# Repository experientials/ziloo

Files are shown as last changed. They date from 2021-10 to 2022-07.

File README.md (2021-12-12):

# Ziloo

Ziloo is an independent device that sees and senses the environment. It recognises objects and behavior based on what it has been taught. It outputs an event log describing what is perceived.
Ziloo can be placed on a shelf, wall or embedded. I will recognise things and people it has been trained to recognise. They have to appear in front within 20cm - 200cm. Ziloo is primarily used indoors and used at all times of the day.

It receives stereo video input over 2 x 2-lane MIPI CSI2. Additionally it receives sensor input over I2C
for distance, color, brightness. The sensor inputs are processed and disected to identify objects, people and
behaviour. Ziloo can connect over USB to make the output available.

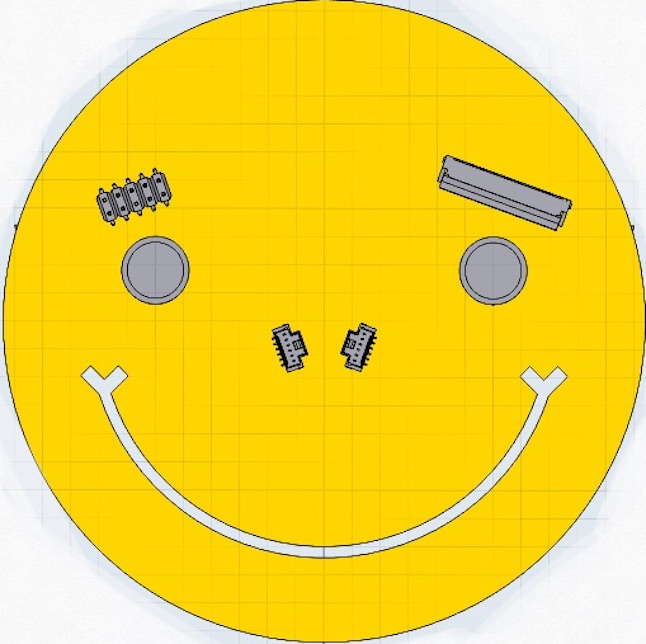
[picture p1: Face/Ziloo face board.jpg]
Ziloo face


Ziloo will be launched on Kickstarter in 2022.

TODO 3D Exploded assembly
https://www.fiverr.com/visual_pro022/3d-product-animation-3d-product-video-3d-animation-3d-product-animation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

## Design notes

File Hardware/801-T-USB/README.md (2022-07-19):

# 801 T-USB daughterboard Upwork task

The T-USB daughterboard has two functions
- Supply the system with power
- Support smart future waking/suspend logic
- Provide data signals in the system over two USB-C connectors

The T-USB board exposes two vertical USB-C sockets and connects to the carrier board through two 50 pin B2B connectors.
For future feature development the board also has two FPC breakout connectors.

In addition to this board a matching **testing/breakout board must be designed**.

We already have a development board designed so this tasks breaks out part of an existing design (909) on a dedicated baord (801 T-USB).

The provided documentation includes

- Detailed functionality, wiring, connections for T-USB board
- Detailed functionality, wiring, connections for TESTING board
- Functionality Testing cases
- Reference diagram for Compulab development board
- Reference diagram for 909 development board
- Component datasheets

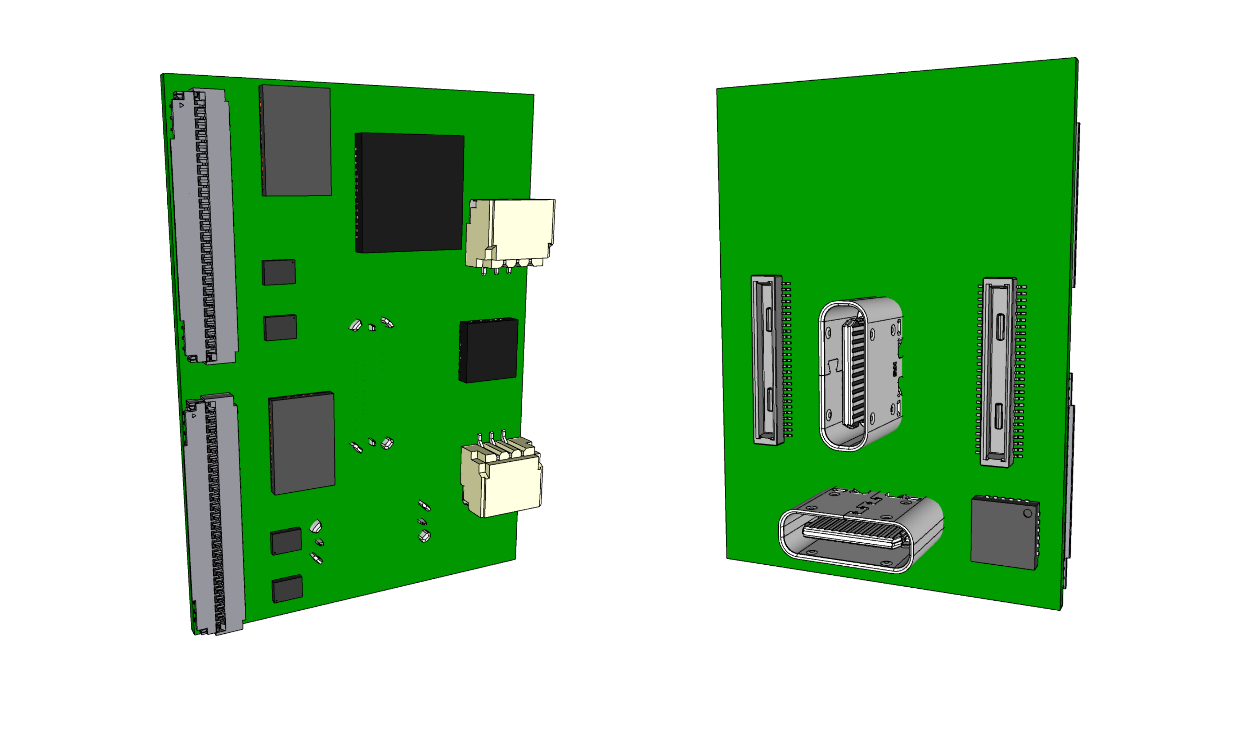
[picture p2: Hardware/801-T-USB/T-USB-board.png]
Ziloo 801 T-USB Board


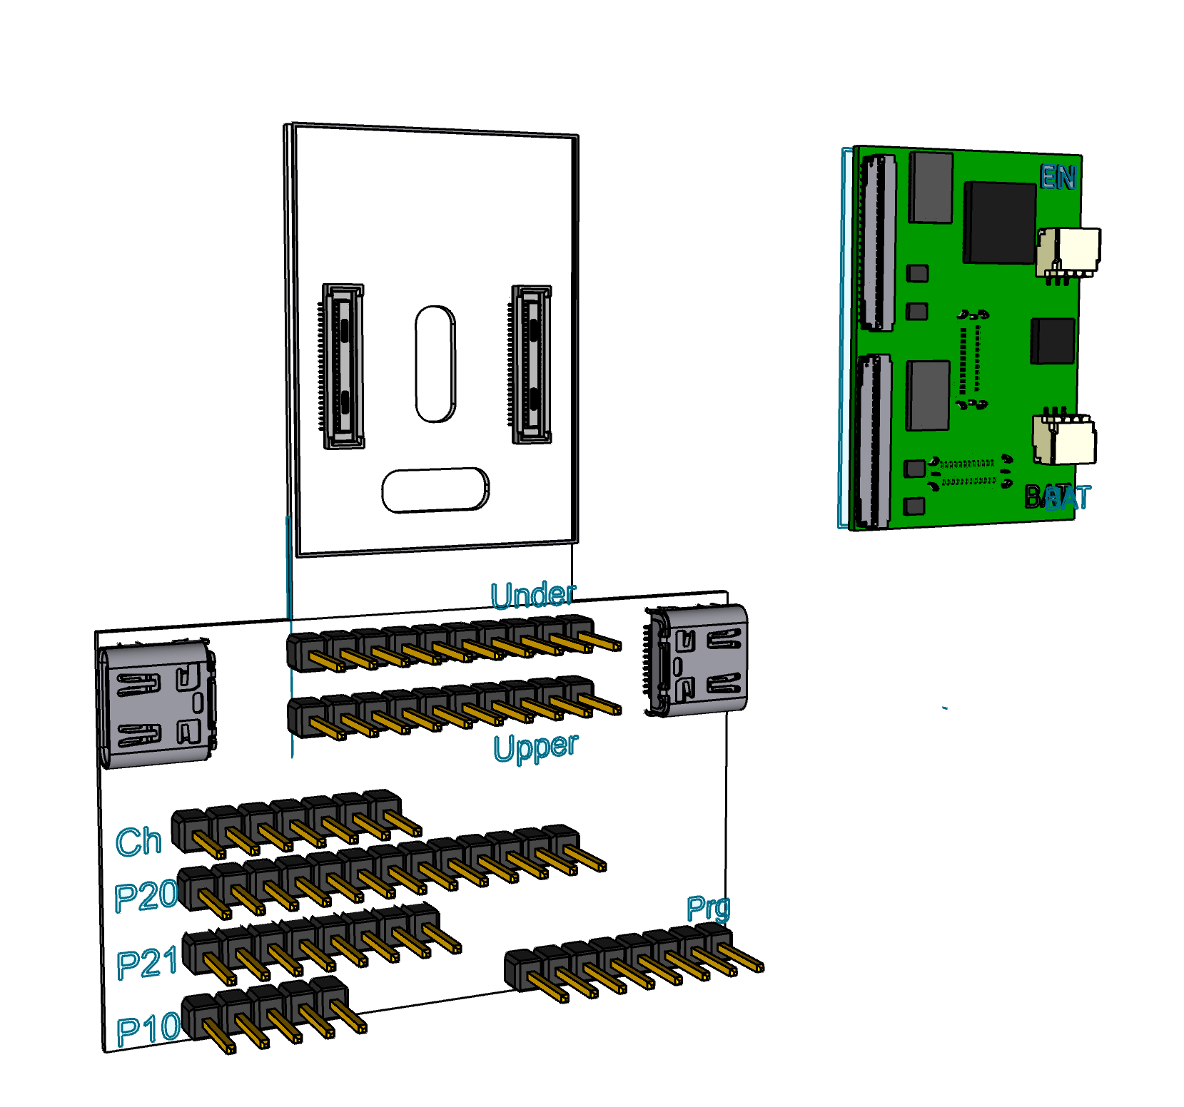
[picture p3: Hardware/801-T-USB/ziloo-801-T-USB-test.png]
Ziloo 801 T-USB Board


The board takes two USB-C connections with power and data.

- Supports 5V in and out
- USB 2.0/3.0 data support
- Rudimentary Alt. Mode support
- Trickle charging & Fast Charging
- With/Without Battery connected
- Steady power output regardless of charging
- Power output max. 4.5V 2.5A

The essential BOM of the 801 T-USB Bridge Board is,

- 2 * [Hirose DF40-50DP-0.4V](https://www.hirose.com/en/product/p/CL0684-4014-0-51)
- 2 * [Hirose USB-C CX80B1-24P](https://www.hirose.com/product/p/CL0480-0625-0-00)
- 1 * [TPS65988](https://www.ti.com/product/TPS65988?keyMatch=TPS65988&tisearch=search-everything&usecase=GPN) Dual Port USB Type-C® and USB PD Controller, Power Switch, and High-Speed Multiplexer. 
- 2 * [HD3SS460](https://www.ti.com/product/HD3SS460?keyMatch=HD3SS460&tisearch=search-everything&usecase=GPN) 4 x 6 Channels USB Type-C Alternate Mode MUX. Connected to T-USB Host. 
- 1 * PCA9555 I/O Expander
- 4 * [TS5USBC410 Dual 2:1 USB 2.0 Mux/DeMux Switch](../datasheets/USB/ts5usbc41.pdf). [Mouser](https://www.mouser.ch/ProductDetail/Texas-Instruments/TS5USBC410IYFFR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)
- 1 * [BQ24250RGER battery charger](https://www.ti.com/product/BQ24250)  
- 1 * [3 pin JST SH socket SM03B-SRSS-TB](https://www.jst-mfg.com/product/detail_e.php?series=231) 
- 2 * [TE Connectivity 45PIN 0.3MM 571-4-2328724-5 FPC 3-2328724-5](https://www.te.com/usa-en/product-4-2328724-5.html)

Test board components,

- 2 * [Hirose DF40-50DS-0.4V](https://www.hirose.com/en/product/p/CL0684-4009-0-51) mated height 1.5mm
- 2 * [HD3SS3220  10-Gbps USB 3.1 Type-C 2:1 mux with DRP Controller](https://www.ti.com/product/HD3SS3220)
- 2 * USB-C connectors [DX07S024JA1R1300](https://www.jae.com/en/connectors/series/detail/product/id=66508) or [DX07S024JJ2R1300](https://www.mouser.ch/ProductDetail/JAE-Electronics/DX07S024JJ2R1300?qs=odmYgEirbwyfyaz1Tta0cQ%3D%3D)
- 3 * [Samtec TSW-116-14-T-S Header 16 pin](https://www.samtec.com/products/tsw-116-14-t-s)

## Milestones:

The project is broken down in milestones to ensure a correct design.

### Testing board design $300

Do a design for the testing board and layout with Eagle or Altium

- Precise placement of USB-C socket holes
- Preciese placement of upper and under 50 pin connectors
- Breakout connectors can be arranged differently
- USB breakout connectors should be as suggested
- The breakout part of the board can be enlarged if needed

Once the design is done we will order a few boards for me and yourself for testing.

### Initial board designs  $800

Do an initial T-USB board diagram and layout with Eagle or Altium.

- Confirmation of BoM
- PD Controller working as a power sink(not source)
- Power Regulators
- Power LED, Power and Reset buttons
- 45 pin breakout connectors
- USB-C sockets
- Battery charger
- Design both boards

Deliverables:

- Diagrams(.sch) + Board layout design files
- Gerber files
- Review the choice of component and suggest alternative if needed.
- Confirmation of BoM
- Get production quotes with JLCPCB, PCBWAY etc. for 10pc, 100pcs, 1000pcs (assembled and basic)

### Ordering test batch of boards $0

We then do a test batch of 801 T-USB boards

### Verification of design and fixes - $400

Receive the test boards and test the acceptance tests. Make sure all tests pass.
Correct any issues after reviewing with me.

Deliverables:

- Diagrams(.sch) + Board layout design files
- Gerber files
- Testing report with measurements

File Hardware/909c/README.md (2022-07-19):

# Upwork task

The 909c has several different systems coming together. 
It receives power and data over USB from the T-USB power/data module. 
It receives sensor inputs over camera module connectors.
The camera modules are custom multi-sensor modules based on OV2735.
It connects to a powerful [i.MX 8 SoM](https://www.compulab.com/products/computer-on-modules/ucm-imx8m-plus-nxp-i-mx-8m-plus-som-system-on-module-computer/) and it allows extension using an m.2 modules.

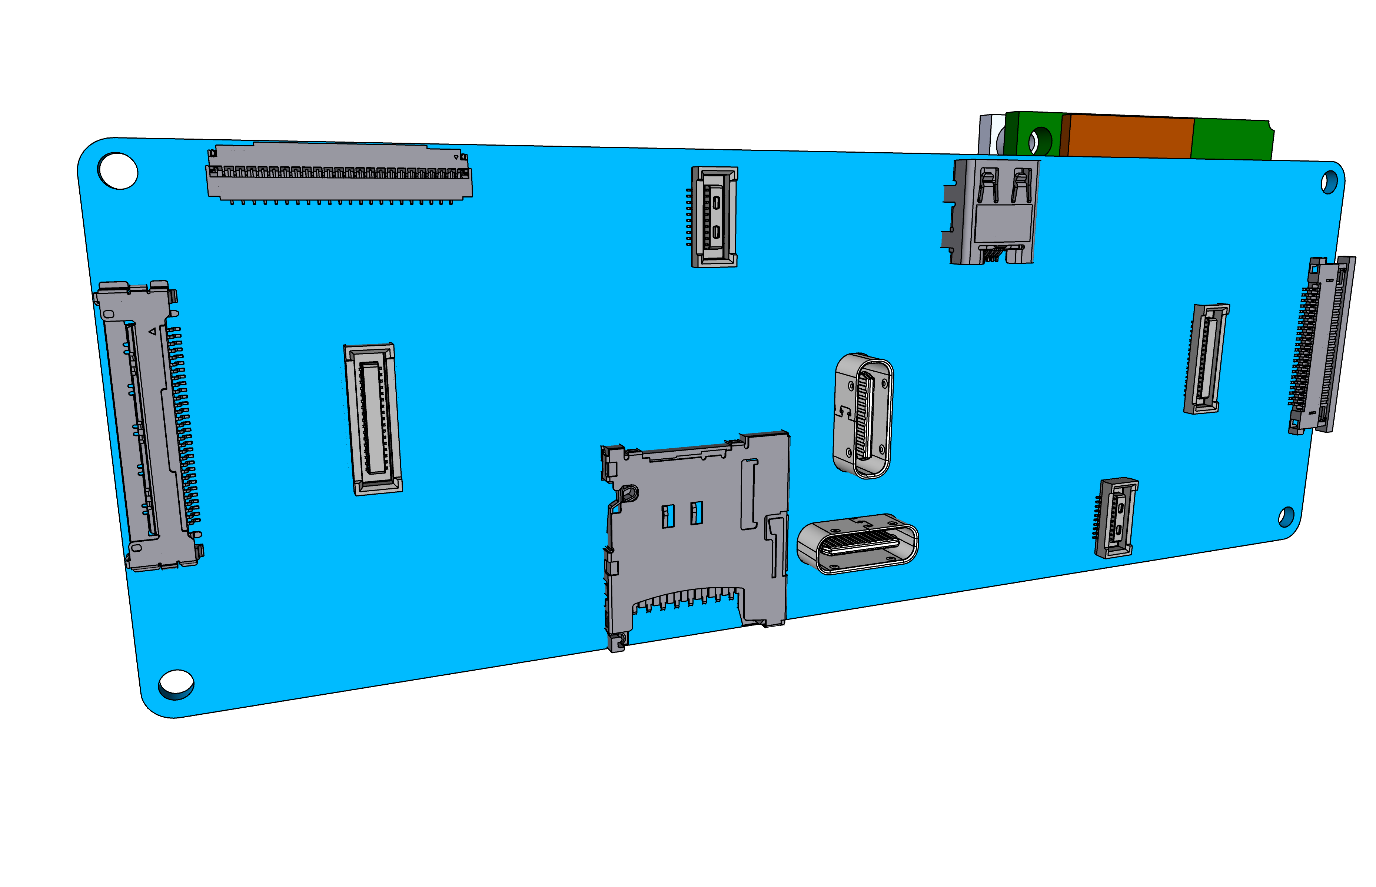
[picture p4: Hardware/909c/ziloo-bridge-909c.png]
Ziloo Bridge Board 909c


The 909c is made for experimentation. It will be used to,

- Connecting dual 201 Camera Modules to the Bridge Board
- Connecting a Raspberry Pi 15/22 pin Camera module to the Bridge Board
- Accessing the 201 Camera Modules from a i.MX8 Plus development boards like [Compulab](https://www.compulab.com/products/carrier-boards/sb-ucmimx8plus-carrier-board/), [I-Pi](https://www.ipi.wiki/products/i-pi-smarcplus-imx8mp) or [Varscite](https://www.variscite.com/product/system-on-module-som/cortex-a53-krait/dart-mx8m-plus-nxp-i-mx-8m-plus/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).
- Booting [i.MX8 Plus SoM]() with Linux Application for Machine Vision via Flash, USB, SSD
- Testing m.2 SSD boards

The 909c essentially joins connected modules,

1) 4 camera connectors for stereo cameras
2) Dual USB-C submodule that provides power and data connectivity.
3) Connectors for i.MX8 SoM
4) Connector for m.2 Key B (no screw)
5) SD Card, Board-To-Board sound bus connectors, HDMI, Debug Connector and debug/testing pads

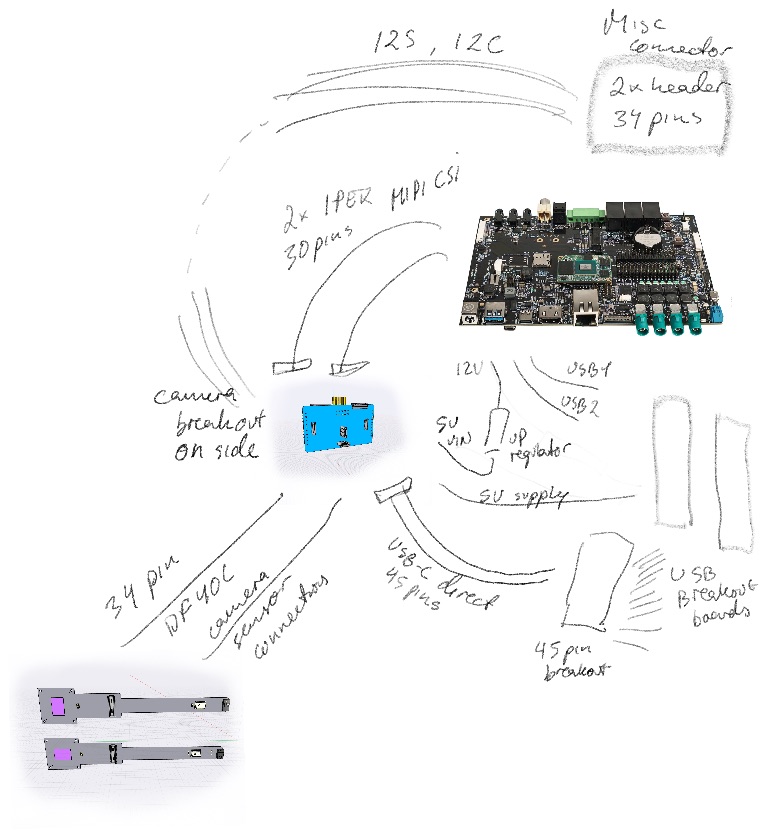
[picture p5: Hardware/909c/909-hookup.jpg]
Slightly outdated 909b Bridge Board hookup


The essential BOM of the 909c Bridge Board is,

- 1 * Compulab SB-UCM-iMX8PLUS SoM
- 1 * T-USB Module
- 1 * [CBTL04083 Multiplexer Switch ICs 3.3V CH 2:1](https://www.nxp.com/part/CBTL04083ABS#/) - [Mouser](https://www.mouser.ch/ProductDetail/NXP-Semiconductors/CBTL04083ABS518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)
- 1 * [Molex 22PIN 0.5mm pitch 54548-2271](https://www.molex.com/molex/products/part-detail/ffc_fpc_connectors/0545482271)
- 1 * [I-PEX 30PIN 0.4mm pitch 20525-030E-02](https://www.i-pex.com/product/cabline-ca)
- 1 * [TE Connectivity 45PIN 0.3MM 571-4-2328724-5 FPC 3-2328724-5](https://www.te.com/usa-en/product-4-2328724-5.html) $0.41
- 2 * [Hirose DF40C-34DS-0.4V](https://www.hirose.com/en/product/p/CL0684-4023-0-51) ([Mouser](https://www.mouser.ch/ProductDetail/Hirose-Connector/DF40C-34DS-04V51?qs=vcbW%252B4%252BSTIpg26DsEbj1iQ%3D%3D))
- 2 * [Hirose DF40HC(3.0)-100DS-0.4V](https://www.hirose.com/en/product/p/CL0684-4151-0-51) mated height 3.0mm
- 1 * m.2 connector

## Milestones:

The project is broken down in milestones to ensure a correct design.

### Overall system diagram and component layout

Do an initial board diagram and layout and order the Development board from compulab.com
 with Eagle or Altium.

- Confirmation of BoM
- T-USB module connection
- Coonection of [i.MX 8 SoM](https://www.compulab.com/products/computer-on-modules/ucm-imx8m-plus-nxp-i-mx-8m-plus-som-system-on-module-computer/)
- Soldering Pads
- 30 pin CSI connector
- 34 pin CSI connectors
- 22 pin CSI connector
- CSI to SoM lanes
- Debug breakout connector
- Sound connection (20 pins)
- Multi-directional power between CSI connectors
- m.2 module connector
- Level shifters

Deliverables:

- Diagrams(.sch) + Board layout design files
- Confirmation of BoM
- Collect PCB price estimates from 
- Get production quotes with JLCPCB etc. for 10pc, 100pcs, 1000pcs (assembled and basic)

### Diagram and Draft Board Layout - $250

Do a board diagram and layout of components with Eagle or Altium.

- A full set of diagrams for the board
- Placement of main components on the board
- Draft layout of important components
- Adherance to the design layouts I provide
- Plan signal levels for connectors

Deliverables:

- Diagrams + Board layout design files
- Confirmation of BoM

### Design and Produce - $1000

Design the board and produce a test batch

- Lay out the board
- Produce a batch of populated boards with PCBWay or JLCPCB
- Send me a populated board from the batch

Deliverables:

- Diagrams + Board layout design files
- Send me a populated board from the batch

### Test initial Batch $750

Once the initial batch of PCBs have been produced do some basic tests.
You should have the development board and 201 camera modules
You will have to power the board with a bench power supply directly for VSOM,
as I cannot provide you with a T-USB module.

- Test CSI connectors route signals and power
- Test USB connectors can power the board
- Test SoM can boot with HDMI, Mouse and Keyboard
- Test that the development board can be connected via 30 pin CSI connectors
- Test dual Rpi 22 pins camera connections -> 909b -> development board 
- Verify boot to USB/SD/eMMC
- Verify that small m.2 modules can be fitted
- Verify power delivery from USB chargers with the listed levels
- Document test process and findings
- Revise designs as needed

Deliverables:

- Report results and send the hardware(incl. Compulab dev board) back to me.
- All design files & send the hardware including test setup
- Revised design files
- Alternate component BoM

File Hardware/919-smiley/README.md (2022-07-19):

# Upwork task

The 919 is a board facing the user holding daughter boards on the back side.
It contains a MEMSIC mCube MC6470 3D movement sensor with a gyroscope and accelerometer, which is managed by the Stem MCU on the T-USB board.
It communicates with the Stem MCU via the Stem I2C bus, and the SoM i.MX 8 via the SYS I2C. 
It exposes system control signals via the SYS I2C GPIO Expander 0.

It has sockets and holes for two camera modules that are also routed to the SoM main board.

The 919 is made for experimentation. It will be used to join connected modules,

1) 4 camera connectors for stereo cameras
2) Dual USB-C submodule that provides autonomy, power and data connectivity.
3) Connectors for i.MX8 SoM
4) Sound modules

Slightly outdated 909b Bridge Board hookup

## Milestones:

The project is broken down in milestones to ensure a correct design.

### Board diagram and component placement $400

Prove the design by creating a schema, component placement and simple routing with Eagle or Altium.

- Connectors for Cameras, Sound extensions, Power Module, GPIO headers, RTC batt.
- LEDs + Controller
- IMU

Deliverables:

- Diagrams(.sch) + Board layout design files
- Confirmation of BoM
- Collect PCB price estimates from 
- Get production quotes with JLCPCB etc. for 10pc, 100pcs, 1000pcs (assembled and basic)

### Work out embedding of LEDs $300

The LEDs must be recessed in the PCB. Should this be part of the board design for production,
or is it a postprocessing step to CNC the holes?

### Design and Produce - $800

Design the board and produce a test batch based on the specs. Further refinement expected after initial batch.

- Lay out the board
- Ensure the LEDs are recessed
- Produce a batch of populated boards with PCBWay or JLCPCB
- Send me a populated board from the batch
- Do initial testing to find issues

Deliverables:

- Diagrams + Board layout design files
- Send me a populated board from the batch

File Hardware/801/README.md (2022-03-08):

Features

- Boot mode switches (eMMC / SD / Recovery / SPI)

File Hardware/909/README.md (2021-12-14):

# Upwork task

The 909 has several different systems coming together. It receives power and data over USB. It receives sensor inputs over camera module connectors.
The camera modules are custom multi-sensor modules based on OV2735.
It connects to a powerful i.MX 8 MCU module and it allows extension using an m.2 module.

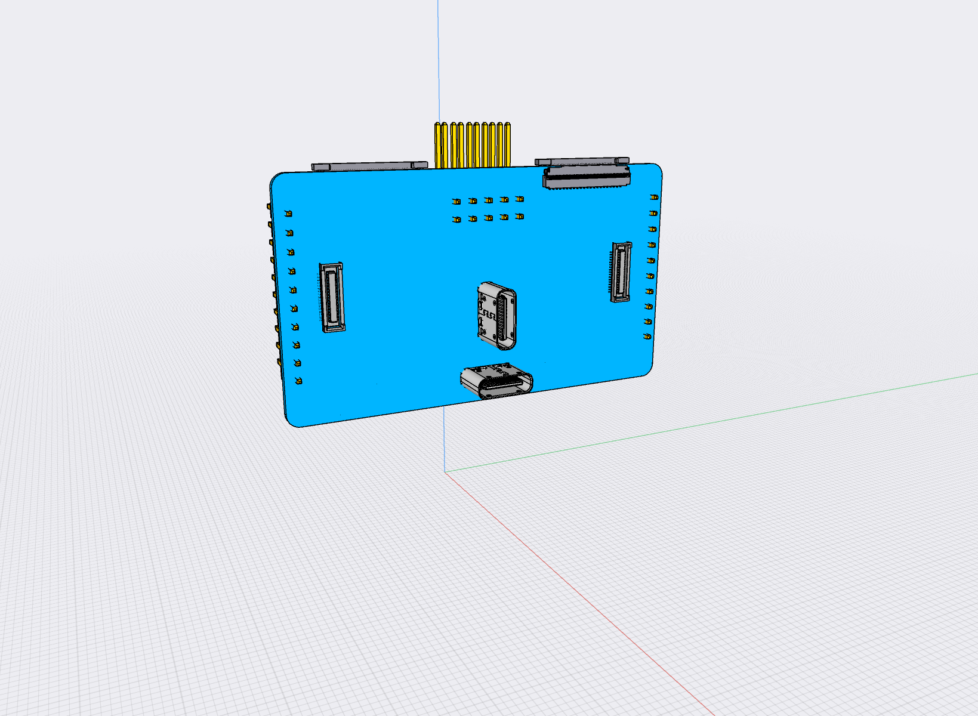
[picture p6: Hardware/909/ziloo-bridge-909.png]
Ziloo Bridge Board 909


The 909 is made for experimentation. It will be used to,

- Connecting 201 Camera Modules to the Carrier Board
- Connecting Raspberry Pi 15/22 pin modules to the Carrier Board
- Accessing the 201 Camera Modules from a Raspberry Pi
- Testing USB-C data transmission over Host & OTG connectors
- Testing charging via USB-C power cables from various sources (Dedicated Power, Mixed and Old chargers)
- Testing HDMI alternate mode over USB-C Host connector

The 909 essentially provides two parts,

1) Input connectors for 2 cameras linked to output connectors connected to the i.MX 8 development board.
   The cameras are powered by the development board connections.
2) 2 USB-C connectors are managed by a USB PD Controller circuit and breaks out relevant power & data pins.
   These pins are then mapped to 2 USB ports on the i.MX 8 development board.

909 Bridge Board hookup

The essential BOM of the 909 Bridge Board is,

- Texas Instruments TPS65988
- 2 * [Molex 22PIN 0.5mm pitch 54548-2271](https://www.molex.com/molex/products/part-detail/ffc_fpc_connectors/0545482271)
- 2 * [I-PEX 30PIN 0.4mm pitch 20525-030E-02](https://www.i-pex.com/product/cabline-ca)
- 2 * [Hirose USB-C CX80B1-24P](https://www.hirose.com/product/p/CL0480-0625-0-00)
- 1 * [TE Connectivity 45PIN 0.3MM 571-4-2328724-5 FPC 3-2328724-5](https://www.te.com/usa-en/product-4-2328724-5.html) $0.41
- 2 * [Hirose DF40C-34DS-0.4V](https://www.hirose.com/en/product/p/CL0684-4023-0-51) ([Mouser](https://www.mouser.ch/ProductDetail/Hirose-Connector/DF40C-34DS-04V51?qs=vcbW%252B4%252BSTIpg26DsEbj1iQ%3D%3D))

## Your task

1) Given a detailed spec; Identify if there are further open questions about the design of given the goals.
2) Make a diagram
3) Design board layout
4) Receive test batch of boards + Camera Module samples
5) Verify power delivery from chargers with the listed levels
6) Test that Camera module CSI connectivity over 30 pin connectors

USB Power levels to test

- Dedicated Charger 5V, 500mA
- Apple Dedicated Charger 5V, 1A BC1.2
- Power & Data CDP 5V, 1A
- Power & Data CDP 5V, 3A
- Power & Data CDP 9V, 1A
- Power & Data CDP 15V, 1A

## Milestones:

1) Make a diagram, draft layout and BOM for the board. $500                       
2) Acquire the Compulab development board yourself & I send you two camera modules. 
     You adjust the Yocto setup to include support for OV2735. $700
3) Finish the board design for test batch production. $300
4) With the modules received, and the produced tetch batch you test to which extent the setup captures camera input.
   You combine breakout boards to connect Bridge and Compulab boards.
   Test basic connectivity to I2C sensores and Microphone on the camera modules.
   Test supplying USB power supply levels and current.
   Report results and send the hardware(incl. Compulab dev board) back to me. $500

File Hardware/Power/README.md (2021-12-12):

## Power Module

The power module is a battery pack that is made to stand on top of a charging stand.

The board has USB connections for surface connection. A USB-C connector is a development time alternative.

- [Upwork job](./Upwork.md)
- [Type of Battery](./BATTERY.md)
- [Bottom Board](./BOTTOM_BOARD.md)
- [Sibling Board](./SIBLING_BOARD.md)
- [Slide-in Board](./SLIDE-IN_BOARD.md)
- [Connectors](./CONNECTORS.md)

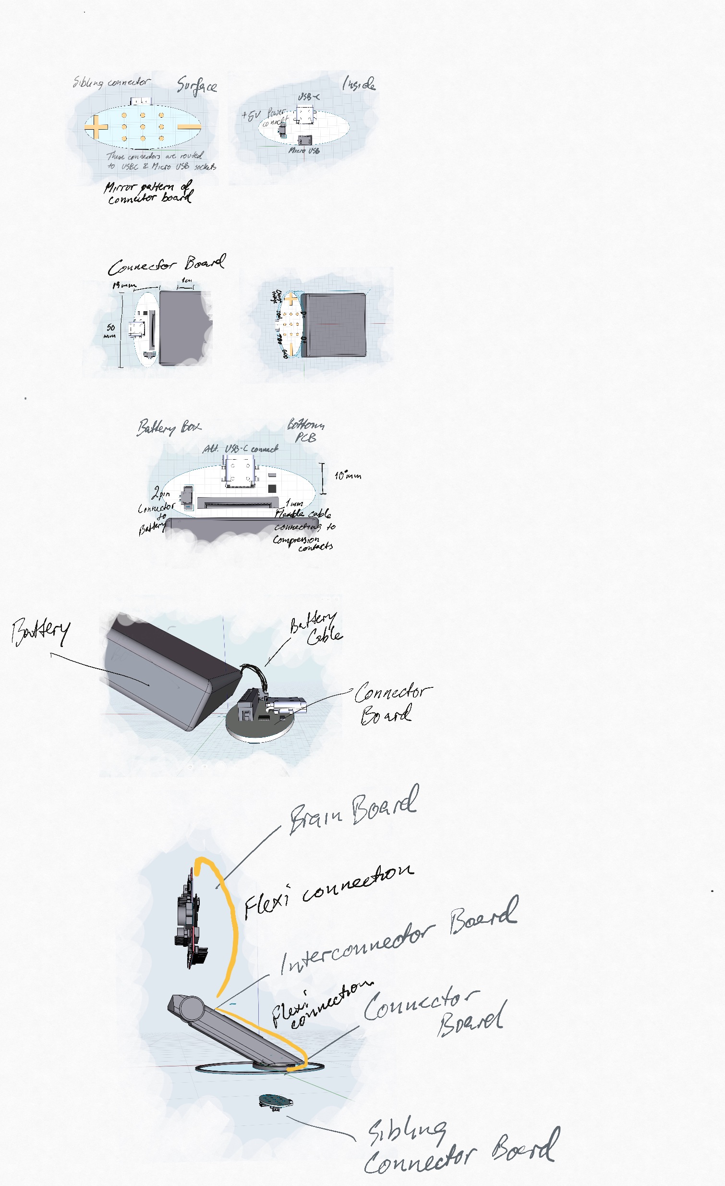
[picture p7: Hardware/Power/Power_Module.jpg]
Power Module


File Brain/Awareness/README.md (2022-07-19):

# Autonomous Awareness

The Autonomous Awareness is distributed across systems some in the Occi some in the Stem.
The canonical implementation uses RP2040 to communicate and monitor sensors.

Occi Subcognition runs on the System Module by occasionally waking up to check the
camera sensors against the previous state.

Stem Awareness is an Autonomous system that runs at all time by reacting to
sensor changes when they happen.

- T-USB Stem MCU
- RT MCU on SoM
- MCU on m.2
- Bluetooth enabled nRF MCU

:[Inter MCU](../../Hardware/standards/INTER_MCU_BUS.md)

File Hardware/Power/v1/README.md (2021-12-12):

We have an issue with the manufacturing price.
Right now I have quotations from a couple of companies and the price is approximate 800$ - 1100$ it is a cost for the PCB and assembly. We will have 10 PCB boards with 3 assembled.

I am wondering if this is the price that is normal for you?

I was trying to make it cheaper, but the package that has MAX77860 doesn't allow me to do this. Design requires "via in pad" and "blind via" which increases the price significantly.

I need your opinion to decide what to do next, trying to lower costs of the PCB(but I can't predict how much time it make take) or order it and test?

I thinking one time more and realize that switching to another chip will only cause the losing more time and money so I think we need to order. Because money and time which we save on manufacturing we will spend on developing.

Yes I will send 2 PCB to you, one I will left for me if we will need to figure out any issue, after you check it and they will work proper I may send it also to you but later.

For this moment I did the aditional wires and fixture for testing the PCB works, you may see them on the photo. I will sent 1 set to you, but for the first testing of the PCB you will need to buy 2 things:
1. MAX77860EVKIT https://eu.mouser.com/ProductDetail/Maxim-Integrated/MAX77860EVKIT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 - this one you need to have access to the MAX77860 registers for configuration it.
2. Battery with 3 wires - i can't send you the battery, the post companny doeasn't allow me to do this. You may buy it here: I will prepare wires to connect it. https://www.ebay.com/itm/184854611075?hash=item2b0a318483:g:NuoAAOSw2QxcmEug - you may buy anywhere, but then please share link with me I will prepare wires for easily connect the battery.

For this moment, charger work and USB2.0, I need to check the USB3.0 and the max load current capabilities.

I will add the manufacturing cost(804$) offline in the Upwork.

Alex Sarnok:

Hello Henrik,
I found out that link in amazon has wrong information about battery's connector.
That is SH connector, not PH connector.
Here is link and datasheet for this connector(https://www.jst.com/products/crimp-style-connectors-wire-to-board-type/sh-connector/)
But, I recommend you to use connector, that I sent you and solder it with battery.

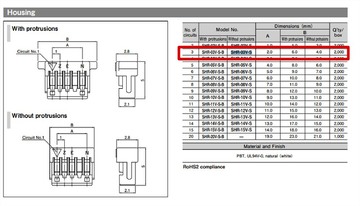
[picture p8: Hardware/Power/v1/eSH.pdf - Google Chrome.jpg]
eSH connector


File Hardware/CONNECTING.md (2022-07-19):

# Connecting to iPad or PC

You can connect to Ziloo by plugging into the OTG part of T-USB

The OTG connector is the horizontal bar of the T.
Using OTG mode the connector can be used as a USB device.
The USB OTG connector allows you to use Ziloo as a traditional WebCam using a PC/Mac or Mobile Phone.

When connected the computer may power and/or charge Ziloo. If Ziloo has sufficient power it will wake up.

When awake multiple features will be active

- Ziloo will provide a stereo WebCam UVC stream.
- Ziloo will connect via CDC Ethernet to gain internet access. It will use this to update subscribed streams and firmware.
- UARTS 1 to 4 for debugging over CDC Virtual COM ports
- MSC access to SOM flash

When resting as well as awake the Ziloo stem provides basic features over USB 2.0

- I2C sensor access compatible with https://github.com/harbaum/I2C-Tiny-USB#i2c-tiny-usb
- command console interface via CDC Virtual COM port
- console output via CDC Virtual COM port
- MSC to upload python script runs

## console output

The console output will show output from both SoM cores and the RP applications. It will use ANSI to syntax highlight and show status/progress information. The status is encoded in the log and can be decoded by the Ziloo apps console view.

## command console

The command port connection provides a bidirectional structured command interface following a simple command-response sequence with async/out of order support. The command interface can be viewed and manipulated via the Ziloo App command view or VS Code plugin.

## UART ports

Ziloo will provide virtual ports named UARTx that connect to the SoM. If the SoM suspends the port remains open but unresponsive. The change will be logged in the console.

## I2C direct sensor

Sensors can be directly probed and tested from remote apps using drivers compatible with
[I2C tiny USB](https://github.com/harbaum/I2C-Tiny-USB#i2c-tiny-usb). This feature will not be available initially as it will need to be secured well. 
The same functionality could be provided via command port.

## Recovery features

If the RP fails to boot from the flash it enters recovery. Alternatively press the recovery button to enter.

Start with your Pico unplugged from USB. Hold down the BOOTSEL button, and while continuing to hold it (don’t let go!), plug the Pico into USB. Continue to hold the BOOTSEL button until the RPI-RP2 drive appears!

When in recovery mode an MSC disk is provided over USB 2.0 for updating the firmware.

- Replacing RP firmware
- Adding to system stream
- Adding to other streams
- Manipulate streams

Hard reset 

When the i.MX SoM is in recovery mode `mfgtool` can be used to directly upgrade the firmware(in eMMC).

## Connection modes

You can connect USB cables to Ziloo in different ways depending on your needs. Normally you would connect your Computer or iPad to the OTG socket(the horizontal bar of the T) and devices such as a Display, keyboard or mouse to Host(the vertical bar of the T). It you plug **Ziloo** into **The Stand**
it will use the Plural mode where additional connections are available.

T-USB OTG 2.0 data,
- off (Autonomous MCU USB talks to Occi MCU USB1)
- Autonomous MCU USB (A and B)
- Occi MCU USB1 (only B)
- Plural; OTG-A connects Autonomous MCU USB, OTG-B connects Extra OTG USB

T-USB Host 2.0 data,
- off
- Autonomous MCU USB
- Occi MCU USB2 (only B)
- Plural; Host-A connects Autonomous MCU USB, Host-B connects Extra Host USB

T-USB OTG 3.0 data,
- off
- Occi MCU USB1
- Ox- / Ox+

T-USB Host 3.0 data,
- off
- Occi MCU USB2
- Hx- / Hx+

Host
- Plugging in a USB stick to update Ziloo

OTG
- MSC uploading firmware

## Future Connectivity Options

tcp/ip
bluetooth comms

### BLE Protocol Design Strategy

[Bluetooth Low Energy Serial: A Valid Design Strategy?](https://punchthrough.com/serial-over-ble/)

* Start with a Serial over BLE strategy and extract functionality as needed.
* Any value that will need to be accessed quickly by the central should have a readable characteristic that the peripheral always keeps up to date.
* Bulk background transfers, such as logs or firmware updates, should have their own characteristics, so they don’t clog up communication related to the user experience.
* Status information that changes quickly should be grouped so that the information can be considered a snapshot of a single point in time. This is extremely useful when working with systems where data from multiple kinds of sensors is needed to describe the device’s status.
* Information that is not of use to the current client should be transferred through a different characteristic or should have the ability for the client to turn the information on or off based on its interests. This way, the client can control what information it receives.
* Information that can be of value to other systems should be exposed through standard Bluetooth Profiles. (Information such as battery level, temperature, etc.).

### Command Line Sample Code

* [Command Line Interface library](https://infocenter.nordicsemi.com/topic/com.nordic.infocenter.sdk5.v15.2.0/lib_cli.html)

* [Command Line Interface (CLI) Example](https://infocenter.nordicsemi.com/topic/com.nordic.infocenter.sdk5.v15.2.0/cli_example.html)

https://infocenter.nordicsemi.com/index.jsp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

### USB Mass Storage and Sound Streaming

* [usb-cdc-acm](https://github.com/NordicPlayground/node-usb-cdc-acm)
* [USB CDC ACM Example](https://infocenter.nordicsemi.com/topic/com.nordic.infocenter.sdk5.v15.2.0/usbd_cdc_acm_example.html)

### WebUSB

[WebUSB ChromeStatus](https://www.chromestatus.com/feature/5651917954875392)

[Web IDL](https://heycam.github.io/webidl/#idl-octet)

### Sample code

* [UART Example](https://infocenter.nordicsemi.com/index.jsp?topic=%2Fcom.nordic.infocenter.sdk5.v15.0.0%2Fuart_example.html)
* [Experimental: BLE Interactive Command Line Interface Example](https://infocenter.nordicsemi.com/topic/com.nordic.infocenter.sdk5.v15.0.0/ble_sdk_app_interactive.html)
* [Programming SoftDevices](https://infocenter.nordicsemi.com/index.jsp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)
* [ble_nus_init_t Struct Reference](https://infocenter.nordicsemi.com/index.jsp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)

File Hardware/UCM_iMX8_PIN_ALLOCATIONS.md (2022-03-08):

# UCM iMX8M Pin Allocations

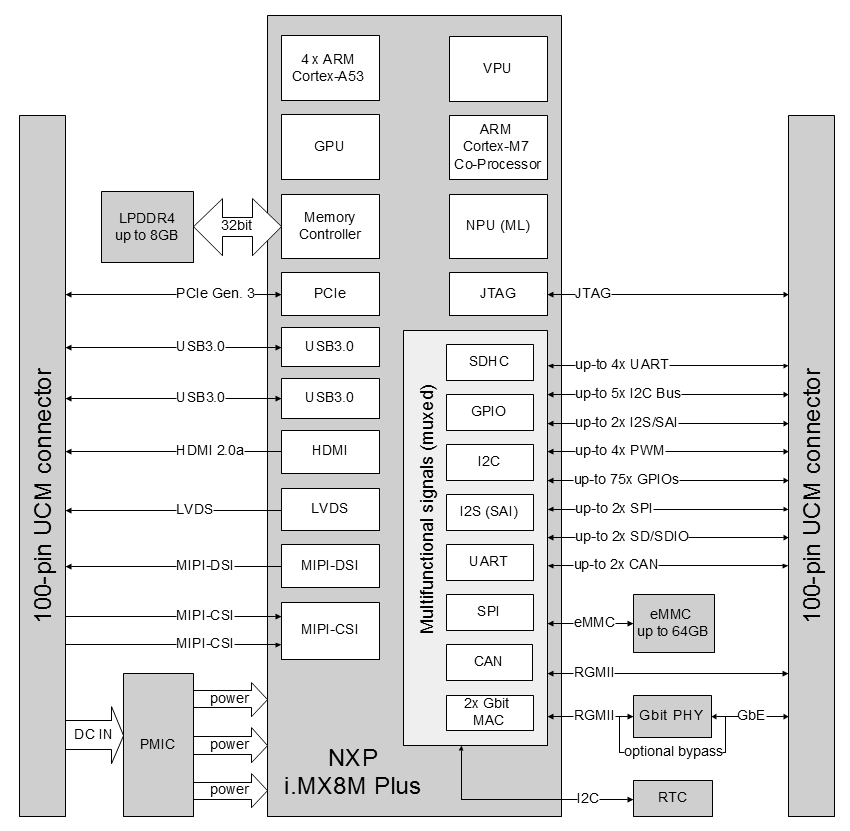
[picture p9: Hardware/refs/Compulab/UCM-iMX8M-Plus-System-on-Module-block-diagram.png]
UCM iMX8M SoM block diagram


The model of SoM used isn't the E version. This means that the ethernet port only support 100Mbit.

The Misc connectors are used to route additional busses to the bridge board.
To enable this FLEXCAN and ENET1 are re-mapped to other ports. LVDS isn't used, but only I2C3 can be mapped.

The mapping is also captured in [Hookups](./datasheets/i.MX8/ucm-imx8plus_p1_p2_hookups.pdf)

### P1 function allocation

| Misc | PX pin  | Pad connected | Functionality |
|---|---|---|---|
| P20.11 | P1.19 | UART1_RXD | |
| P20.4  | P1.21 | UART3_RXD | |
| P21.11 | P1.26 |  SAI3_TXD |  SAI5_RX_DATA3 | 
| P21.17 | P1.28 |  SAI3_RXD |  SAI5_RX_DATA0 | 
| P21.15 | P1.30 |  SAI3_MCLK |  SAI5_MCLK | 
| P21.19 | P1.32 |  SAI3_RXC |  SAI5_RXC | 
| P21.8  | P1.33 |  CAN2_TX | | 
| P21.23 | P1.34 |  SAI3_RXFS |  SAI5_RX_SYNC | 
| P21.13 | P1.36 |  SAI3_TXC |  SAI5_RX_DATA2 | 
| P21.21 | P1.38 |  SAI3_TXFS |  SAI5_RX_DATA1 | 
| P21.10 | P1.49 |  CAN2_RX | | 
| P21.12 | P1.51 |  CAN1_RX | | 
| P21.14 | P1.53 |  CAN1_TX | | 
| P20.12 | P1.59 | GPIO1_IO00 | EX_OH_nINT |
| | P1.60 | GPIO4_IO19 | EX0_nINT |
| P20.2  | P1.61 | UART3_TXD | |
| P21.31 | P1.63 |  HDMI_DDC_SDA | | 
| P21.29 | P1.70 |  HDMI_DDC_SCL | | 
| P20.9  | P1.72 | UART1_TXD | |
| P20.1  | P1.74 | UART2_TXD | |
| P20.3  | P1.76 | UART2_RXD | |
| P20.5  | P1.77 | PWM1_OUT | |
| | P1.79 | PWM2_OUT | |
| | P1.81 | PWM3_OUT | |
| P20.10 | P1.84 | UART4_RXD | |
| | P1.85 | HDMI_CEC | |
| P20.8  | P1.86 | UART4_TXD | |
| P21.2  | P1.87 | I2C6_SCL | | 
| P21.4  | P1.89 | I2C6_SDA | | 
| | P1.91 | I2C3_SDA | |
| | P1.85 | HDMI_HPD | |
| P20.33 | P1.94 | I2C3_SCL | |
| P21.1  | P1.96 | I2C5_SDA | | 
| P20.14 | P1.98 | GPIO1_01 | EX_T_nINT |
| P21.3  | P1.100  |  I2C5_SCL | | 

### P2 function allocation

| Misc | PX pin  | Pad connected | Functionality | 
|---|---|---|---|
| P20.21 | P2.41 | ~~ENET1_RD0~~ | SD1_DATA2 |
| P20.23 | P2.43 | ~~ENET1_RD1~~ | SD1_DATA3 |
| P20.25 | P2.45 | ~~ENET1_RD2~~ | GPIO2_IO8 |
| P20.27 | P2.47 | ~~ENET1_RD3~~ | GPIO2_IO9 |
| | P2.49 |  GPIO2_IO20 | | 
| P21.16 | P2.51 | GPIO2_IO19 | | 
| P21.32 | P2.52 | GPIO4_IO20 | PCIE_WAKE_B | 
| P20.19 | P2.53 | ~~ENET1_RX_CTL~~ | SAI5_TXFS |
| P20.29 | P2.55 | ~~ENET1_RXC~~ | SAI5_TXC |
| P20.22 | P2.59 | ~~ENET1_TD0~~ | SD1_DATA1 |
| P21.34 | P2.60 | GPIO4_12 | SAI5_TXD0 | 
| P20.24 | P2.61 | ~~ENET1_TD1~~ | SD1_DATA0 |
| P20.13 | P2.62 | GPIO2_IO10 | |
| P20.26 | P2.63 | ~~ENET1_TD2~~ | SAI5_TXD2 |
| P20.28 | P2.65 | ~~ENET1_TD3~~ | SAI5_TXD3 |
| P20.20 | P2.67 | ~~ENET1_TX_CTL~~ | GPIO4_16 |
| P20.15 | P2.68 | ~~ENET1_MDC~~ | SD1_CLK |
| P20.30 | P2.69 | ~~ENET1_TXC~~ | GPIO4_17 |
| P20.17 | P2.70 | ~~ENET1_MDIO~~ | SD1_CMD |
| P20.16 | P2.76 | ~~ENET1_nRST~~ | SAI5_TXD1 |
| P21.27 | P2.77 |  ENET TD2_BYPASS | | 
| P20.18 | P2.88 | ~~ENET1_INT~~ | GPIO4_IO21 |
| P21.22 | P2.89 |  ECSPI2_MISO | | 
| P21.20 | P2.90 |  PCIE_CLKREQ_B | | 
| P21.24 | P2.91 |  ECSPI2_SS0 | | 
| | P2.92 | SD2_nCD | | 
| P21.26 | P2.93 |  ECSPI2_SCLK | | 
| | P2.94 | SD2_DATA2 | |
| P21.28 | P2.95 |  ECSPI2_MOSI | | 
| | P2.96 | SD2_CLK | |
| | P2.97 | SD2_DATA0 | |
| | P2.98 | SD2_DATA3 | |
| | P2.99 | SD2_DATA1 | |
| | P2.100  | SD2_CMD | |

## I2C

- SYS I2C (aka I2C2) for RTC and EEPROM
- CSI1 I2C5
- CSI2 I2C6
- I2C3 free (Default used by LVDS), but also for M.2 connector.

## UART

- UART1 can be used for GPIO, but left at default UART mapping.
- UART2 is reserved for A53 core debug
- UART3 can be used for GPIO, but left at default UART mapping.
- UART4 is reserved for M7 core debug

## PWM

- PWM2 can be routed to SPDIF_RX (ALT1)
- PWM3 can be routed to SPDIF_TX (ALT1)

## Serial Audio Interface 5 / I2S

SAI 5 is used for microphone inputs. Up to 8 microphones can be connected
as 4 lane stereo. DATA0 is connected to microphones in camera modules
via the SAI3_RXD pad on Misc connector.

SAI 5 outputs are also reserved taking up ENET1 pads. This give 4 lane stereo out.

Remapping SAI5 to Misc. connector  pin pads

- TXC, TXFS,
- TX0..3
- RXC, RXFS, MCLK
- RXD0..3

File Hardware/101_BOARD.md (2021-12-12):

HLE-117-02-G-DV-BE-A 
2 * 34 pin header connected to carrier board

101 board breaks up 45 pins to be bridged to Misc connector
and USB-C connectors

In revision B the Host connector is alternately used to carry HDMI instead of connecting to 
Bluetooth/Wifi connectivity.

(801 Board will have V_SYS power input of 3.6V - 4.4V potentially from battery)

### HDMI connector mapping (future rev B)

The HDMI signal from the i.MX8 board is mapped to USB-C. While providing HDMI Ziloo cannot be connected
to

### USB4 support (future rev C)

* Use Texas Instruments TPS65994AD to route thunderbolt

USB Interface IC Dual port USB Type-C and USB PD controller with integrated source power switches 48-VQFN -40 to 125

[Temporary stop for Thunderbolt 4 and USB 4 on Intel’s Tiger Lake?](https://www.igorslab.de/en/goes-with-intel-for-tiger-lake-and-thunderbolt-4-bald-the-lights-out-what-chip-shortage-really-means-exclusively/)

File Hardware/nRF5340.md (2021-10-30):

# nRF5440

* [BT40 w. PCB antenna](https://www.digikey.com/en/products/detail/fanstel-corp/BT40/13174283) $13
* [BT40E with ext. antenna](https://www.digikey.com/en/products/detail/fanstel-corp/BT40E/13174285) $15
* [NORA-B100-00B](https://www.digikey.com/en/products/detail/u-blox/NORA-B100-00B/13534374) $13

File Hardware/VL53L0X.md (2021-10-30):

# VL53L0X

Use VL53L1X for the most features!

# VL53L5

* [Laser speckle contrast imaging](https://tstarling.com/blog/2016/09/laser-speckle-contrast-imaging/)
* [ESP32 Demo using a VL53L1X library and Ajax to display on a self-hosted site](https://github.com/easytarget/esp32-cjmcu-531-demo)

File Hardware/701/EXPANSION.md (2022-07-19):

# Ziloo Expansion Connectors

Ziloo has an M.2 type B expansion port for SSD utility cards, and a type E expansion port for Wireless utility cards.
Additional future expation ports are a 40 pin GPIO, uSIM / eSIM, Speakers, Microphones.

## 40 pins GPIO Header

The GPIO header is made to be compatible with RPi expansion hardware. It has fewer GND pins which are mapped to GPIO or receiving pins.

Features:

- Spare GPIOs
- SPI Image Boot
- Power 5V / 3V3 / 1V8 / RTC
- SPI / SAI7 I2S Out
- Stem and System I2C
- UART1 / UART3
- PWM1..3

:[40 pins GPIO Expansion](../pinouts/GPIO_HEADER.md)

## 40 pins Backplate breakout Header (development)

The Backplate breakout is available in place of the SOM connectors to connect directly from development boards to 919.

Features:

- MotionEngine IO
- LED Matrix driver

:[40 pins GPIO Backplate Header](../pinouts/BACK_GPIO_HEADER.md)

## Sound Connector

It is not yet defined if the signal level is 1.8V or 3.3V. It will depend on NVCC_SAI5
The pin layout wraps around aligning 1 and 20 close, but on opposite sides.

Two Connector components used are [DF40HC(3.5)-20DS-0.4V(51)](https://www.hirose.com/en/product/p/CL0684-4188-0-51). [Socket @ Mouser](https://www.mouser.ch/ProductDetail/Hirose-Connector/DF40HC35-20DS-04V51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)

:[Sound Connector](../pinouts/SOUND_CONNECTOR.md)

# M.2 Key B Expansion Module

Features:

- 1 Lane PCIe (PExx0)
- USB 3.0 data multiplexed (USB2/Host, PExx1)
- USB 2.0 data multiplexed (USB2/Host)
- GNSS / Stem I2C (I2C3)
- MFG I2C (SYS I2C)
- AUDIO I2S MIC SAI5 4 channels (GPIO5..8 and COEX*)
- SPI (ANTCTL*)
- DAS/DSS broken out with activity LED + expander bit
- Additional signals via 16 bit I/O Expander
- Some are broken out with pads near connector (CONFIG 0/2/3, DPR)
- SIM pins are not connected, reserved for now
- 4 channel I2S stereo input
- 4 channel I2S stereo output

The USB is connected to T-USB (not the M.2 expansions) on boot to support NVMe SSD expansions by default.
The USB data signals from SoM are multiplexed between T-USB Host (USB2) and M.2 Key B based on MUX_USB2_SEL & MUX_USB3_SEL.

Be aware the current pin plan is not final. Input/Ouput such as DIN/DOUT RXD/TXD may be the wrong way around.
It must be verified with reference hardware design/testing.

According to documentation: Type refers to the signal direction:
• Type O means signal is an output from the MPU/MCU to the adapter. 
• Type I means signals is an input to the MPU/MCU from the adapter.

### Control pins mapped by I/O Expander

The system I/O expander controls mPCIe_PERST which resets PCIe.
PCIE_CLKREQ_B is a direct pin on the SoM.
PCIE_WAKE_B is a direct pin on the SoM. 

TODO consider bootup default state of I/O Expanders. USB must not connect M.2 by default

TODO unallocated/GPIO pins from chipsets

A dedicated I/O Expander controls addition pins on Key B.

:[Expansion I/O Expander #2](../pinouts/I2C_EXPANDER_2.md)

:[M.2 Key B Pin allocations](../pinouts/M2_KEY_B_CONNECTOR.md)

### Reference designs

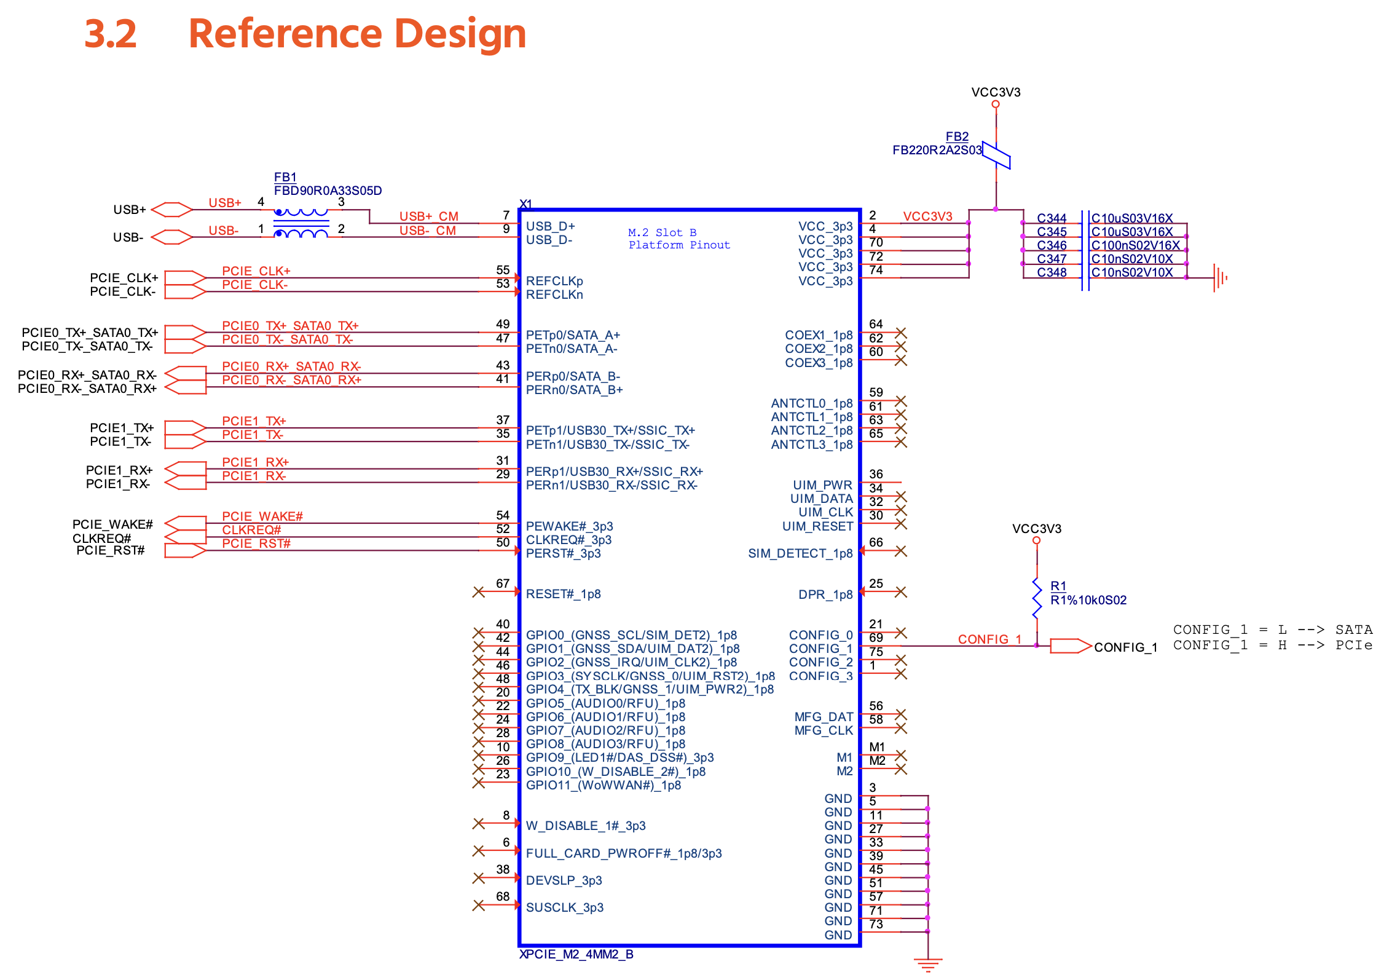
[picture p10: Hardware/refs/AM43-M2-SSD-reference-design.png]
Congatec reference design SSD Key B

Congatec reference design

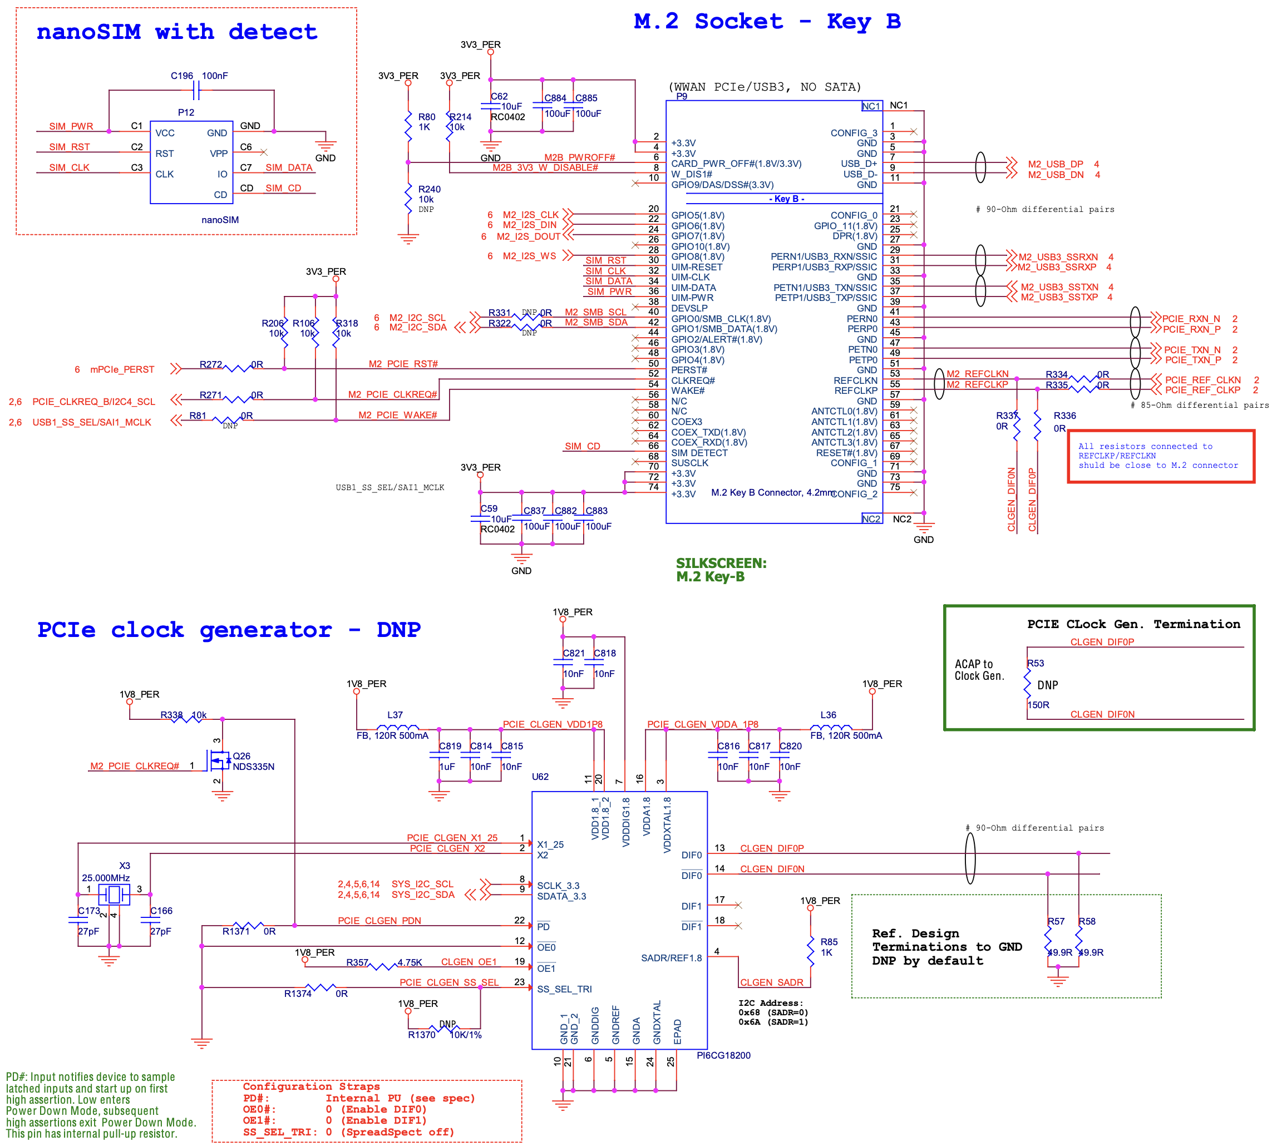
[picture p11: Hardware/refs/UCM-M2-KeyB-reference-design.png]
UCM Carrier Board reference design Key B

Compulab reference design

# M.2 Key E Expansion Module

Ziloo has an M.2 type E expansion port for Wireless/Bluetooth/GSM utility cards.

Features:

- UART2, UART4
- USB2/USB3 OTG data 
- SD1 SDIO 4bit
- PCIe single lane reserved pins
- JTAG + debugging pins reserved (lay out pads)
- Speaker I2S
- Two LEDs next to connector
- SIM pins are not connected, reserved for now

### Control pins mapped by I/O Expander

USB2_SS_SEL is a direct pin on the SoM.

TODO consider bootup default state of I/O Expanders. USB must not connect M.2 by default

TODO unallocated/GPIO pins from chipsets

A dedicated I/O Expander controls addition pins on m.2 connectors. Another I/O Expander allows
the Autonomous MCUs to manipulate m.2 state.

#### Expander #4

:[Expansion I/O Expander #4](../pinouts/I2C_EXPANDER_4.md)

#### Expander #6

:[Expansion I/O Expander #6](../pinouts/I2C_EXPANDER_6.md)

#### Key E pins

:[M.2 Key E Pin allocations](../pinouts/M2_KEY_E_CONNECTOR.md)

### Reference designs

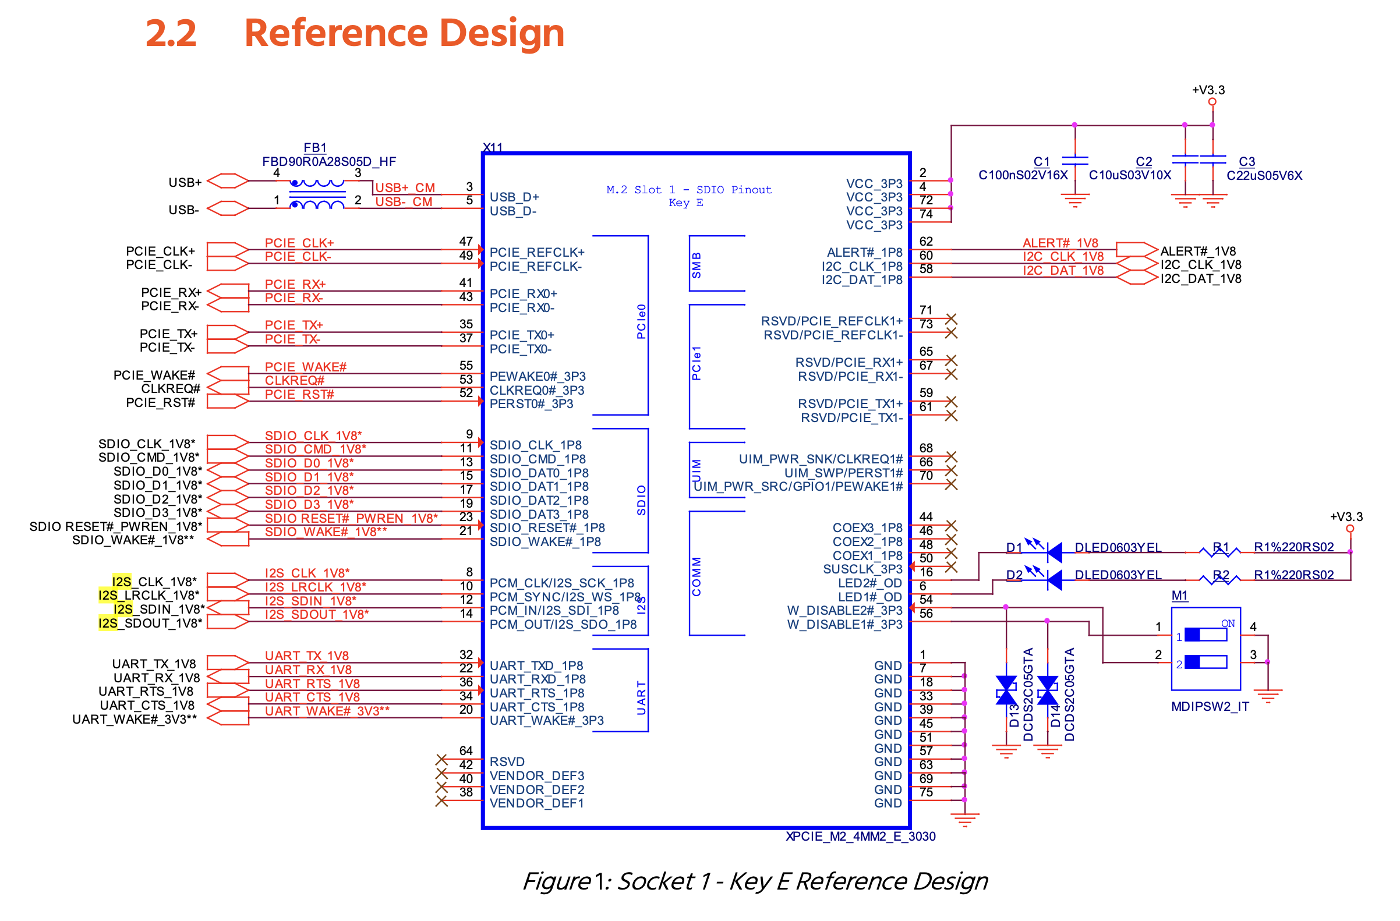
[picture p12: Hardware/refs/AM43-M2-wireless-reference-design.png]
Congatec reference design Wireless Key E

Congatec reference design

## Future Expansion connection

#### UIM / SIM / eSIM

M.2 Connectors have pins reserved for SIM (UIM) cards. A connector or eSIM may be added in the future.

i.MX 8 only provides PCIe x1 so Key M is not relevant. This leaves A, B and E.

- B is good for USB3, Audio, SATA
- E is good for SDIO, UART and PCM

- [ATP M.2 key info page](https://www.atpinc.com/blog/what-is-m.2-M-B-BM-key-socket-3)
- [Congatec AN43](https://www.congatec.com/fileadmin/user_upload/Documents/Application_Notes/AN43_M.2_Pinout_Descriptions_and_Reference_Designs.pdf)

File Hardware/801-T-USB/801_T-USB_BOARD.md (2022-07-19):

# 801 T-USB daughterboard

The 801 is a bridge board that connects daughter boards. 801 T-USB is one such daughter board.

The T-USB daughterboard has three functions
- Supply the system with power
- Provide data signals in the system over two USB-C connectors
- Manage autonomous system functions and waking state with an attached MCU.

The T-USB board exposes two vertical USB-C sockets and connects to the carrier board through two 50 pin B2B connectors.
Two 45 pin debug connectors provides options to experiment with USB-C Alt. mode and connect a Stem MCU for Autonomous functions.

Ziloo 801 T-USB Board

To facilitate feature development two additional connectors are added.

### Open points

- connectors for the two buttons; Lock and detach
- Which GPIO receives interrupt
- Mux chips shutdown mode
- Power LED & Indicator LEDs
- Add battery connector with temp. sensor JESDA?
- Optional connectors debug uart / jtag
- Annotations and Logo on the board
- TEST The Mux pin configurations
- How should PP_HV1 & PP_HV2 / PP1_CABLE PP2_CABLE be wired ?
- Default boot/SEL states connect USB 2.0/3.0 data routing and full power delivery / charging
- Enable VIN_5V/3V3 from PWR_SYS (TBD)
- Attachment signal / VSOM enable
- Detachment signal / Power down
- Trickle charging wireless coil over secondary connection on BQ24165, can this be supported on BQ24250 ?
- Reset button for RP, TPS, LiPo charger.

## Core Components

- 2 * [Hirose DF40-50DP-0.4V](https://www.hirose.com/en/product/p/CL0684-4014-0-51) mated height 1.5mm [Mouser](https://www.mouser.ch/ProductDetail/Hirose-Connector/DF40C-50DP-04V51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)
- 2 * [Hirose USB-C CX80B1-24P](https://www.hirose.com/product/p/CL0480-0625-0-00)
- 1 * [TPS65988](https://www.ti.com/product/TPS65988?keyMatch=TPS65988&tisearch=search-everything&usecase=GPN) Dual Port USB Type-C® and USB PD Controller, Power Switch, and High-Speed Multiplexer. [Mouser](https://www.mouser.ch/ProductDetail/Texas-Instruments/TPS65988DJRSHR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)
- 2 * [HD3SS460](https://www.ti.com/product/HD3SS460?keyMatch=HD3SS460&tisearch=search-everything&usecase=GPN) 4 x 6 Channels USB Type-C Alternate Mode MUX. Connected to T-USB Host. [Mouser](https://www.mouser.ch/new/texas-instruments/ti-hd3ss460-switch/). [Dock Eval Kit](https://www.mouser.ch/ProductDetail/Texas-Instruments/USB-CTM-MINIDK-EVM?qs=vcbl%252BK4rRletdX9FWp9J9A%3D%3D)
- 1 * [PCA9555 I/O Expander HVQFN24 package](https://www.nxp.com/part/PCA9555D) $1.74/1pcs $0.64/1000pcs
- 4 * [TS5USBC410 Dual 2:1 USB 2.0 Mux/DeMux Switch](../datasheets/USB/ts5usbc41.pdf). [Mouser](https://www.mouser.ch/ProductDetail/Texas-Instruments/TS5USBC410IYFFR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)
- 1 * [BQ24250RGER battery charger](https://www.ti.com/product/BQ24250)  [$2 JLCPCB (4x4 mm package)](https://jlcpcb.com/parts/componentSearch?isSearch=true&searchTxt=BQ24250) [Mouser](https://www.mouser.ch/ProductDetail/Texas-Instruments/BQ24250RGER?qs=VqERlb%252BKohfBI76g9iGg8g%3D%3D)
- 2 * [3 pin JST SH socket SM03B-SRSS-TB](https://www.jst-mfg.com/product/detail_e.php?series=231) - [JLCPCB](https://jlcpcb.com/parts/componentSearch?isSearch=true&searchTxt=SM03B-SRSS-TB) - [Farnell](https://ch.farnell.com/jst-japan-solderless-terminals/sm03b-srss-tb-lf-sn/stecker-90-3kont/dp/1679118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) (Matched by JST PHR-3)

## Dev. Connectors

- 2 * [TE Connectivity 45PIN 0.3MM 571-4-2328724-5 FPC 3-2328724-5](https://www.te.com/usa-en/product-4-2328724-5.html) $0.41

## Alternate Components

- [SuperSpeed MUX PI5USB30213A](https://www.diodes.com/part/view/PI5USB30213A/) may be an option intead of CBTL04083
- [Alternate USB 2.0 Mux/DeMux](https://www.diodes.com/part/view/PI3USB102G/) [Mouser](https://www.mouser.ch/ProductDetail/Diodes-Incorporated/PI3USB102GZLEX?qs=mt7EBqA2jzg7v2qs76v1VQ%3D%3D) [JLCPCB part](https://jlcpcb.com/parts/componentSearch?isSearch=true&searchTxt=DF40C-60DS-0.4V)
- [Alternate 50 pins DF12NC(3.0)-50DS-0.5V(51)](https://www.hirose.com/en/product/p/CL0537-0198-0-51)
- [Multi cell design with BQ25792](https://www.ti.com/product/BQ25792)
- Optional SPI NOR flash 1Mbit 3.3V, 12MHz
- 2 * TPS63030 buck/boost converters (pick cheaper alternative to up/down regulate with enable pin)
- [BQ25253](https://www.ti.com/product/BQ24253)  $5 JLCPCB (2.4x2.4 mm package)
- [ANX7688 USB-C HDMI bridge](https://www.analogix.com/en/products/convertersbridges/anx7688) replacing HD3SS460 for Host USB 3.0 Alt Mode. [ANX7688 on PinePhone](https://xnux.eu/devices/feature/anx7688.html). [Pinephone HDMI hot-plug-detection HW bug](https://xnux.eu/log/#045).
- [Panasonic AXT534124 socket/receptacle]() - [Mouser](https://www.mouser.ch/ProductDetail/Panasonic-Industrial-Devices/AXT534124/?qs=2rFUEsTwVNxdSFw7IuWdSA==)
- [BM29B-6DP/2-0.35V(51) 6 pin Board to Board power connector](https://www.mouser.ch/ProductDetail/Hirose-Connector/BM29B-6DP-2-0.35V51?qs=Cb2nCFKsA8rUbAFx2SRDGg%3D%3D)

## Firmware Drivers

- [TPS65988 Linux](https://github.com/torvalds/linux/tree/1bff7d7e8c487b9b0ceab70b43b781f1d45f55eb/drivers/usb/typec/tipd)
- [BQ2425x Linux](https://github.com/torvalds/linux/blob/master/drivers/power/supply/bq24257_charger.c)
- [MC6470 Linux](https://github.com/mcubemems/mCube_mc6470_mc7030_mcu_driver)

# Data Routing

The basic data routing on the board is prepared for future expansion. There are a lot more connections into the board than are actually used.

Possible future extensions
- USB-C Alt. mode HDMI/DP
- UART over USB 2.0
- I2C over USB 2.0

In the base setup without added logic the board routes USB 3.0/2.0 data through the two USB-C connectors.

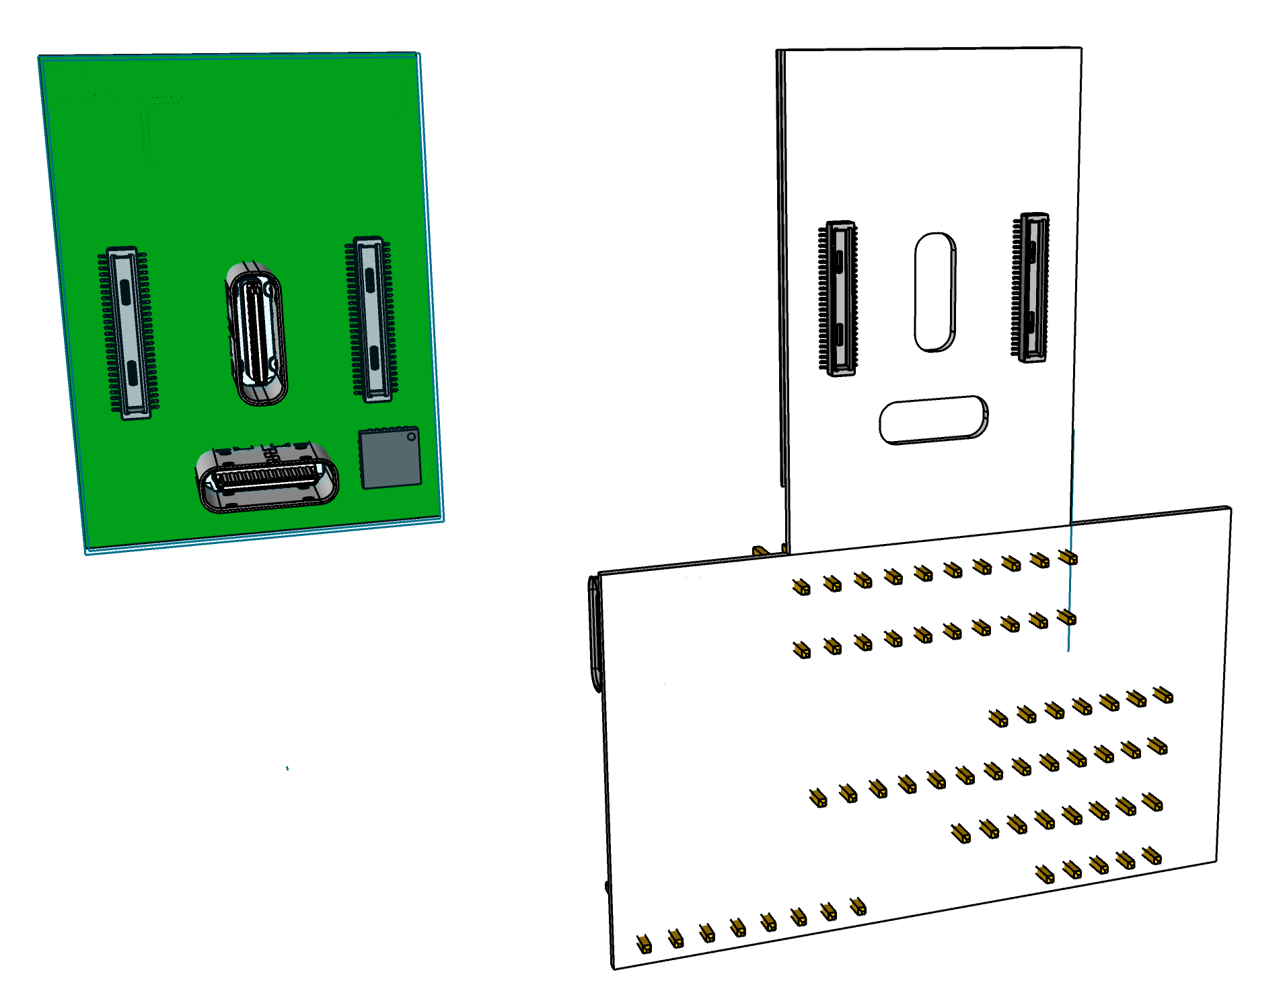
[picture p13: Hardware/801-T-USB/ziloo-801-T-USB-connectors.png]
Ziloo 801 T-USB Board


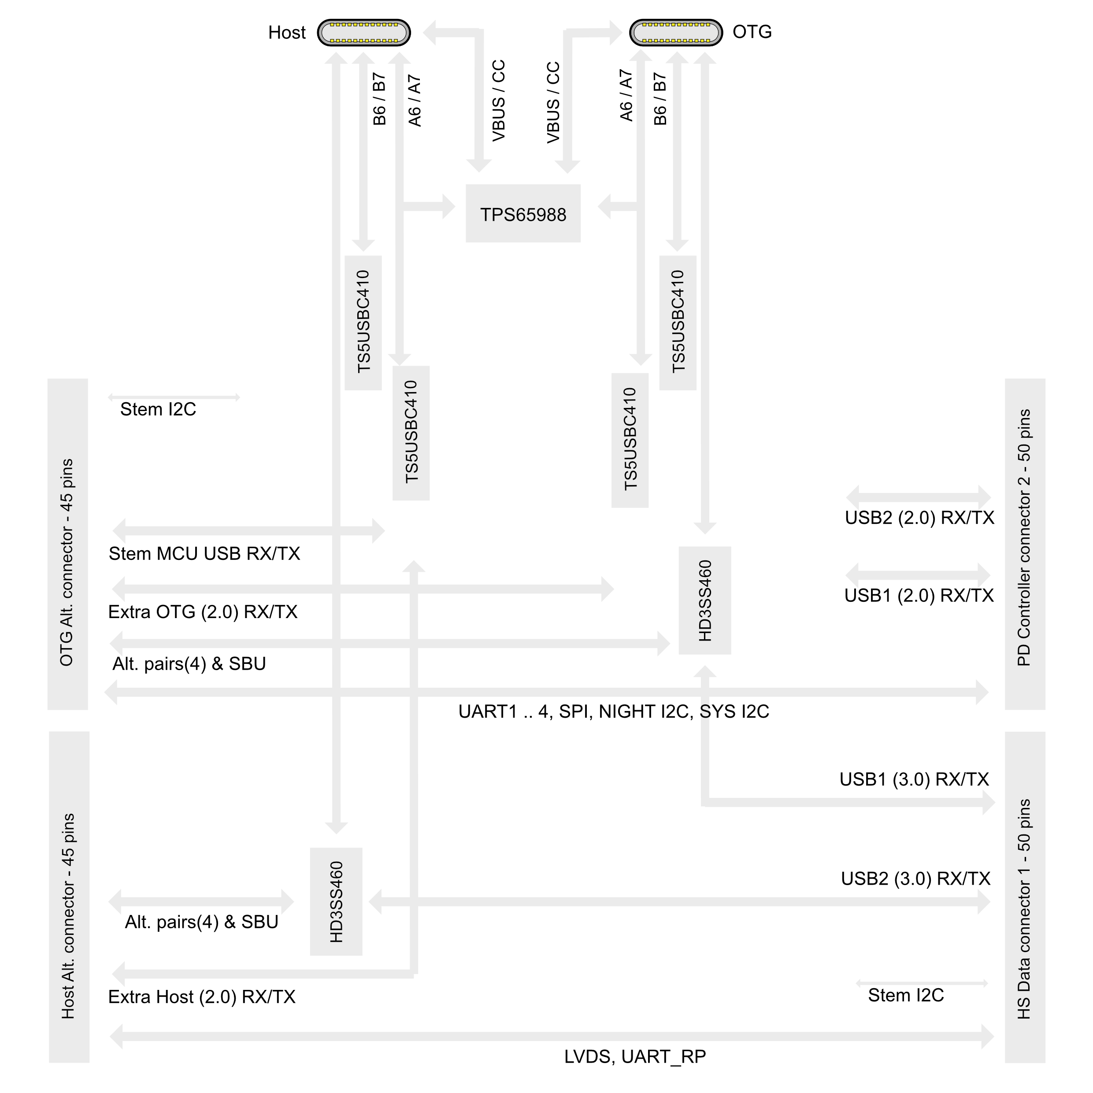
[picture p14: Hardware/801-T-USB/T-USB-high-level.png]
High level data


### Board

66 mm x 24 mm

The two 50 pin connectors are placed with a gap of 16 mm between their midpoint.
These two connectors are vertically centered on the center of the vertical USB-C connector.

The two 45 pin data breakouts are placed on one edge with a 2 mm gap.

Components on the underside can be max 0.5mm thick. They can be placed above the horizontal USB-C.

### Multiplexing USB

The board has two types USB busses 2.0 and 3.0 for both of the USB-C connectors.
One off-board source are USB from the bridge board the module attaches to.
The Bridge boards supplies USB1(supports OTG) and USB2(Host mode only).

USB 3.0 is multiplexed as part of USB-C orientation support and is multiplexed between normal and alternate mode.
With additional hardware the OTG USB 3.0 side can be made to support HDMI/DP in Alt. mode.
The USB-C connector Alt. mode is managed by HD3SS460. The wiring is done very much like the diagram at
page 1 of the datasheet.

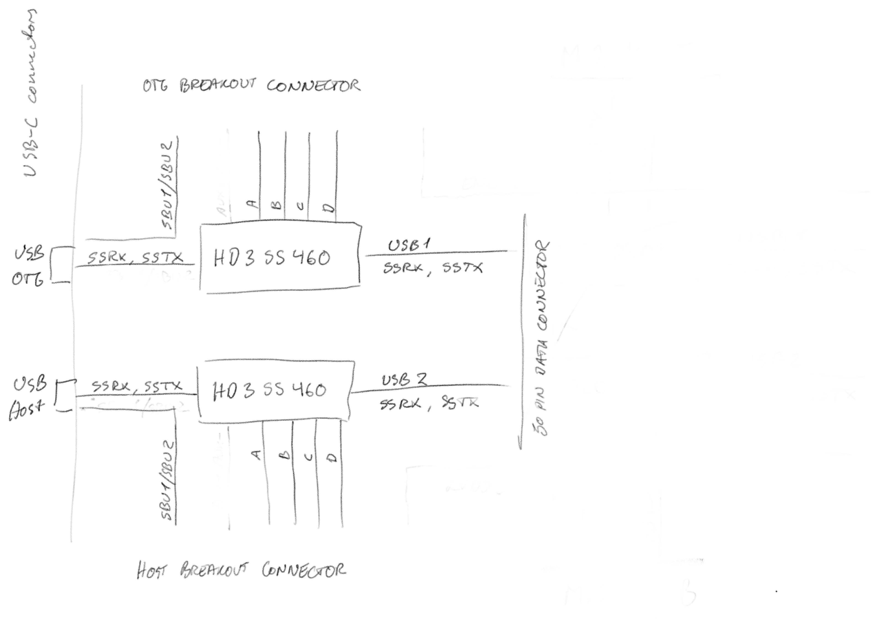
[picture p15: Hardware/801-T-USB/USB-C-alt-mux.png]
Connecting USB 3.0 data and Alt. Mode


Each of the two USB-C connector USB 2.0 signals(A/B 6/7) are managed separately and multiplexed using TS5USBC41. 
This allows routing Stem MCU USB 2.0, System Module(OTG or Host) USB 2.0 and Extra USB 2.0(Alt Breakout connector) signals selectively via a 4 pins on a single USB-C connector. 

The switching is done using nXA_SEL and nXB_SEL, where I assume that the default state is low.
Mux A switches between the Stem MCU USB 2.0 signals and the System Module USB 2.0 signals.
Mux B switches between the output of Mux A and the Extra USB 2.0 from the Alt Breakout connector.

The default for Mux A is Stem MCU.
The default for Mux B is Mux A.

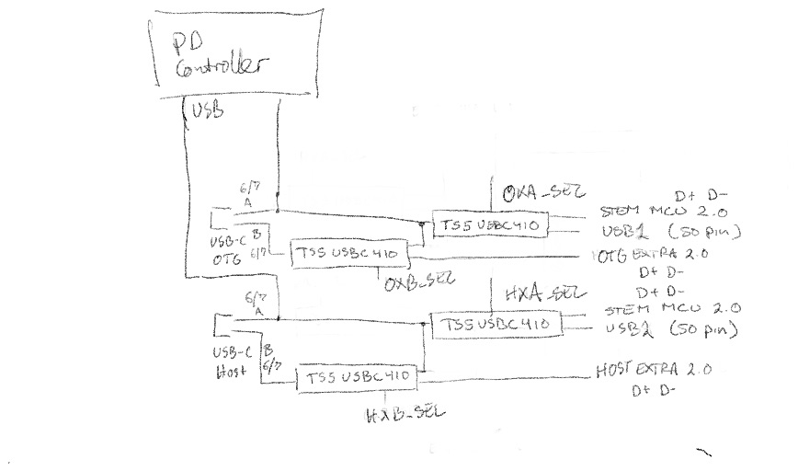
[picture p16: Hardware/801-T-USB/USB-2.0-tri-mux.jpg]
Connecting USB 2.0 data, stem and Extra


# Power Supply

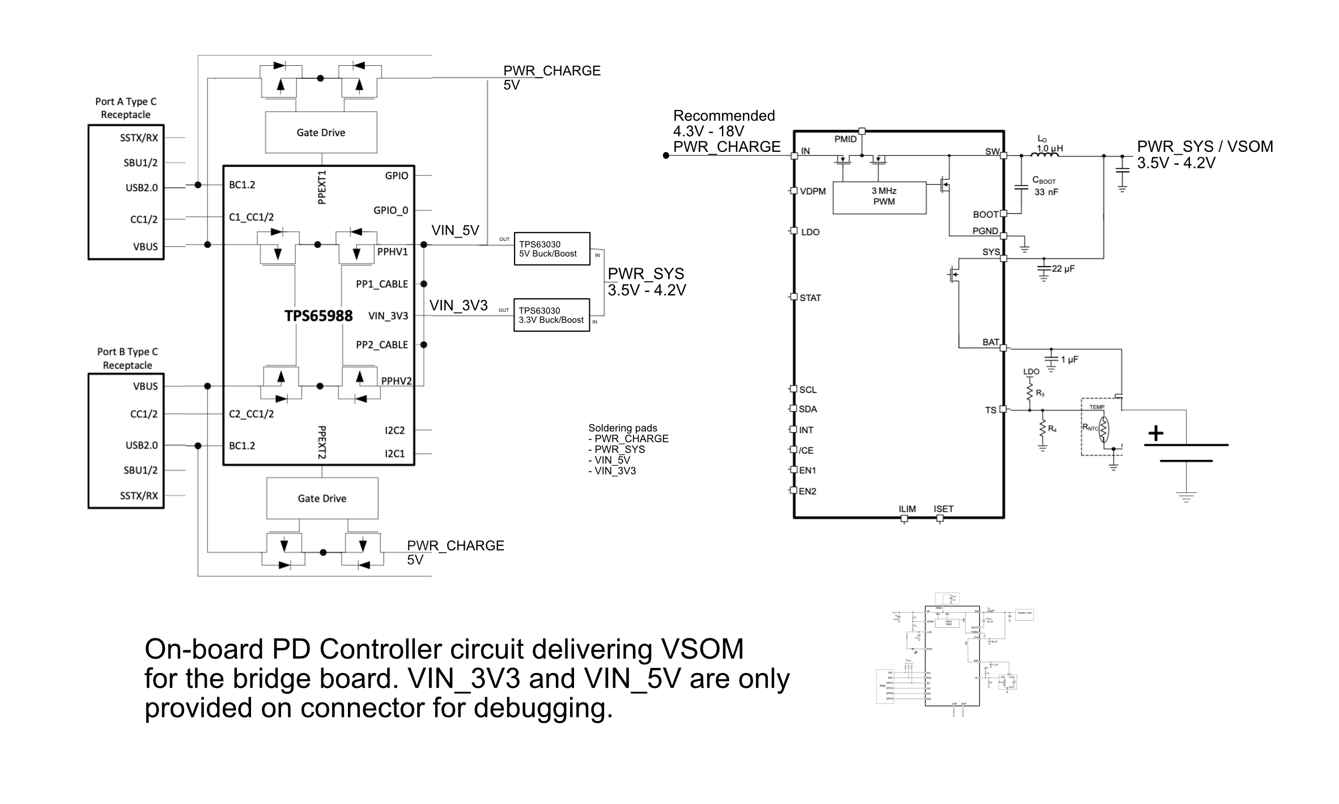
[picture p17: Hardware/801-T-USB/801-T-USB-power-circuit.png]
Power circuit


## Power Output vs Input

The board is primarily a USB power sink, it isn't meant to be a significant source of USB power output.
For testing purposes the connectors provide two VIN_5V pins, which are supplied with up to 500 mA from the testing board
by upscaling PWR_SYS to 5V. When connected to the regular bridge board VIN_5V and VIN_3V will not be supplied.

The board itself can be a source of 5V on one port, if it is a sink on the other port. For this purpose a direct connection is drawn from PWR_CHARGE to VIN_5V.

## System Power

The system power is driven by the Battery Charger, while the charging power comes from the PD Controller. 

:[Power Module Connection](../refs/POWER_MODULE_CONNECT.md)

[?] connectors for the two buttons

## Acceptance Criteria on Power

- High voltage USB-C (20V / 12V / 9V) power supplies never produces more than 5V SYS_PWR when connected.
- If one USB port receives power (5V) the other port can deliver power (5V).
- VSOM is 3.45V to 4.4V regardless of charger
- If a Apple Dedicated Charger 5V(1A BC1.2) is connected the board can draw 1A
- If a CDP(5V, 1A) compatible charger is connected the board can draw 1A
- If a CDP(5V, 3A) compatible charger is connected the board can draw 3A

## Combined T-USB control I/O Expander

Expander #3 combines control signals.

:[Combined T-USB control I/O Expander](../pinouts/I2C_EXPANDER_3.md)

## I2C adressing

:[Stem I2C addresses](../pinouts/STEM_I2C_ADDRESSES.md)

:[SYS I2C addresses](../pinouts/SYS_I2C_ADDRESSES.md)

The Night I2C bus is just connected between 45 pin ALT_CONNECTOR and the 50 pin connector.

# Battery Charging

Battery charging is an optional feature enabled by connecting a LiPO battery cell.

- Switch between trickle charge(0.1C) and fast charge(1.5C).
- Charge strategy timout setting
- Suspend on low power
- Resume on good power

In reference board design the PCIe clock is configured to use I2C address 0x68 which is needed by the BQ24250RGER.
On the Ziloo Bridge board the PCIe clock circuit has been reconfigured.

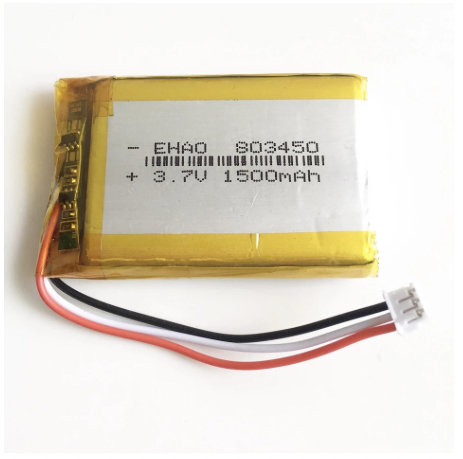
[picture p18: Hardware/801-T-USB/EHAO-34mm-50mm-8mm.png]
Sample Li-Po battery


## Power output from Charging Controller

When operating with single cell Li-Ion batteries, output voltage range can be from 3.0V-4.2V. It is recommended not to operate at minimum battery voltage, to prolong a Li-Ion battery’s life. Please refer to the battery manufacturer’s data sheet or design guide for details.

- VSOM output Main power for board 3.5V - 4.2V 
- Direct power input pads support 4V - 6V

The board will attempt to constantly supply power. Either from a 3.7V LiPO battery, 5V input solder pads, or USB power source.

The system should attempt to detect low power and suspend or power down before 
reaching VSOM 3.45V.

## Measuring battery voltage

https://blog.ampow.com/lipo-voltage-chart/

The battery charger will deliver a voltage close to 4.0V under normal charging conditions.
It will deliver a steady 3.5V level during precharge during the ~120 s.

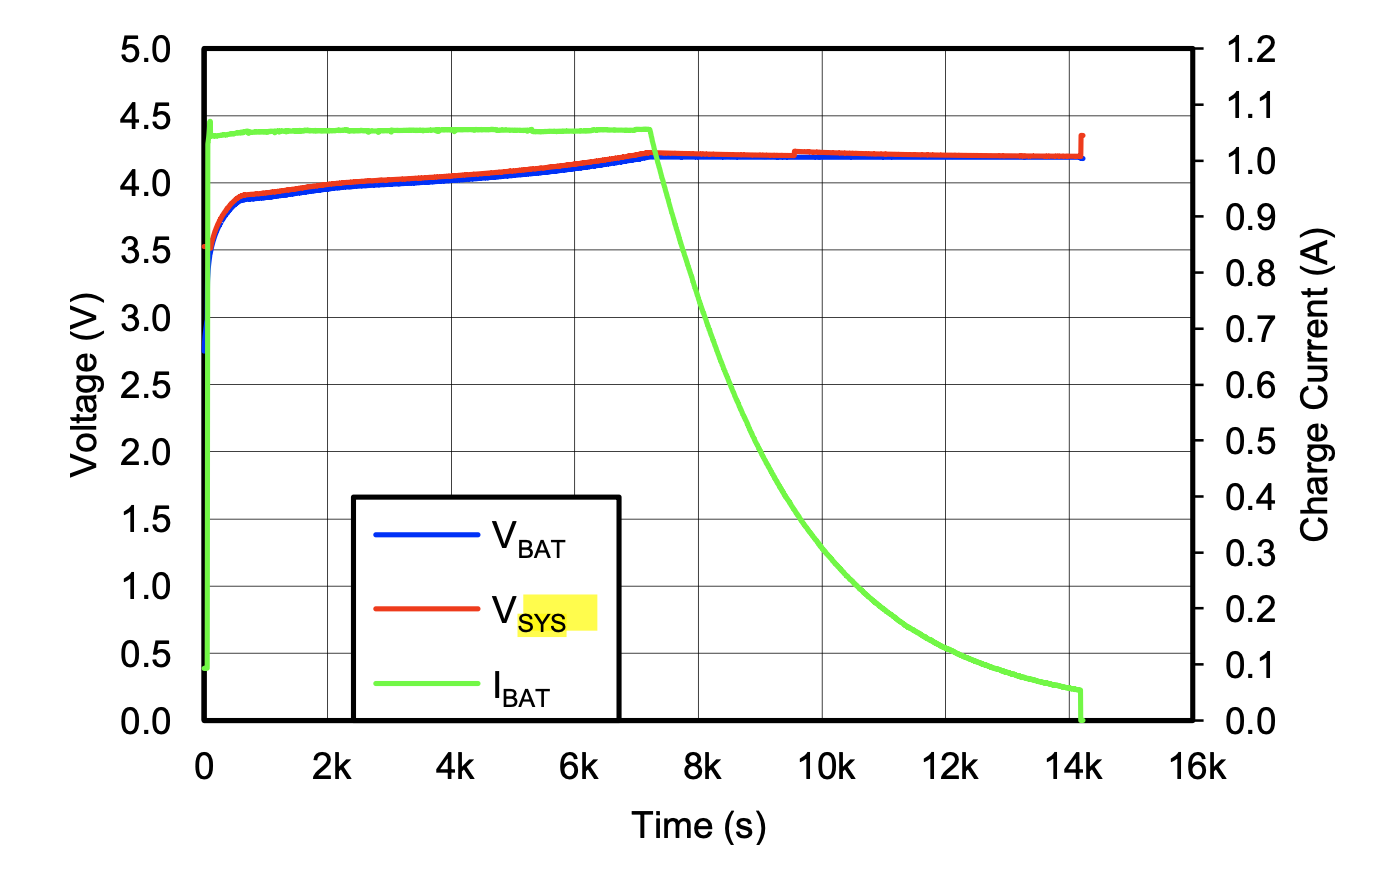
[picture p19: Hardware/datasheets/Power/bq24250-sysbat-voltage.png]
Voltage SYS & BAT


Drawing charger + PD = VSOM

## Managed charging

The bq24250 device has two modes of operation: 1) I2C mode, and 2) standalone mode. In I2C mode, the host adjusts the charge parameters and monitors the status of the charger operation. In standalone mode, the external resistor sets the input-current limit, and charge current limit. Standalone mode also serves as the default settings when a DCP adapter is present. It enters host mode while the I2C registers are accessed and the watchdog timer has not expired (if enabled). The battery is charged in four phases: trickle charge, pre-charge, constant current and constant voltage. In all charge phases, an internal control loop monitors the IC junction temperature and reduces the charge current if the internal temperature threshold is exceeded.

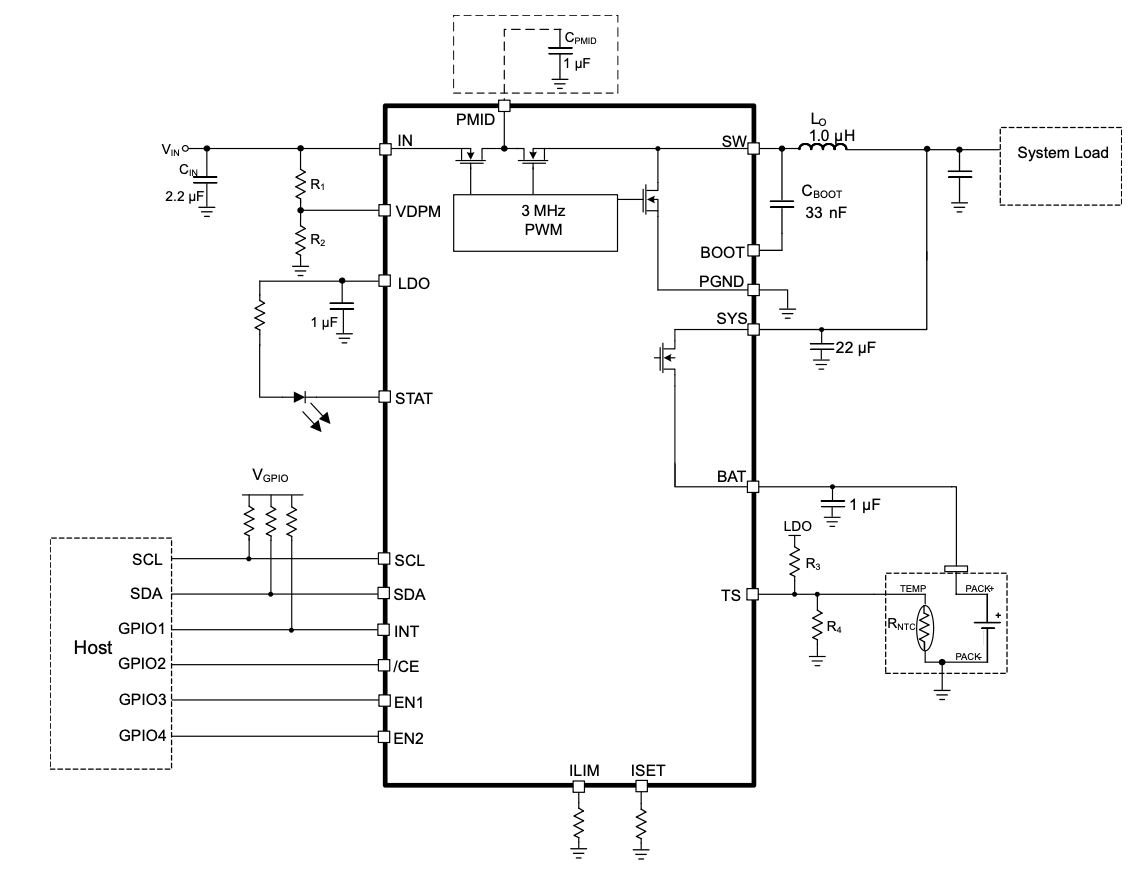
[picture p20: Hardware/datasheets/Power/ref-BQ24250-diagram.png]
BQ24250 reference diagram


#### Max input current limit

The circuit will be in I2C mode rather than standalone so perhaps the programming with a resistor isn't important.
The documentation seems to indicate that it's used as a fallback.

Short ILIM to GND for default 2A input current(IN) limit.
EN2 = Low
EN1 = High

EN1 could be driven by extender to enable switching between 0.5A and 2A.

R_ILIM = 270 / I_IC

Does this mean that 4 resistors of 540 ohm in parallel with breakable soldering points would allow adjusting the board to a specific battery?
Charge current ISET resistor 500mA / 1A / 2A (4 resistors in parallel?)

#### Acceptance Criteria on Power With Battery

- If power is connected to USB the battery can charge
- If no power is connected the system is battery powered

# 801 T-USB Connector Pinouts

## 3 pin Power Enable Connector

The connector must be oriented along the board to allow packing of battery and board.

| Pin | |
|---|---|
| VSOM_LOCK | When raised high it signals the backplate is locked in |
| VSOM | General board power |
| SHUTDOWN_BTN | When raised it signals a request to runtime modules to shut down |

## 3 pin Battery Connector

Connect battery via GND, TEMP (TS), PACK+ (BAT). This is done over a 3 pin JST H 1mm pitch socket.
The connector must be oriented along the board to allow packing of battery and board.

| Pin | |
|---|---|
| GND | Ground Black  |
| TS | TEMP  White |
| BAT | PACK+ Red |

## 50 pin B2B connectors

:[DF40 50 pin connectors](../pinouts/T-USB_50_PINS_CONNECTORS.md)

## USB-C connectors arranged in a T

Two USB-C connectors are arranged in a T shape and the normal way to use it is with a combined connector
attached. This means that the wires will normally be connected in a particular orientation. The system
takes advantage of this by detecting when both USBs are connected in the normal arrangement.

The pins are individually connected to chipsets in order to allow multiplexing based on the situation.

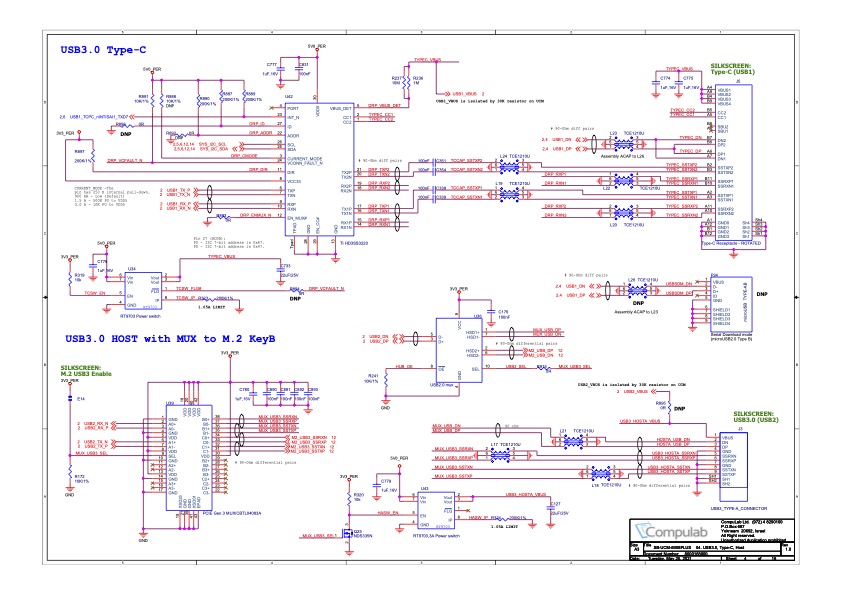
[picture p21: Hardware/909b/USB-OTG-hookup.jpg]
USB OTG reference hookup


:[T-USB Connector Mapping](../pinouts/T-USB_WITH_ALT_CONNECTOR_PINOUT.md)

## T-USB alt mode connectors

These connectors(only on the development model) enables experimentation with alternate modes and directional pins.

Host ALT

:[45 pins T-USB Host alt mode connector](../pinouts/T-USB_HOST_ALT_CONNECTOR.md)

OTG ALT

:[45 pins T-USB OTG alt mode connector](../pinouts/T-USB_OTG_ALT_CONNECTOR.md)

## Soldering Pads

A number of connections should be broken out on the board as soldering pads (no through hole)

| Pin | Function |
|---|---|
| VSOM | Output or Input |
| VCC_RTC | Power input RTC battery 1.8V |
| PP_HV1 | PD Controller power | 
| PP_HV2 | PD Controller power | 
| VIN_5V | PD Controller System 5V for PP1_CABLE, PP2_CABLE |
| VIN_3V3 | PD Controller System 3.3V |
| GND | |

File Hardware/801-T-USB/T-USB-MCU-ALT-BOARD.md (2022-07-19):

# T-USB MCU Alt. Board

The T-USB board has two 45 pin Alt. Connectors that provide the ability to hook in to the core of the board.
The MCU will be integrated in the production version of the T-USB board, but for development and testing it
will remain separate. 

## T-USB OTG alt mode connector

The MCU connects primarily through the OTG Alt mode connector pins 19 to 45.
These connectors(only on the development model) enables experimentation with alternate modes and directional pins.

:[45 pins T-USB OTG alt mode connector](../pinouts/T-USB_OTG_ALT_CONNECTOR.md)

The RP2040 is powered by 3V3(1, 4, 7) and GND(16, 30, 33) from the connector.

## Firmware

The firmware on the RP must select a number of known devices primarily via the I2C bus.

### Ziloo Autonomous App

The App is a Git Repo codebase as a Zephyr Workspace App with

- Custom Board Definitions
- Explicit port definitions for all the relevant pins
- Device drivers for common sensors
- Integration of MicroPython allowing scripts to be run

### Activity Device (/dev/activity)

:[Activity Device](../refs/ACTIVITY_DEVICE.md)

### Broadcom APDS-9960 Proximity Light and Gesture Sensor

On Night I2C on address 0x39.

Testing:
- https://upy-apds9960.readthedocs.io/en/latest/

### PCA9555 I/O Expander

On Stem I2C on address 0x23

Refs
- https://github.com/dfletcher/avr-pca9555
- [Sample Board with a PCA9555 MEC15xxEVB ASSY6853](https://docs.zephyrproject.org/latest/boards/arm/mec15xxevb_assy6853/doc/index.html)

### IS31FL3730 8x8 LED matrix

On Stem I2C

https://github.com/PastravMD/microdot-phat-driver

- [Adafruit breakout board](https://www.adafruit.com/product/2946)
- 

### TPS65988 PD Controller

On Stem I2C

### BQ24250RGER battery charger

On Stem I2C

### Virtual OTG USB Comm ports 

- UART1 .. UART4 as individual devices available on the USB 2.0

### VM3011 Multi-mode microphone

- Connected via PDM pins
- Interrupts on sound

[Create a USB Microphone with the Raspberry Pi Pico](https://www.hackster.io/sandeep-mistry/create-a-usb-microphone-with-the-raspberry-pi-pico-cc9bd5)

### MC6470 Motion Sensor

On Stem I2C on address 0x4C

### DVP parallel camera interfacing over SPI or SCCB imaging

https://www.arducam.com/raspberry-pi-pico-tensorflow-lite-micro-person-detection-arducam/

https://maker.pro/arduino/tutorial/how-to-interface-the-ov7670-camera-module-with-arduino

### TinyML

- Zephyr
- CircuitPython

## Stem I2C addresses

:[Stem I2C addresses](../pinouts/STEM_I2C_ADDRESSES.md)

## Pico / RP2040 pin mapping

:[RP2040 pin mapping](../pinouts/RP2040_PIN_MAPPING.md)

## Additional pins

A header needs to break out pins for connection to Host Alt Connector or others.
The header also needs to break out the OTG Alt. Mode lanes and Extra pair.

| 31  | SWD CLK RP       |          |                                      |         |
| 32  | SWD DAT RP       |          |                                      |

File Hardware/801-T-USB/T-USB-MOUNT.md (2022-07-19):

The T-USB module connects two USB-C connectors to the board via multiplexers and a Power Delivery Controller.
USB Data is routed over the 50 pins data connector as well as the M.2 Expansion connector.
The Host USB connection is multiplexed between thw two.

### T-USB connector 3.0 data mapping

Two USB 2.0/3.0 connections are provided by the T-USB module.
T-USB module 50 pin connectors supply/consume:

* USB1 v2 / v3 data
* USB2 v2 / v3 data
* LVDS data pairs
* UART 1/2/3/4
* I2C SYS/3
* GPIO4_IO19, GPIO1_IO0, GPIO1_IO1
* SYS_RST_PMIC / POR_B_3P3 / PMIC_ON_REQ / PMIC_STBY_REQ / PWRBTN / ALT_BOOT / QSPI_BOOT_EN_3P3
* VCC_RTC 

T-USB module 50 pin connectors not connected:

* SPI
* SWD

### Multiplexing USB

The i.MX8 has two USB busses. USB1(supports OTG) and USB2(Host mode only).

The USB 3.0 superspeed Host/USB2 from the SoM are multiplexed using CBTL04083 and controlled by MUX_USB3_SEL pins.

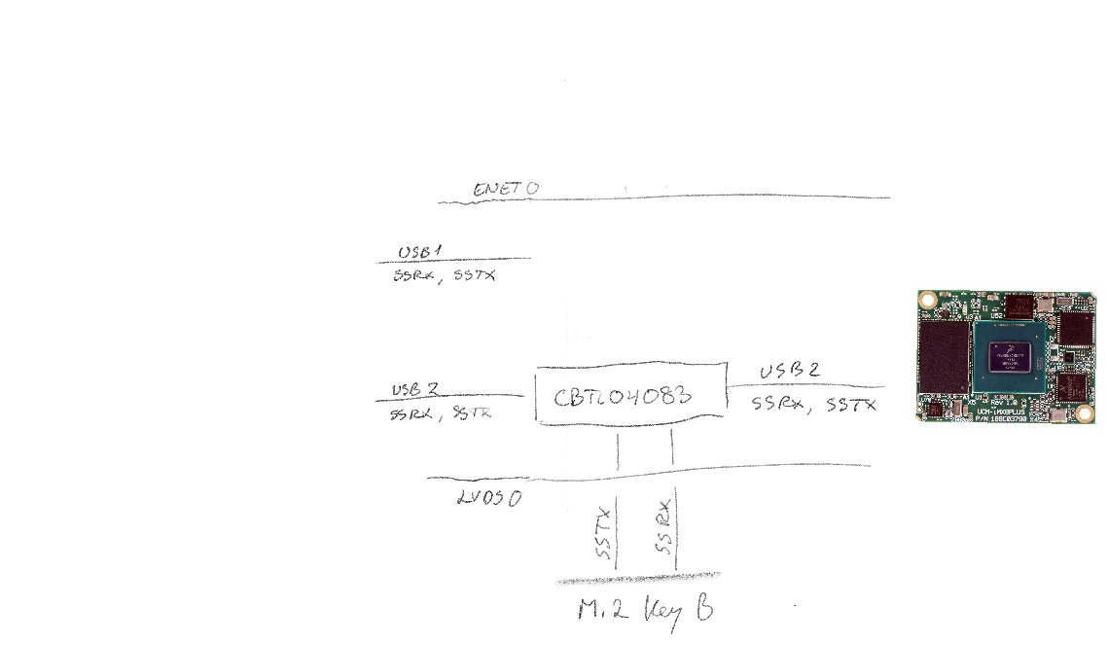
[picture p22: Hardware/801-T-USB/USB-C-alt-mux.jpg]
Connecting USB 3.0 data and Alt. Mode


The USB 2.0 Host/USB2 from the SoM are multiplexed using TS5USBC41 and controlled by MUX_USB2_SEL pins.
The USB-C connector USB 2.0 signals(A/B 6/7) are managed separately and multiplexed using TS5USBC41. This allows
routing an Extra USB 2.0 signal selectively via the Debug Breakout connector.

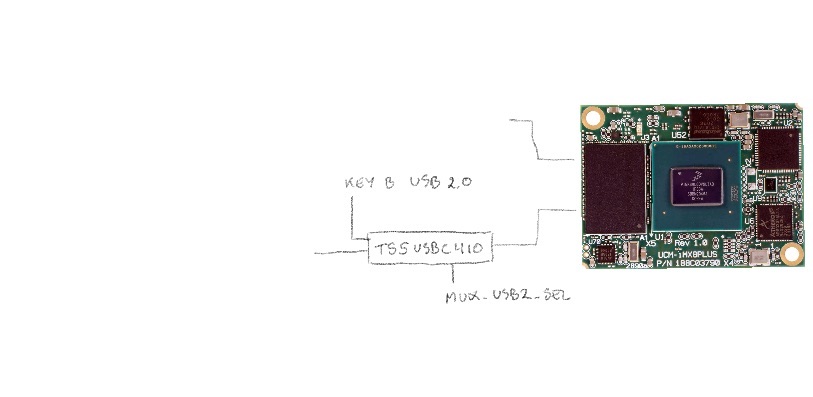
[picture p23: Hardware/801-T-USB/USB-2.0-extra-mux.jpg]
Connecting USB 2.0 data and Extra


| SEL  | Connect to |
|---|---|
| High | m.2 |
| Low  | T-USB |

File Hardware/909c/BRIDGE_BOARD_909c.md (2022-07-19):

# Bridge Board 909c

The 909c is a Bridge Board version made for testing and experiementation with the Ziloo attachments without attaching
the SB-UCM i.MX8 board or directly attaching it. 
The setup enables connecting a [Compulab SB-UCM-iMX8PLUS](https://www.compulab.com/products/carrier-boards/sb-ucmimx8plus-carrier-board/), [DART-MX8M-PLUS Evaluation Kit](https://www.variscite.com/product/system-on-module-som/cortex-a53-krait/dart-mx8m-plus-nxp-i-mx-8m-plus/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) or 
[I-Pi SMARC IMX8M Plus](https://www.ipi.wiki/products/i-pi-smarcplus-imx8mp) development board.
Not all the 909 connectors will be mounted on the 801 production bridge board that mounts the i.MX8 board.

Of note in design,

- Some of the UCM-iMX8M-Plus carrier board interface pins are multifunctional. Up to 4 functions (ALT modes) are accessible through each multifunctional pin.
- All of the UCM-iMX8M-Plus digital interfaces operate at 3.3V voltage levels unless noted otherwise.
- RGMII ENET1 signals operate at 1.8V voltage level
- SD/SDIO port #2 can be configured to operate at 3.3V or 1.8V voltage levels. Voltage level is controlled by SoC pin GPIO1_IO04.

Ziloo Bridge Board 909c

### Open points

- B2B sound/I2C connectors
- Mux chips shutdown mode
- Should there be Boot origin switches like EVK? (4 bits? EVK)
- Annotations and Logo on the board
- TEST The Mux pin configurations

## <mark>Difference from revision B</mark>

- The PD Controller is no longer on the bridge board
- The Power module connects to the bridge board to provide dual USB-C
- Two 50 pin connectors take high speed and low speed signals to USB-C connectors
- Two 20 pin sound connectors
- Only 1 alternative CSI connector for each side
- I2S Mic removed from debug connector, CAN1/CAN2 added.
- No soldering pads
- No Alt USB breakouts on bridge board
- No Alt mode on bridge board
- No I2C breakouts on bridge board
- No 45 pin Alt Mode Connectors
- Only m.2 Key B (no Key E)
- Pulled parts out in BRIDGE_BOARD_CAMERA, BRIDGE_BOARD_SOUND, BRIDGE_BOARD_M2_KEY_B documents.

## Core Components

- [SB-UCM-iMX8PLUS](https://www.compulab.com/products/computer-on-modules/ucm-imx8m-plus-nxp-i-mx-8m-plus-som-system-on-module-computer/) System-on-Module
- 2 * [Hirose DF40HC(3.0)-100DS-0.4V](https://www.hirose.com/en/product/p/CL0684-4151-0-51) mated height 3.0mm
- 2 * [Hirose DF40-50DS-0.4V](https://www.hirose.com/en/product/p/CL0684-4009-0-51) mated height 1.5mm [Mouser](https://www.mouser.ch/ProductDetail/Hirose-Connector/DF40C-50DS-04V51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) - [JLCPCB socket](https://jlcpcb.com/parts/componentSearch?isSearch=true&searchTxt=DF40C-50DS-0.4V)
- M.2 key B connector H4.20mm [Amphenol ICC 10128793001RLF](https://www.amphenol-icc.com/pci-express-10128793001rlf.html)
- 2 * [Hirose DF40C-34DS-0.4V](https://www.hirose.com/en/product/p/CL0684-4023-0-51) ([Mouser](https://www.mouser.ch/)
- 1 * microSD card slot (suggested Molex 5031821852) push-push, compact. [Mouser](https://www.mouser.ch/ProductDetail/Molex/503182-1852?qs=s7UCm7gO1bZmpyAhCKZ26g%3D%3D), [Molex](https://www.molex.com/molex/products/part-detail/memory_card_socket/5031821852)
- 1 * [CBTL04083 Multiplexer Switch ICs 3.3V CH 2:1](https://www.nxp.com/part/CBTL04083ABS#/) - [Mouser](https://www.mouser.ch/ProductDetail/NXP-Semiconductors/CBTL04083ABS518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)
- 3 * PCA9555 I/O Expander
- 1 * [TS5USBC410 Dual 2:1 USB 2.0 Mux/DeMux Switch](../datasheets/USB/ts5usbc41.pdf). [Mouser](https://www.mouser.ch/ProductDetail/Texas-Instruments/TS5USBC410IYFFR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)

## Dev. Connectors

- 1 * MicroHDMI (suggested Molex 46765-1301) [Mouser](https://www.mouser.ch/ProductDetail/Molex/46765-1301?qs=sGAEpiMZZMt1iCLsaqcCFmQhPEZFSo0wUGorAW08d1I%3D) [Molex](https://www.molex.com/molex/products/part-detail/io_connectors/0467651301)
- 1 * [Molex 22PIN 0.5mm pitch 54548-2271](https://www.molex.com/molex/products/part-detail/ffc_fpc_connectors/0545482271)
- 1 * [I-PEX 30PIN 0.4mm pitch 20525-030E-02](https://www.i-pex.com/product/cabline-ca)
- 1 * [TE Connectivity 45PIN 0.3MM 571-4-2328724-5 FPC 3-2328724-5](https://www.te.com/usa-en/product-4-2328724-5.html) $0.41
ProductDetail/Hirose-Connector/DF40C-34DS-04V51?qs=vcbW%252B4%252BSTIpg26DsEbj1iQ%3D%3D))
- 2 * [Hirose DF40-20DS-0.4V](https://www.hirose.com/product/p/CL0684-4005-9-51) mated height 1.5mm [Mouser](https://www.mouser.ch/ProductDetail/Hirose-Connector/DF40HC35-20DS-04V51) - [JLCPCB socket](https://jlcpcb.com/parts/componentSearch)

## Other Components

Connectors placed on the board are,

- [PI6CG18200 clock](https://www.diodes.com/part/view/PI6CG18200?BackID=2328)
- 1 * 24C08 Carrier-board EEPROM. [Mouser](https://www.mouser.ch/ProductDetail/STMicroelectronics/M24C08-FMN6TP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)
- 1 * TSM-120-01-F-DV Samtec 2*20 pins surface mounted .100 (Smiley model) [Mouser](https://www.mouser.ch/ProductDetail/Samtec/TSM-120-01-F-DV?qs=rU5fayqh%252BE2gtcIirjF3kA%3D%3D)
- [SuperSpeed MUX PI5USB30213A](https://www.diodes.com/part/view/PI5USB30213A/) may be an option intead of CBTL04083
- [Alternate USB 2.0 Mux/DeMux](https://www.diodes.com/part/view/PI3USB102G/) [Mouser](https://www.mouser.ch/ProductDetail/Diodes-Incorporated/PI3USB102GZLEX?qs=mt7EBqA2jzg7v2qs76v1VQ%3D%3D) [JLCPCB part](https://jlcpcb.com/parts/componentSearch?isSearch=true&searchTxt=DF40C-60DS-0.4V)
- 5 * TXB0108 voltage shifters 3.3V to 1.8V

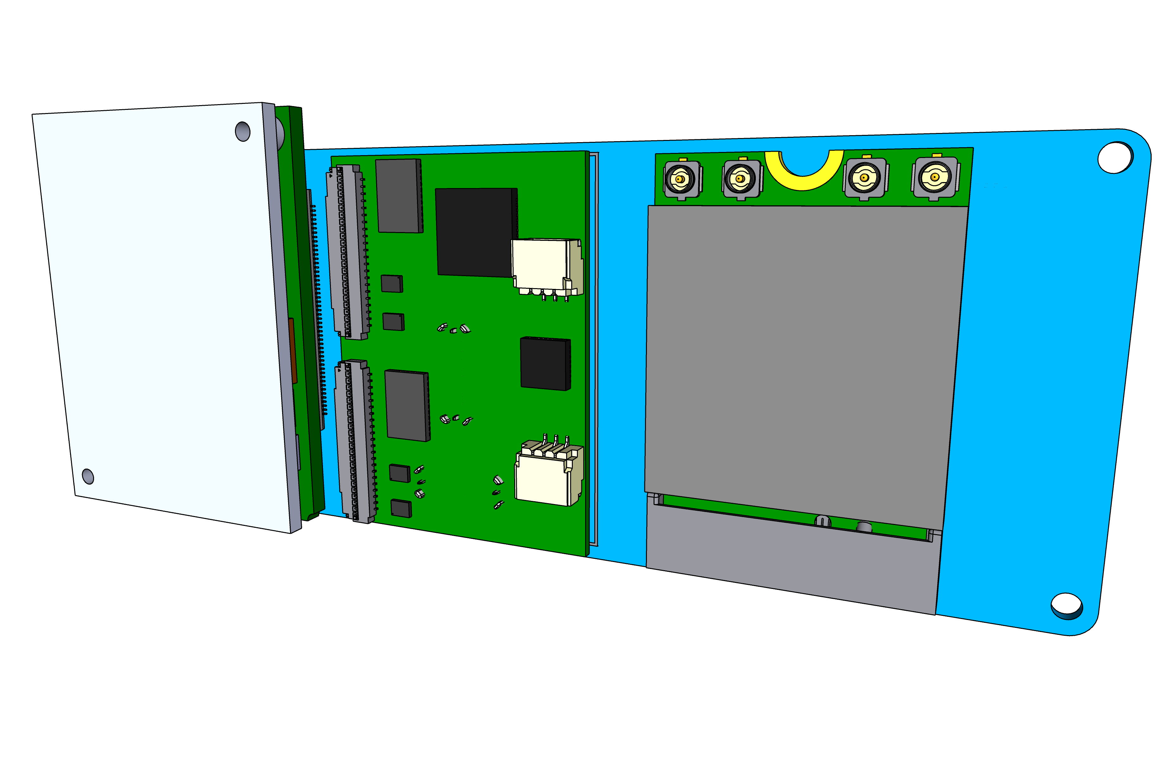
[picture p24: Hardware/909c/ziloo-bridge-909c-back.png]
Ziloo Bridge Board 909c back


The back of the board connects for SB-UCM-iMX8PLUS, T-USB module and M.2 Key B module.
The SB-UCM-iMX8PLUS is the center of the board and receives all signals.

# System Power Module

<mark>This is a new module</mark>

:[Power Module Connection](../refs/POWER_MODULE_CONNECT.md)
 
The module connectors have pins that are used for different setups. Not all should be connected to the 909 board.

# System SB-UCM-iMX8PLUS Module (SoM)

The daughter board clicks into the two Hirose 100 pin board-to-board connectors.

For further details see [Product Page](https://www.compulab.com/products/computer-on-modules/ucm-imx8m-plus-nxp-i-mx-8m-plus-som-system-on-module-computer/).

- The CSI1 & CSI2 are wired from the 100pin connectors to relevant CSI connectors.
- The CSI1 lanes are connected to Left CSI.
- The CSI2 lanes are connected to Right CSI.
- The USB1(OTG) data connects to 50 pin high speed connector.
- The USB2(Host) data connects to multiplexer between 50 pin high speed connector and m.2. Switched with MUX_HOST on EX0.
- 50 pin controlls takes in signals from SoM (LVDS, UART, I2C, INTs)
- The 45 pins Debug connector will break out many additional signal lines.
- The Debug connector can be placed near the 100 pin connectors if it helps the board layout.

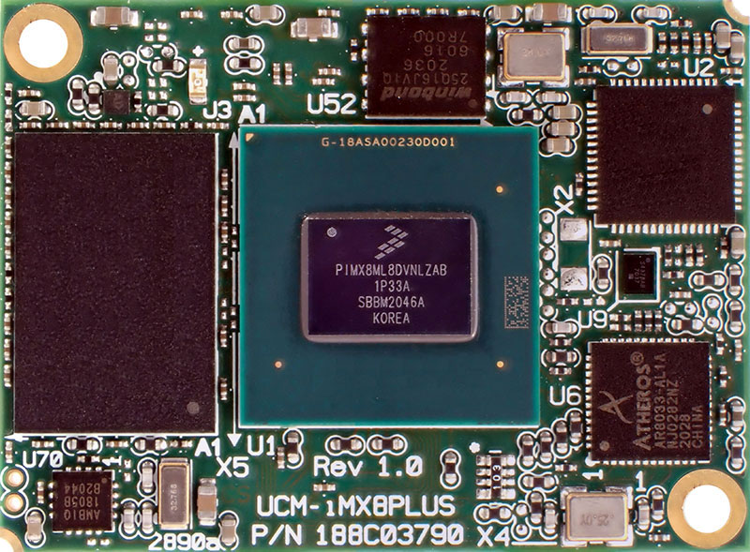
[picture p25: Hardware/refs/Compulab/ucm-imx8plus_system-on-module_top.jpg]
SB-UCM-iMX8PLUS


# MicroSD and MicroHDMI

The MicroHDMI connector is connected to the HTMI_TX*, HDMI_DDC_*, HDMI_CEC, HDMI_HPD pins from the i.MX8 module.

The MicroSD connector is connected to SD2_DATA*, SD2_CLK, SD2_CMD, SD2_nCD on the i.MX8 module.

HDMI connector with eARC

MicroSD connector

### Debugging Breakout connector

See end of this document for pinouts.

# T-USB Module Data Connection

:[T-USB Mounting instructions](../801-T-USB/T-USB-MOUNT.md)

### I2C EEPROM

Add an EEPROM like 24C08 present on the UCM carrier board.
<mark>Unlike reference design it should be connected to Stem I2C from 50 pin connector</mark>

## Wiring and Connecting

The board can be used in different ways

1) Adding a daughterboard, two OV2735 camera modules and connecting a USB cable with power.
2) Adding a daughterboard, two RPi camera modules and connecting a USB cable with power.
3) Use the board to connect two OV2735 camera modules to Compulab SB-UCM-iMX8PLUS
4) Use the board to connect two OV2735 camera modules to I-Pi SMARC IMX8M Plus

Required distances/location

- Camera module distance 70mm
- USB-C connectors cannot be moved
- Board size can only be increased to save cost
- Holes in the corners should be the regular sort for mounting.
- 

### I/O Expanders

<mark>The pins on I/O Expanders are rearranged</mark>

Three expanders are placed on the bridge board and a fourth is on the Power Module.

#### Expander 0

:[SYS I2C GPIO Expander 0](../pinouts/I2C_EXPANDER_0.md)
I/O Expander like Compulab Carrier Board to map Camera interrupts. (SYS I2C)

#### Expander 4

:[SYS I2C GPIO Expander 4](../pinouts/I2C_EXPANDER_4.md)
I/O Expander to cover m.2 Expander (Stem I2C).
Some sensor pins not connected.

#### Expander 6

:[SYS I2C GPIO Expander 6](../pinouts/I2C_EXPANDER_6.md)
I/O Expander to cover m.2 Expander (SYS I2C).
E_* pins are not connected.

### SYS I2C adresses

:[SYS I2C addresses](../pinouts/SYS_I2C_ADDRESSES.md)

### <mark>Signal Interrupt(INT) pins</mark>

Various chips have internal state changes that should cause interrupts by the SoM(CPU).
It is essential that inputs are flagged so communication can be reliable.

On the reference board these are triggered via USB1_TCPC_nINT(P1.60)
It is used for I/O Expander 0 and input IRQs.

Events that we want to catch

- T-USB OTG plug events
- T-USB Host plug events
- PD Controller state changed
- Camera sensors input ready
- I/O Expander input ready
- m.2 connectors
- PCIe

Interrupts from the PD Controller are input to I/O Expander 0 (or 3). It in turn
triggers an interrupt on EX0_nINT or EX_T_nINT.

Interrupts from the Left and right cameras interrupt signal(ATT_INT) is connected
to I/O Expander 0.
It in turn triggers an interrupt on EX0_nINT.

Direct/Indirect interrupt triggers

| Chip | Chip pin | Output to | Description |
|---|---|---|---|
| PDA9555 EX 0 | INT | EX0_nINT | Original Expander - P1.60 |
| PDA9555 EX 4 | INT | STEM_INT | 50 pin connector to T-USB module  |
| PDA9555 EX 6 | INT | EX0_nINT | m.2 Expander for SYS - P1.60  |
| PCIe m.2 Key B | WAKE# | PCIE_WAKE_B | m.2 Key B - P2.52 |
| PCIe m.2 Key B | CLKREQ# | PCIE_CLKREQ_B | m.2 Key B - P2.90 |
| Left Sensors | ATT_INT | EX0.10 | Left Camera Module sensors | 
| Right Sensors  | ATT_INT | EX4.14/EX0.14 | Right Camera Module sensors |

# 909c Connector Pinouts

## Debugging Breakout connector

:[Debugging Breakout connector](../pinouts/DEBUG_BREAKOUT_CONNECTOR_PINOUT.md)

## 50 pin B2B connectors

<mark>These connectors are new</mark>

:[DF40 50 pin connectors](../pinouts/T-USB_50_PINS_CONNECTORS.md)

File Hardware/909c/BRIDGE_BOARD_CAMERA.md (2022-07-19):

# Camera CSI Connectors

### CSI connectors

The CSI connectors data lanes are connected directly together for each side. It is only possible 
to connect a single left and a single right camera module at a time.

The 22 pin and 30 pin CSI connectors are intended to be used without a daughter board and instead a separate i.MX8 development board is used.
The CSI lanes on 34 pins connector is connected directly to the equivalent lines on the 30 pins.
This assumes that a camera is connected to either a 34 pins connector or a 22 pins connector, not both.
If a i.MX8 daughter board is used rather than development board the CSI lines from the daughter board must
be connected to the 34 pin camera module connectors.
i.MX8 CSI1 is used for left module, CSI2 is used for right module.

The two 34 pin CSI connectors are wired to run in sync via the STROBE pin.

If power isn't connected over the USB-C plugs, the camera modules should be powered over the MIPI CSI connectors.
In this case it should be possible to use either the 22 pin connectors or the 30 pin connectors for inputting
the signal and power. This means that the 22 pin connectors can be used to input or output MIPI CSI lanes.

Signals on the 34 pins connector are 1V8.
SCCB for CSI1 is connected to I2C5 voltage shifted.
SCCB for CSI2 is connected to I2C6 voltage shifted.

### Power supply Camera Module

Power can be supplied from VSOM stepped down to 3V3, 2V8 and 1V8.
2V8 is only needed for the camera modules.

The 909 board can be used to test camera modules without any other module attached by using the
22 pins and 30 pins connectors.
If a T-USB Power Module isn't connected, so VSOM isn't supplied, the power has to come from 
the 30 pins and 22 pins CSI connectors. 

# Camera Connectors

## RPI FPC 22 pins

On the left(CSI1) side.

:[22 pins RPi CSI connector](../pinouts/RPI_22_CONNECTOR.md)

## NVIDIA FPC 30 pins

On the right(CSI2) side.

:[30 pins I-PEX CSI connector](../pinouts/I-PEX_30_CONNECTOR.md)

## Ziloo Camera Module 34 pin connector

**Just to be clear**: All CSI lanes are laid out on one side of the connector with GND between.

:[Camera Module 201 connector](../pinouts/CAMERA_MODULE_CONNECTOR_PINOUT.md)

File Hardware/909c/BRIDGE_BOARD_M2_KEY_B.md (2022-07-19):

# M.2 Key B Expansion Module

Features:

- 1 Lane PCIe (PExx0)
- USB 3.0 data multiplexed (USB2/Host, PExx1)
- USB 2.0 data multiplexed (USB2/Host)
- GNSS / Stem I2C (I2C3)
- MFG I2C (SYS I2C)
- AUDIO I2S MIC SAI5 4 channels (GPIO5..8 and COEX*)
- SPI (ANTCTL*)
- DAS/DSS broken out with activity LED + expander bit
- Additional signals via 16 bit I/O Expander
- Some are broken out with pads near connector (CONFIG 0/2/3, DPR)
- SIM pins are not connected, reserved for now
- 4 channel I2S stereo input
- 4 channel I2S stereo output

The USB2 data from the Systems Module is connected through the multiplexer to T-USB on boot. The multiplexer 
can switch it to the M.2 expansion USB pins. This is important as the USB 3.0 data pairs are connected to
what can also be used for a second PCIe lane.
The USB data signals from SoM are multiplexed between T-USB Host (USB2) and M.2 Key B based on MUX_USB2_SEL & MUX_USB3_SEL.

Be aware the current pin plan is not final. Input/Ouput such as DIN/DOUT RXD/TXD may be the wrong way around.
It must be verified with reference hardware design/testing.

According to documentation: Type refers to the signal direction:
• Type O means signal is an output from the MPU/MCU to the adapter. 
• Type I means signals is an input to the MPU/MCU from the adapter.

### Control pins mapped by I/O Expander

Some extra M.2 pins are connected to I/O Expanders 4 and 6 to allow controlling the state of the inserted module.
Muxing the USB2 signals between m.2 Key B and the T-USB Module is controlled by I/O Expander 0.
Also, there will be no fastening screw for the m.2 board.

The system I/O expander controls mPCIe_PERST which resets PCIe.
PCIE_CLKREQ_B is a direct pin on the SoM.
PCIE_WAKE_B is a direct pin on the SoM. 

(?) Consider bootup default state of I/O Expanders. USB must not connect M.2 by default

(?) A future revision may connect unallocated/GPIO pins from chipsets to M.2 module

#### Expander 4

:[SYS I2C GPIO Expander 4](../pinouts/I2C_EXPANDER_4.md)
I/O Expander to cover m.2 Expander (Stem I2C).
Some sensor pins not connected.

#### Expander 6

:[SYS I2C GPIO Expander 6](../pinouts/I2C_EXPANDER_6.md)
I/O Expander to cover m.2 Expander (SYS I2C)

### Key B - pinouts

:[Key B Pinouts](../pinouts/M2_KEY_B_CONNECTOR.md)

## Key B - Reference Design

Congatec reference design SSD Key B
Congatec reference design

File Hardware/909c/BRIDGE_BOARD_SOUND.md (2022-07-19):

# Sound Connector

<mark>This connector is new, it replaces the 6 pin</mark>

The sound connector provides 4 lines input and 4 lines output. They connect
directly to the System Module, so they are not level shifted.
It is not yet defined if the signal level is 1.8V or 3.3V. It will depend on NVCC_SAI5
The pin layout wraps around aligning 1 and 20 close, but on opposite sides.

Two Connector components used are [DF40HC(3.5)-20DS-0.4V(51)](https://www.hirose.com/en/product/p/CL0684-4188-0-51). [Socket @ Mouser](https://www.mouser.ch/ProductDetail/Hirose-Connector/DF40HC35-20DS-04V51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)

:[Sound Connector](../pinouts/SOUND_CONNECTOR.md)

### I2S (SAI5) 4 channel microphone input mapping

One lane goes to the 34 pins camera connectors
The microphones on the 34 pins connector use SAI5_RX_DATA0.

The full 4 lanes are available on the sound connector and M.2 Key B.

#### Microphone I2S mapping (SAI5)

The microphone I2S mapping is done by using AL2 mode for the SAI3 pads to get SAI5 signals.
[Multiplexed Signal Pins](./ucm-imx8plus_multifunctional.pdf). 
This provides the 4 microphone lines on the Sound Connector.

| Misc pin | SoM pin | i.MX pad | Functionality | ALT | I2S |
|---|---|---|---|---|---|
| 11 | P1.26 |  SAI3_TXD |  SAI5_RX_DATA3 | ALT2 | |
| 17 | P1.28 |  SAI3_RXD |  SAI5_RX_DATA0 | ALT2 | DATA0 |
| 15 | P1.30 |  SAI3_MCLK |  SAI5_MCLK | ALT2 | |
| 19 | P1.32 |  SAI3_RXC |  SAI5_RXC | ALT2 | BCLK |
| 23 | P1.34 |  SAI3_RXFS |  SAI5_RX_SYNC | ALT2 | LRCLK |
| 13 | P1.36 |  SAI3_TXC |  SAI5_RX_DATA2 | ALT2 | |
| 21 | P1.38 |  SAI3_TXFS |  SAI5_RX_DATA1 | ALT2 | |

#### Speaker I2S mapping (SAI5)

ENET1 are mapped as SAI5 and brought out as speaker on 20 pins Sound connector.
[Multiplexed Signal Pins](./ucm-imx8plus_multifunctional.pdf).

| Misc pin | SoM pin | i.MX pad | Functionality | I2S |
|---|---|---|---|---|---|
| 15 | P1.30 |  SAI3_MCLK |  SAI5_MCLK | ALT2 | | 
| | P2.53 | ENET1_RX_CTL | SAI5_TXFS | ALT | LRCLK |
| | P2.55 | ENET1_RXC | SAI5_TXC / BCLK | ALT | BCLK |
| | P2.60 | ENET1_TD0 | SAI5_TXD0 | ALT | DATA 0 |
| | P2.63 | ENET1_TD2 | SAI5_TXD2 | ALT | |
| | P2.65 | ENET1_TD3 | SAI5_TXD3 | ALT | |
| | P2.76 | ENET1_nRST IO24 | SAI5_TXD1 | ALT | |

## Sound connector 20 pins

<mark>This connector is new</mark>

There are two connectors that provide the same signals.

:[Sound Connector](../pinouts/SOUND_CONNECTOR.md)

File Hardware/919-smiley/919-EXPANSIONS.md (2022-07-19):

# 919 Expansion slots (m.2)

On the way to the 701 board two m.2 connectors must be added to 919. A Key B and a Key E connector.

## Core Components

- M.2 key B connector H4.20mm [Amphenol ICC 10128793001RLF](https://www.amphenol-icc.com/pci-express-10128793001rlf.html)
- M.2 key E connector H4.20mm [Amphenol ICC 10128794001RLF](https://www.amphenol-icc.com/pci-express-10128794001rlf.html)
- 3 * PCA9555 I/O Expander
- 6 * [TS5USBC410 Dual 2:1 USB 2.0 Mux/DeMux Switch](../datasheets/USB/ts5usbc41.pdf). [Mouser](https://www.mouser.ch/ProductDetail/Texas-Instruments/TS5USBC410IYFFR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)

Alternative components

- 1 * USB2513B USB 2.0 hub controller
- 
- 

# Adding m.2

919 back side

This is how it looks with the modules mounted:

Back with daughter boards

## I/O Expander 6

Expander #6 combines control signals for the m.2 connectors. It is driven by SYS I2C. 

:[I/O Expander 6](../pinouts/I2C_EXPANDER_6.md)

# USB Data and m.2 Module Wiring

:[Wiring up USB and m.2](../refs/USB_M2_BOARD_WIRING.md)

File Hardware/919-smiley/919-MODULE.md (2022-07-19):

# 919 Smiley

Face board used to face the user and bridge daughterboards. It is used only for internal testing and development.
For production of faceboards a designation of 701 is used.

It contains a MEMSIC mCube MC6470 3D movement sensor with a gyroscope and accelerometer, which is managed by the Stem MCU on the T-USB board.
It communicates with the Stem MCU via the Stem I2C bus, and the SoM i.MX 8 via the SYS I2C. 
It exposes system control signals via the SYS I2C GPIO Expander 0 and 4.

Connectors are present to support attachment of two camera modules.

A LED matrix driver controls 120 LEDs producing expressions on the front of the board.
The LEDs are 1mm long and embedded in the board in order to create a diffused light.

919 back side

The board allows for experimental mounting of a an i.MX 8 Plus SoM.
The production version 701 will have the SoM daughtercard and other components without mounting debug/development connectors.

Components

- 1 * [MEMSIC mCube MC6470](https://mcubemems.com/product/mc6470-6-axis-ecompass/) - [Mouser](https://www.mouser.ch/ProductDetail/MEMSIC/MC6470?qs=u6%2FIMcj1sDuOjN54xX4NKQ%3D%3D)
- 1 * [IS31FL3730 8x8 matrix output](https://www.mouser.ch/ProductDetail/Lumissil/IS31FL3730-QFLS2-TR)
- 2 * [PCA9555 I/O Expander HVQFN24 package](https://www.nxp.com/part/PCA9555D)
- 1 * [TXB0108YZPR2 8-Bit Bidirectional Voltage-Level Shifter with Auto Direction Sensing and +/-15-kV ESD Protect 20-DSBGA -40 to 85](https://www.ti.com/store/ti/en/p/product/?p=TXB0108YZPR2) - [Mouser](https://www.mouser.ch/ProductDetail/Texas-Instruments/TXB0108YZPR2?qs=PqoDHHvF64977Sea9xf4wg%3D%3D)
- ? * [Kingbright APHHS1005SYCK 1mm x 0.5mm yellow](https://www.mouser.ch/ProductDetail/Kingbright/APHHS1005SYCK)
- [Würth 150040YS73220 1mm x 0.5mm yellow](https://www.mouser.ch/ProductDetail/Wurth-Elektronik/150040YS73220)

Connectors placed on the board are,

- 2 * [Hirose DF40C-34DS-0.4V](https://www.hirose.com/en/product/p/CL0684-4023-0-51) ([Mouser](https://www.mouser.ch/ProductDetail/Hirose-Connector/DF40C-34DS-04V51?qs=vcbW%252B4%252BSTIpg26DsEbj1iQ%3D%3D))
- 1 * [TE Connectivity 45PIN 0.3MM 571-4-2328724-5 FPC 3-2328724-5](https://www.te.com/usa-en/product-4-2328724-5.html) $0.41
- 1 * [Battery clip 2894TR](https://www.keyelco.com/product.cfm/product_id/14479/stepAccess/4610033) - [Mouser](https://www.mouser.ch/ProductDetail/Keystone-Electronics/2894?qs=u16ybLDytRb94n%2F3dXyVLQ%3D%3D) - [Alibaba](https://www.alibaba.com/product-detail/Custom-AAA-Lithium-Coin-Cell-Battery_62567779532.html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)
- 1 * Renata CR1220 cell battery - [Alibaba CR1220](https://www.alibaba.com/product-detail/Cr1220-Cr1220-3V-Lithium-Battery-CR1220_1600201663177.html)
- 3 * [Hirose DF40-20DS-0.4V](https://www.hirose.com/product/p/CL0684-4005-9-51) mated height 1.5mm [Mouser](https://www.mouser.ch/ProductDetail/Hirose-Connector/DF40HC35-20DS-04V51) - [JLCPCB socket](https://jlcpcb.com/parts/componentSearch)

Development connectors placed on board are,

- 2 * TSM-120-01-F-DV Samtec 2*20 pins surface mounted .100 (Smiley model) [Mouser](https://www.mouser.ch/ProductDetail/Samtec/TSM-120-01-F-DV?qs=rU5fayqh%252BE2gtcIirjF3kA%3D%3D)
- 2 * [Molex 22PIN 0.5mm pitch 54548-2271](https://www.molex.com/molex/products/part-detail/ffc_fpc_connectors/0545482271)
- 1 * MicroHDMI (suggested Molex 46765-1301) [Mouser](https://www.mouser.ch/ProductDetail/Molex/46765-1301?qs=sGAEpiMZZMt1iCLsaqcCFmQhPEZFSo0wUGorAW08d1I%3D) [Molex](https://www.molex.com/molex/products/part-detail/io_connectors/0467651301)

701 components are,

- [SB-UCM-iMX8PLUS](https://www.compulab.com/products/computer-on-modules/ucm-imx8m-plus-nxp-i-mx-8m-plus-som-system-on-module-computer/) System-on-Module
- 2 * [PCA9555 I/O Expander HVQFN24 package](https://www.nxp.com/part/PCA9555D)
- 2 * [Hirose DF40HC(3.0)-100DS-0.4V](https://www.hirose.com/en/product/p/CL0684-4151-0-51) mated height 3.0mm
- M.2 key B connector H4.20mm [Amphenol ICC 10128793001RLF](https://www.amphenol-icc.com/pci-express-10128793001rlf.html)
- M.2 key E connector H4.20mm [Amphenol ICC 10128794001RLF](https://www.amphenol-icc.com/pci-express-10128794001rlf.html)

Alt Components [not currently used]

- [LP5036 36 LED driver](https://www.ti.com/product/LP5036?keyMatch=LP5036) - [Mouser](https://www.mouser.ch/ProductDetail/Texas-Instruments/LP5036RJVR)
- Optional [BMM150 Magnotometer](https://www.bosch-sensortec.com/products/motion-sensors/magnetometers-bmm150/)
- [Bosch Sensortech BHI160B]() - [Mouser](https://www.mouser.ch/ProductDetail/Bosch-Sensortec/BHI160B?qs=qSfuJ%252Bfl%2Fd4gguUCihLWmA%3D%3D)
- [Würth 710-150040RS73220 1mm x 0.5mm red](https://www.mouser.ch/ProductDetail/710-150040RS73220)
- [Würth 710-150040VS73220 1mm x 0.5mm green](https://www.mouser.ch/ProductDetail/710-150040VS73220)
- [Würth 150040YS73240 1mm x 0.5mm yellow](https://www.mouser.ch/ProductDetail/Wurth-Elektronik/150040YS73240)
- [Bivar SM0402YC 1mm x 0.5mm yellow](https://www.mouser.ch/ProductDetail/Bivar/SM0402YC)
- [Lumex SML-LX0402SYC-TR 1mm x 0.5m yellow](https://www.mouser.ch/ProductDetail/Lumex/SML-LX0402SYC-TR)
- [ROHM SML-P12YTT86R 1mm x 0.6nn yellow](https://www.mouser.ch/ProductDetail/ROHM-Semiconductor/SML-P12YTT86R)
- [Alternate Cell Holder S8411-45R](https://www.harwin.com/products/S8411-45R/) - [Mouser](https://www.mouser.ch/ProductDetail/Harwin/S8411-45R?qs=Qom7kyPojXY6B0JhnWxDgQ%3D%3D)
-  1 * [EEMB / Hillflower LIR1220 Li-ion 3.6V battery rechargeable](https://eemb.com/model/LIR1220.html) - [Alibaba](https://www.alibaba.com/product-detail/3-6V-Lithium-Ion-Rechargeable-Button_545419255.html) [.. or](https://www.alibaba.com/product-detail/Lir1220-3-6V-LIR1220-LIR2016-LIR2025_1600318842115.html)
- 1 * [ML1220 3V rechargable battery](https://www.alibaba.com/product-detail/ML1220-3V-18mAh-lithium-aluminum-alloy_1600259520266.html)

Daughterboard for SD Card

- [Micro-SD for Nintendo Switch](https://www.alibaba.com/product-detail/Micro-Sd-Micro-SD-Tf-Card_1600413305365.html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) 

Plan is to source a daughterboard for SD Card building on existing.

Articles

- [Led PCB Circuit Board](https://www.raypcb.com/led-pcb-board/)
- [Uncovering PCB Embedded Components](https://resources.pcb.cadence.com/blog/2022-uncovering-pcb-embedded-components)
- [Practical steps for creating embedded components with side-emitting LEDs](https://resources.altium.com/p/practical-steps-for-creating-embedded-components-with-side-emitting-leds)
- [Efficient LED Blinking for Embedded Systems](https://www.electronicsforu.com/electronics-projects/efficient-led-blinking-for-embedded-systems)
- [Embedding of Passive Components into Flex PCB](https://www.pcbway.com/blog/PCB_Basic_Information/Embedding_of_Passive_Components_into_Flex_PCB.html)
- [LED module design considerations for an aluminium board](https://electronics.stackexchange.com/questions/153513/led-module-design-considerations-for-an-aluminium-board)
- [Led Bar array with stm32f103 microcontroller](https://www.engineersgarage.com/led-bar-with-stm32-microcontroller/)
- [APA102 2020 RGB LED source](http://addressable-led.com/Products/APA102-2020-LED.html)
- [Novel control strategy for synchronous PWM on a matrix converter](https://www.researchgate.net/publication/224077571_Novel_control_strategy_for_synchronous_PWM_on_a_matrix_converter)
- [Adafruit 16x9 Charlieplexed PWM LED Matrix Driver - IS31FL3731](https://www.adafruit.com/product/2946)
- https://community.bosch-sensortec.com/t5/MEMS-sensors-forum/BNO055-vs-BHI260AB-fusion-accuracy/td-p/24263

## Camera connectors

Two sets of camera connectors are on the board for left and right sides respectively.
The 22 pin connector allows a Development board to be connected with a Raspberry Pi Zero compatible flex cable.
The 34 pin connector allows attachment of a 201 Camera Module made for it.
Signals will be transferred directly between the two connectors using voltage shifters

The dual camera connectors are also connected to the SoM.
i.MX8 CSI1 is used for left module, CSI2 is used for right module.

The two 34 pin CSI connectors are wired to run in sync via the STROBE pin.

The power supplied to the 34 pins connector can be driven by the 22 pin connector or the T-USB Power Module.
VSOM from power module is down-regulated to 3V3, 2V8 and 1V8 from 3.7V - 5V. This downregulation can be shared between Left and Right cameras.

The 1.8V driving the Sensor I/O of the 201 modules will also be supplied via the Self powered direct battery input.

## Board Power

The board can be powered by 3V+ via a directly attached battery, or a pin on back GPIO header, which is down regulated. 
The self power input will power the Motion Engine and camera sensors with 1.8V. 
This can be used to run the board in an always on mode that records movement while disconnected from the power module.

When the Power module is connected it supplies VSOM, which powers the MotionEngine, LED Matrix driver and camera modules.
VSOM is down regulated from around 4V to 1V8, 2V8 and 3V3. When connected, no power is drawn from the battery on the bridge board.

Voltage pins are

* Self powered 2V+ input
* Always on 1V8 output VCC_RTC
* Powered 1V8 output
* Powered 2V8 output
* Powered 3V3 output
* Powered 5V output
* VSOM output

[?] Is it possible to support both 5V in and out on the GPIO header? 5V input would be downregulated to 4V if power module isn't connected.
5V output would be upregulated VSOM.

VSOM
Supplied by power module over multiple pins. When all pins are connected it is passed on to full-on mode components as VCC_FULL.

VCC_RTC
This powers always-on components on attached modules. It is sourced from any of the power module VCC_RTC (1V8), or VSOM pins and downregulated.

Power module provides either,
- No power
- VCC_RTC only
- Some VSOM pins
- Full VSOM (all pins) 

The power provided will force the system state to be
- Off
- Detached
- Suspended (fully powered)
- Running (fully powered)

The battery connector may be change to use LIR1220(3.6V) or ML1220(3V), which are rechargable.
Additional circuitry will be added in the future to charge the battery from VCC_FULL(VSOM).

### Electrical Characteristics

| Parameter |  Symbol |  Min | Typ | Max | Unit |
|---|---|---|---|---|---|
| Supply Voltage IMU Analog Domain  | IMU_VDD | 1.71 | 1.8 | 3.6 | V |
| Supply Voltage IMU I/O Domain | IMU_VDDIO | 1.71 | 1.8 | 1.89  | V | 
| MotionEngine running CPU/Sensing  | | 0.5 | 1 | 2.8 | mA |
| LED Matrix chip | LED_VCC | 2.7 | | 5.5 | V |
| LED Matrix chip | LED_IOUT  | | 40 | | mA |

## T-USB Power connectors

:[Power Module Connection](../refs/POWER_MODULE_CONNECT.md)

[?] Connector layout and pin orientation diagram.
[?] Full power logic

## LED layout

:[LED Layout](./LED_LAYOUT.md)

## Motion I2C Sensor

:[MC6470 Motion Sensor](./MC6470_MOTION.md)

## I/O Expander 0

Expander #0 combines control signals. It is driven by SYS I2C. It is present used with and without SoM / m.2 modules.

:[I/O Expander 0](../pinouts/I2C_EXPANDER_0.md)

This allows control of motion and camera module state

## Edge Sound Expansion connectors

One the edge there are three 20 pin connectors that allow connecting expansion modules
providing Sound/Sensor support.

1.8V signals are needed for suspended state. Should it be 3.3V for audio?

Most LEDs are mounted by embedding them into the board. The PCB being 1mm thick a recess is made to fit the LED of 0.4mm. In the center a 0.4mm hole is drilled to let through light. We must determine the best way to produce accurate holes for a good fit.
It is essential the LEDs are placed accurately to have an equal distance between them.

## 3D Model libraries

https://kicad.github.io/packages3d/

### Data to/from the Power Module

- STEM, SYS I2C
- USB data Host/OTG
- LVDS data
- UARTx_xXD

### Control/power signals from the Power Module

- VSOM
- BOTH_VSOM
- VSOM_LOCK
- VCC_RTC
- GND
- PWRBTN, ALT_BOOT, QSPI_BOOT_EN_3P3
- SYS_RST_PMIC, PMIC_ON_REQ, PMIC_STBY_REQ
- EX0_nINT

### I2C EEPROM

Add an EEPROM like 24C08 present on the UCM carrier board.

### Front facing GPIO header decoration

Exposed copper is routed around the GPIO header with certain objectives.

1) It aims to look brain like by being bulb shaped and avoiding straight lines.
2) The routing is gold plated and as exposed as possible considering risk of shorts
3) Ground routing is extended for decoration
4) Connection to back GPIO header where possible.

Decor front and back

Note that the two GPIO headers are oriented so pins 1 and 39 are aligned side by side on the two.
The specific layout is in the KiCAD project in [Decor](./decor/Decor/).

# 919 Connector Pinouts

## Front facing GPIO header

The GPIO header is made to be compatible with RPi expansion hardware. It has fewer GND pins which are mapped to GPIO or receiving pins.

:[40 pins GPIO Expansion](../pinouts/GPIO_HEADER.md)

## Back facing GPIO header

The back facing also loosely follows RPi GPIO layout.

:[40 pins GPIO Expansion](../pinouts/BACK_GPIO_HEADER.md)

The back facing also loosely follows RPi GPIO layout.

## 50 pin B2B connectors

:[DF40 50 pin connectors](../pinouts/T-USB_50_PINS_CONNECTORS.md)

## RPI FPC 22 pins

:[22 pins RPi CSI connector](../pinouts/RPI_22_CONNECTOR.md)

## Ziloo Camera Module 34 pin connector

**Just to be clear**: All CSI lanes are laid out on one side of the connector with GND between.

:[Camera Module 201 connector](../pinouts/CAMERA_MODULE_CONNECTOR_PINOUT.md)

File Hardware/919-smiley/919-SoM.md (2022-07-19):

# 919 SoM slot (m.2)

On the way to the 701 board the two 100 pin connectors for i.MX 8M Plus SoM are added to the board. 

## Core Components

- [SB-UCM-iMX8PLUS](https://www.compulab.com/products/computer-on-modules/ucm-imx8m-plus-nxp-i-mx-8m-plus-som-system-on-module-computer/) System-on-Module
- 2 * [Hirose DF40HC(3.0)-100DS-0.4V](https://www.hirose.com/en/product/p/CL0684-4151-0-51) mated height 3.0mm
- 1 * microSD card slot (suggested Molex 5031821852) push-push, compact. [Mouser](https://www.mouser.ch/ProductDetail/Molex/503182-1852?qs=s7UCm7gO1bZmpyAhCKZ26g%3D%3D), [Molex](https://www.molex.com/molex/products/part-detail/memory_card_socket/5031821852)

- 1 * USB2513B USB 2.0 hub controller
- 
- 
- 3 * PCA9555 I/O Expander (#0, #4, #5)
- 6 * [TS5USBC410 Dual 2:1 USB 2.0 Mux/DeMux Switch](../datasheets/USB/ts5usbc41.pdf). [Mouser](https://www.mouser.ch/ProductDetail/Texas-Instruments/TS5USBC410IYFFR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)

# Adding on SoM

After the SoM is on the board it is time to make a version with m.2 module connectors.

919 back side

This is how it looks with the modules mounted:

Back with daughter boards

## I/O Expander 4

Expander #4 combines sensor and m.2 control. It is driven by Stem I2C. 

:[I/O Expander 4](../pinouts/I2C_EXPANDER_4.md)

## Wiring

Use this table to ensure correct board wiring.

:[Wiring chips and connectors](./WIRING.md)

### MicroSD

The MicroSD connector is connected to SD2_DATA*, SD2_CLK, SD2_CMD, SD2_nCD on the i.MX8 module.

MicroSD connector

### Booting 

The board can boot from eMMC / SD or USB.
Boot / Reset buttons are optionally on the T-USB Module.

The board has a power LED driven by VSOM.

### MicroHDMI

The MicroHDMI connector is connected to the HTMI_TX*, HDMI_DDC_*, HDMI_CEC, HDMI_HPD pins from the i.MX8 module.

HDMI connector with eARC

### Connecting the SB-UCM-iMX8PLUS SoM

The daughter board clicks into the two Hirose 100pin board-to-board connectors.

For further details see [Product Page](https://www.compulab.com/products/computer-on-modules/ucm-imx8m-plus-nxp-i-mx-8m-plus-som-system-on-module-computer/).

The CSI1 & CSI2 are wired from the 100pin connectors to relevant CSI connectors.
The CSI1 lanes are connected to Left CSI.
The CSI2 lanes are connected to Right CSI.
The USB1 and USB2 data will be connected to multiplexers
The 45 pins Debug connector will break out many additional signal lines

- 2 * Hirose 100 pin connectors are used to connect the SoM daughter board

SB-UCM-iMX8PLUS

This allows control of IMU and camera module state.

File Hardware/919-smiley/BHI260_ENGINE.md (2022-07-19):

The BOSCH sensor includes an embedded processor communicating via I2C. It boots from a 1MB flash chip. It runs and communicates on is 1.8V.

https://www.mouser.ch/ProductDetail/Bosch-Sensortec/BHI260AP?qs=T94vaHKWudTEPTnGI%252BTy9w%3D%3D

BHI260AB I2C modes support 3.4 Mbit/s. Put on SYS or 3 ? HSCX + HSDX. i.MX 8 can only do 400KHz.

Power comes from any of the SOM lines via the two 50 pins connectors. Isolate them and down regulate to 3.3V.

Host I2C is I2C3 on the CPU side.
Master I2C 2 is I2C6 on the CPU side, Right CAM CSI2 SCCB & Ambient Light.
Master I2C 3 is I2C5 on the CPU side, Left CAM CSI1 SCCB & Laser Scan.
Master is is free for SPI communication.

Sensor linux driver source - https://github.com/BoschSensortec/BHY2-Sensor-API

:[BHI260 pins](./BHI260_PINS.md)

Address

HSDO is LSB selecting 0x28 or 0x29 = LOW by default (can be overridden)

### QSPI Flash

Soldering Pads are reserved on the board for a 1MByte flash chip connected vis QSPI to the Bosch SensorTech

* CLK
* CSN
* D0..D3

It supports,
* Quad SPI / QPI modes
* 0.5 - 8 MBytes supported

I assume the voltage is 1.8V. Winbond is apparently a tested example.

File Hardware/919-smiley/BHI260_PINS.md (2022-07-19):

? Event interrupts vs GPIO
? Timers
? Aux IMU I2C

| Pin | Pad | | to |  
|-----|---|---|---|
| 1 | M3SDA | Left CSI1 I2C SDA  | SOM I2C5  |
| 2 | M3SCL | Left CSI1 I2C SCL  | SOM I2C5  |
| 3 | HOSTBOOT | System Control | EX0.6 |
| 4 | QSPI_D0  | Flash | Flash chip |
| 5 | QSPI_CLK | Flash | Flash chip |
| 6 | VREG | Supply | 1.8V |
| 7 | VDDIO | Supply | 1.8V ? |
| 8 | QSPI_D3  | Flash | Flash chip |
| 9 | RESETN | System Control | EX0.5 |
| 10  | HIRQ | Host I2C IRQ | SOM I2C3 / EX0  |
| 11  | HSDX | Host I2C SDA | SOM I2C3  |
| 12  | VDDIO | Supply | |
| 13  | M2SCX | Right CSI2 I2C SCL | SOM I2C6  |
| 14  | QSPI_CSN | Flash | Flash chip |
| 15  | QSPI_D1  | Flash | Flash chip |
| 16  | MCSB3 | GPIO / Chip Select 3 | Breakout |
| 17  | GND | Supply | |
| 18  | MCSB2 | GPIO / Chip Select 2 | Breakout |
| 19  | MCSB4 | GPIO / Chip Select 4 | Breakout |
| 20  | QSPI_D2  | Flash | Flash chip |
| 21  | OCSB | IMU Auxiliary | BMM150 |
| 22  | ASCX | IMU Auxiliary | BMM150 |
| 23  | JTAG_CLK | Debug | Breakout  |
| 24  | JTAG_DIO | Debug | Breakout  |
| 29  | M1SCX | Master 1 I2C SCL  | Breakout |
| 30  | ASDX | IMU Auxiliary | BMM150 |
| 32  | HDSO | I2C Address selector | LOW |
| 33  | HSCX | Host I2C SCL | SOM I2C3  |
| 37  | M2SDI | GPIO | M2SDI |
| 38  | MCSB1 | GPIO / Chip Select 1 | Breakout |
| 39  | ASCX | IMU Auxiliary | BMM150 |
| 43  | M1SDI | GPIO SPI Master 1  | Breakout |
| 44  | M1SDX | Master 1 I2C SDA | Breakout |

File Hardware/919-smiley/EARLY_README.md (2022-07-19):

# 919 Smiley

Face board used to face the user and bridge daughterboards.

It contains a Bosch Sensortech 32 bit RISC processor that monitors 3D movement using a gyroscope and accelerometer.
It communicates with the Host MCU via the Stem I2C bus (I2C3 for the MCU daughterboard). 
It exposes system control signals via the SYS I2C GPIO Expander 0 to access IMU and camera module states.
Sensors on camera modules are available via Master 2 & 3.

A second chip is optional BMM150 to provide a magnetometer.

Alternate battery connection option for running detached.

Breakouts
- BATT in
- JTAG
- Master 1 SPI + 4 chip selects
- GPIOs : M2SDI

Components

- [Bosch Sensortech BHI260AP](https://www.bosch-sensortec.com/products/smart-sensors/bhi260ap/) - [Mouser](https://www.mouser.ch/ProductDetail/Bosch-Sensortec/BHI260AP)
- [NOR Flash 8M QSPI IS25WP080D-JNLE ISSI SOIC-8]() - [Mouser](https://www.mouser.ch/ProductDetail/ISSI/IS25WP080D-JNLE?qs=pif5%252B9MYt0UdCheWbE26RA%3D%3D)
- [LP5036 36 LED driver](https://www.ti.com/product/LP5036?keyMatch=LP5036) - [Mouser](https://www.mouser.ch/ProductDetail/Texas-Instruments/LP5036RJVR)
- [Würth 710-150040RS73220 1mm x 0.5mm red](https://www.mouser.ch/ProductDetail/710-150040RS73220)
- [Würth 710-150040VS73220 1mm x 0.5mm green](https://www.mouser.ch/ProductDetail/710-150040VS73220)
- [Würth 150040YS73220 1mm x 0.5mm yellow](https://www.mouser.ch/ProductDetail/Wurth-Elektronik/150040YS73220)
- [Würth 150040YS73240 1mm x 0.5mm yellow](https://www.mouser.ch/ProductDetail/Wurth-Elektronik/150040YS73240)
- [Kingbright APHHS1005SYCK 1mm x 0.5mm yellow](https://www.mouser.ch/ProductDetail/Kingbright/APHHS1005SYCK)
- [Bivar SM0402YC 1mm x 0.5mm yellow](https://www.mouser.ch/ProductDetail/Bivar/SM0402YC)
- [Lumex SML-LX0402SYC-TR 1mm x 0.5m yellow](https://www.mouser.ch/ProductDetail/Lumex/SML-LX0402SYC-TR)
- [ROHM SML-P12YTT86R 1mm x 0.6nn yellow](https://www.mouser.ch/ProductDetail/ROHM-Semiconductor/SML-P12YTT86R)

Alt Components

- [IS31FL3730 8x8 matrix output](https://www.mouser.ch/ProductDetail/Lumissil/IS31FL3730-QFLS2-TR)
- Optional [BMM150 Magnotometer](https://www.bosch-sensortec.com/products/motion-sensors/magnetometers-bmm150/)
- [Bosch Sensortech BHI160B]() - [Mouser](https://www.mouser.ch/ProductDetail/Bosch-Sensortec/BHI160B?qs=qSfuJ%252Bfl%2Fd4gguUCihLWmA%3D%3D)

Connectors placed on the board are,

- 2 * [Molex 22PIN 0.5mm pitch 54548-2271](https://www.molex.com/molex/products/part-detail/ffc_fpc_connectors/0545482271)
- 2 * [Hirose DF40C-34DS-0.4V](https://www.hirose.com/en/product/p/CL0684-4023-0-51) ([Mouser](https://www.mouser.ch/ProductDetail/Hirose-Connector/DF40C-34DS-04V51?qs=vcbW%252B4%252BSTIpg26DsEbj1iQ%3D%3D))
- 1 * [TE Connectivity 45PIN 0.3MM 571-4-2328724-5 FPC 3-2328724-5](https://www.te.com/usa-en/product-4-2328724-5.html) $0.41

Articles

- [Led PCB Circuit Board](https://www.raypcb.com/led-pcb-board/)
- [Uncovering PCB Embedded Components](https://resources.pcb.cadence.com/blog/2022-uncovering-pcb-embedded-components)
- [Practical steps for creating embedded components with side-emitting LEDs](https://resources.altium.com/p/practical-steps-for-creating-embedded-components-with-side-emitting-leds)
- [Efficient LED Blinking for Embedded Systems](https://www.electronicsforu.com/electronics-projects/efficient-led-blinking-for-embedded-systems)
- [Embedding of Passive Components into Flex PCB](https://www.pcbway.com/blog/PCB_Basic_Information/Embedding_of_Passive_Components_into_Flex_PCB.html)
- [LED module design considerations for an aluminium board](https://electronics.stackexchange.com/questions/153513/led-module-design-considerations-for-an-aluminium-board)
- [Led Bar array with stm32f103 microcontroller](https://www.engineersgarage.com/led-bar-with-stm32-microcontroller/)
- [APA102 2020 RGB LED source](http://addressable-led.com/Products/APA102-2020-LED.html)
- [Novel control strategy for synchronous PWM on a matrix converter](https://www.researchgate.net/publication/224077571_Novel_control_strategy_for_synchronous_PWM_on_a_matrix_converter)
- [Adafruit 16x9 Charlieplexed PWM LED Matrix Driver - IS31FL3731](https://www.adafruit.com/product/2946)

## Camera connectors

Two sets of camera connectors are on the board for left and right sides respectively.
The 22 pin connector allows a Development board to be connected with a Raspberry Pi Zero compatible flex cable.
The 34 pin connector allows attachment of a 201 Camera Module made for it.
Signals will be transferred directly between the two connectors using voltage shifters

## Power

Self powered
Always on
Power module connected

## LED layout

LEDs are laid out as eyebrows and a mouth. They are connected to the multiplexer as 7 sets of 9 LEDs (7x9 mode).
1) Brow x 2
1) Eye sides x 2 (reverse of brow signal)
3) Smile x 2
5) Sad x 2 (reverse of smile signal)
7) Cheeks, split 4 left 4 right.

Numbering of individual LEDs are from top-left to right.
The eyebrow sets are doubled up with the eye side using reverse polarity. The eye sides get signals from VIAs close to the eye hole.

The smile if formed by a left side and a right. LED numbering starts in the middle.
A sad smile uses the same multiplexer banks but with reverse polarity.

LEDs are marked with identifiers on the connector side, but not on the front side.

Vias around nose and hair

I2C3 breakout
Power breakout

Connecting LP5036 on I2C3

I2C3 on sound connector?

### LED mounting

Most LEDs are mounted by embedding them into the board. The PCB being 1mm thick a recess is made to fit the LED of 0.4mm. In the center a 0.4mm hole is drilled to let through light.

## MotionEngine I2C Sensor

The BOSCH sensor includes an embedded processor communicating via I2C. It boots from a 1MB flash chip. It runs and communicates on is 1.8V.

https://www.mouser.ch/ProductDetail/Bosch-Sensortec/BHI260AP?qs=T94vaHKWudTEPTnGI%252BTy9w%3D%3D

BHI260AB I2C modes support 3.4 Mbit/s. Put on SYS or 3 ? HSCX + HSDX. i.MX 8 can only do 400KHz.

Power comes from any of the SOM lines via the two 50 pins connectors. Isolate them and down regulate to 3.3V.

Host I2C is I2C3 on the CPU side.
Master I2C 2 is I2C6 on the CPU side, Right CAM CSI2 SCCB & Ambient Light.
Master I2C 3 is I2C5 on the CPU side, Left CAM CSI1 SCCB & Laser Scan.
Master is is free for SPI communication.

Sensor linux driver source - https://github.com/BoschSensortec/BHY2-Sensor-API

? Event interrupts vs GPIO
? Timers
? Aux IMU I2C

| Pin | Pad | | to |  
|-----|---|---|---|
| 1 | M3SDA | Left CSI1 I2C SDA  | SOM I2C5  |
| 2 | M3SCL | Left CSI1 I2C SCL  | SOM I2C5  |
| 3 | HOSTBOOT | System Control | EX0 |
| 4 | QSPI_D0  | Flash | Flash chip |
| 5 | QSPI_CLK | Flash | Flash chip |
| 6 | VREG | Supply | |
| 7 | VDDIO | Supply | |
| 8 | QSPI_D3  | Flash | Flash chip |
| 9 | RESETN | System Control | EX0. |
| 10  | HIRQ | Host I2C IRQ | SOM I2C3 / EX0  |
| 11  | HSDX | Host I2C SDA | SOM I2C3  |
| 12  | VDDIO | Supply | |
| 13  | M2SCX | Right CSI2 I2C SCL | SOM I2C6  |
| 14  | QSPI_CSN | Flash | Flash chip |
| 15  | QSPI_D1  | Flash | Flash chip |
| 16  | MCSB3 | GPIO / Chip Select 3 | Breakout |
| 17  | GND | Supply | |
| 18  | MCSB2 | GPIO / Chip Select 2 | Breakout |
| 19  | MCSB4 | GPIO / Chip Select 4 | Breakout |
| 20  | QSPI_D2  | Flash | Flash chip |
| 21  | OCSB | IMU Auxiliary | BMM150 |
| 22  | ASCX | IMU Auxiliary | BMM150 |
| 23  | JTAG_CLK | Debug | Breakout  |
| 24  | JTAG_DIO | Debug | Breakout  |
| 29  | M1SCX | Master 1 I2C SCL  | Breakout |
| 30  | ASDX | IMU Auxiliary | BMM150 |
| 33  | HSCX | Host I2C SCL | SOM I2C3  |
| 37  | M2SDI | GPIO | M2SDI |
| 38  | MCSB1 | GPIO / Chip Select 1 | Breakout |
| 39  | ASCX | IMU Auxiliary | BMM150 |
| 43  | M1SDI | GPIO SPI Master 1  | Breakout |
| 44  | M1SDX | Master 1 I2C SDA | Breakout |

Address

HSDO is LSB selecting 0x28 or 0x29

Need to add CM36686 proximity and ambient light sensor?

http://www.capellamicro.com.tw/EN/product_c.php?id=85&mode=16&search=

https://www.kynix.com/Detail/104230/CM36686M3OE.html

https://community.bosch-sensortec.com/t5/MEMS-sensors-forum/BNO055-vs-BHI260AB-fusion-accuracy/td-p/24263

### QSPI Flash
CLK
CSN
D0..D3

Quad SPI / QPI modes
0.5 - 8 MBytes supported

Voltage? Winbond?

## Other sensors

Accelerator / Gyro
FXAS21002

Ambient light

Down regulator 4V / V_SOM -> 3.3V

## 3D Model libraries

https://kicad.github.io/packages3d/

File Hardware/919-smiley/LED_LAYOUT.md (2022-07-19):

LEDs are laid out as eyebrows and a mouth. They are connected to the multiplexer as 7 sets of 9 LEDs (7x9 mode).

#### Orientation A rows:

0) Left Brow
1) Right Brow
2) Left side smile
3) Right side smile
4) Cheeks, split 4 left 4 right. (8)

#### Oritentation B (reverse) rows:

0) Left Eyes to the side
1) Right Eyes to the side
2) Left side sad mouth
3) Right side sad mouth
4) O mouth (6)

919 Smiley Layout

Numbering of individual LEDs are from top-left to right.
The eyebrow sets are doubled up with the eye side using reverse polarity. The eye sides get signals from VIAs close to the eye hole.

The smile if formed by a left side and a right. LED numbering starts in the middle.
A sad smile uses the same multiplexer banks but with reverse polarity.

LEDs are marked with identifiers on the connector side, but not on the front side.

Leds should be oriented perpendicular to the line they are arranged on. The orientation on the 3D model doesn't reflect what is intended.

### LED Matrix driver

The LEDs are controlled via a IS31FL3730 chip connected to the Stem via STEM I2C.

It can be driven by 2.7V - 5.5V
I/O can be up to Vcc+0.3V

LED matrix driver 7x9

### LED mounting

Most LEDs are mounted by embedding them into the board. The PCB being 1mm thick a recess is made to fit the LED of 0.4mm. In the center a 0.4mm hole is drilled to let through light. We must determine the best way to produce accurate holes for a good fit.
It is essential that the LEDs are placed accurately to have an equal distance between them.

While making the inital prototypes it will be very valuable to create boards that use a variation of LEDs such as yellow vs white.
Variations in the embedding would also be great to test such as how deeply they are recessed or the thickness of the PCB.
Pinhole or not is another variation to test.

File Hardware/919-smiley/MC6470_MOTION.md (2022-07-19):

The MC6470 combines a 9 DoF (9 Degrees of Freedom) accelerometer, magnetometer and rotational sensor solution in 2x2mm single package for the consumer electronics market.

The motion sensor is connected to Stem I2C on addresses 0x98/0x99(or 7 bit 0x4C).
It triggers STEM_INT when motion is detected

### Gyro device drivers

The MC6470 contains the optimized sensor fusion unit that can support the patented mCube iGyroTM engine.
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

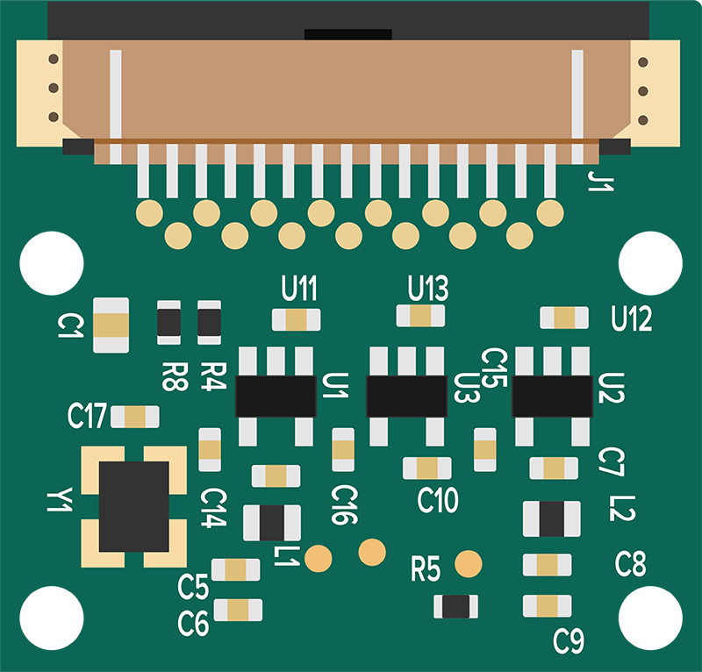
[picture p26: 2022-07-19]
Hardware/201/img/pi-cam-v1-board.webp

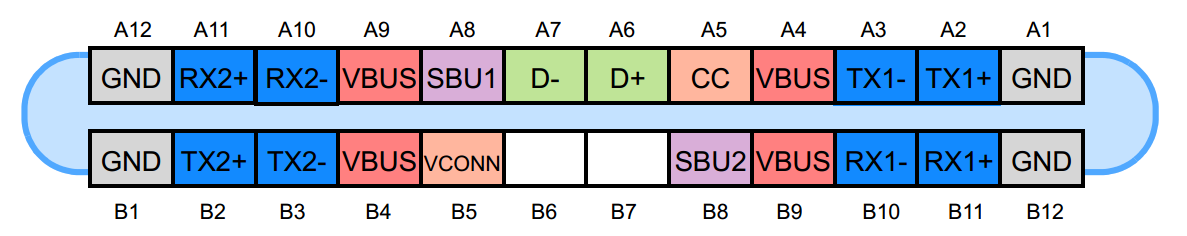
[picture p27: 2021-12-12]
Hardware/datasheets/USB/Fig2m11292018.png

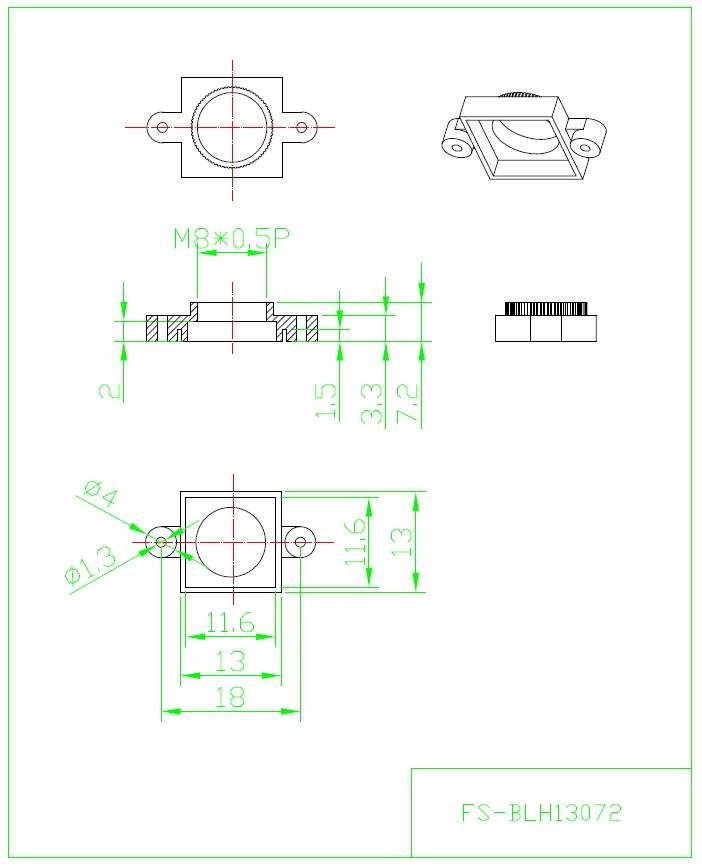
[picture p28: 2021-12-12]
Hardware/201/OV2735-module/holders/Focusafe FS-BLH13072.jpg

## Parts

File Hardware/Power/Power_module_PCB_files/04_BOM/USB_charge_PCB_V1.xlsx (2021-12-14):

# | DESCRIPTION | Value | Qty | Parts | CATEGORY | MANUFACTURER | MPN | PACKAGE | MOUNTING_TYPE
1 | IC BATT CHG LI-ION 1CELL 81WLP | MAX77860EWG+ | 1 | U1 | Battery charger | Maxim Integrated | MAX77860EWG+ | 81-WLP | SMD
2 | CAP CER 10UF 25V X5R 0603 | 10 uF | 2 | C7, C8 | Chip Capacitor | Murata Electronics | GRM188R61E106MA73J | 0603 | SMD
3 | CAP CER 2.2UF 25V X5R 0603 | 2.2 uF | 1 | C1 | Chip Capacitor | Yageo | CC0603KRX5R8BB225 | 0603 (1608 Metric) | SMD
4 | CAP CER 10UF 10V X5R 0603 | 10 uF | 3 | C10, C12, C15 | Chip Capacitor | Yageo | CC0603MRX5R6BB106 | 0603 | SMD
5 | CAP CER 0.1UF 10V X7R 0402 | 0.1 uF | 9 | C17, C18, C19, C20, C21, C22, C23, C24, C25 | Chip Capacitor | KEMET | C0402C104K8RACTU | 0402 | SMD
6 | CAP CER 0.1UF 25V X7R 0402 | 0.1uF | 1 | C9 | Chip Capacitor | KEMET | C0402C105M8PACTU | 0402 | SMD
7 | CAP CER 10000PF 10V X7R 0402 | 10nF | 1 | C16 | Chip Capacitor | KEMET | C0402C103K8RACAUTO | 0402 | SMD
8 | CAP CER 10UF 6.3V X5R 0402 | 10uF | 1 | C4 | Chip Capacitor | Murata Electronics | GRM155R60J106ME15D | 0402 | SMD
9 | CAP CER 1UF 10V X5R 0402 | 1uF | 6 | C2, C5, C6, C11, C13, C14 | Chip Capacitor | KEMET | C0402C105M8PACTU | 0402 | SMD
10 | CAP CER 2.2UF 16V X5R 0402 | 2.2uF | 1 | C3 | Chip Capacitor | Yageo | CC0402KRX5R7BB225 | 0402 | SMD
11 | RES SMD 2.2K OHM 5% 1/16W 0402 | 2.2k | 2 | R2, R3 | Chip Resisitor | Yageo | RC0402JR-072K2L | 0402 | SMD
12 | RES SMD 470 OHM 5% 1/10W 0603 | 470 | 1 | R4 | Chip Resisitor | Yageo | RC0603JR-07470RL | 0603 | SMD
13 | RES SMD 10K OHM 1% 1/16W 0402 | 10k | 4 | R6, R9, R10, R11 | Chip Resistor | Yageo | RC0402FR-0710KL | 0402 | SMD
14 | RES SMD 12K OHM 1% 1/16W 0402 | 12K | 1 | R8 | Chip resistor | Yageo | RC0402FR-0712KL | 0402 | SMD
15 | RES SMD 1K OHM 1% 1/16W 0402 | 1K | 1 | R7 | Chip Resistor | Yageo | RC0402FR-071KP | 0402 | SND
16 | RES SMD 200K OHM 1% 1/16W 0402 | 200K | 3 | R1, R5, R12 | Chip Resistor | Yageo | RC0402FR-07200KL | 0402 | SMD
17 | THERMISTOR NTC 10KOHM 3380K 0402 | 10k | 1 | RT1 | Chip thermistor | TDK Corporation | NTCG103JF103FT1 | 0402 | SMD
18 | VOLTAGE COMPARATOR | TLV7021DCKR | 1 | U4 | Comparator | Texas Instruments | TLV7021DCKR | SC-70-5 | SMD
19 | CONN FPC VERT 20POS 1.00MM SMD | 0526102072 | 1 | J2 | Connector | Molex | 0526102072 | 20x1mm | SMD
20 | CONN HEADER SMD R/A 3POS 1.5MM | 5-1775444-3 | 1 | J3 | Connector | TE Connectivity AMP Connectors | 5-1775444-3 | 1.5mm | SMD
21 | CONN RCP USB3.1 TYPEC 24P SMD RA | 12401610E4#2A | 1 | J1 | Connectors | Amphenol ICC (Commercial Products) | 12401610E4#2A | TYPE-C | Surface Mount, Right Angle
22 | DIODE SCHOTTKY 40V 3A PMDU | RBR3MM40ATR | 1 | D18 | Diode schottky | Rohm Semiconductor | RBR3MM40ATR | SOD-123F | SMD
23 | FIXED IND 1UH 4.1A 30MOHM SMD | 1uH | 1 | L1 | Inductor | Samsung Electro-Mechanics | CIGT252010EH1R0MNE | 1008 | SMD
24 | IC MUX 2:1 8 OHM 20VQFN | HD3SS3212RKSR | 1 | U7 | Integrated Circuits (ICs) | Texas Instruments | HD3SS3212RKSR | 20-VFQFN Exposed Pad | SMD
25 | IC USB SWITCH DUAL 1X2 10UQFN | TS3USB221RSERG4 | 2 | U8, U9 | Integrated Circuits (ICs) | Texas Instruments | TS3USB221RSERG4 | 10-UFQFN | SMD
26 | LED RED CLEAR 0603 SMD | 150060RS75000 | 1 | D1 | LED | WГјrth Elektronik | 150060RS75000 | 0603 | SMD
27 | SWITCH TACTILE SPST-NO 0.05A 12V | RS-282G05A3-SM RT | 1 | B1 | Tactile Switches | C&K | RS-282G05A3-SM RT | 6.00mm x 3.60mm | SMD
28 | TVS DIODE 6V 15V 6UDFN | SP3003-02UTG | 8 | U14, U15, U16, U17, U18, U21, U22, U23 | TVS - Diodes | Littelfuse Inc. | SP3003-02UTG | 6-UFDFN | SMD
29 | TVS DIODE ARRAY | SP3401-02UTG | 8 | U5, U6, U10, U11, U12, U13, U19, U20 | TVS - Diodes | Littelfuse Inc. | SP3401-02UTG | 6-UFDFN | SMD
30 | IC MUX/DEMUX 4CH TYPE C2 30WQFN | HD3SS460IRHRT | 1 | U3 | USB Switch | Texas Instruments | HD3SS460IRHRT | 30-WFQFN | SMD
31 | IC REG LINEAR 3.3V 120MA 8TDFN | MAX8510ETA33+T | 1 | U2 | Voltage regulator | Maxim Integrated | MAX8510ETA33+T | 8-WFDFN | SMD

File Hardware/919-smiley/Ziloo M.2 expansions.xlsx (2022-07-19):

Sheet: Export Summary
This document was exported from Numbers. Each table was converted to an Excel worksheet. All other objects on each Numbers sheet were placed on separate worksheets. Please be aware that formula calculations may differ in Excel.
Numbers Sheet Name | Numbers Table Name | Excel Worksheet Name
Sheet 1
 | SoM P1 | Sheet 1 - SoM P1
 | SoM P2 | Sheet 1 - SoM P2
 | M.2 Key B - Connecting SSD / SATA / Other | Sheet 1 - M.2 Key B - Connectin
 | M.2 Key E - Connecting Wireless module / GSM / LTE / LoRa / BT | Sheet 1 - M.2 Key E - Connectin
 | 919 Smiley | Sheet 1 - 919 Smiley

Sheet: Sheet 1 - SoM P1
SoM P1
 | Even | Odd | GPIO | Mapped to | AKA | Misc | USB OTG / Mux | USB Host / Mux | OTG Breakout | Host Breakout | Debug Breakout | CSI / SCCB Left | CSI / SCCB Right | I2S Speaker | I2S Mic | microHDMI | 40 pin GPIO | M.2 Key B | M.2 Key E
P1.1 |  | USB2_VBUS |  |  |  |  |  | USB2_VBUS
P1.2 | SYS_RST_PMIC |  |  |  |  | P10.9 |  |  |  |  | RESET (combined)
P1.3 |  | USB2_DP |  |  |  |  |  | USB2_DP
P1.4 | GND
P1.5 |  | USB2_DN |  |  |  |  |  | USB2_DN
P1.6 | USB1_RX_P |  |  |  |  |  | USB1_RX_P
P1.7 |  | USB2_RX_P |  |  |  |  |  | USB2_RX_P
P1.8 | USB1_RX_N |  |  |  |  |  | USB1_RX_N
P1.9 |  | USB2_RX_N |  |  |  |  |  | USB2_RX_N
P1.10 | GND |  |  |  |  |  |  |  |  |  |  |  |  |  |  |  | GND
P1.11 |  | VSOM |  |  |  |  |  |  |  |  |  |  |  |  |  |  | VSOM
P1.12 | USB1_DP |  |  |  |  |  | USB1_DP
P1.13 |  | USB2_TX_P |  |  |  |  |  | USB2_TX_P
P1.14 | USB1_DN |  |  |  |  |  | USB1_DN
P1.15 |  | USB2_TX_N |  |  |  |  |  | USB2_TX_N
P1.16 | USB1_TX_P |  |  |  |  |  | USB1_TX_P
P1.17 |  | RESERVED2
P1.18 | USB1_TX_N |  |  |  |  |  | USB1_TX_N
P1.19 |  | UART1_RXD | GPIO5_IO22 | UART1_RXD |  | P20.11 | UART1_RXD |  |  |  |  |  |  |  |  |  | UART1_RXD |  | UART1_RXD
P1.20 | GND
P1.21 |  | UART3_RXD | GPIO5_IO26 | UART3_RXD |  | P20.4 |  | UART3_RXD |  |  |  |  |  |  |  |  | UART3_RXD
P1.22 | RESERVED
P1.23 |  | HDMI_TXCP |  |  |  |  |  |  |  |  |  |  |  |  |  | HDMI_TXCP
P1.24 | USB1_VBUS
P1.25 |  | HDMI_TXCN |  |  |  |  |  |  |  |  |  |  |  |  |  | HDMI_TXCN
P1.26 | SAI3_TXD |  |  | SAI5_RXD3 |  |  |  |  |  |  | MIC_SDATA3 |  |  |  | SAI5_RXD3 |  |  | MIC_SDATA3
P1.27 |  | VSOM
P1.28 | SAI3_RXD |  |  | SAI5_RXD0 |  | P21.17 |  |  |  |  | MIC_SDATA0 |  |  |  | SAI5_RXD0 |  |  | MIC_SDATA0
P1.29 |  | HDMI_TX0P |  |  |  |  |  |  |  |  |  |  |  |  |  | HDMI_TX0P
P1.30 | SAI3_MCLK |  |  | SAI5_MCLK |  | P21.15 |  |  |  |  |  |  |  |  | SAI5_MCLK |  |  | MIC MCLK
P1.31 |  | HDMI_TX0N |  |  |  |  |  |  |  |  |  |  |  |  |  | HDMI_TX0N
P1.32 | SAI3_RXC |  |  | SAI5_RXC |  | P21.19 |  |  |  |  | MIC CLK? |  |  |  | SAI5_RXC |  |  | MIC CLK?
P1.33 |  | CAN2_TX | GPIO4_IO26 |  |  | P21.8 |  |  |  |  |  |  |  |  |  |  | CAN2_TX |  | SAI2_TXD0
P1.34 | SAI3_RXFS |  |  | SAI5_RXFS |  | P21.23 |  |  |  |  | MIC LRCLK? |  |  |  | SAI5_RXFX |  |  | MIC LRCLK?
P1.35 |  | EARC_N_HPD |  |  |  |  |  |  |  |  |  |  |  |  |  | EARC_N_HPD
P1.36 | SAI3_TXC |  |  | SAI5_RXD2 |  | P21.13 |  |  |  |  | MIC_SDATA2 |  |  |  | SAI5_RXD2 |  |  | MIC_SDATA2
P1.37 |  | EARC_P_UTIL |  |  |  |  |  |  |  |  |  |  |  |  |  | EARC_P_UTIL
P1.38 | SAI3_TXFS |  |  | SAI5_RXD1 |  | P21.21 |  |  |  |  | MIC_SDATA1 |  |  |  | SAI5_RXD1 |  |  | MIC_SDATA1
P1.39 |  | HDMI_TX1P |  |  |  |  |  |  |  |  |  |  |  |  |  | HDMI_TX1P
P1.40 | GND
P1.41 |  | HDMI_TX1N |  |  |  |  |  |  |  |  |  |  |  |  |  | HDMI_TX1N
P1.42 | LVDS0_D0_P |  |  |  |  |  |  | LVDS0_D0_P
P1.43 |  | VSOM
P1.44 | LVDS0_D0_N |  |  |  |  |  |  | LVDS0_D0_N
P1.45 |  | HDMI_TX2P |  |  |  |  |  |  |  |  |  |  |  |  |  | HDMI_TX2P
P1.46 | LVDS0_D1_P |  |  |  |  |  |  | LVDS0_D1_P
P1.47 |  | HDMI_TX2N |  |  |  |  |  |  |  |  |  |  |  |  |  | HDMI_TX2N
P1.48 | LVDS0_D1_N |  |  |  |  |  |  | LVDS0_D1_N
P1.49 |  | CAN2_RX | GPIO4_IO27 |  |  | P21.10 |  |  |  |  |  |  |  |  |  |  | CAN2_RX |  | SAI2_MCLK
P1.50 | LVDS0_D2_P |  |  |  |  |  |  | LVDS0_D2_P
P1.51 |  | CAN1_RX | GPIO4_IO25 |  |  | P21.12 |  |  |  |  |  |  |  |  |  |  | CAN1_RX |  | SAI2_TXC
P1.52 | LVDS0_D2_N |  |  |  |  |  |  | LVDS0_D2_N
P1.53 |  | CAN1_TX | GPIO4_IO22 |  |  | P21.14 |  |  |  |  |  |  |  |  |  |  | CAN1_TX
P1.54 | GND
P1.55 |  | PHY_2V5 |  |  |  | P10.4
P1.56 | LVDS0_D3_P |  |  |  |  |  |  | LVDS0_D3_P
P1.57 |  | VSOM
P1.58 | LVDS0_D3_N |  |  |  |  |  |  | LVDS0_D3_N
P1.59 |  | GPIO1_IO0 | GPIO1_IO0 |  | EX_OH_nINT | P20.12 |  |  |  |  |  |  |  |  |  |  | EX_H_nINT
P1.60 | GPIO4_IO19 |  | GPIO4_IO19 | GPIO4_IO19 | EX0_nINT (USB1_TCPC_nINT) | P21.30 | MUX INT_N |  |  |  |  |  |  |  |  |  | EX0_nINT
P1.61 |  | UART3_TXD | GPIO5_IO27 | UART3_TXD |  |  |  | UART3_TXD |  |  |  |  |  |  |  |  | UART3_TXD
P1.62 | AVDD33_ETH
P1.63 |  | HDMI_DDC_SDA | GPIO3_IO27 | HDMI_DDC_SDA |  |  |  |  |  |  |  |  |  |  |  | HDMI_DDC_SDA
P1.64 | GND
P1.65 |  | JTAG_TMS |  |  |  |  |  |  |  |  | JTAG_TMS
P1.66 | PMIC_STBY_REQ |  |  |  |  | P10.3
P1.67 |  | JTAG_TDO |  |  |  |  |  |  |  |  | JTAG_TDO
P1.68 | PMIC_ON_REQ |  |  |  |  | P10.5
P1.69 |  | VSOM
P1.70 | HDMI_DDC_SCL |  |  | HDMI_DDC_SCL |  |  |  |  |  |  |  |  |  |  |  | HDMI_DDC_SCL
P1.71 |  | JTAG_TDI |  |  |  |  |  |  |  |  | JTAG_TDI
P1.72 | UART1_TXD |  | GPIO5_IO23 |  |  | P20.9 | UART1_TXD |  |  |  |  |  |  |  |  |  | UART1_TXD |  | UART1_TXD
P1.73 |  | JTAG_TCK |  |  |  |  |  |  |  |  | JTAG_TCK
P1.74 | UART2_TXD |  | GPIO5_IO25 |  |  | P20.1 |  |  |  |  | UART2_TXD |  |  |  |  |  | UART2_TXD |  | UART2_TXD
P1.75 |  | JTAG_MOD |  |  |  |  |  |  |  |  | JTAG_MOD
P1.76 | UART2_RXD |  | GPIO5_IO24 |  |  | P20.2 |  |  |  |  | UART2_RXD |  |  |  |  |  | UART2_RXD |  | UART2_RXD
P1.77 |  | PWM1_OUT | GPIO5_IO5 | PWM1_OUT |  | P20.5 |  |  |  |  |  |  |  |  |  |  | PWM1_OUT | PWM1_OUT
P1.78 | GND
P1.79 |  | SPDIF_RX | GPIO5_IO4 | PWM2_OUT |  |  |  |  |  |  |  |  |  |  |  |  | PWM2_OUT | PWM2_OUT
P1.80 | LVDS0_CLK_P |  |  |  |  |  |  | LVDS0_CLK_P
P1.81 |  | SPDIF_TX | GPIO5_IO3 | PWM3_OUT |  |  |  |  |  |  |  |  |  |  |  |  | PWM3_OUT | PWM3_OUT
P1.82 | LVDS0_CLK_N |  |  |  |  |  |  | LVDS0_CLK_N
P1.83 |  | VSOM
P1.84 | UART4_RXD |  |  |  | UART2_CTS | P20.10 |  |  |  |  | UART4_RXD |  |  |  |  |  |  |  | UART4_RXD
P1.85 |  | HDMI_CEC |  |  |  |  |  |  |  |  |  |  |  |  |  | HDMI_CEC
P1.86 | UART4_TXD |  |  |  | UART2_RTS | P20.8 |  |  |  |  | UART4_TXD |  |  |  |  |  |  |  | UART4_TXD
P1.87 |  | I2C6_SCL |  |  |  | P21.2 |  | I2C6_SCL
P1.88 | GND
P1.89 |  | I2C6_SDA |  |  |  | P21.4 |  | I2C6_SDA
P1.90 | ALT_BOOT |  |  |  |  |  |  |  |  |  | ALT_BOOT
P1.91 |  | I2C3_SDA | GPIO5_IO19 | I2C3_SDA |  |  |  |  |  |  |  |  |  |  |  |  | I2C3_SDA |  | I2C3_SDA
P1.92 | HDMI_HPD
P1.93 |  | VCC_RTC |  |  |  |  |  |  |  |  |  |  |  |  |  |  | VCC_RTC
P1.94 | I2C3_SCL |  | GPIO5_IO18 | I2C3_SCL |  |  |  |  |  |  | I2C3_SCL |  |  |  |  |  | I2C3_SCL |  | I2C3_SCL
P1.95 |  | QSPI_BOOT_EN_3P3 |  |  |  | P21.18 |  |  |  |  | QSPI_BOOT_EN_3P3
P1.96 | I2C5_SDA |  |  |  |  | P21.1 |  |  |  |  | I2C5_SDA | I2C5_SDA
P1.97 |  | SYS_I2C_SDA |  |  |  | P21.5 | SYS_I2C_SDA | SYS_I2C_SDA |  |  | SYS_I2C_SDA |  |  |  |  |  | SYS_I2C_SDA
P1.98 | GPIO1_01 |  | GPIO1_01 | GPIO1_01 | EX_T_nINT | P20.14 |  |  |  |  |  |  |  |  |  |  | EX_O_nINT
P1.99 |  | SYS_I2C_SCL |  |  |  | P21.7 | SYS_I2C_SCL | SYS_I2C_SCL |  |  | SYS_I2C_SCL |  |  |  |  |  | SYS_I2C_SCL
P1.100 | I2C5_SCL |  |  |  |  | P21.3 |  |  |  |  |  | I2C5_SCL

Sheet: Sheet 1 - SoM P2
SoM P2
 | Even | Odd | GPIO | Mapped to | AKA | UCM Misc | USB OTG / Mux | USB Host / Mux | OTG Breakout | Host Breakout | Debug Breakout | CSI / SCCB Left | CSI / SCCB Right | I2S Speaker | I2S Mic | microHDMI | 40 pin GPIO | M.2 Key B | M.2 Key E | microSD
P2.1 |  | MIPI_DSI
P2.2 | MIPI_CSI1_CLK_N |  |  |  |  |  |  |  |  |  |  | MIPI_CSI1_CLK_N
P2.3 |  | MIPI_DSI
P2.4 | MIPI_CSI1_CLK_P |  |  |  |  |  |  |  |  |  |  | MIPI_CSI1_CLK_P
P2.5 |  | MIPI_DSI
P2.6 | MIPI_CSI1_D0_N |  |  |  |  |  |  |  |  |  |  | MIPI_CSI1_D0_N
P2.7 |  | MIPI_DSI
P2.8 | MIPI_CSI1_D0_P |  |  |  |  |  |  |  |  |  |  | MIPI_CSI1_D0_P
P2.9 |  | V_SOM
P2.10 | GND
P2.11 |  | MIPI_DSI
P2.12 | MIPI_CSI2_CLK_N
P2.13 |  | MIPI_DSI |  |  |  |  |  |  |  |  |  |  | MIPI_CSI2_CLK_N
P2.14 | MIPI_CSI2_CLK_P
P2.15 |  | MIPI_DSI |  |  |  |  |  |  |  |  |  |  | MIPI_CSI2_CLK_P
P2.16 | GND
P2.17 |  | MIPI_DSI
P2.18 | MIPI_CSI2_D0_N
P2.19 |  | V_SOM |  |  |  |  |  |  |  |  |  |  | MIPI_CSI2_D0_N
P2.20 | MIPI_CSI2_D0_P
P2.21 |  | MIPI_DSI |  |  |  |  |  |  |  |  |  |  | MIPI_CSI2_D0_P
P2.22 | GND
P2.23 |  | MIPI_DSI
P2.24 | MIPI_CSI2_D1_N
P2.25 |  | MIPI_DSI |  |  |  |  |  |  |  |  |  |  | MIPI_CSI2_D1_N
P2.26 | MIPI_CSI2_D1_P
P2.27 |  | MIPI_DSI |  |  |  |  |  |  |  |  |  |  | MIPI_CSI2_D1_P
P2.28 | GND
P2.29 |  | V_SOM
P2.30 | PCIE_RXN_N |  |  |  |  |  |  |  |  |  |  |  |  |  |  |  |  | PCIE_RXN_N
P2.31 |  | MIPI_CSI1_D1_N |  |  |  |  |  |  |  |  |  | MIPI_CSI1_D1_N
P2.32 | PCIE_RXN_P |  |  |  |  |  |  |  |  |  |  |  |  |  |  |  |  | PCIE_RXN_P
P2.33 |  | MIPI_CSI1_D1_P |  |  |  |  |  |  |  |  |  | MIPI_CSI1_D1_P
P2.34 | GND
P2.35 |  | MIPI_CSI1_D3_N |  |  |  |  |  |  |  |  |  | MIPI_CSI1_D3_N
P2.36 | PCIE_TXN_N |  |  |  |  |  |  |  |  |  |  |  |  |  |  |  |  | PCIE_TXN_N
P2.37 |  | MIPI_CSI1_D3_P |  |  |  |  |  |  |  |  |  | MIPI_CSI1_D3_P
P2.38 | PCIE_TXN_P |  |  |  |  |  |  |  |  |  |  |  |  |  |  |  |  | PCIE_TXN_P
P2.39 |  | V_SOM
P2.40 | GND
P2.41 |  | ~~ENET1_RD0~~ | GPIO2_IO4 | SD1_DATA2 |  |  |  |  |  |  |  |  |  |  |  |  |  |  | SD1_DATA2
P2.42 | PCIE_REF_CLKP |  |  |  |  |  |  |  |  |  |  |  |  |  |  |  |  | PCIE_REF_CLKP
P2.43 |  | ~~ENET1_RD1~~ | GPIO2_IO5 | SD1_DATA3 |  |  |  |  |  |  |  |  |  |  |  |  |  |  | SD1_DATA3
P2.44 | PCIE_REF_CLKN |  |  |  |  |  |  |  |  |  |  |  |  |  |  |  |  | PCIE_REF_CLKN
P2.45 |  | ~~ENET1_RD2~~ | GPIO2_IO8 | GPIO2_IO8 |  |  |  |  |  |  |  |  |  |  |  |  | GPIO2_IO8
P2.46 | GND
P2.47 |  | ~~ENET1_RD3~~ | GPIO2_IO9 | GPIO2_IO9 |  |  |  |  |  |  |  |  |  |  |  |  | GPIO2_IO9
P2.48 | MIPI_CSI2_D2_N |  |  |  |  |  |  |  |  |  |  |  | MIPI_CSI2_D2_N
P2.49 |  | GPIO2_IO20 | GPIO2_IO20 |  |  |  |  |  |  |  |  |  |  |  |  |  | GPIO2_IO20
P2.50 | MIPI_CSI2_D2_P |  |  |  |  |  |  |  |  |  |  |  | MIPI_CSI2_D2_P
P2.51 |  | SD2_nRST | GPIO2_IO19 |  |  |  |  |  |  |  |  |  |  |  |  |  | GPIO2_IO19
P2.52 | PCIE_WAKE_B |  | PCIE_WAKE_B | GPIO4_IO20 | PCIE_WAKE_B | P21.32 |  |  |  |  |  |  |  |  |  |  |  | PCIE_WAKE_B
P2.53 |  | ~~ENET1_RX_CTL~~ | GPIO4_IO10 | SAI5_TXFS |  | P20.19 |  |  |  |  |  |  |  | SAI5_TXFS
P2.54 | GND
P2.55 |  | ~~ENET1_RXC~~ | GPIO4_IO11 | SAI5_TXC |  | P20.29 |  |  |  |  |  |  |  | SAI5_TXC
P2.56 | MIPI_CSI2_D3_N |  |  |  |  |  |  |  |  |  |  |  | MIPI_CSI2_D3_N
P2.57 |  | V_SOM
P2.58 | MIPI_CSI2_D3_P |  |  |  |  |  |  |  |  |  |  |  | MIPI_CSI2_D3_P
P2.59 |  | ~~ENET1_TD0~~ | GPIO2_IO3 | SD1_DATA1 |  | P20.22 |  |  |  |  |  |  |  |  |  |  |  |  | SD1_DATA1
P2.60 | SAI5_TXD0 |  | GPIO4_IO12 | SAI5_TXD0 |  | P21.34 |  |  |  |  |  |  |  | SAI5_TXD0
P2.61 |  | ~~ENET1_TD1~~ | GPIO2_IO2 | SD1_DATA0 |  | P20.24 |  |  |  |  |  |  |  |  |  |  |  |  | SD1_DATA0
P2.62 | SD1_RESET_B |  | GPIO2_IO10 |  |  | P20.13 |  |  |  |  |  |  |  |  |  |  |  |  | SD1_RESET_B
P2.63 |  | ~~ENET1_TD2~~ | GPIO4_IO14 | SAI5_TXD2 |  | P20.26 |  |  |  |  |  |  |  | SAI5_TXD2
P2.64 | PWRBTN |  |  |  |  |  |  |  |  |  | PWRBTN
P2.65 |  | ~~ENET1_TD3~~ | GPIO4_IO15 | SAI5_TXD3 |  | P20.28 |  |  |  |  |  |  |  | SAI5_TXD3
P2.66 | POR_B_3P3 |  |  |  |  | P10.7 |  |  |  |  | RESET (combined)
P2.67 |  | ~~ENET1_TX_CTL~~ | GPIO4_IO16 | GPIO4_IO16 |  | P20.20 |  |  |  |  |  |  |  |  |  |  | GPIO4_IO16
P2.68 | ~~ENET1_MDC~~ |  |  | SD1_CLK |  | P20.15 |  |  |  |  |  |  |  |  |  |  |  |  | SD1_CLK
P2.69 |  | ~~ENET1_TXC~~ | GPIO4_IO17 | GPIO4_IO17 |  | P20.30 |  |  |  |  |  |  |  |  |  |  | GPIO4_IO17
P2.70 | ~~ENET1_MDIO~~ |  |  | SD1_CMD |  | P20.17 |  |  |  |  |  |  |  |  |  |  |  |  | SD1_CMD
P2.71 |  | V_SOM |  |  |  |  |  |  |  |  |  |  |  |  |  |  | V_SOM
P2.72 | GND |  |  |  |  |  |  |  |  |  |  |  |  |  |  |  | GND
P2.73 |  | ETH0_MDI0N |  |  |  |  | ETH0_MDI0N
P2.74 | ETH0_MDI0P |  |  |  |  |  | ETH0_MDI0P
P2.75 |  | ETH0_LINK_LED_1000 |  |  |  |  | ETH0_LINK_LED_1000
P2.76 | SAI5_TXD1 |  | GPIO4_IO24 | SAI5_TXD1 | ENET1_nRST | P20.16 |  |  |  |  |  |  |  | SAI5_TXD1 |  |  |  |  | SAI5_TXD1
P2.77 |  | ENET_TD2_BYPASS | GPIO1_IO19 |  |  | P21.27
P2.78 | ETH0_MDI1P |  |  |  |  |  | ETH0_MDI1P
P2.79 |  | ETH0_MDI2P |  |  | SAI7_TX_SYNC |  | ETH0_MDI2P
P2.80 | ETH0_MDI1N |  |  |  | SAI7_TXC |  | ETH0_MDI1N
P2.81 |  | ETH0_MDI2N |  |  |  |  | ETH0_MDI2N
P2.82 | GND
P2.83 |  | ETH0_LED_ACT |  |  |  |  | ETH0_LED_ACT
P2.84 | ETH0_MDI3P |  |  |  |  |  | ETH0_MDI3P
P2.85 |  | ETH0_MDI3N |  |  |  |  | ETH_MDI3N
P2.86 | ETH0_LINK-LED_10_100 |  |  |  |  |  | ETH0_LINK-LED_10_100
P2.87 |  | V_SOM
P2.88 | ~~ENET1_INT~~ |  | GPIO4_IO21 | GPIO4_IO21 |  | P20.18 |  |  |  |  |  |  |  |  |  |  | GPIO4_IO21
P2.89 |  | ECSPI2_MISO | GPIO5_IO12 |  | SAI7_MCLK | P21.22 |  |  |  |  | ECSPI2_MISO |  |  |  |  |  | ECSPI2_MISO | ECSPI2_MISO
P2.90 | PCIE_CLKREQ_B |  |  |  |  | P21.20 |  |  |  |  |  |  |  |  |  |  |  | PCIE_CLKREQ_B
P2.91 |  | ECSPI2_SS0 | GPIO5_IO13 |  |  | P21.24 |  |  |  |  | ECSPI2_SS0 |  |  |  |  |  | ECSPI2_SS0 | ECSPI2_SS0
P2.92 | SD2_nCD |  |  |  |  |  |  |  |  |  |  |  |  |  |  |  |  |  |  | SD2_nCD
P2.93 |  | ECSPI2_SCLK | GPIO5_IO10 |  | SAI7_TXC | P21.26 |  |  |  |  | ECSPI2_SCLK |  |  |  |  |  | ECSPI2_SCLK | ECSPI2_SCLK
P2.94 | SD2_DATA2 |  |  |  |  |  |  |  |  |  |  |  |  |  |  |  |  |  |  | SD2_DATA2
P2.95 |  | ECSPI2_MOSI | GPIO5_IO11 |  | SAI7_TXD0 | P21.28 |  |  |  |  | ECSPI2_MOSI |  |  |  |  |  | ECSPI2_MOSI | ECSPI2_MOSI
P2.96 | SD2_CLK |  |  |  |  |  |  |  |  |  |  |  |  |  |  |  |  |  |  | SD2_CLK
P2.97 |  | SD2_DATA0 |  |  |  |  |  |  |  |  |  |  |  |  |  |  |  |  |  | SD2_DATA0
P2.98 | SD2_DATA3 |  |  |  |  |  |  |  |  |  |  |  |  |  |  |  |  |  |  | SD2_DATA3
P2.99 |  | SD2_DATA1 |  |  |  |  |  |  |  |  |  |  |  |  |  |  |  |  |  | SD2_DATA1
P2.100 | SD2_CMD |  |  |  |  |  |  |  |  |  |  |  |  |  |  |  |  |  |  | SD2_CMD

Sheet: Sheet 1 - M.2 Key B - Connectin
M.2 Key B - Connecting SSD / SATA / Other
Pin id. | Upper | Lower | Description | Dev. Board | NVMe Module AN43 | Custom Extension board | 909 Wiring | Voltage Level
1 | CONFIG_3 |  | Defines Module Type | NC | - |  | pad
2 |  | +3.3V | 3.3 V power supply from main board |  | +3.3V | +3.3V | +3.3V | 3.3V
3 | GND |  | Ground | GND | GND | GND | GND | GND
4 |  | +3.3V | 3.3 V power supply from main board |  | +3.3V | +3.3V | +3.3V | 3.3V
5 | GND |  | Ground (available?) | GND | GND | GND | GND | GND
6 |  | M2B_PWROFF | M2B_PWROFF | Card PWR OFF | - | M2B_PWROFF | M2B_PWROFF / EX2.5 | 1.8/3.3
7 | USB D+ |  | USB high-, full-, and low- speed data pair positive | USB D+ | USB D+ |  | USB D+
8 |  | W_DISABLE# | GPIO12 |  | - |  | EX2.11 | 3.3V
9 | USB D- |  | USB high-, full-, and low- speed data pair negative | USB D- | USB D- |  | USB D-
10 |  | DAS/DSS | GPIO9 Device Activity Signal / Disable Staggered Spinup | DAS/DSS | - |  | LED / EX2.9 | 3.3V
11 | GND |  | Ground (available?) |  | GND |  | GND | GND
12
13
14
15
16
17
18
19
20 |  | M2_I2S_CLK | I2S CLK (GPIO5) | M2_I2S_CLK | - | M2_I2S_CLK | MIC I2S | 1.8V
21 | CONFIG_0 |  |  | NC | - |  | pad
22 |  | M2_I2S_DIN | I2S DIN (GPIO6) | M2_I2S_DIN | - | M2_I2S_DIN | MIC I2S DATA0 | 1.8V
23 | GPIO11 |  | GPIO11 | NC | - |  | MIC I2S MCLK | 1.8V
24 |  | M2_I2S_DOUT | GPIO7 | M2_I2S_DOUT | - | M2_I2S_DOUT | PWM1_OUT | 1.8V
25 | DPR |  |  | NC | - |  | pad | 1.8V
26 |  | GPIO10 | GPIO10 | NC | - |  | EX2.10 | 1.8V
27 | GND |  | Ground | GND | GND | GND | GND | GND
28 |  | M2_I2S_WS | I2S WS (GPIO8) | M2_I2S_WS | - | M2_I2S_WS | MIC I2S WS | 1.8V
29 | USB3 RX- |  | PER-1 / SSIC | M2_USB3_SSRX- | PCIE1 RX- | M2_USB3_SSRX- | M2_USB3_SSRX-
30 |  | SIM_RST |  | UIM RESET | - |  | -
31 | USB3 RX+ |  | PER+1 / SSIC | M2_USB3_SSRX+ | PCIE1 RX+ | M2_USB3_SSRX+ | M2_USB3_SSRX+
32 |  | SIM_CLK |  | UIM CLK | - |  | -
33 | GND |  | Ground | GND | GND | GND | GND | GND
34 |  | SIM_DATA |  | UIM DATA | - |  | -
35 | USB3 TX- |  | PET-1 / SSIC | M2_USB3_SSTX- | PCIE1 TX- | M2_USB3_SSTX- | M2_USB3_SSTX-
36 |  | SIM_PWR |  | UIM PWR | - |  | -
37 | USB3 TX+ |  | PET+1 / SSIC | M2_USB3_SSTX+ | PCIE1 TX+ | M2_USB3_SSTX+ | M2_USB3_SSTX+
38 |  | DEVSLP | Device Sleep, input. If driven high the host is informing the SSD to enter a low power state. | DEVSLP | - |  | DEVSLP / EX2.12 | 3.3V
39 | GND |  | Ground | GND | GND | GND | GND | GND
40 |  | M2 SMB SCL | GPIO0 / SMB_CLK | M2 SMB SCL | - |  | I2C3 SCL level shifted | 1.8V
41 | PCIE RXN- |  | PCIE RXN- / PER-0 / PCI Lane 0 / SATA-B+ | PCIE RXN- | PCIE0 RXN- | PCIE RXN- | PCIE RXN- | 1.8V
42 |  | M2 SMB SDA | GPIO1 / SMB_DATA | M2 SMB SDA | - |  | I2C3 SDA level shifted | 1.8V
43 | PCIE RXN+ |  | PCIE RXN+ / PER+0 / PCI Lane 0 / SATA-B- | PCIE RXN+ | PCIE0 RXN+ | PCIE RXN+ | PCIE RXN+ | 1.8V
44 |  | ALERT | GPIO2 / ALERT / I2C IRQ | GPIO2 / ALERT | - |  | ALERT / IRQ / EX2.7 | 1.8V
45 | GND |  | Ground | GND | GND | GND | GND | GND
46 |  | GPIO3 | GPIO3 | GPIO3 | - |  | PWM2_OUT | 1.8V
47 | PCIE TXN- |  | PCIE TXN- / PET-0 / PCI Lane 0 / SATA-A- | PCIE TXN- | PCIE0 TXN- | PCIE TXN- | PCIE TXN- | 1.8V
48 |  | GPIO4 | GPIO4 | GPIO4 | - |  | PWM3_OUT | 1.8V
49 | PCIE TXN+ |  | PCIE TXN+ / PET-0 / PCI Lane 0 / SATA-A+ | PCIE TXN+ | PCIE0 TXN+ | PCIE TXN+ | PCIE TXN+ | 1.8V
50 |  | PERST | PCI Reset | PERST | PCI_RESET | PERST | mPCIe_PERST | 3.3V
51 | GND |  | Ground | GND | GND | GND | GND | GND
52 |  | CLKREQ | Reference clock request | CLKREQ | CLKREQ | CLKREQ | PCIE_CLKREQ_B | 3.3V
53 | PCIE REFCLK- |  | PCIE REFCLK- | REFCLK- | PCIE REFCLK- | PCIE REFCLK- | PCIE REFCLK- | 1.8V
54 |  | WAKE | PCIe WAKE# Open Drain with pull up on platform. Active Low. | WAKE | PCI_WAKE | WAKE | USB1_SS_SEL | 3.3V
55 | PCIE REFCLK+ |  | PCIE REFCLK+ | REFCLK+ | PCIE REFCLK+ | PCIE REFCLK+ | PCIE REFCLK+ | 1.8V
56 |  | MFG SDA | MFG_DAT | NC | - | + | SYS I2C SDA | ?
57 | GND |  | Ground | GND | GND | + | GND | GND
58 |  | MFG SCL | MFG_CLK | NC | - | + | SYS I2C SCL | ?
59 | ANTCTL0 |  | SPI | NC |  | + | ECSPI2_MISO | 1.8V
60 |  | COEX3 |  | NC |  | + | MIC I2S DATA3 | 1.8V
61 | ANTCTL1 |  | SPI | NC |  | + | ECSPI2_SS0 | 1.8V
62 |  | COEX_TXD |  | NC |  | + | MIC I2S DATA2 | 1.8V
63 | ANTCTL2 |  | SPI | NC |  | + | ECSPI2_SCLK | 1.8V
64 |  | COEX_RXD |  | NC |  | + | MIC I2S DATA1 | 1.8V
65 | ANTCTL3 |  | SPI | NC |  | + | ECSPI2_MOSI | 1.8V
66 |  | SIM DETECT |  | SIM CD |  | + |  | 1.8V
67 | RESET# |  | SD Card Reset signal | RESET# | - | RESET# | RESET# / EX2.6 | 1.8V
68 |  | SUSCLK | 32.768 kHz clock supply input provided by the Platform chipset | NC | - | SUSCLK | - | 3.3V
69 | CONFIG_1 |  | Defines module type |  | CONFIG_1 | CONFIG_1 | CONFIG_1 / EX2.14
70 |  | VRES | Power | VRES | VRES | VRES | VRES | +3.3V
71 | GND |  | Ground |  | GND | GND | GND | GND
72 |  | VRES | Power | VRES | VRES | VRES | VRES | +3.3V
73 | GND |  | Ground |  | GND | GND | GND | GND
74 |  | VRES | Power | VRES | VRES | VRES | VRES | +3.3V
75 | CONFIG_2 |  | Defines Module Type | NC | - | CONFIG_2 | pad

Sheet: Sheet 1 - M.2 Key E - Connectin
M.2 Key E - Connecting Wireless module / GSM / LTE / LoRa / BT
Pin id. | Upper | Lower | Description | Key A+E | AN13049 NXP | Custom Extension board | 909 Wiring | Voltage Level
1 | GND |  | Ground | GND | GND |  | GND | GND
2 |  | +3.3V | 3.3 V power supply from main board | +3.3V | +3.3V | +3.3V | +3.3V | 3.3V
3 | USB D+ |  | USB high-, full-, and low- speed data pair positive | USB D+ | USB D+ |  | USB D+
4 |  | +3.3V | 3.3 V power supply from main board | +3.3V | +3.3V | +3.3V | +3.3V | 3.3V
5 | USB D- |  | USB high-, full-, and low- speed data pair negative | USB D- | USB D- |  | USB D-
6 |  | DAS/DSS | GPIO9 Device Activity Signal / Disable Staggered Spinup | DAS/DSS | - |  | LED / EX1.9 | 3.3V
7 | GND |  | Ground | GND | GND |  | GND | GND
8 |  | I2S SCK |  |  |  |  | Speaker I2S SCK | 1.8V
9 | SDIO CLK |  |  |  |  |  | SD1_CLK | 1.8V
10 |  | I2S WS |  |  |  |  | Speaker I2S WS | 1.8V
11 | SDIO CMD |  |  |  |  |  | SD1_CMD | 1.8V
12 |  | I2S DIN |  |  |  |  | ? | 1.8V
13 | SDIO DATA0 |  |  |  |  |  | SD1_DATA0 | 1.8V
14 |  | I2S OUT |  |  |  |  | Speaker I2S TXD0 | 1.8V
15 | SDIO DATA1 |  |  |  |  |  | SD1_DATA1 | 1.8V
16 |  | LED2# |  | LED2# |  |  | EX1.14
17 | SDIO DATA2 |  |  | NC |  |  | SD1_DATA2 | 1.8V
18 |  | GND | Ground | GND | GND |  | GND | GND
19 | SDIO DATA3 |  |  | NC |  |  | SD1_DATA3 | 1.8V
20 |  | UART WAKE# | Sideband signal used by the Bluetooth radio to wake up the platform. Active Low by default Connect to Host GPIO Open drain. Pullup required on platform. | NC | BT_WAKE_HOST |  | EX1.12 | 3.3V
21 | SDIO WAKE# |  | Sideband signal used by the Wi-Fi radio to wake up the platform. Active Low by default Connect to Host GPIO Open drain. Pullup required on platform. | NC | WLAN_WAKE_HOST |  | EX1.13 | 1.8V
22 |  | UART RxD |  | NC |  |  | UART2_RXD | 1.8V
23 | SDIO RESET# |  | Sideband signal to independently reset the Wi- Fi radio. Active Low by default Connect to Host GPIO. | NC | WLAN_INDEPENDENT_ RESET |  | SD1_RESET_B | 1.8V
24
25
26
27
28
29
30
31
32 |  | UART TxD |  | NC |  |  | UART2_TXD | 1.8V
33 | GND |  | Ground | GND | GND |  | GND | GND
34 |  | UART CTS |  | NC |  |  | UART4_RXD | 1.8V
35 | PETp0 |  | PCIe Tx | PETp0 |  |  | -
36 |  | UART RTS |  | NC |  |  | UART4_TXD | 1.8V
37 | PETn0 |  | PCIe Tx | PETn0 |  |  | -
38 |  |  | Used for debug. Connect to JTAG header on platform. | Vendor | JTAG_TDO |  |  | 1.8V
39 | GND |  | Ground | GND | GND |  | GND | GND
40 |  | COEX4 | Sideband signal used by the platform to wake up the Wi-Fi radio. Active Low. Connect to Host GPIO. | Vendor | DEV_WLAN_WAKE / COEX4 |  | EX1.5 | 1.8V
41 | PERp0 |  | PCIe Rx | PERp0 |  |  | -
42 |  | DEV_BT_WAKE | Sideband signal used by the platform to wake up the Bluetooth radio. Radio Coexistence line 4. Active Low. Connect to Host GPIO. | Vendor | DEV_BT_WAKE |  | EX1.6 | 1.8V
43 | PERn0 |  | PCIe Rx | PERn0 |  |  | -
44 |  | COEX3 | Radio Coexistence line 3. Used for debug. Connect to JTAG header on platform. | COEX3 | JTAG_TDI / COEX3 |  |  | 1.8V
45 | GND |  | Ground | GND | GND |  | GND | GND
46 |  | COEX_RxD | Radio Coexistence line 2. Used for debug. Connect to JTAG header on platform. | COEX2 | JTAG TCK / COEX2 |  | UART1_RXD ? | 1.8V
47 | PEFCLKp0 |  |  | PEFCLKp0 |  |  | -
48 |  | COEX_TxD | Radio Coexistence line 1. Used for debug. Connect to JTAG header on platform. | COEX1 | JTAG_TMS / COEX1 |  | UART1_TXD ? | 1.8V
49 | PEFCLKn0 |  |  | PEFCLKn0 |  |  | -
50 |  | SUSCLK | 32.768 kHz clock input | SUSCLK |  |  |  | 3.3V
51 | GND |  | Ground | GND | GND |  | GND | GND
52 |  | PERST0# |  | PERST0# |  |  | - | 3.3V
53 | CLKREQ0# |  | PCI Clock request 0 | CLKREQ0# |  |  | - | 3.3V
54 |  | W_DISABLE2# | Sideband signal to independently reset the Bluetooth radio. Active Low by default Connect to Host GPIO. | W_DISABLE2# | BT_INDEPENDENT_ RESET |  | EX1.10 | 3.3V
55 | PEWake0# |  | PCIe wake | PEWake0# |  |  | -
56 |  | W_DISABLE1# | Full Power-down for the Wi-Fi/Bluetooth radio: High = normal mode. Low = full power-down mode Connect to Host GPIO. | W_DISABLE1# | PDn |  | EX1.11
57 | GND |  | Ground | GND | GND |  | GND | GND
58 |  | I2C_DATA | I2C DATA | SMB_DATA |  |  | I2C3 SDA level shifted | 1.8V
59 | USB3 TX+ |  | PETp1 / USB3 TX+ | Reserved |  |  | USB3 SSTX+
60 |  | I2C_CLK | I2C CLK | SMB_CLK |  |  | I2C3 SCL level shifted | 1.8V
61 | USB3 TX- |  | PETn1 / USB3 TX- | Reserved |  |  | USB3 SSTX-
62 |  | ALERT# |  | ALERT# |  |  | EX1.7
63 | GND |  | Ground | GND | GND |  | GND | GND
64 |  | Reserved |  | Reserved |  |  | -
65 | USB3 RX+ |  | PERp1 / USB3 RX+ | Reserved |  |  | USB3 SSRX+
66 |  | UIM SWP | UIM SWP / PERST1# | UIM SWP
67 | USB3 RX- |  | PERn1 / USB3 RX- | Reserved |  |  | USB3 SSRX-
68 |  | UIM PWR | UIM Power Sink / CLKREQ1# | UIM PWR
69 | GND |  | Ground | GND | GND |  | GND | GND
70 |  | UIM PWR | UIM Power Source / PEWAKE1# | UIM PWR
71 | REFCLKp1 |  |  | Reserved |  |  | -
72 |  | +3.3V | 3.3 V power supply from main board | +3.3V | +3.3V | +3.3V | +3.3V | 3.3V
73 | Reserved |  |  | Reserved |  |  | -
74 |  | +3.3V | 3.3 V power supply from main board | +3.3V | +3.3V | +3.3V | +3.3V | 3.3V
75 | GND |  | Ground | GND | GND |  | GND | GND

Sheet: Sheet 1 - 919 Smiley
919 Smiley
Signal | 801 T-USB | BHI260AB | IS31FL3730 | SOM / MCU | PCA9555 | CAM connectors | Breakout
I2C3 SDA |  | Host IF | I2C3 SDA | I2C3 SDA
I2C3 SCL |  | Host IF | I2C3 SCL | I2C3 SCL
SYS SDA |  |  |  | SYS SDA | SDA 3V3
SYS SCL |  |  |  | SYS SCL | SCL 3V3
I2C5 SDA |  | Master 3 |  | I2C5 SDA |  | Left SCCB
I2C5 SCL |  | Master 3 |  | I2C5 SCL |  | Left SCCB
I2C6 SDA |  | Master 2 SDX |  | I2C6 SDA |  | Right SCCB
I2C6 SCL |  | Master 2 SCX |  | I2C6 SCL |  | Right SCCB
SPI SCK |  | M1SCK |  |  |  |  | SPI SCK
SPI MOSI |  | M1SDX |  |  |  |  | SPI MOSI
SPI MISO |  | M1SDI |  |  |  |  | SPI MISO
EX0_nINT |  |  |  |  | nINT
EX0.2
EX0.3
EX0.4 |  | BN_H_INTN |  |  |  | IMU_IRQ
EX0.5 |  | RESETN |  |  |  | IMU_RESETN
EX0.6 |  | HOSTBOOT |  |  |  | IMU_MODE
EX0.7
EX0.8 |  |  |  |  |  | CSI1_PWR_DWN_B
EX0.9 |  |  |  |  |  | LEFT_CAM_RESET
EX0.10 |  |  |  |  |  | LEFT_ATT_INT
EX0.11 |  |  |  |  |  | LEFT_ATT_XSHUT
EX0.12 |  |  |  |  |  | CSI2_PWR_DWN_B
EX0.13 |  |  |  |  |  | RIGHT_CAM_RESET
EX0.14 |  |  |  |  |  | RIGHT_ATT_INT
EX0.15 |  |  |  |  |  | RIGHT_ATT_XSHUT
 |  | JTAG_CLK |  |  |  |  | JTAG_CLK
 |  | JTAG_DIO |  |  |  |  | JTAG_DIO
 |  |  | IN |  |  |  | LED_AUDIO
 |  |  | C_FILT |  |  |  | LED_FILTER
 |  | MCSB1 |  |  |  |  | GPIO
 |  | MCSB2 |  |  |  |  | GPIO
 |  | MCSB3 |  |  |  |  | GPIO
 |  | MCSB4 |  |  |  |  | GPIO
 |  | M1SCX |  |  |  |  | M1SCX
 |  | M1SDX |  |  |  |  | M1SDX
 |  | M1SDI |  |  |  |  | M1SDI
Signal Level |  |  | 3.3V |  | 3.3V
Standalone 1V8 |  | Consumes |  |  |  | VCC_1V8
VCC_SOM | Supplies |  | Consumes
Powered 3V3 |  |  |  |  |  | AF_VDD
Powered 1V8 |  | Consumes |  |  |  | DOVDD + VCC_1V8
Powered 2V8 |  |  |  |  |  | AVDD_2V8

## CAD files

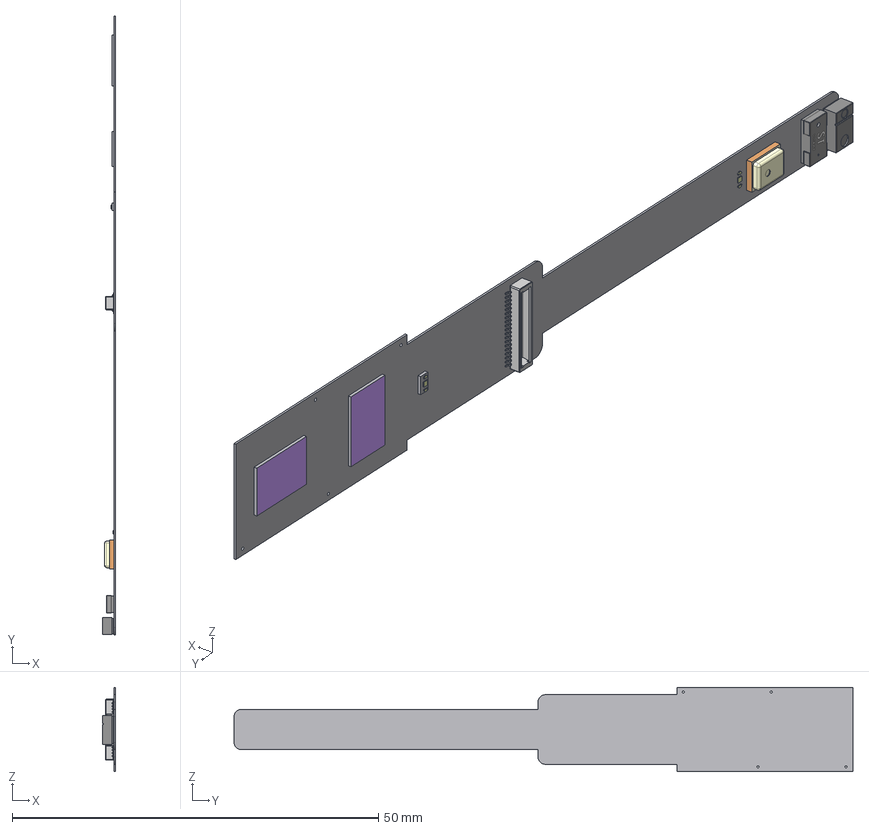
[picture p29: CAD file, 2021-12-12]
Hardware/201/OV2735-combined-module/Ziloo simplified v2 camera module.step
1.82 x 84.5 x 11.5 mm

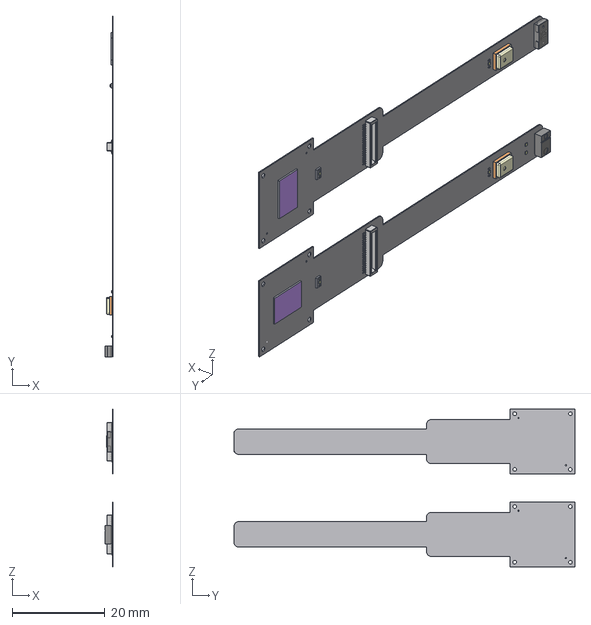
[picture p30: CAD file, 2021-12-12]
Hardware/201/OV2735-module/Ziloo v2 camera modules.step
1.82 x 73.5 x 34.0 mm

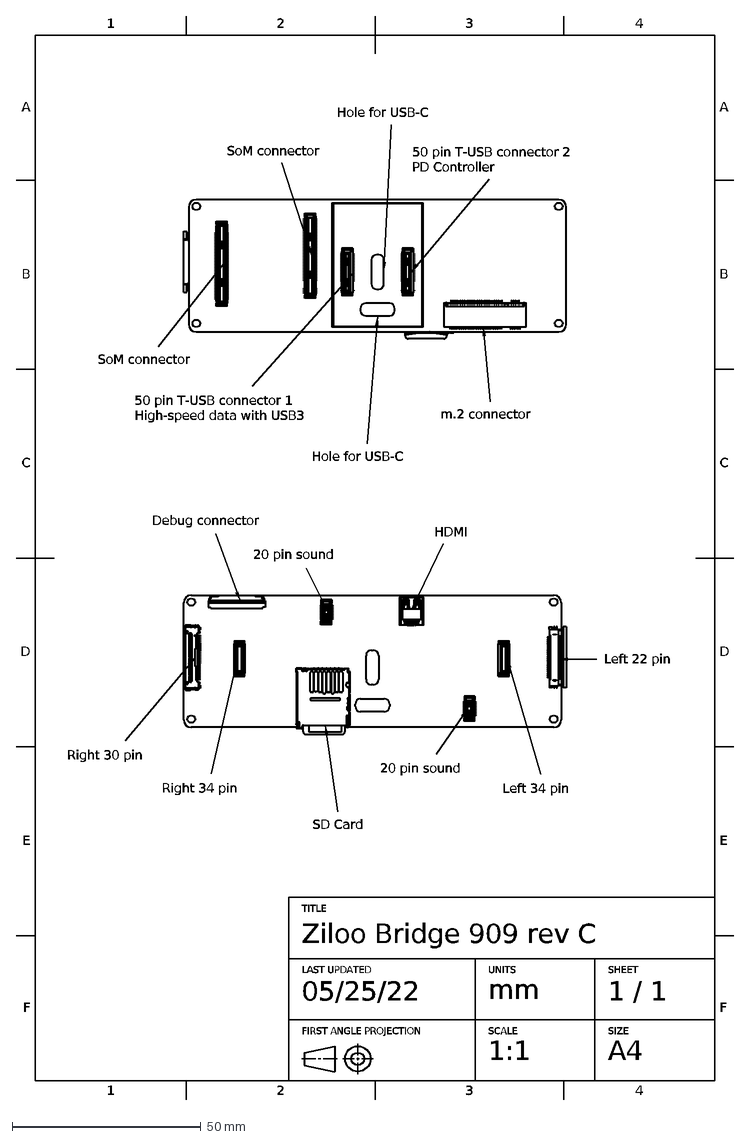
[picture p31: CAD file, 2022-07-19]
Hardware/909c/Ziloo Bridge 909 rev C.dxf
1
2
3
4
F
E
D
C
B
A
TITLE
Ziloo Bridge 909 rev C
LAST UPDATED
05/25/22
UNITS
mm
SHEET
1 / 1
FIRST ANGLE PROJECTION
SCALE
1:1
SIZE
A4
SoM connector
Hole for USB-C
50 pin T-USB connector 1 High-speed data with USB3
50 pin T-USB connector 2 PD Controller
m.2 connector
Debug connector
Left 34 pin
Right 34 pin
HDMI
Left 22 pin
Right 30 pin
20 pin sound
SD Card

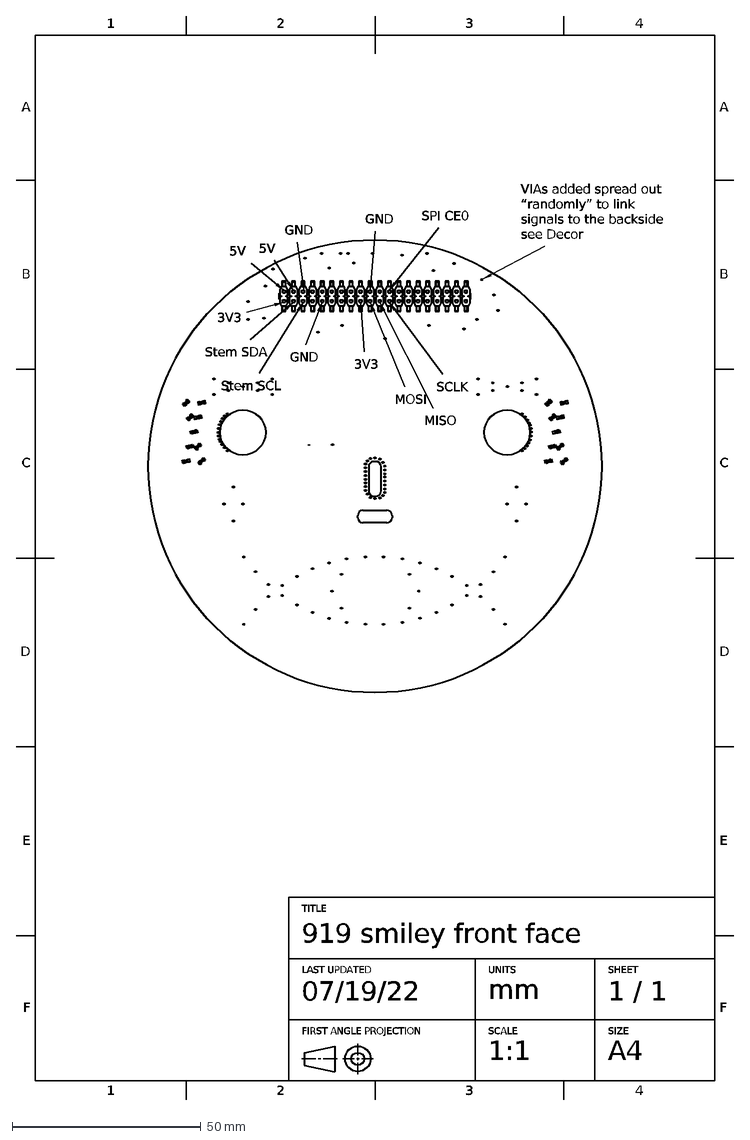
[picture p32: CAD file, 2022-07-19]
Hardware/919-smiley/919 smiley front face.dxf
1
2
3
4
F
E
D
C
B
A
TITLE
919 smiley front face
LAST UPDATED
07/19/22
UNITS
mm
SHEET
1 / 1
FIRST ANGLE PROJECTION
SCALE
1:1
SIZE
A4
5V
GND
SPI CE0
3V3
Stem SDA
Stem SCL
MOSI
MISO
SCLK
VIAs added spread out “randomly” to link signals to the backside see Decor

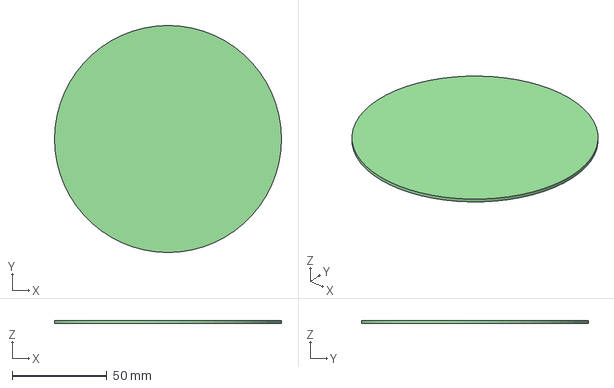
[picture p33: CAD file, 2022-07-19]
Hardware/919-smiley/decor/Decor.step
120.0 x 120.0 x 1.60 mm

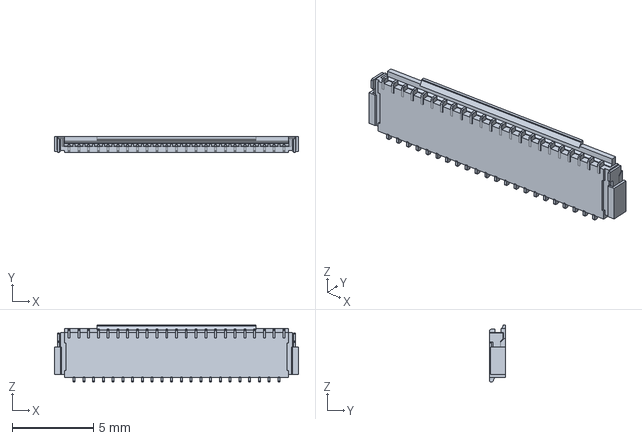
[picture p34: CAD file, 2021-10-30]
Hardware/datasheets/c-4-2328724-5-a-3d.stp
15.0 x 1.00 x 3.48 mm

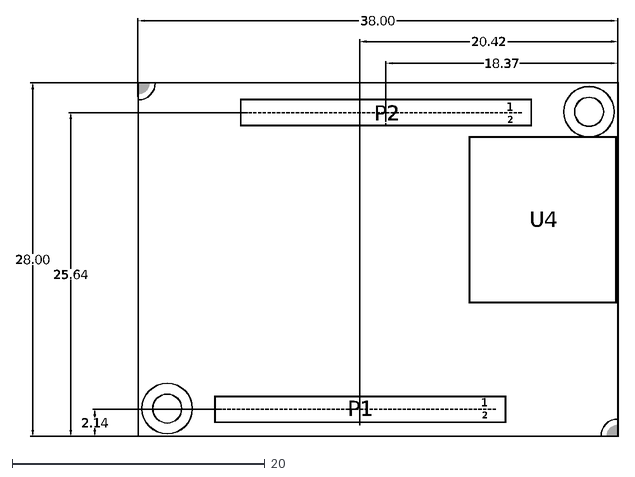
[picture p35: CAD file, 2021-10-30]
Hardware/datasheets/i.MX8/ucm-imx8m-plus_mechanical-drawings/ucm-imx8m-plus_mechanical-drawings_bottom.DXF
P2
P1
U4
2
1
28.00
2.14
25.64
38.00
18.37
20.42

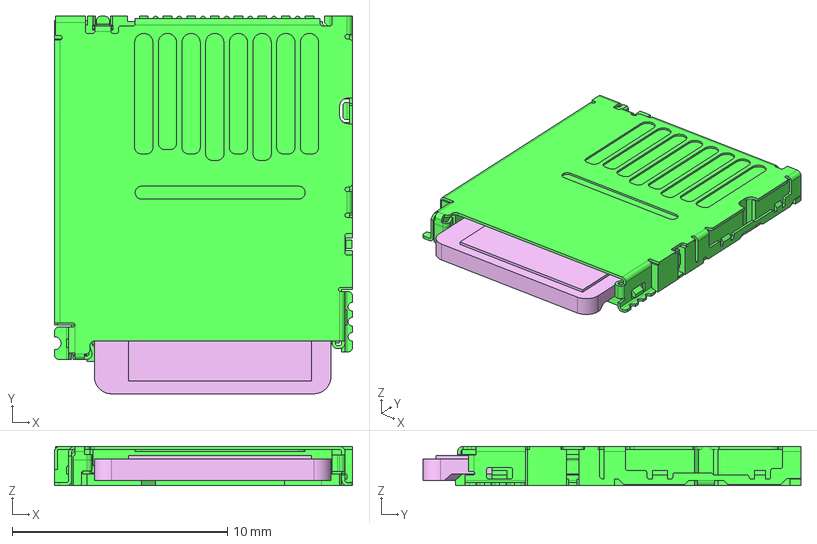
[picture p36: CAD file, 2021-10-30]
Hardware/datasheets/WPCC-1600212_0001218907S/DM3BT-DSF-PEJS.stp
13.8 x 17.6 x 1.83 mm
CARD
DM3BT

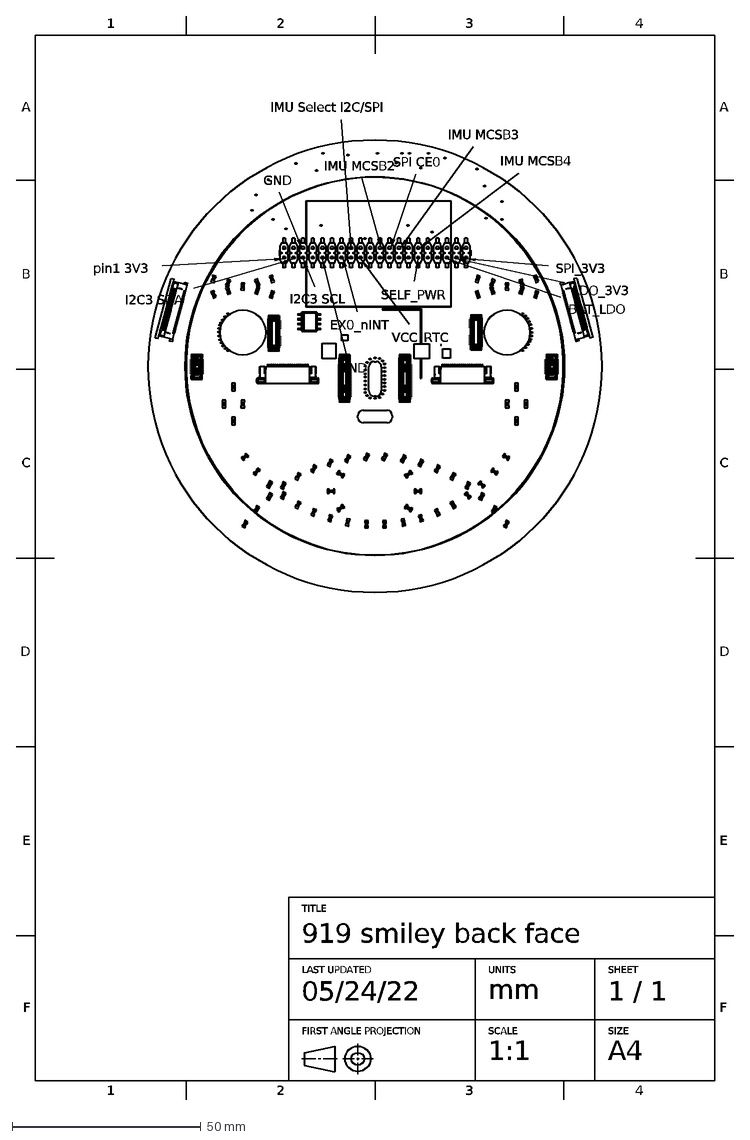
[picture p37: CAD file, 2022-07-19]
Hardware/919-smiley/919 smiley back face.dxf
1
2
3
4
F
E
D
C
B
A
TITLE
919 smiley back face
LAST UPDATED
05/24/22
UNITS
mm
SHEET
1 / 1
FIRST ANGLE PROJECTION
SCALE
1:1
SIZE
A4
pin1 3V3
I2C3 SDA
I2C3 SCL
EX0_nINT
VCC_RTC
GND
SPI CE0
IMU Select I2C/SPI
IMU MCSB2
IMU MCSB3
IMU MCSB4
SPI_3V3
LDO_3V3
BAT_LDO
SELF_PWR

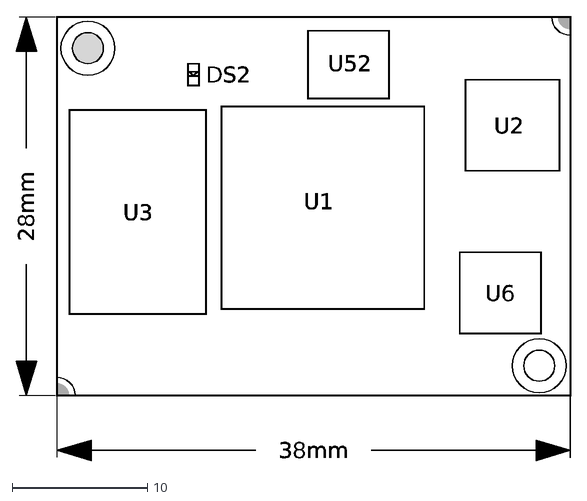
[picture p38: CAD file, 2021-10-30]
Hardware/datasheets/i.MX8/ucm-imx8m-plus_mechanical-drawings/ucm-imx8m-plus_mechanical-drawings_top.DXF
U1
U2
U3
U6
DS2
U52
28mm
38mm

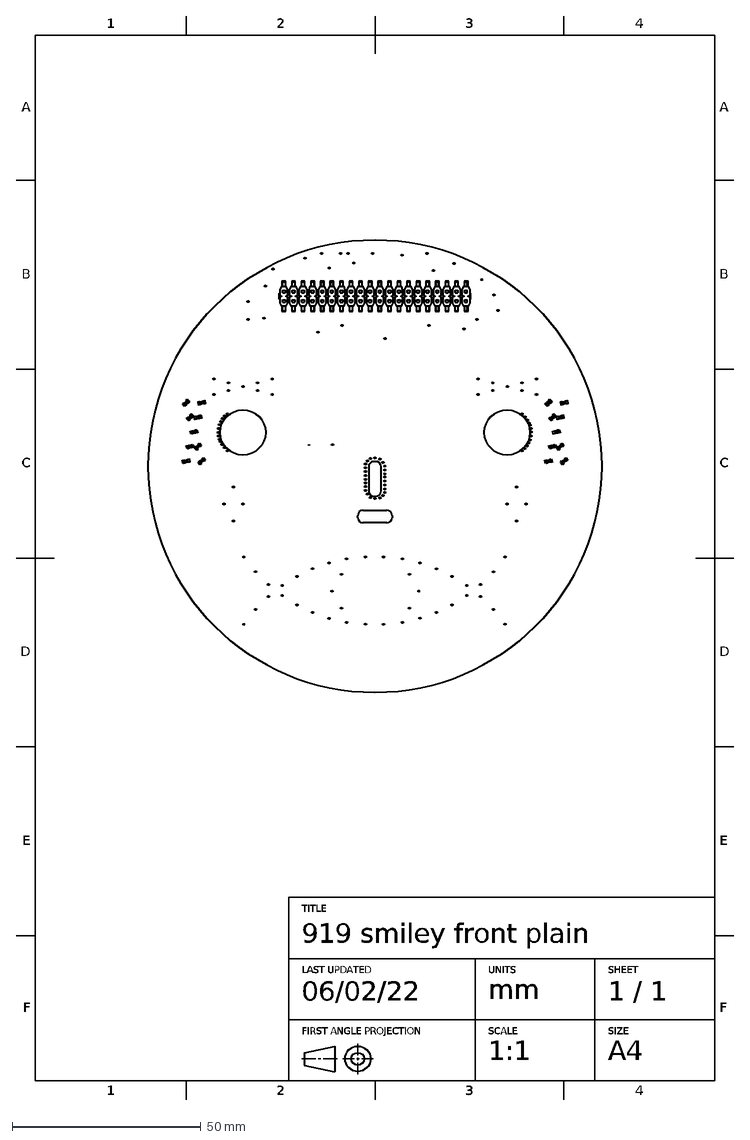
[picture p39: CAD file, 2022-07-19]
Hardware/919-smiley/919 smiley front plain.dxf
1
2
3
4
F
E
D
C
B
A
TITLE
919 smiley front plain
LAST UPDATED
06/02/22
UNITS
mm
SHEET
1 / 1
FIRST ANGLE PROJECTION
SCALE
1:1
SIZE
A4

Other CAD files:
Hardware/801-T-USB/801 T-USB testing.dwg
Hardware/909b/Ziloo Bridge 909 rev B.dwg
Hardware/refs/CM4-IO-BASE/CM4-IO-BASE.DWG
Hardware/refs/IMX219-83 Stereo Camera.dwg
Hardware/801-T-USB/801 T-USB module.dwg
Hardware/909b/Ziloo Bridge 909b.dwg
Hardware/909c/Drawing_Ziloo_Bridge_909b.dwg
Hardware/201/OV2735-combined-module/Ziloo simplified v2 camera module.dwg
Hardware/201/OV2735-module/Ziloo v2 camera modules.dwg

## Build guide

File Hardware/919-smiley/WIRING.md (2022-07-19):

| Signal | 801 T-USB | BHI260AB | IS31FL3730 | SOM / MCU | PCA9555 | CAM connectors  | Breakout |
|---|---|---|---|---|---|---|---|
| STEM SDA | Stem SDA  | Host IF | STEM SDA | | | | |
| STEM SCL | Stem SCL  | Host IF | STEM SCL | | | | |
| SYS SDA | SYS SDA | | | SYS SDA | SDA 3V3 | | |
| SYS SCL | SYS SCL | | | SYS SCL | SCL 3V3 | | |
| I2C5 SDA | | Master 3 | | I2C5 SDA  | | Left SCCB | |
| I2C5 SCL | | Master 3 | | I2C5 SCL  | | Left SCCB | |
| I2C6 SDA | NIGHT SDA | Master 2 SDX | | I2C6 SDA  | | Right SCCB | |
| I2C6 SCL | NIGHT SCL | Master 2 SCX | | I2C6 SCL  | | Right SCCB | |
| SPI SCK | | M1SCK | | | | | SPI SCK |
| SPI MOSI | | M1SDX | | | | | SPI MOSI |
| SPI MISO | | M1SDI | | | | | SPI MISO |
| | | | | | | | |
| EX0_nINT | | | | | nINT | | |
| | | | IN | | | | LED_AUDIO  |
| | | | C_FILT | | | | LED_FILTER |
| | | MCSB1 | | | | | GPIO |
| | | MCSB2 | | | | | GPIO |
| | | MCSB3 | | | | | GPIO |
| | | MCSB4 | | | | | GPIO |
| | | M1SCX | | | | | M1SCX |
| | | M1SDX | | | | | M1SDX |
| | | M1SDI | | | | | M1SDI |
| | | | | | | | |
| Signal Level | | | 3.3V | | 3.3V | | |
| Standalone 1V8 | | Consumes | | | | VCC_1V8 | |
| VCC_SOM | Supplies  | | Consumes | | | | VCC_SOM |
| Powered 3V3 | | | | | | AF_VDD | |
| Powered 1V8 | | Consumes | | | | DOVDD + VCC_1V8 | |
| Powered 2V8 | | | | | | AVDD_2V8 | |

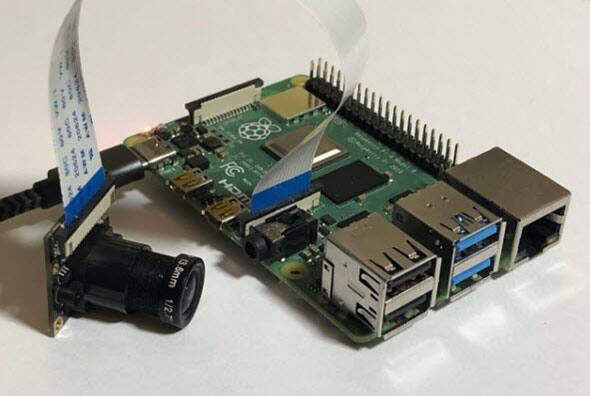
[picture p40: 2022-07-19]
Hardware/201/img/How-to-Connect-a-Camera-to-a-Raspberry-Pi.jpg

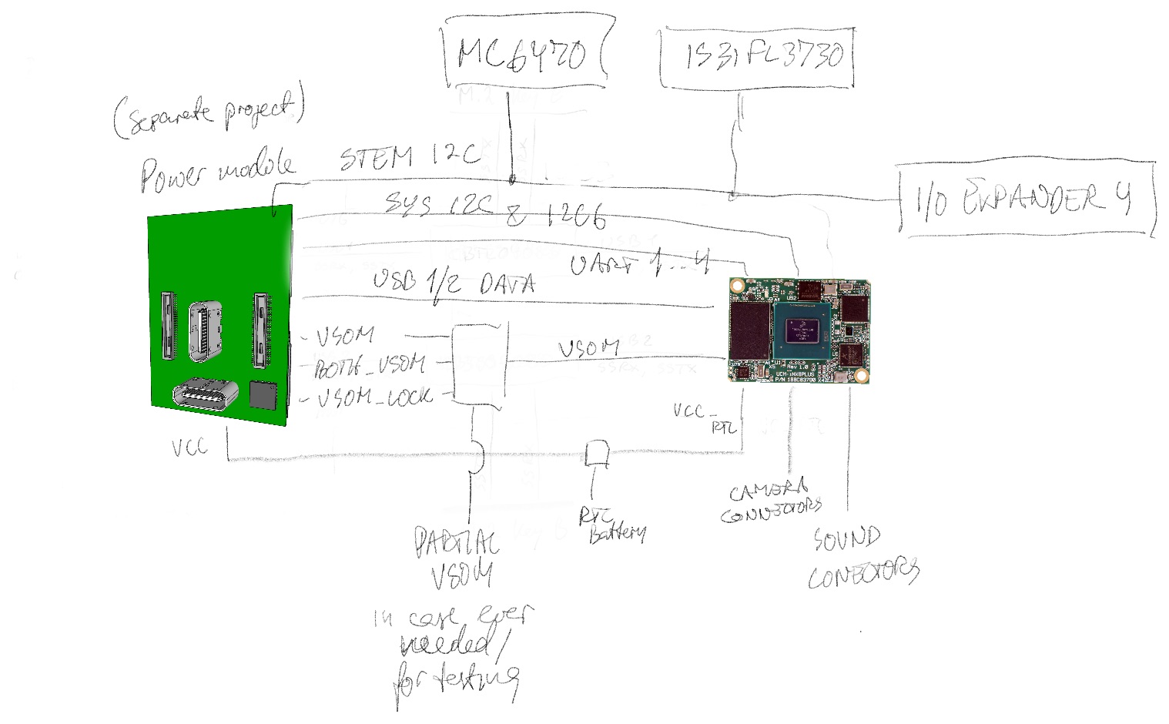
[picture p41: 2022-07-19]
Hardware/refs/POWER-MODULE-conceptual-wiring.jpg

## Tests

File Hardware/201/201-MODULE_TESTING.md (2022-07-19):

# Camera module breakout board

The aim is to create a batch of 10 breakout PCBs for testing and connecting the camera module via a Raspberry Pi connector.

The board has a 34 pin socket for connecting a 201 camera module.
This is connected and voltage shifted where needed to a Raspberry Pi Zero 22 pin connector and a RPi 15 pin connector for connecting to a RPi compatible dev board.

Additionally there should be a 30 pin IPEX connector for connecting to the UCM Compulab board.

Regular 1/100” header pins are broken out for I2C, I2S and other signal pins. It should be possible to connect with 1v8 and 3v3 signals. Add header pins for power as well.

Note: Perhaps it makes no sense to have a 22 pin connector since the Raspberry Pi standard is 15 pins on the camera module side.
Consider dropping this connector.

## Verification of modules

The aim is to verify and validate the viability of the supplied camera modules. You will get two day time and two night time modules and assorted lenses. I will also send you a dev board.

- Test that the camera registers can be accessed with I2S
- Test that the laser range and ambient light can be accessed with I2S
- Test that camera sensor can be read using CSI2
- Test that microphone can be read using I2S

## Testing lenses

The supplied lenses are of various types, the aim is to evaluate the various lenses on the dimensions of,

- Image quality
- How close an object can be to the camera and remain mostly in focus
- How far away can a 5cm x 5cm toy be in a picture and remain recognizable 
- How far off center can an object or person be and be in view

At the completion of the project you will return the supplied development board, camera modules, lenses and produced test boards.

## Testing Setups

The test board is used to test Camera Modules. Development boards that may be used to test are,

- [I-Pi SMARC IMX8M Plus](https://www.ipi.wiki/products/i-pi-smarcplus-imx8mp)
- [Compulab SB-UCM-iMX8PLUS](https://www.compulab.com/products/carrier-boards/sb-ucmimx8plus-carrier-board/)
- [Raspberry Pi CM 4 IO Board B](https://www.waveshare.com/product/raspberry-pi/boards-kits/compute-module-4-cat/cm4-io-base-acce-b.htm)
- [Tinker Edge R](https://tinker-board.asus.com/product/tinker-edge-r.html) for testing.

## Price / Milestones

Price $1500 plus cost of board production

Milestones
300 Testing board design completed with design files
150 + cost, produce test boards
600 verification of camera modules 
150 testing lenses
300 boards, modules, lenses are returned 

# Connectors

- 1 * RPi compatible [TE Connectivity 15pin 1mm FPC 1-84952-5](https://www.te.com/usa-en/product-1-84952-5.html)
- 1 * [Molex 22PIN 0.5mm pitch 54548-2271](https://www.molex.com/molex/products/part-detail/ffc_fpc_connectors/0545482271)
- 1 * [I-PEX 30PIN 0.4mm pitch 20525-030E-02](https://www.i-pex.com/product/cabline-ca)
- 1 * [Hirose DF40C-34DS-0.4V](https://www.hirose.com/en/product/p/CL0684-4023-0-51) ([Mouser](https://www.mouser.ch/ProductDetail/Hirose-Connector/DF40C-34DS-04V51?qs=vcbW%252B4%252BSTIpg26DsEbj1iQ%3D%3D))

## Pinouts: Hirose DF40 single eye connector 34 pins

**Just to be clear**: All CSI lanes are laid out on one side of the connector with GND between.

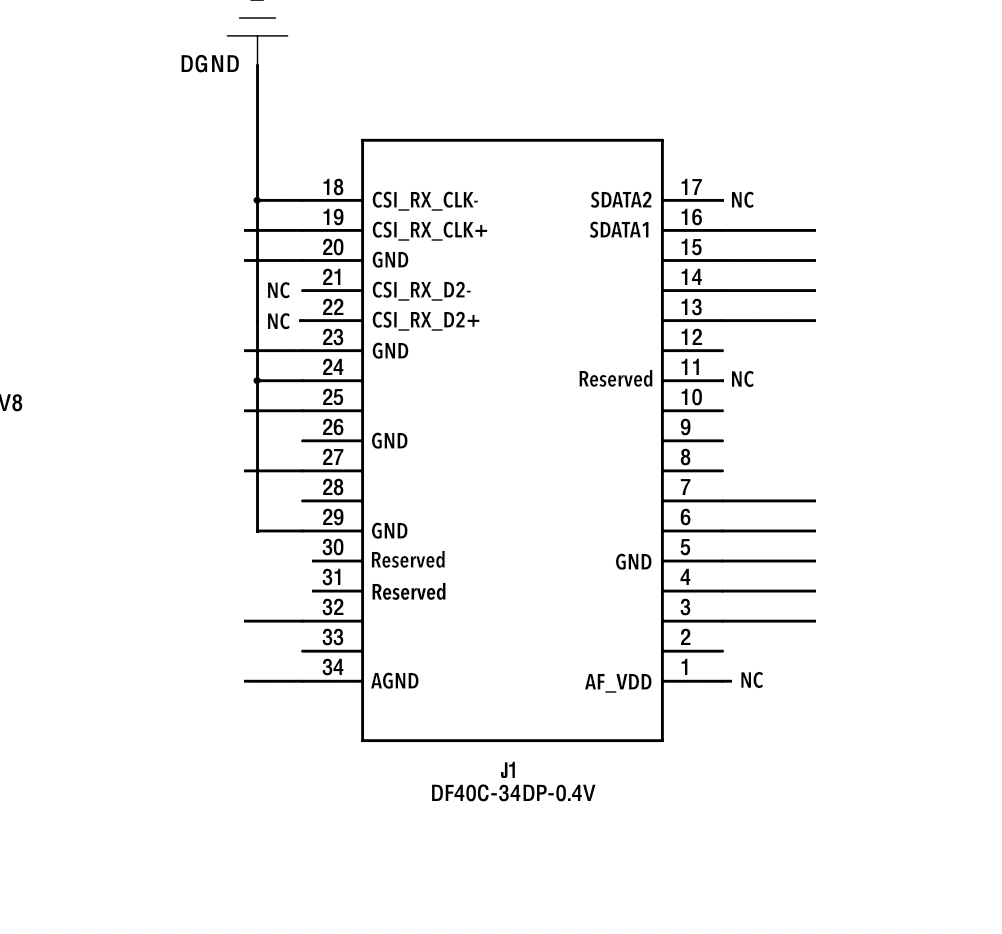
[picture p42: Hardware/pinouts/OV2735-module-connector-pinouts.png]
Pinouts for connector


:[Camera Module 201 connector](../pinouts/CAMERA_MODULE_CONNECTOR_PINOUT.md)

## NVIDIA FPC 30 pins

:[30 pins I-PEX CSI connector](../pinouts/I-PEX_30_CONNECTOR.md)

## RPI FPC 22 pins

:[22 pins RPi CSI connector](../pinouts/RPI_22_CONNECTOR.md)

## RPI FPC 15 pins

:[15 pins RPi CSI connector](../pinouts/RPI_15_CONNECTOR.md)

[ArduCam description for connector](https://www.arducam.com/raspberry-pi-camera-pinout/).
ArduCam uses FCI connector [SFW15R-2STE1LF](https://www.arducam.com/downloads/SFW15R-2STE1LF.pdf).

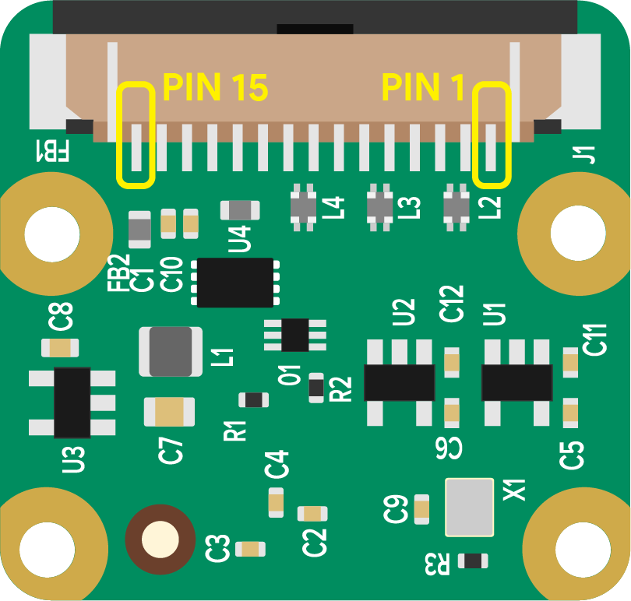
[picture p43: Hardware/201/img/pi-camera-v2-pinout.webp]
V2 connector


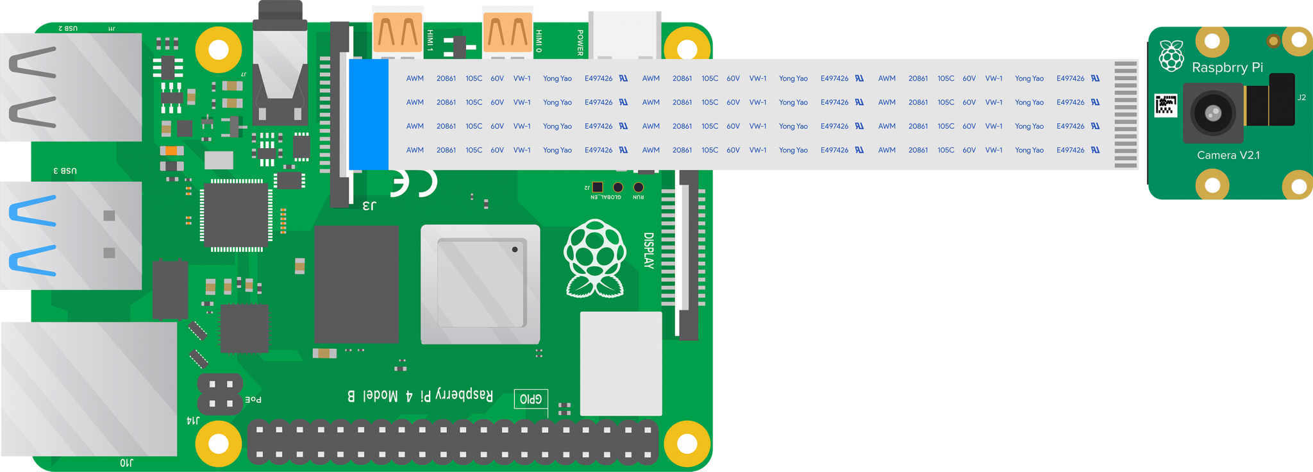
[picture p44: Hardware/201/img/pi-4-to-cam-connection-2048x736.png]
mounting


|

## Connecting Raspberry Pi to camera module

Using a supported camera module together with a Raspberry Pi is the most straightforward way of adding visual input to a project. The only thing needed is a supported camera module such as the official Raspberry Pi camera module. However, many alternative modules exist: for example, this breakout board with a night-vision camera and infrared LEDs.

Regardless of the chosen camera, the setup process always works similarly, as long as the camera is supported by the Raspberry Pi. First, plug the ribbon connector of the camera module into the connector on the Raspberry Pi. The white connector closer to the USB and Ethernet ports is the one for the camera. The other port, located on the other side of the single-board computer, is meant for connecting a display.

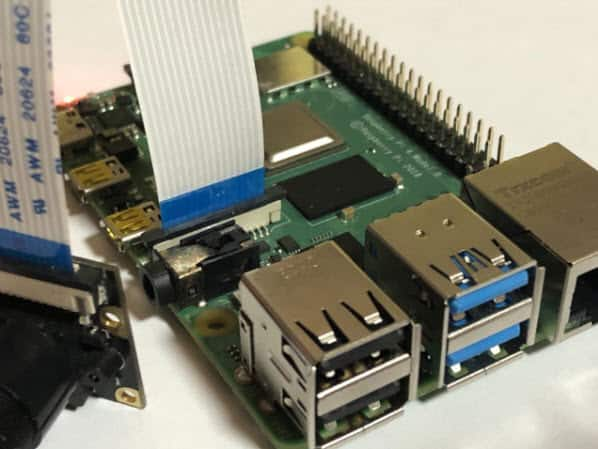
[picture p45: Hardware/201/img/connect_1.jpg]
Connect cable


Connect the camera module while the Raspberry Pi is still powered off. Note that the shiny contacts on the ribbon cable should face away from the USB ports. Then, turn the Raspberry Pi on and launch the Raspberry Pi Software Configuration tool by typing the following command:

```bash
sudo raspi-config
```

In the graphical user interface, choose the fifth option in the list:

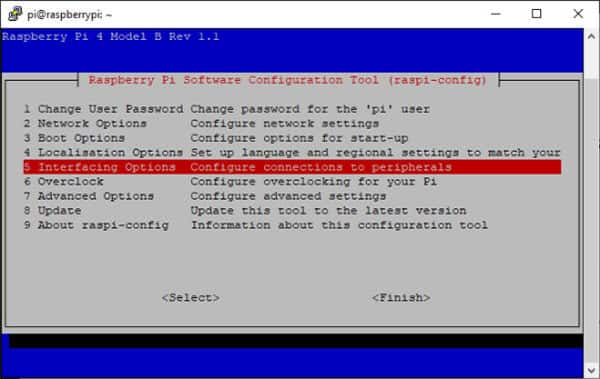
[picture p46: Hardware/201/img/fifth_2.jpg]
Config Menu step one


Then, select the ‘Camera’ option from the list and enable it:

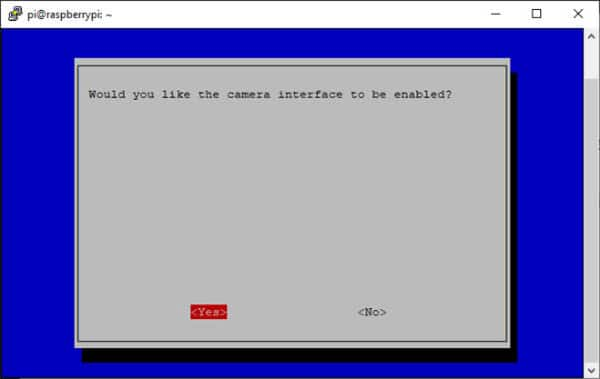
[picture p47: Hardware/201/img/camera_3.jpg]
Confirming


When done, use the tab key in the main menu to select the ‘Finish’ option and then hit the enter key. After a reboot, the Raspberry Pi will be ready to interface with a connected camera module.

Once the computer is finished rebooting, you can check the status of the camera using the following command:

```bash
vcgencmd get_camera
```

If the camera is connected correctly and the Raspberry Pi is configured to use the camera interface, the vcgencmd command should create an output similar to the following image:

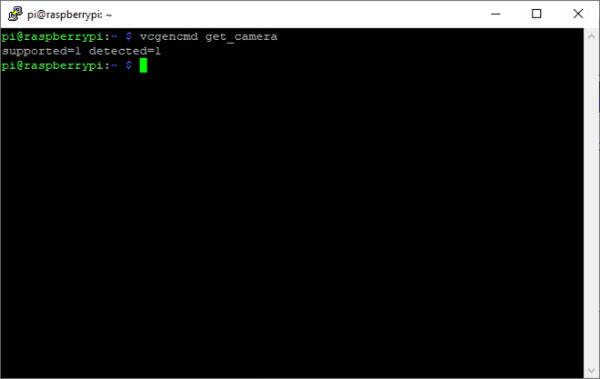
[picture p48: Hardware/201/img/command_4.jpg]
vcgencmd command


You can use the raspistill command to test whether the camera module works as intended:

```bash
raspistill -o image.jpg
```

Note that running this command might take a couple of seconds before it’s done. It should create an image file like this:

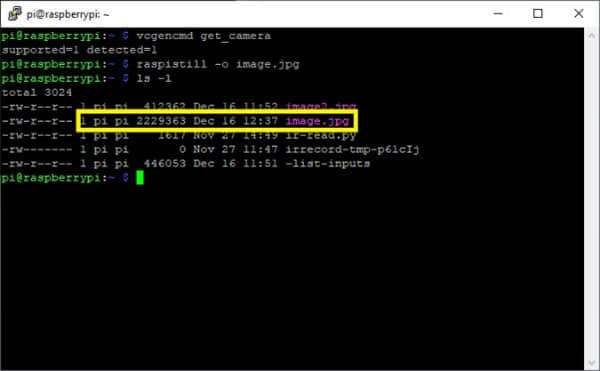
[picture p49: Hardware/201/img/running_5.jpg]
raspi still


#### Utilize a common USB webcam

If buying a new camera module is not feasible for your project, or if a higher resolution, longer cable, or other features are required, it’s possible to connect common USB cameras to the Raspberry Pi and use them instead of a camera module. For that to work, shut down the Raspberry Pi and connect the USB webcam. Then turn the Raspberry Pi back on. The Pi should detect most USB cameras and create a new device.

To test whether the camera works with the Raspberry Pi as intended, you can install a small program named ‘fswebcam’ and create a still image as before:

```bash
sudo apt-get install fswebcam 
fswebcam image.jpg
```
    
Doing so creates a still image in the current folder. Note that it doesn't pose a problem to leave the Raspberry Pi's camera interface enabled when a webcam gets connected via USB. It is also possible to connect multiple USB cameras to the Raspberry Pi and build a home surveillance hub, for example.

Use the following command to take a picture with a specific webcam:

```bash
fswebcam --device /dev/video0 image.jpg
```

This will create a still image with the camera zero and store the result in a file named ‘image.jpg’.

#### Summary

As demonstrated, configuring a Raspberry Pi to interface a connected camera is a straightforward process. Essentially, two common methods exist, and both of them work without much configuration. The first option is to use a Raspberry Pi-compatible camera module. The benefits of this method are the great support, the large variety of different modules, and that most camera-based software for the Raspberry Pi supports the internal camera interface right out of the box. The relatively short cable length of such camera modules can be a disadvantage. USB cameras, on the other hand, usually have a longer cable and reasonable image quality. Support, however, cannot be guaranteed. On a positive note, using this method allows you to connect multiple USB cameras to a single Raspberry Pi, which is especially useful in surveillance applications.

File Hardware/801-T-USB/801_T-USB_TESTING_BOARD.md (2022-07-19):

# 801 T-USB testing board

This testing board hosts the 801 T-USB daughter board.

The 801 is a bridge board that connects daughter boards. 801 T-USB is one such daughter board.

The T-USB daughterboard has three functions
- Supply the system with power
- Provide data signals in the system over two USB-C connectors
- Manage autonomous system functions and waking state

The T-USB board exposes two vertical USB-C sockets and connects to the carrier board through two 50 pin B2B connectors.
These are routed ultimately through two USB-C connectors on the testing board.

The testing board can also be used to test the bridge board. For this purpose there are two plugs on the underside that connect
directly to the sockets on the upperside apart from the VSOM pins.

Ziloo 801 T-USB Board

## Board Components

- 2 * [Hirose DF40-50DS-0.4V](https://www.hirose.com/en/product/p/CL0684-4009-0-51) mated height 1.5mm [Mouser](https://www.mouser.ch/ProductDetail/Hirose-Connector/DF40C-50DS-04V51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) - [JLCPCB socket](https://jlcpcb.com/parts/componentSearch?isSearch=true&searchTxt=DF40C-50DS-0.4V)
- 2 * [HD3SS3220  10-Gbps USB 3.1 Type-C 2:1 mux with DRP Controller](https://www.ti.com/product/HD3SS3220) [Mouser](https://www.mouser.ch/ProductDetail/Texas-Instruments/HD3SS3220IRNHR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)
- 2 * USB-C connectors [DX07S024JA1R1300](https://www.jae.com/en/connectors/series/detail/product/id=66508) or [DX07S024JJ2R1300](https://www.mouser.ch/ProductDetail/JAE-Electronics/DX07S024JJ2R1300?qs=odmYgEirbwyfyaz1Tta0cQ%3D%3D) - [Mouser](https://www.mouser.ch/ProductDetail/JAE-Electronics/DX07S024JA1R1300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) - 
- 3 * [Samtec TSW-116-14-T-S Header 16 pin](https://www.samtec.com/products/tsw-116-14-t-s) - [Mouser](https://www.mouser.ch/ProductDetail/Samtec/TSW-116-14-T-S?qs=iT52DjcXudt%2FVnGGDYuHrA%3D%3D)

### Open notes

Step up voltage 3.5V -> 5V

Testing staged power and data enable when plugging in the module.

Chip enable when plugged in. 100ms delay.

# Testing with the board

## Testing cases 

* Routing UART over breakout connectors
* VSOM load test
* Interrupt triggering
* Requesting system standby
* Detecting system standby
* Triggering system reset
* Detecting system reset
* Powering dev board from T-USB power output
* Simulating CONN_EN signal
* High voltage USB-C (20V / 12V / 9V) power supplies never produces more than 5V SYS_PWR when connected.
* If one USB port receives power (5V) the other port can deliver power (5V).
* VSOM is 3.45V to 4.4V regardless of charger
* If a Apple Dedicated Charger 5V(1A BC1.2) is connected the board can draw 1A
* If a CDP(5V, 1A) compatible charger is connected the board can draw 1A
* If a CDP(5V, 3A) compatible charger is connected the board can draw 3A
* If power is connected to USB the battery can charge
* If no power is connected the system is battery powered
* USB 3.0 data signal can be passed through from T-USB OTG to testing board OTG, and reverse min. 250MB/sec
* USB 3.0 data signal can be passed through from T-USB Host to testing board Host, and reverse min. 250MB/sec
* USB 2.0 data signal can be passed through from T-USB OTG to testing board OTG, and reverse min. 35MB/sec
* USB 2.0 data signal can be passed through from T-USB Host to testing board Host, and reverse min. 35MB/sec
* Power and Data works through T-USB ports with 300 cm cable length.
* USB signal jitter within accepted range (see USB 3.0 Electrical Compliance Methodology)

Sample USB 3.0 data rates

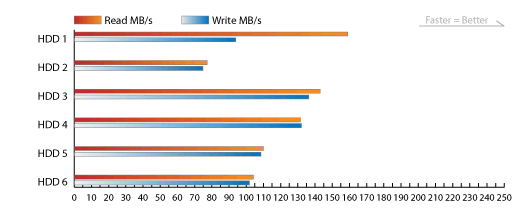
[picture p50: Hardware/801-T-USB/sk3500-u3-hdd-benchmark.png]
Sample rates


USB Testing Matrix

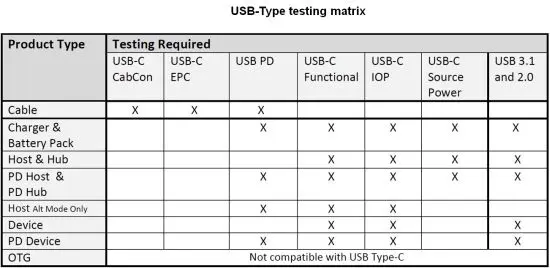
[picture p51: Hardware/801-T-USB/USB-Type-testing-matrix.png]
USB Testing matrix


Ideal testing equipment for USB 3.0 are [Loopback Plugs](https://www.passmark.com/products/usb3loopback/index.php).

Testing articles,

- [What’s new in USB Power Delivery 3.0](https://www.testandmeasurementtips.com/whats-new-in-usb-power-delivery-3-0-faq/)
- [A first look at USB 3.1 performance](https://techreport.com/review/27906/a-first-look-at-usb-3-1-performance/)
- [Here's how fast USB 3.1 is in the real world](https://www.techspot.com/news/59982-here-how-fast-usb-31-real-world.html)

## DIP switches

To test cases a bank of 8 DIP switches allow enabling features

* 4 * CONN_EN high/low/disconnected
* BAT_CE# - Disable or disconnected
* PD_VIN_EN - Enabled or disconnected
* SPI_3V3 - Enable power to SPI memory, connect to LDO_3V3

## LEDs

LEDs will test specific situations and test cases

- Battery STAT (BAT_STAT - BAT_LDO)
- Battery power good (PWR_CHARGE above 4.3V)
- VSOM power on (upper 36..48)
- VSOM voltage >4.5V
- VCC_RTC power on
- Power on Reset POR_B_3P3
- System reset mode
- System powering down
- VSOM_LOCK powered (upper)
- Each of the VSOM corners 1, 1, 26, 26 (upper)

# Connecting the Board

## Signals passed to USB-C connectors

The signals from the USB-C connectors are routed through a Ti HD3SS3220 (x2) to handle polarity of the plug.
The USB 2/3 data lines are connected to the 50 pin connectors on both the upperside and underside.

USB-C wiring

#### Connector 1 high-speed data

| Pin | Code | Type | Details | Voltage |
|-----|---|---|---|---|
| 2 | USB1_RX_DP | USB | USB1 RX D+ | |
| 3 | USB1_RX_DN | USB | USB1 RX D- | |
| 4 | GND | Power | Ground | |
| 5 | USB1_TX_DP | USB | USB1 TX D+ | |
| 6 | USB1_TX_DN | USB | USB1 TX D- | |
| 7 | GND | Power | Ground | |
| 8 | USB1_RX_DP | USB | USB2 RX D+ | |
| 9 | USB1_RX_DN | USB | USB2 RX D- | |
| 10  | GND | Power | Ground | |
| 11  | USB1_TX_DP | USB | USB2 TX D+ | |
| 12  | USB1_TX_DN | USB | USB2 TX D- | |
| 13  | GND | Power | Ground | |

#### Connector 2 PD controller

| Pin | Code | Type | Details | Voltage | Misc |
|-----|---|---|---|---|---|
| 3 | USB1_DP | USB | USB1 D+ | | |
| 4 | USB1_DN | USB | USB1 D- | | |
| 5 | GND | Power | Ground | | |
| 6 | USB2_DP | USB | USB2 D+ | | |
| 7 | USB2_DN | USB | USB2 D- | | |
| 8 | GND | Power | Ground | | |

## Underside 50 pin plugs VSOM connection

This connector enables the underside to be connected to a bridge board and be supplied with VSOM 
on different pins than what is received from the module connected on the upperside.
These pins are not connected to the upperside.

Under Power (10 pins)

| Pin | Code | Type | Details | Voltage | Misc |
|-----|---|---|---|---|---|
| 1 | C1_VSOM_1 | Enable | Corner VSOM pin | 3.45V - 4.5V | |
| 1 | C2_VSOM_1 | Enable | Corner VSOM pin | 3.45V - 4.5V | |
| 26  | C1_VSOM_26 | Enable | Corner VSOM pin | 3.45V - 4.5V | |
| 26  | C2_VSOM_26 | Enable | Corner VSOM pin | 3.45V - 4.5V | |
| 11  | BOTH_VSOM | Enable | Signal from bridge board that VSOM is connected on both sides | 3.45V - 4.5V ? | |
| 15  | VSOM_LOCK | Power | Main power for board, if mechanical lock shorted | 3.45V - 4.5V | Mech. lock |
| 21  | PWRBTN | Boot | Power button trigger | | |
| 48  | C1_VSOM | Power | C1 power (36, 39, 42, 45) | 3.45V - 4.5V |
| 49  | GND | Power | Ground | |
| 49  | GND | Power | Ground | |

## Upperside 50 pin sockets VSOM connection

These pins are from both 50 pins connectors reflecting the connector VSOM pins (10 pins)
The breakout enables testing partial connection of the sockets.
These are not connected to the underside.

Upper Power (10 pins)

| Pin | Code | Type | Details | Voltage | Misc |
|-----|---|---|---|---|---|
| 1 | C1_VSOM_1 | Enable | Corner VSOM pin | 3.45V - 4.5V | |
| 1 | C2_VSOM_1 | Enable | Corner VSOM pin | 3.45V - 4.5V | |
| 26  | C1_VSOM_26 | Enable | Corner VSOM pin | 3.45V - 4.5V | |
| 26  | C2_VSOM_26 | Enable | Corner VSOM pin | 3.45V - 4.5V | |
| 11  | BOTH_VSOM | Enable | Signal from bridge board that VSOM is connected on both sides | 3.45V - 4.5V ? | |
| 15  | VSOM_LOCK | Power | Main power for board, if mechanical lock shorted | 3.45V - 4.5V | Mech. lock |
| 21  | PWRBTN | Boot | Power button trigger | | |
| 48  | C1_VSOM | Power | C1 power (36, 39, 42, 45) | 3.45V - 4.5V |
| 49  | GND | Power | Ground | |
| 49  | GND | Power | Ground | |

## Signals for two 50 pin connectors from dev board (9 + 10 + 5 pins)

50 pins for PD Controller -> Dev Board P20 (9 pins)

| Pin | Code | Type | Details | Voltage |  Misc |
|-----|---|---|---|---|---|
| 48  | UART1_TXD  | UART | P1.72 UART1 Tx | | P20.9 |
| 47  | UART1_RXD  | UART | P1.19 UART1 Rx | | P20.11  |
| 46  | UART2_TXD  | UART | UART2 Tx | | P20.1 |
| 45  | UART2_RXD  | UART | UART2 Rx | | P20.3 |
| 44  | UART3_TXD  | UART | P1.61 UART3 Tx | | P20.2 |
| 43  | UART3_RXD  | UART | P1.21 UART3 Rx | | P20.4 |
| 42  | UART4_TXD  | UART | UART4 Tx | | P20.8 |
| 41  | UART4_RXD  | UART | UART4 Rx | | P20.10  |
| | GND | Power | Ground | | |

50 pins for PD Controller / Data -> Dev Board P21 + direct connects (10 pins (was 8))

| Pin | Code | Type | Details | Voltage |  Misc |
|-----|---|---|---|---|---|
| 36  | NIGHT SCL | I2C | I2C6 SCL | | P21.2 | GP19 I2C1. |
| 35  | NIGHT SDA | I2C | I2C6 SDA | | P21.4 | GP18 I2C1. |
| 18  | SYS I2C SCL | I2C | | | P21.7 | GP15 I2C1.  |
| 19  | SYS I2C SDA | I2C | | | P21.5 | GP14 I2C1.  |
| 12  | EX0_nINT | IRQ | Interrupt signal (GPIO4_IO19) | | P21.30  |
| 20  | VCC_RTC | Power | Low power mode supply | 1.8V | |
| 21  | PWRBTN | Boot | Power button trigger | | |
| 22  | ALT_BOOT | Boot | Alternate boot | | |
| 23  |QSPI_BOOT_EN_3P3| Boot | SPI boot | |  P21.18 |
| | GND | Power | Ground | | |
| 32  | CAN_RX | | CAN1_RX | | P21.12 |
| 31  | CAN_TX | | CAN1_TX | | P21.14 |

50 pins for PD Controller -> Dev Board P10 (5 pins)

| Pin | Code | Type | Details | Voltage |  Misc |
|-----|---|---|---|---|---|
| 16  | SYS_RST_PMIC | Reset | PMIC reset input pin. Internally pulled up with LDO1 power rail. Once low, PMIC performs reset. | | P10.9 |
| 17  | POR_B_3P3 | Reset | Power On reset output pin. Open drain output requiring external pull up resistor. | | P10.7 |
| 18  | PMIC_ON_REQ | Reset | PMIC ON input from Application processor. When high, the device starts power on sequence. | | P10.5 |
| 19  | PMIC_STBY_REQ  | Reset | Standby mode input from Application processor. When high, device enters STANDBY mode. | | P10.3  |
| | GND | Power | Ground | | |

## Breakout of Charging / Data Signals

From 50 pins for PD Controller -> programming (8 pins)

| Pin | Code | Type | Details | Voltage |  Misc |
|-----|---|---|---|---|---|
| 9 | SWD_CLK | Debug | PD Controller GPIO12 | | |
| 10  | SWD_DAT | Debug | PD Controller GPIO13 | | |
| 50  | PD_HRESET | PD | PD Controller HRESET (High) | | |
| | GND | Power | Ground | |
| 21  | SWD CLK RP | RP2040 | | |
| 23  | SWD DAT RP | RP2040 | | |
| 28  | UART_RP_TXD| Debug | | | | GP0. |
| 27  | UART_RP_RXD| Debug | | | | GP1 |

From 50 pins for PD Controller / Data -> Charging power (9 pins)

| Pin | Code | Type | Details | Voltage |  Misc |
|-----|---|---|---|---|---|
| 24  | BAT_CE# | Charger  | Charge Enable Active-Low Input. Connect to a high logic level to place the battery charger in standby mode. | | | 
| 24  | PWR_CHARGE | Power | Internal charging power | |
| 25  | PD_VIN_EN | | Enable VIN_5V/3V3 from PWR_SYS (TBD) | | |
| 29  | VIN_3V3 | | Supply for TPS64988 circuitry and I/O. Current 50 mA | 3.3V |
| 34  | SPI_3V3 | Power | Power to the flash chip. Bridge connects to VIN_3V3 | 3.3V |
| 28  | VIN_5V | Power | System 5V power source (PPHV1, PPHV2, PP1_CABLE, PP2_CABLE). 500 mA. | 5V |
| 24  | PWR_CHARGE | Battery  | Internal charge current for testing  | |
| 25  | BAT_STAT | Battery  | Internal charging status for testing | |
| | GND | Power | Ground | |

From 50 pins -> Assorted Data (7 pins)

| Pin | Code | Type | Details | Voltage |  Misc |
|-----|---|---|---|---|---|
| 33  | SPI_CS | RP2040 | RP SPI | 3.3V | | GP29 SPI1 |
| 32  | SPI_CLK | PD | RP SPI | 3.3V | | GP26 SPI |
| 31  | SPI_MISO | RP2040 | RP SPI | 3.3V | | GP28 SPI |
| 30  | SPI_MOSI | RP2040 | RP SPI | 3.3V | | GP27 SPI |
| 17  | STEM SCL | I2C | STEM SCL | | | GP17 I2C0 |
| 18  | STEM SDA | I2C | STEM SDA | | | GP16 I2C0 |
| 19  | STEM INT | I2C | Sensor interrupts | |

## Signals **NOT** connected on 50 pin connectors

These signal pins are however connected between the upperside and underside.

| Pin | Code | Type | Details | Voltage |
|-----|---|---|---|---|
| 50  | LVCLK+ | LVDS | LVDS CLK+ | |
| 49  | LVCLK- | LVDS | LVDS CLK- | |
| 47  | LVD0+ | LVDS | LVDS D0+ | |
| 46  | LVD0- | LVDS | LVDS D0- | |
| 44  | LVD1+ | LVDS | LVDS D1+ | |
| 43  | LVD1- | LVDS | LVDS D1- | |
| 41  | LVD2+ | LVDS | LVDS D2+ | |
| 40  | LVD2- | LVDS | LVDS D2- | |
| 38  | LVD3+ | LVDS | LVDS D3+ | |
| 37  | LVD3- | LVDS | LVDS D3- | |

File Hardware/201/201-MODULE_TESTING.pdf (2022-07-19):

201-MODULE_TESTING.md | 7/13/2022

# Camera module breakout board

The aim is to create a batch of 10 breakout PCBs for testing and connecting the camera module via a Raspberry Pi connector.

The board has a 34 pin socket for connecting a 201 camera module. This is connected and voltage shifted where needed to a Raspberry Pi Zero 22 pin connector and a RPi 15 pin connector for connecting to a RPi compatible dev board.

Additionally there should be a 30 pin IPEX connector for connecting to the UCM Compulab board.

Regular 1/100” header pins are broken out for I2C, I2S and other signal pins. It should be possible to connect with 1v8 and 3v3 signals. Add header pins for power as well.

Note: Perhaps it makes no sense to have a 22 pin connector since the Raspberry Pi standard is 15 pins on the camera module side. Consider dropping this connector.

## Verification of modules

The aim is to verify and validate the viability of the supplied camera modules. You will get two day time and two night time modules and assorted lenses. I will also send you a dev board.

Test that the camera registers can be accessed with I2S
Test that the laser range and ambient light can be accessed with I2S
Test that camera sensor can be read using CSI2
Test that microphone can be read using I2S

## Testing lenses

The supplied lenses are of various types, the aim is to evaluate the various lenses on the dimensions of,

Image quality
How close an object can be to the camera and remain mostly in focus
How far away can a 5cm x 5cm toy be in a picture and remain recognizable
How far off center can an object or person be and be in view

At the completion of the project you will return the supplied development board, camera modules, lenses and produced test boards.

## Testing Setups

The test board is used to test Camera Modules. Development boards that may be used to test are,

I-Pi SMARC IMX8M Plus (https://www.ipi.wiki/products/i-pi-smarcplus-imx8mp)
Compulab SB-UCM-iMX8PLUS (https://www.compulab.com/products/carrier-boards/sb-ucmimx8plus-carrier-board/)
Raspberry Pi CM 4 IO Board B (https://www.waveshare.com/product/raspberry-pi/boards-kits/compute-module-4-cat/cm4-io-base-acce-b.htm)
Tinker Edge R (https://tinker-board.asus.com/product/tinker-edge-r.html) for testing.

## Price / Milestones

Price $1500 plus cost of board production

Milestones 300 Testing board design completed with design files 150 + cost, produce test boards 600 verification of camera modules 150 testing lenses 300 boards, modules, lenses are returned

# Connectors

1 * RPi compatible TE Connectivity 15pin 1mm FPC 1-84952-5 (https://www.te.com/usa-en/product-1-84952-5.html) 1 * Molex 22PIN 0.5mm pitch 54548-2271 (https://www.molex.com/molex/products/part-detail/ffc_fpc_connectors/0545482271)
1 * I-PEX 30PIN 0.4mm pitch 20525-030E-02 (https://www.i-pex.com/product/cabline-ca)
1 * Hirose DF40C-34DS-0.4V (https://www.hirose.com/en/product/p/CL0684-4023-0-51) (Mouser) (https://www.mouser.ch/ProductDetail/Hirose-Connector/DF40C-34DS-04V51?qs=vcbW%252B4%252BSTIpg26DsEbj1iQ%3D%3D)

## Pinouts: Hirose DF40 single eye connector 34 pins

Just to be clear: All CSI lanes are laid out on one side of the connector with GND between.


Pin 1 is indicated on the board by a dot.

Toward thin part with microphone and other sensors

Pin | Code | Type | Details | Voltage
1 | AF_VDD | Power | Reserved for Autofocus | 3.3V
2 | AVDD_2V8 | Power | Analog, Max 500mA | 2.8V
3 | DOVDD | Power | Power for I/O circuit, Max 500mA | 1.8V
4 | VCC_1V8 | Power | 1.8V ,MAX 200mA | 1.8V
5 | GND | Power | GND
6 | CAM_FSIN | I/O | Frame sync input
7 | CAM_STROBE I/O | Frame sync output
8 | EXTCLK | Input | External Clock Input (MCLK)
9 | ATT_INT | Output | Interrupt Attached Sensor, Active L | 1.8V?
10 | ATT_XSHUT | Input | Attached Sensor XSHUTDOWN | 1.8V
11 | Reserved | AF/PWM PWM Motor control (NC)
12 | I2C_SCL | I/O | I2C?_SCL(pullup resistor 2.2K) | 1.8V
13 | I2C_SDA | I/O | I2C?_SDA(pullup resistor 2.2K) | 1.8V
14 | BCLK / SCK | I2S | Bit clock line | 1.8V
15 | WS / LRCLK | I2S | Word clock line | 1.8V
16 | SDATA1 | I2S | Input data 1 | 1.8V
17 | SDATA2 | I2S | Input data 2 (NC) | 1.8V

Towards image sensors

Pin | Code | Type | Details | Voltage
34 | AGND | Power | Analog ground
33 | RESET | Input | Camera Reset, Active Low (RSTB)
32 | PWRDN | Input | Camera Power Down
31 | Reserved
30 | Reserved
29 | - | | GND
28 | CSI_RX_D0P | Camera | MIPI_CSI_RX_D0+ | 1.8V
27 | CSI_RX_D0N | Camera | MIPI_CSI_RX_D0- | 1.8V
26 | - | | GND

Pin | Code | Type | Details | Voltage
25 | CSI_RX_D1P | Camera | MIPI_CSI_RX_D1+ | 1.8V
24 | CSI_RX_D1N | Camera | MIPI_CSI_RX_D1- | 1.8V
23 | - | | GND
22 | CSI_RX_D2P | Camera | MIPI_CSI_RX_D2+ | 1.8V
21 | CSI_RX_D2N | Camera | MIPI_CSI_RX_D2- | 1.8V
20 | - | | GND
19 | CSI_RX_CLKP | Camera | MIPI_CSI_RX_CLK+ | 1.8V
18 | CSI_RX_CLKN | Camera | MIPI_CSI_RX_CLK- | 1.8V

## NVIDIA FPC 30 pins

The connector is an I-PEX type 20525-030E-02 (https://www.i-pex.com/product/cabline-ca) with 0.4mm pitch & 30 pins. Data pins are 1.8V level.

Pin | Code | Details
1 | CAM_3V3 | 3.3V Power Input
2 | CAM_3V3
3 | CAM_1V8 | 1.8V Power Input
4 | GND
5 | GND
6 | PWR DWN | PWRDN on 34pin
7 | I2C SCL
8 | I2C SDA
9 | GND
10 | CSI D2-
11 | CSI D2+
12 | TRIGGER
13 | MCLK | EXTCLK on 34pin
14 | Reserved
15 | CSI D1-
16 | CSI D1+
17 | GND
18 | GND

Pin | Code | Details
19 | CSI D0-
20 | CSI D0+
21 | RESET | RESET on 34pin
22 | GND
23 | Reserved
24 | CSI CLK-
25 | CSI CLK+
26 | GND
27 | CSI D3-
28 | CSI D3+
29 | Flash
30 | Reserved

Refs

https://www.leopardimaging.com/product/accessories/cables/faw-1233-03/https://www.mouser.com/datasheet/2/233/LI-TX1-CB-6CAM_datasheet-1395894.pdfhttps://connecttech.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

## RPI FPC 22 pins

Pin | Code | Type | Details | Voltage
1 | GND | Power | Ground
2 | CAM_D0_N | Data | MIPI Data Lane 0 Negative
3 | CAM_D0_P | Data | MIPI Data Lane 0 Positive
4 | GND | Power | Ground
5 | CAM_D1_N | Data | MIPI Data Lane 1 Negative
6 | CAM_D1_P | Data | MIPI Data Lane 1 Positive
7 | GND | Power | Ground
8 | CAM_CK_N | Data | MIPI Clock Lane Negative
9 | CAM_CK_P | Data | MIPI Clock Lane Positive
10 | GND | Power | Ground
11 | CAM_D2_N | Data | MIPI Data Lane 2 Negative

Pin | Code | Type | Details | Voltage
12 | CAM_D2_P | Data | MIPI Data Lane 2 Positive
13 | GND | Power | Ground
14 | CAM_D3_N | Data | MIPI Data Lane 3 Negative
15 | CAM_D3_P | Data | MIPI Data Lane 3 Positive
16 | GND | Power | Ground
17 | CAM_IO0 | Power | Power Enable
18 | CAM_IO1 | LED | LED Indicator
19 | GND | Power | Ground
20 | SCL | I2C | I2C SCL
21 | SDA | I2C | SCCB serial Interface data IO
22 | VCC | Power | 3.3V Power Supply

## RPI FPC 15 pins

Pin | Code | Type | Details | Voltage
1 | GND | Power | Ground
2 | CAM_D0_N | Data | MIPI Data Lane 0 Negative
3 | CAM_D0_P | Data | MIPI Data Lane 0 Positive
4 | GND | Power | Ground
5 | CAM_D1_N | Data | MIPI Data Lane 1 Negative
6 | CAM_D1_P | Data | MIPI Data Lane 1 Positive
7 | GND | Power | Ground
8 | CAM_CK_N | Data | MIPI Clock Lane Negative
9 | CAM_CK_P | Data | MIPI Clock Lane Positive
10 | GND | Power | Ground
11 | CAM_IO0 | Power | Power Enable
12 | CAM_IO1 | LED | LED Indicator
13 | SCL | I2C | I2C SCL
14 | SDA | I2C | SCCB serial Interface data IO
15 | CAM_3V3 | Power | 3.3V Power Supply

ArduCam description for connector. (https://www.arducam.com/raspberry-pi-camera-pinout/) ArduCam uses FCI connector SFW15R-2STE1LF. (https://www.arducam.com/downloads/SFW15R-2STE1LF.pdf)


## Connecting Raspberry Pi to camera module

Using a supported camera module together with a Raspberry Pi is the most straightforward way of adding visual input to a project. The only thing needed is a supported camera module such as the official Raspberry Pi camera module. However, many alternative modules exist: for example, this breakout board with a night-vision camera and infrared LEDs.

Regardless of the chosen camera, the setup process always works similarly, as long as the camera is supported by the Raspberry Pi. First, plug the ribbon connector of the camera module into the connector on the Raspberry Pi. The white connector closer to the USB and Ethernet ports is the one for the camera. The other port, located on the other side of the single-board computer, is meant for connecting a display.


Connect the camera module while the Raspberry Pi is still powered off. Note that the shiny contacts on the ribbon cable should face away from the USB ports. Then, turn the Raspberry Pi on and launch the Raspberry Pi Software Configuration tool by typing the following command:

In the graphical user interface, choose the fifth option in the list:


Then, select the ‘Cameraʼ option from the list and enable it:

When done, use the tab key in the main menu to select the ‘Finishʼ option and then hit the enter key. After a reboot, the Raspberry Pi will be ready to interface with a connected camera module.

Once the computer is finished rebooting, you can check the status of the camera using the following command:

vcgencmd get_camera


If the camera is connected correctly and the Raspberry Pi is configured to use the camera interface, the vcgencmd command should create an output similar to the following image:

You can use the raspistill command to test whether the camera module works as intended:

raspistill -o image.jpg

Note that running this command might take a couple of seconds before itʼs done. It should create an image file like this:

Utilize a common USB webcam

If buying a new camera module is not feasible for your project, or if a higher resolution, longer cable, or other features are required, itʼs possible to connect common USB cameras to the Raspberry Pi and use them instead of a camera module. For that to work, shut down the Raspberry Pi and connect the USB webcam. Then turn the Raspberry Pi back on. The Pi should detect most USB cameras and create a new device.

To test whether the camera works with the Raspberry Pi as intended, you can install a small program named ‘fswebcamʼ and create a still image as before:

sudo apt-get install fswebcam
fswebcam image.jpg

Doing so creates a still image in the current folder. Note that it doesn't pose a problem to leave the Raspberry Pi's camera interface enabled when a webcam gets connected via USB. It is also possible to connect multiple USB cameras to the Raspberry Pi and build a home surveillance hub, for example.

Use the following command to take a picture with a specific webcam:

fswebcam --device /dev/video0 image.jpg

This will create a still image with the camera zero and store the result in a file named ‘image.jpgʼ.

Summary

As demonstrated, configuring a Raspberry Pi to interface a connected camera is a straightforward process. Essentially, two common methods exist, and both of them work without much configuration. The first option is to use a Raspberry Pi-compatible camera module. The benefits of this method are the great support, the large variety of different modules, and that most camera-based software for the Raspberry Pi supports the internal camera interface right out of the box. The relatively short cable length of such camera modules can be a disadvantage. USB cameras, on the other hand, usually have a longer cable and reasonable image quality. Support, however, cannot be guaranteed. On a positive note, using this method allows you to connect multiple USB cameras to a single Raspberry Pi, which is especially useful in surveillance applications.

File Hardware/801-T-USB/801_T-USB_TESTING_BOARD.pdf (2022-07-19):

801_T-USB_TESTING_BOARD.md | 6/15/2022

# 801 T-USB testing board

This testing board hosts the 801 T-USB daughter board.

The 801 is a bridge board that connects daughter boards. 801 T-USB is one such daughter board.

The T-USB daughterboard has three functions

Supply the system with power
Provide data signals in the system over two USB-C connectors
Manage autonomous system functions and waking state

The T-USB board exposes two vertical USB-C sockets and connects to the carrier board through two 50 pin B2B connectors. These are routed ultimately through two USB-C connectors on the testing board.

The testing board can also be used to test the bridge board. For this purpose there are two plugs on the underside that connect directly to the sockets on the upperside apart from the VSOM pins.


## Board Components

2 * Hirose DF40-50DS-0.4V (https://www.hirose.com/en/product/p/CL0684-4009-0-51) mated height 1.5mm Mouser (https://www.mouser.ch/ProductDetail/Hirose-Connector/DF40C-50DS-04V51) - JLCPCB socket (https://jlcpcb.com/parts/componentSearch?isSearch=true&searchTxt=DF40C-50DS-0.4V)
2 * HD3SS3220 10-Gbps USB 3.1 Type-C 21 mux with DRP Controller (https://www.ti.com/product/HD3SS3220) Mouser (https://www.mouser.ch/ProductDetail/Texas-Instruments/HD3SS3220IRNHR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) 2 * USB-C connectors DX07S024JA1R1300 (https://www.jae.com/en/connectors/series/detail/product/id=66508) or DX07S024JJ2R1300 (https://www.mouser.ch/ProductDetail/JAE-Electronics/DX07S024JJ2R1300?qs=odmYgEirbwyfyaz1Tta0cQ%3D%3D) - Mouser (https://www.mouser.ch/ProductDetail/JAE-Electronics/DX07S024JA1R1300) -3 * Samtec TSW-116-14-T-S Header 16 pin (https://www.samtec.com/products/tsw-116-14-t-s) - Mouser (https://www.mouser.ch/ProductDetail/Samtec/TSW-116-14-T-S?qs=iT52DjcXudt%2FVnGGDYuHrA%3D%3D)

Open notes

Step up voltage 3.5V -> 5V

Testing staged power and data enable when plugging in the module.

Chip enable when plugged in. 100ms delay.

# Testing with the board

## Testing cases

Routing UART over breakout connectors VSOM load test
Interrupt triggering
Requesting system standby
Detecting system standby
Triggering system reset
Detecting system reset
Powering dev board from T-USB power output
Simulating CONN_EN signal
High voltage USB-C (20V / 12V / 9V) power supplies never produces more than 5V SYS_PWR when connected.
If one USB port receives power (5V) the other port can deliver power (5V).
VSOM is 3.45V to 4.4V regardless of charger
If a Apple Dedicated Charger 5V(1A BC1.2) is connected the board can draw 1A If a CDP(5V, 1A) compatible charger is connected the board can draw 1A
If a CDP(5V, 3A) compatible charger is connected the board can draw 3A
If power is connected to USB the battery can charge
If no power is connected the system is battery powered
USB 3.0 data signal can be passed through from T-USB OTG to testing board OTG, and reverse min. 250MB/sec
USB 3.0 data signal can be passed through from T-USB Host to testing board Host, and reverse min. 250MB/sec
USB 2.0 data signal can be passed through from T-USB OTG to testing board OTG, and reverse min. 35MB/sec
USB 2.0 data signal can be passed through from T-USB Host to testing board Host, and reverse min. 35MB/sec
Power and Data works through T-USB ports with 300 cm cable length.
USB signal jitter within accepted range (see USB 3.0 Electrical Compliance Methodology)

Sample USB 3.0 data rates


USB Testing Matrix


Ideal testing equipment for USB 3.0 are Loopback Plugs. (https://www.passmark.com/products/usb3loopback/index.php)

Testing articles,

Whatʼs new in USB Power Delivery 3.0 (https://www.testandmeasurementtips.com/whats-new-in-usb-power-delivery-3-0-faq/)
A first look at USB 3.1 performance (https://techreport.com/review/27906/a-first-look-at-usb-3-1-performance/) Here's how fast USB 3.1 is in the real world (https://www.techspot.com/news/59982-here-how-fast-usb-31-real-world.html)

## DIP switches

To test cases a bank of 8 DIP switches allow enabling features

4 * CONN_EN high/low/disconnected
BAT_CE# - Disable or disconnected
PD_VIN_EN - Enabled or disconnected
SPI_3V3 - Enable power to SPI memory, connect to LDO_3V3

## LEDs

LEDs will test specific situations and test cases

Battery STAT (BAT_STAT - BAT_LDO)

# Connecting the Board

Pin; Code; Type; Details; Voltage; USB1_RX_DP; USB; USB1 RX D+; USB1_RX_DN; USB1 RX D-; GND; Power; Ground; USB1_TX_DP; USB1 TX D+; USB1_TX_DN; USB1 TX D-; USB2 RX D+; USB2 RX D-; USB2 TX D+

Battery power good (PWR_CHARGE above 4.3V)
VSOM power on (upper 36..48)
VSOM voltage >4.5V
VCC_RTC power on
Power on Reset POR_B_3P3
System reset mode
System powering down
VSOM_LOCK powered (upper)
Each of the VSOM corners 1, 1, 26, 26 (upper)

Signals passed to USB-C connectors

The signals from the USB-C connectors are routed through a Ti HD3SS3220 (x2) to handle polarity of the
plug. The USB 2/3 data lines are connected to the 50 pin connectors on both the upperside and underside.

Connector 1 high-speed data

Pin | Code | Type | Details | Voltage
12 | USB1_TX_DN | USB | USB2 TX D-
13 | GND | Power | Ground

Connector 2 PD controller

Pin | Code | Type | Details | Voltage | Misc
3 | USB1_DP | USB | USB1 D+
4 | USB1_DN | USB | USB1 D-
5 | GND | Power | Ground
6 | USB2_DP | USB | USB2 D+
7 | USB2_DN | USB | USB2 D-
8 | GND | Power | Ground

## Underside 50 pin plugs VSOM connection

This connector enables the underside to be connected to a bridge board and be supplied with VSOM on different pins than what is received from the module connected on the upperside. These pins are not connected to the upperside.

Under Power (10 pins)

Pin | Code | Type | Details | Voltage | Misc
1 | C1_VSOM_1 | Enable | Corner VSOM pin

3.45V -
4.5V
1 | C2_VSOM_1 | Enable | Corner VSOM pin

3.45V -
4.5V
26 | C1_VSOM_26 | Enable | Corner VSOM pin

3.45V -
4.5V
26 | C2_VSOM_26 | Enable | Corner VSOM pin

3.45V -
4.5V
11 | BOTH_VSOM | Enable

Signal from bridge board that VSOM is connected on both sides

3.45V -
4.5V ?
15 | VSOM_LOCK | Power

Main power for board, if mechanical lock shorted

3.45V -
4.5V

Mech.
lock
21 | PWRBTN | Boot | Power button trigger
48 | C1_VSOM | Power | C1 power (36, 39, 42, 45)

3.45V -
4.5V

Pin | Code | Type | Details | Voltage | Misc
49 | GND | Power | Ground
49 | GND | Power | Ground

## Upperside 50 pin sockets VSOM connection

These pins are from both 50 pins connectors reflecting the connector VSOM pins (10 pins) The breakout enables testing partial connection of the sockets. These are not connected to the underside.

Upper Power (10 pins)

Pin | Code | Type | Details | Voltage | Misc
1 | C1_VSOM_1 | Enable | Corner VSOM pin

3.45V -
4.5V
1 | C2_VSOM_1 | Enable | Corner VSOM pin

3.45V -
4.5V
26 | C1_VSOM_26 | Enable | Corner VSOM pin

3.45V -
4.5V
26 | C2_VSOM_26 | Enable | Corner VSOM pin

3.45V -
4.5V
11 | BOTH_VSOM | Enable

Signal from bridge board that VSOM is connected on both sides

3.45V -
4.5V ?
15 | VSOM_LOCK | Power

Main power for board, if mechanical lock shorted

3.45V -
4.5V

Mech.
lock
21 | PWRBTN | Boot | Power button trigger
48 | C1_VSOM | Power | C1 power (36, 39, 42, 45)

3.45V -
4.5V
49 | GND | Power | Ground
49 | GND | Power | Ground
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

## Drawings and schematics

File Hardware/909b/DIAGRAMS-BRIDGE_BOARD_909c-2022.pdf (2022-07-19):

# Power Supply1

# Power_LED

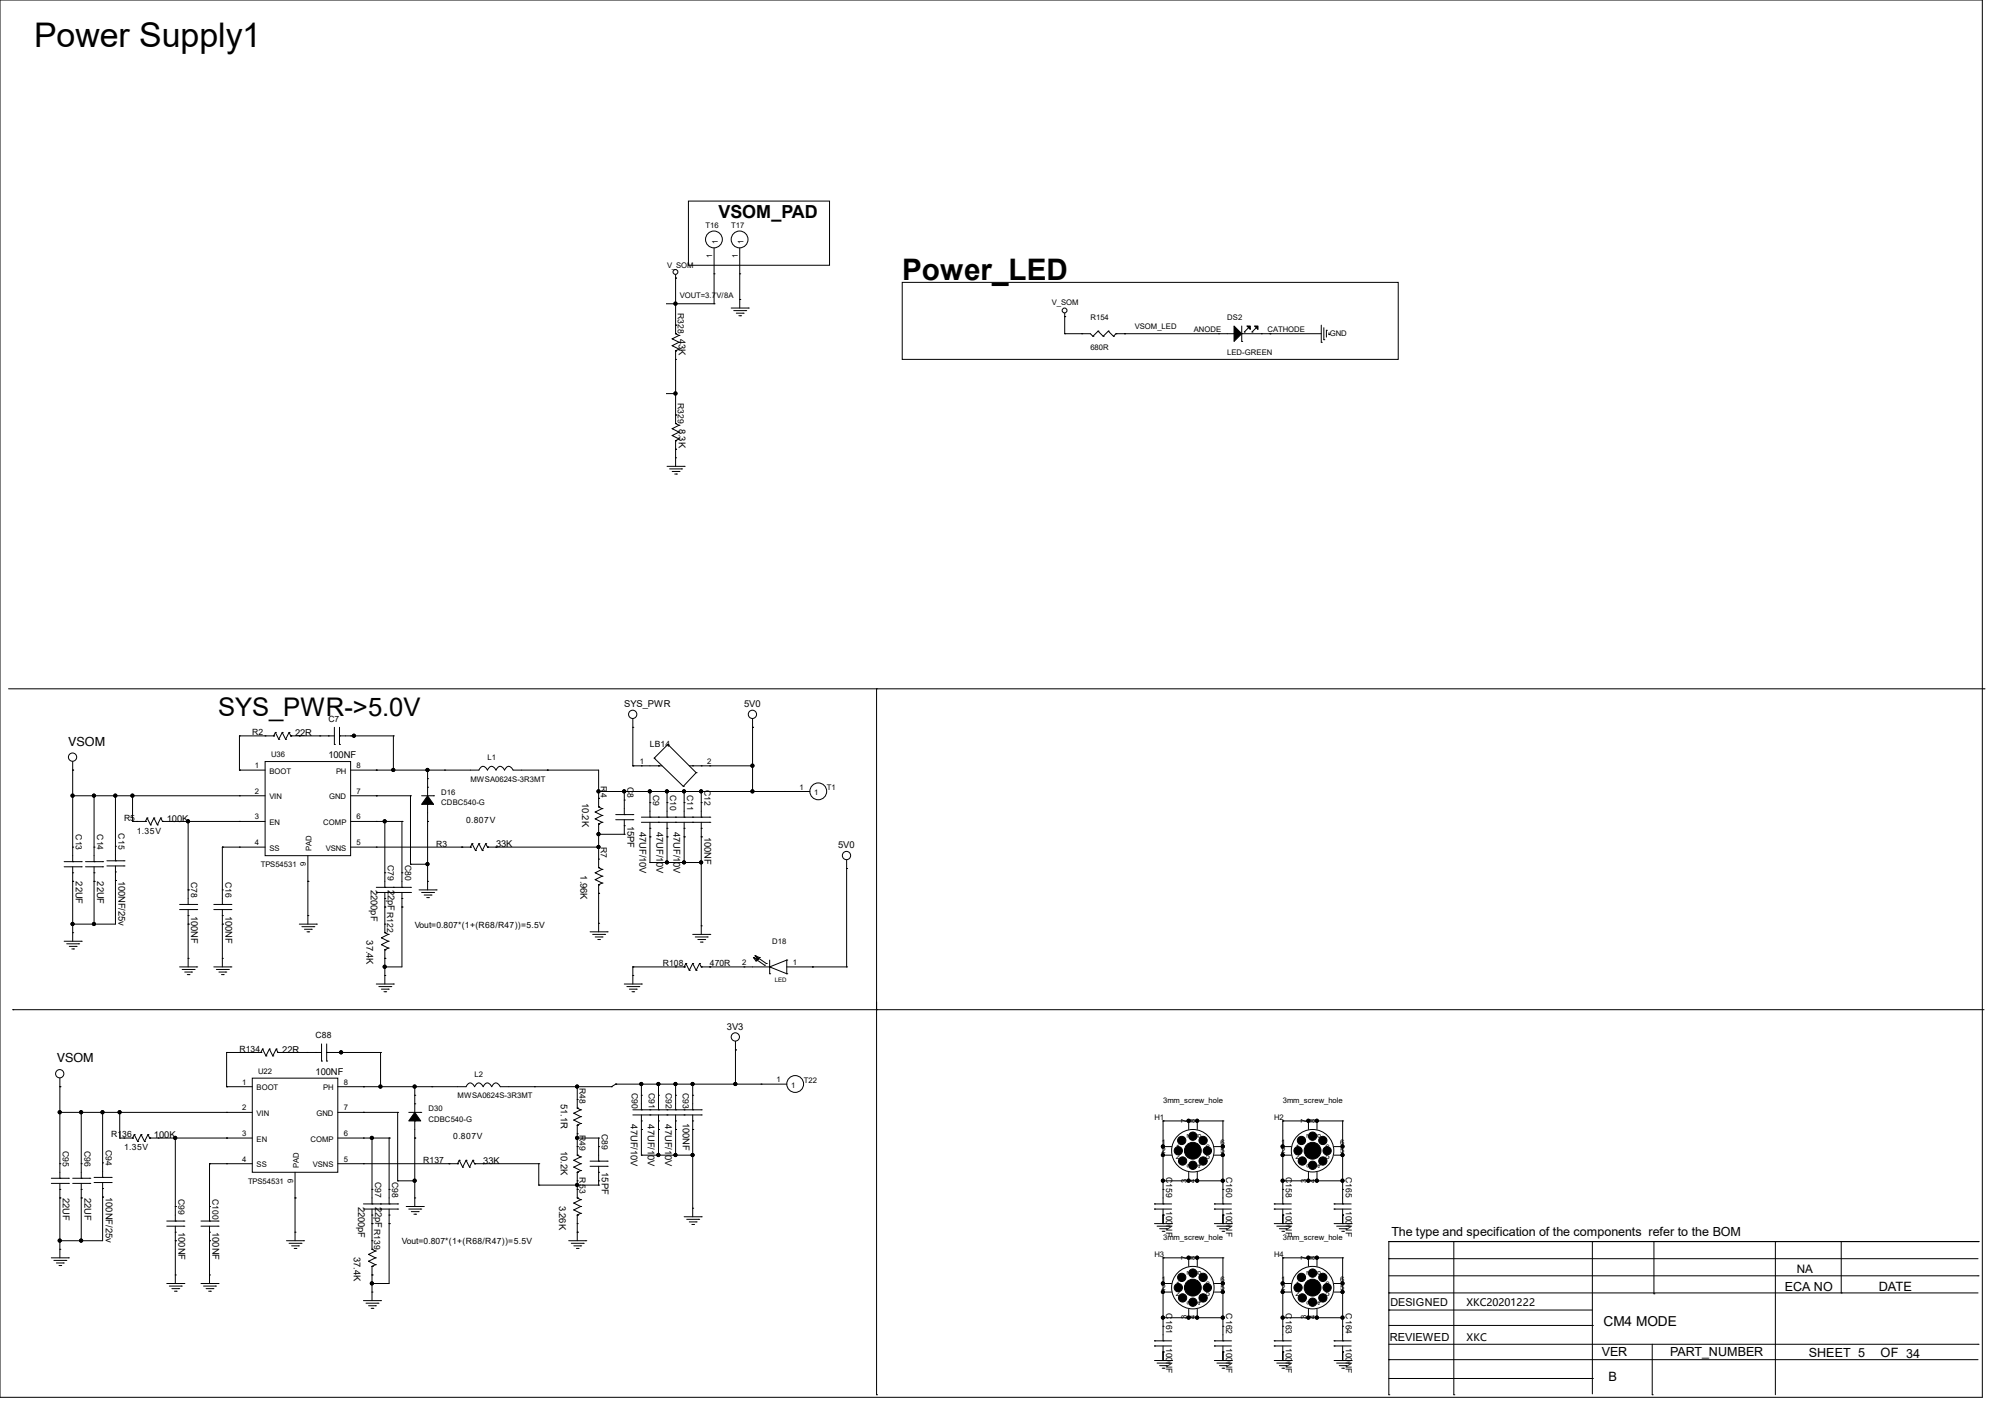
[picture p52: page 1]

The type and specification of the components refer to the BOM

ECA NO | DATE

DESIGNED | XKC20201222 | CM4 MODE

REVIEWED | XKC

VER | PART_NUMBER | SHEET 5 OF 34

# Power Supply2

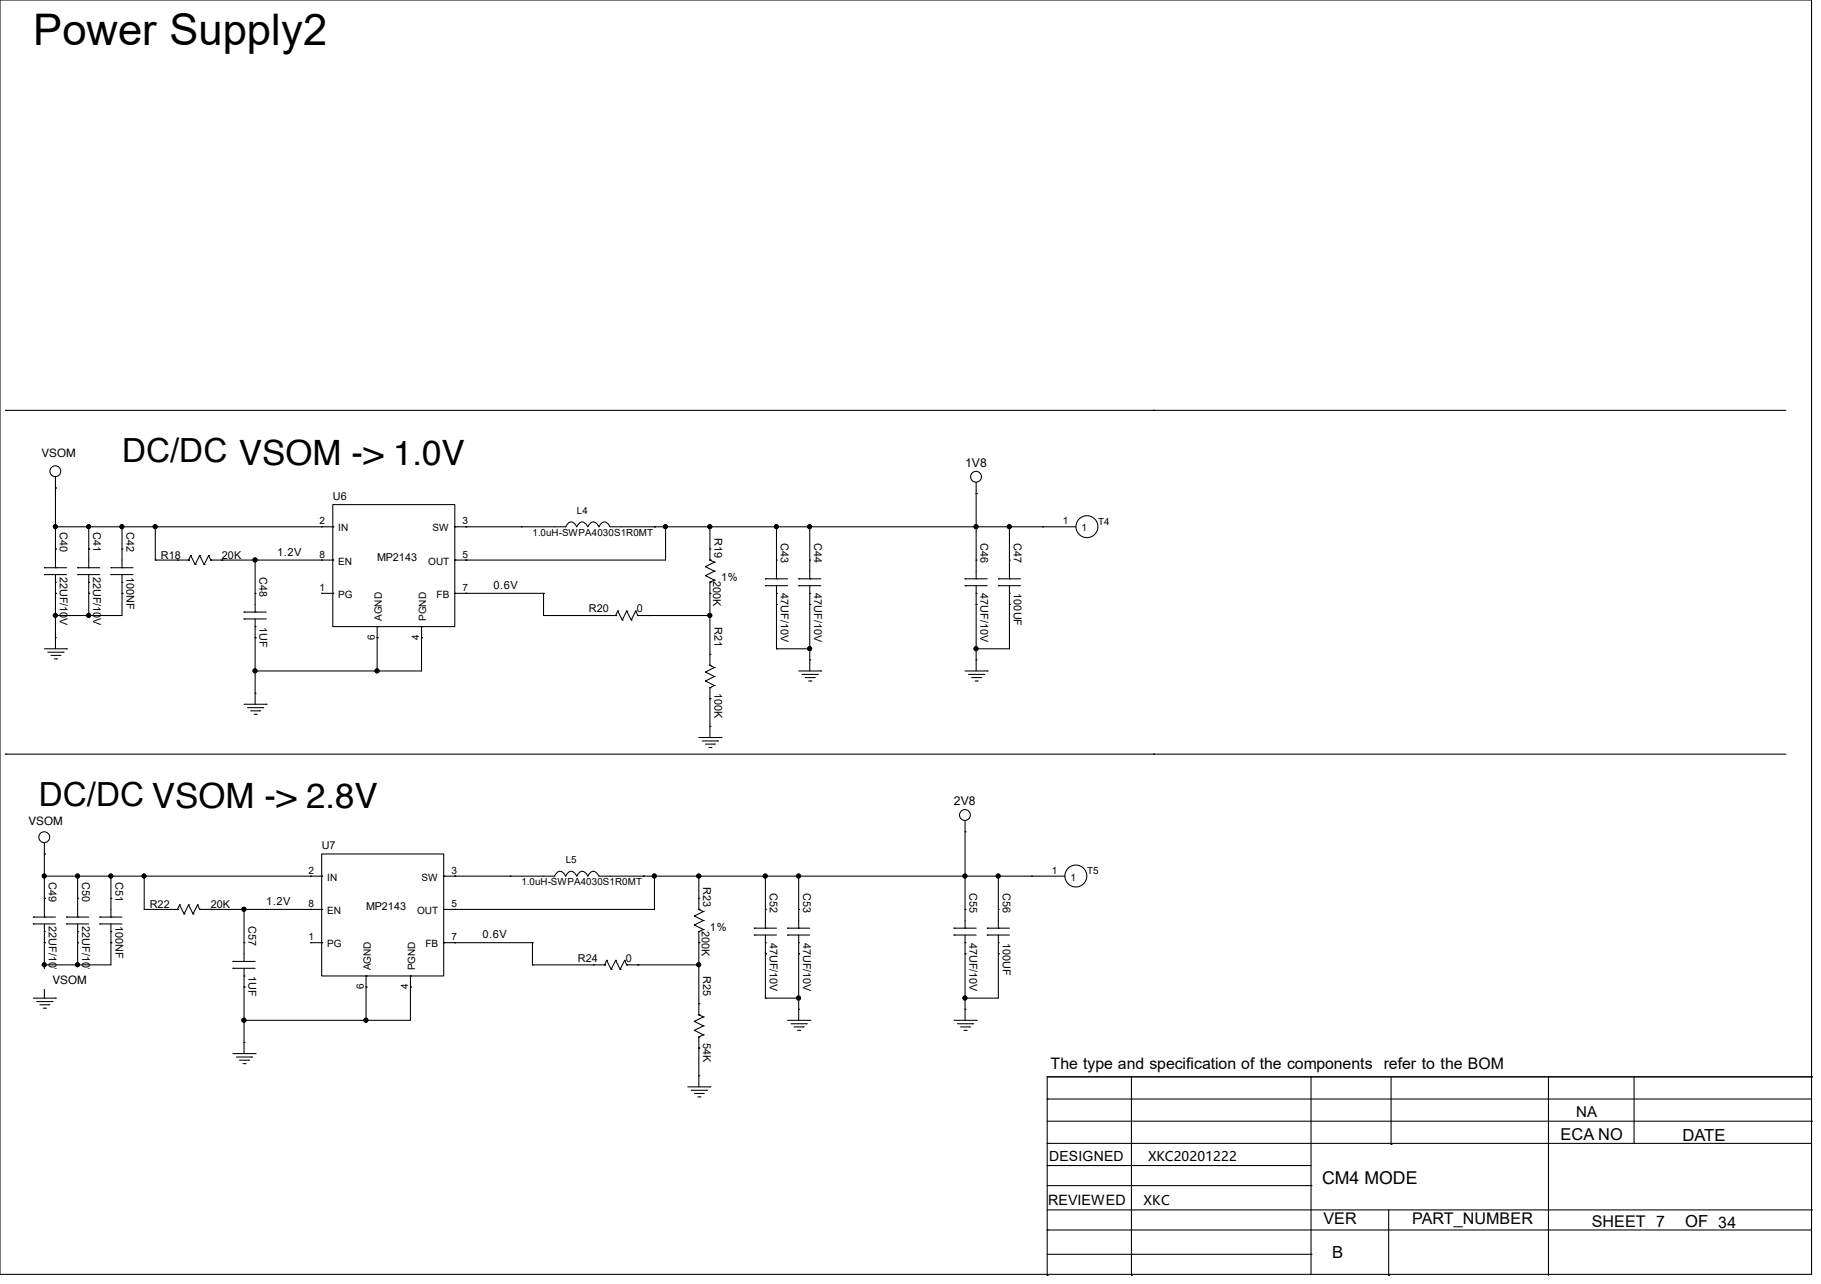
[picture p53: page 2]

The type and specification of the components refer to the BOM

NA
ECA NO | DATE

DESIGNED | XKC20201222 | CM4 MODE

XKC

VER | PART_NUMBER | SHEET 7 34

# VBUS1

# PA_PP_EXT

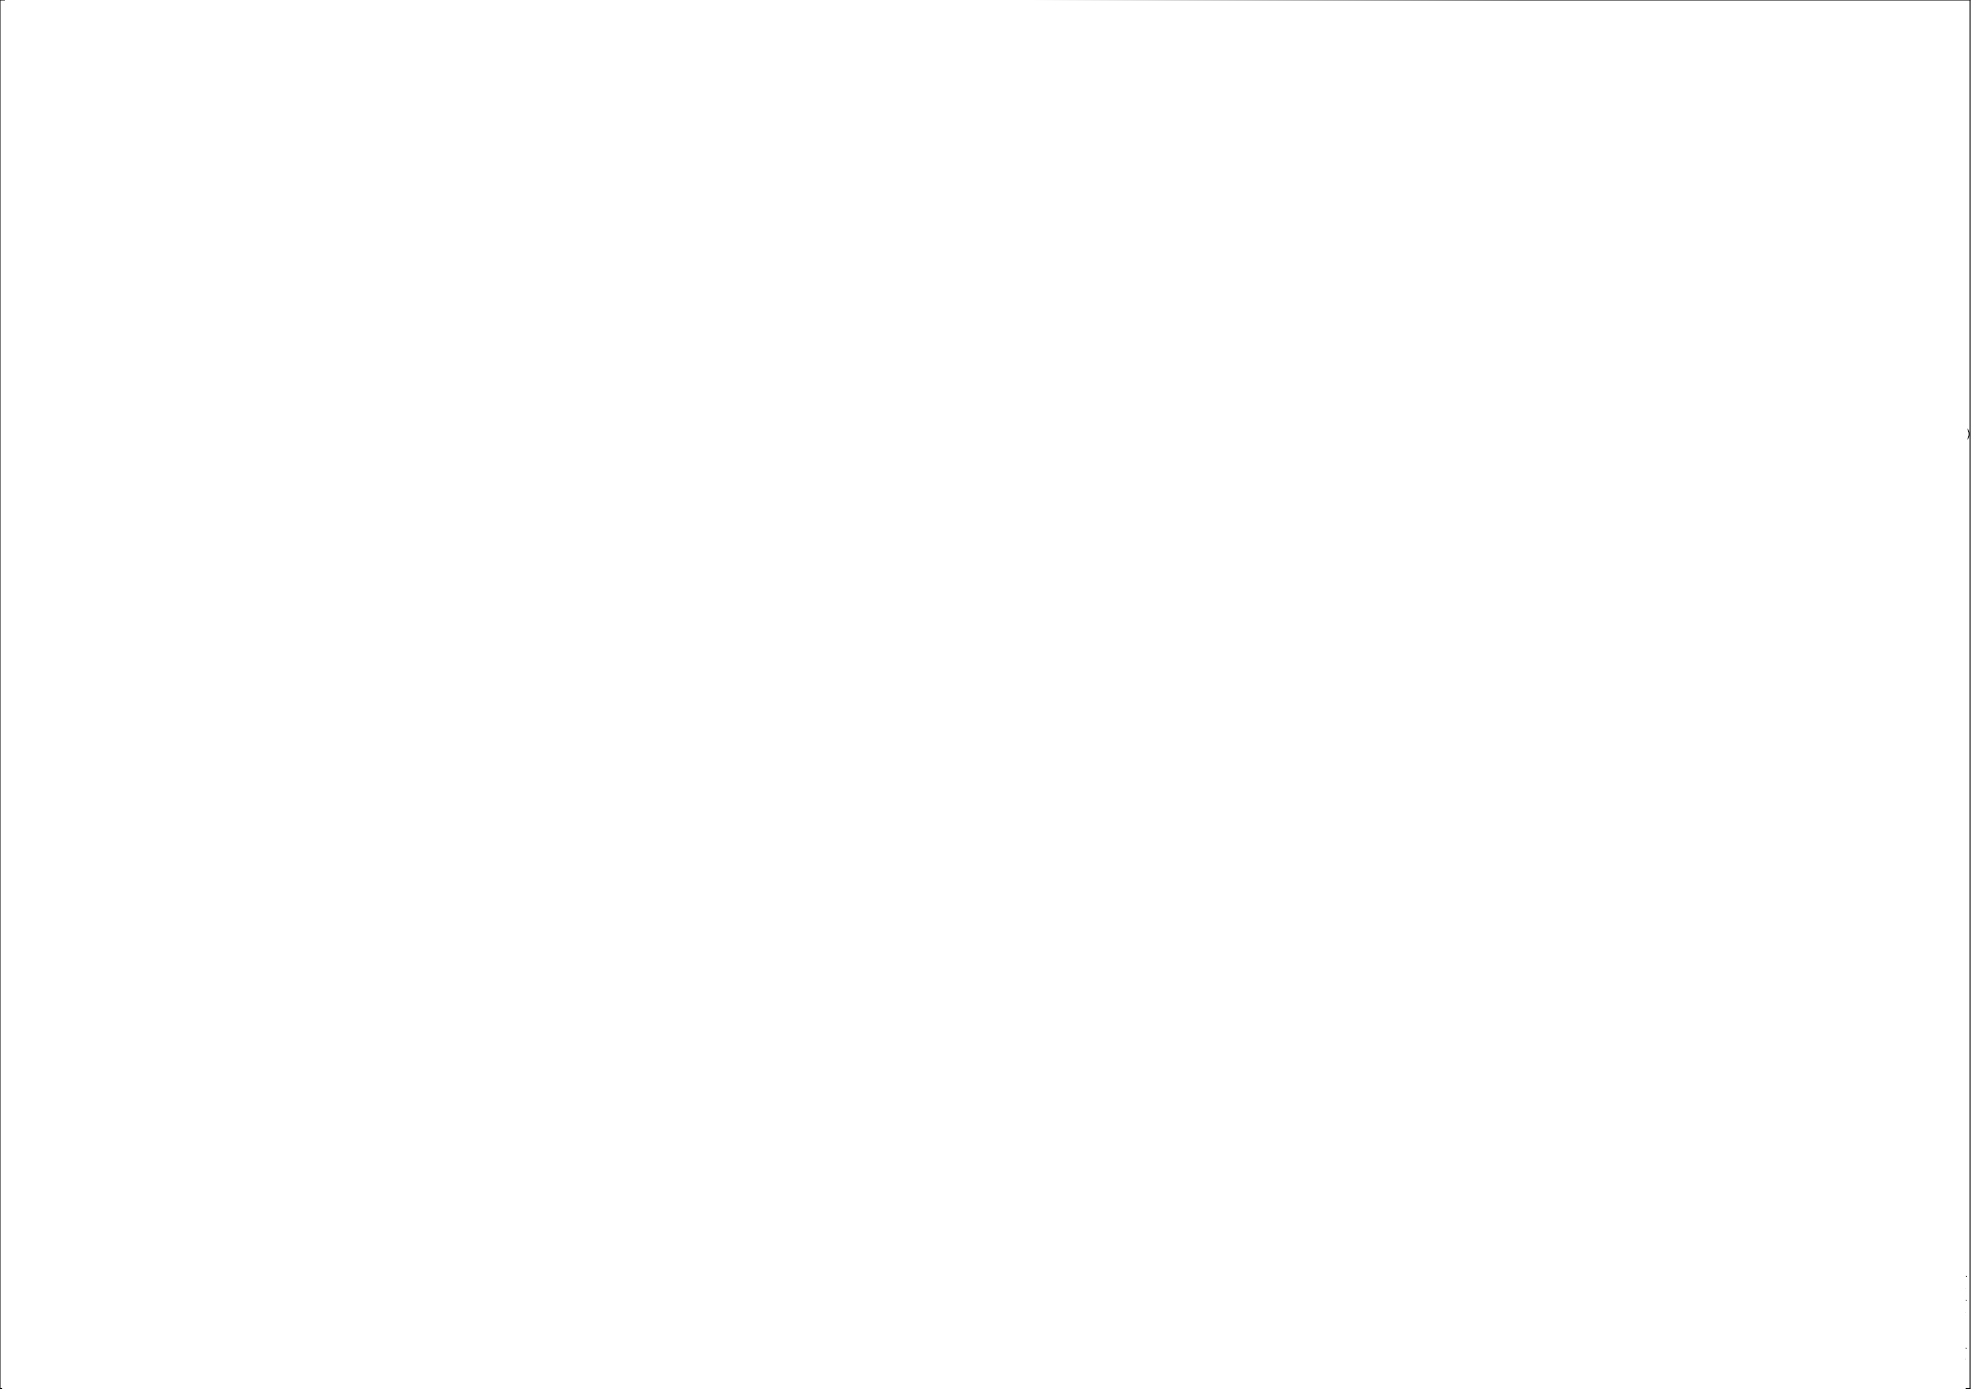
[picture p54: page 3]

The type and specification of the components refer to the BOM

NA
ECA NO | DATE

# CBTL04083 HD3SS460

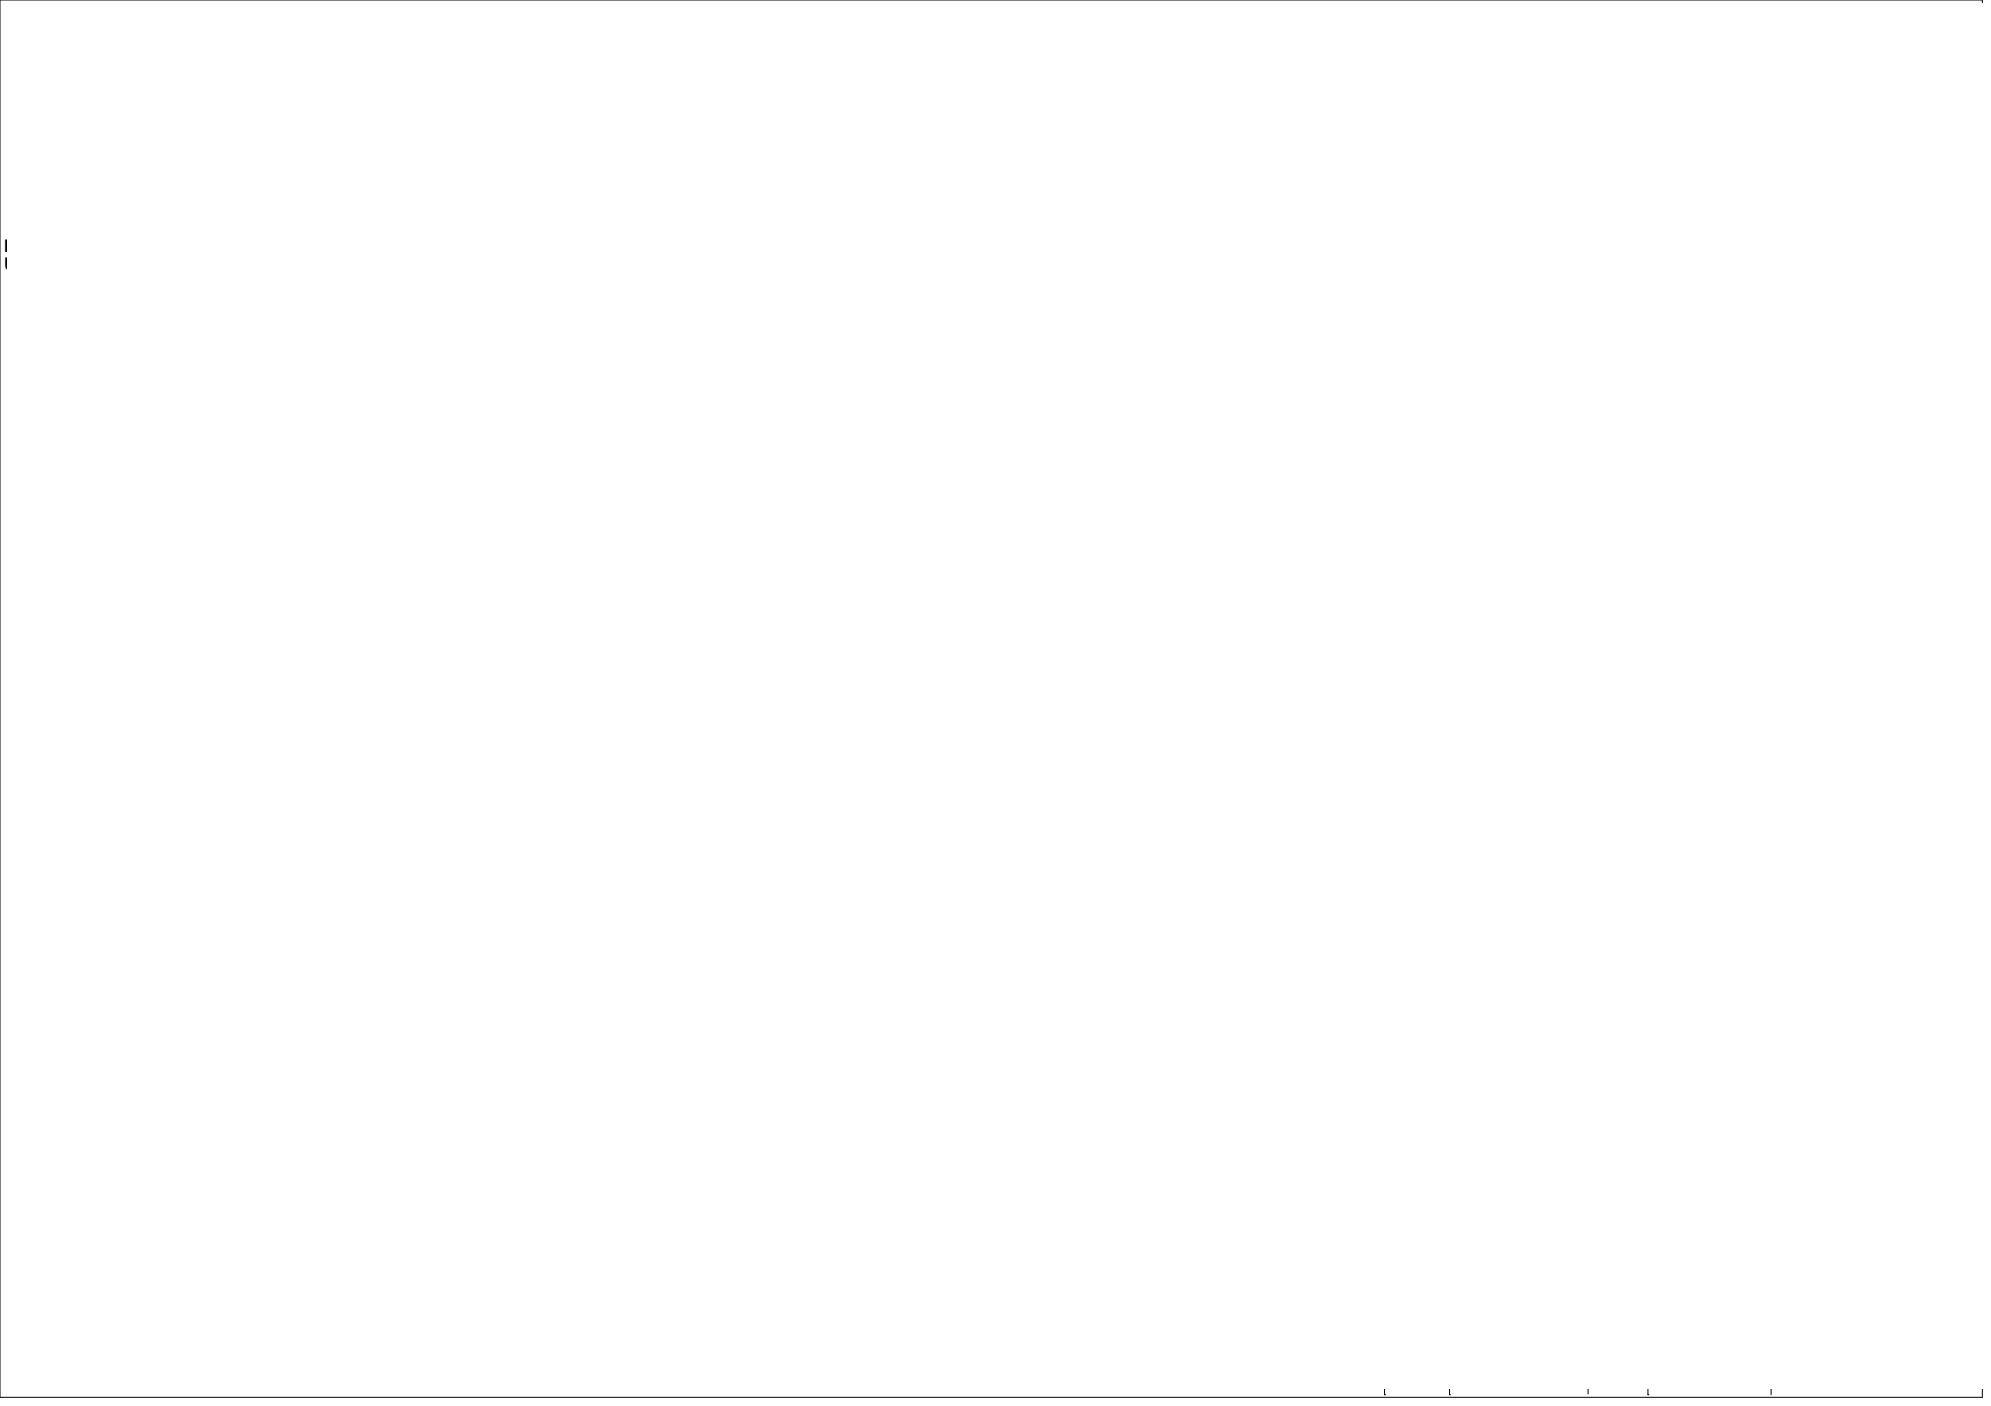
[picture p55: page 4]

TYPEC_3V3
22 GND⁷ ³⁹ VDD⁷ ⁴⁰ XSD⁰¹ ⁴¹ VDD⁸ ⁴² HOLD ⁴³

24 SSTXN ²⁵ SSTXP ²⁶ SSRXN ²⁷ SSRXP ²⁸ PAD ²⁹

10 CSBU¹ 11 CSBU² 12 SBU¹ 13 SBU² 14

The type and specification of the components refer to the BOM

# HD3SS460

# TYPE-C

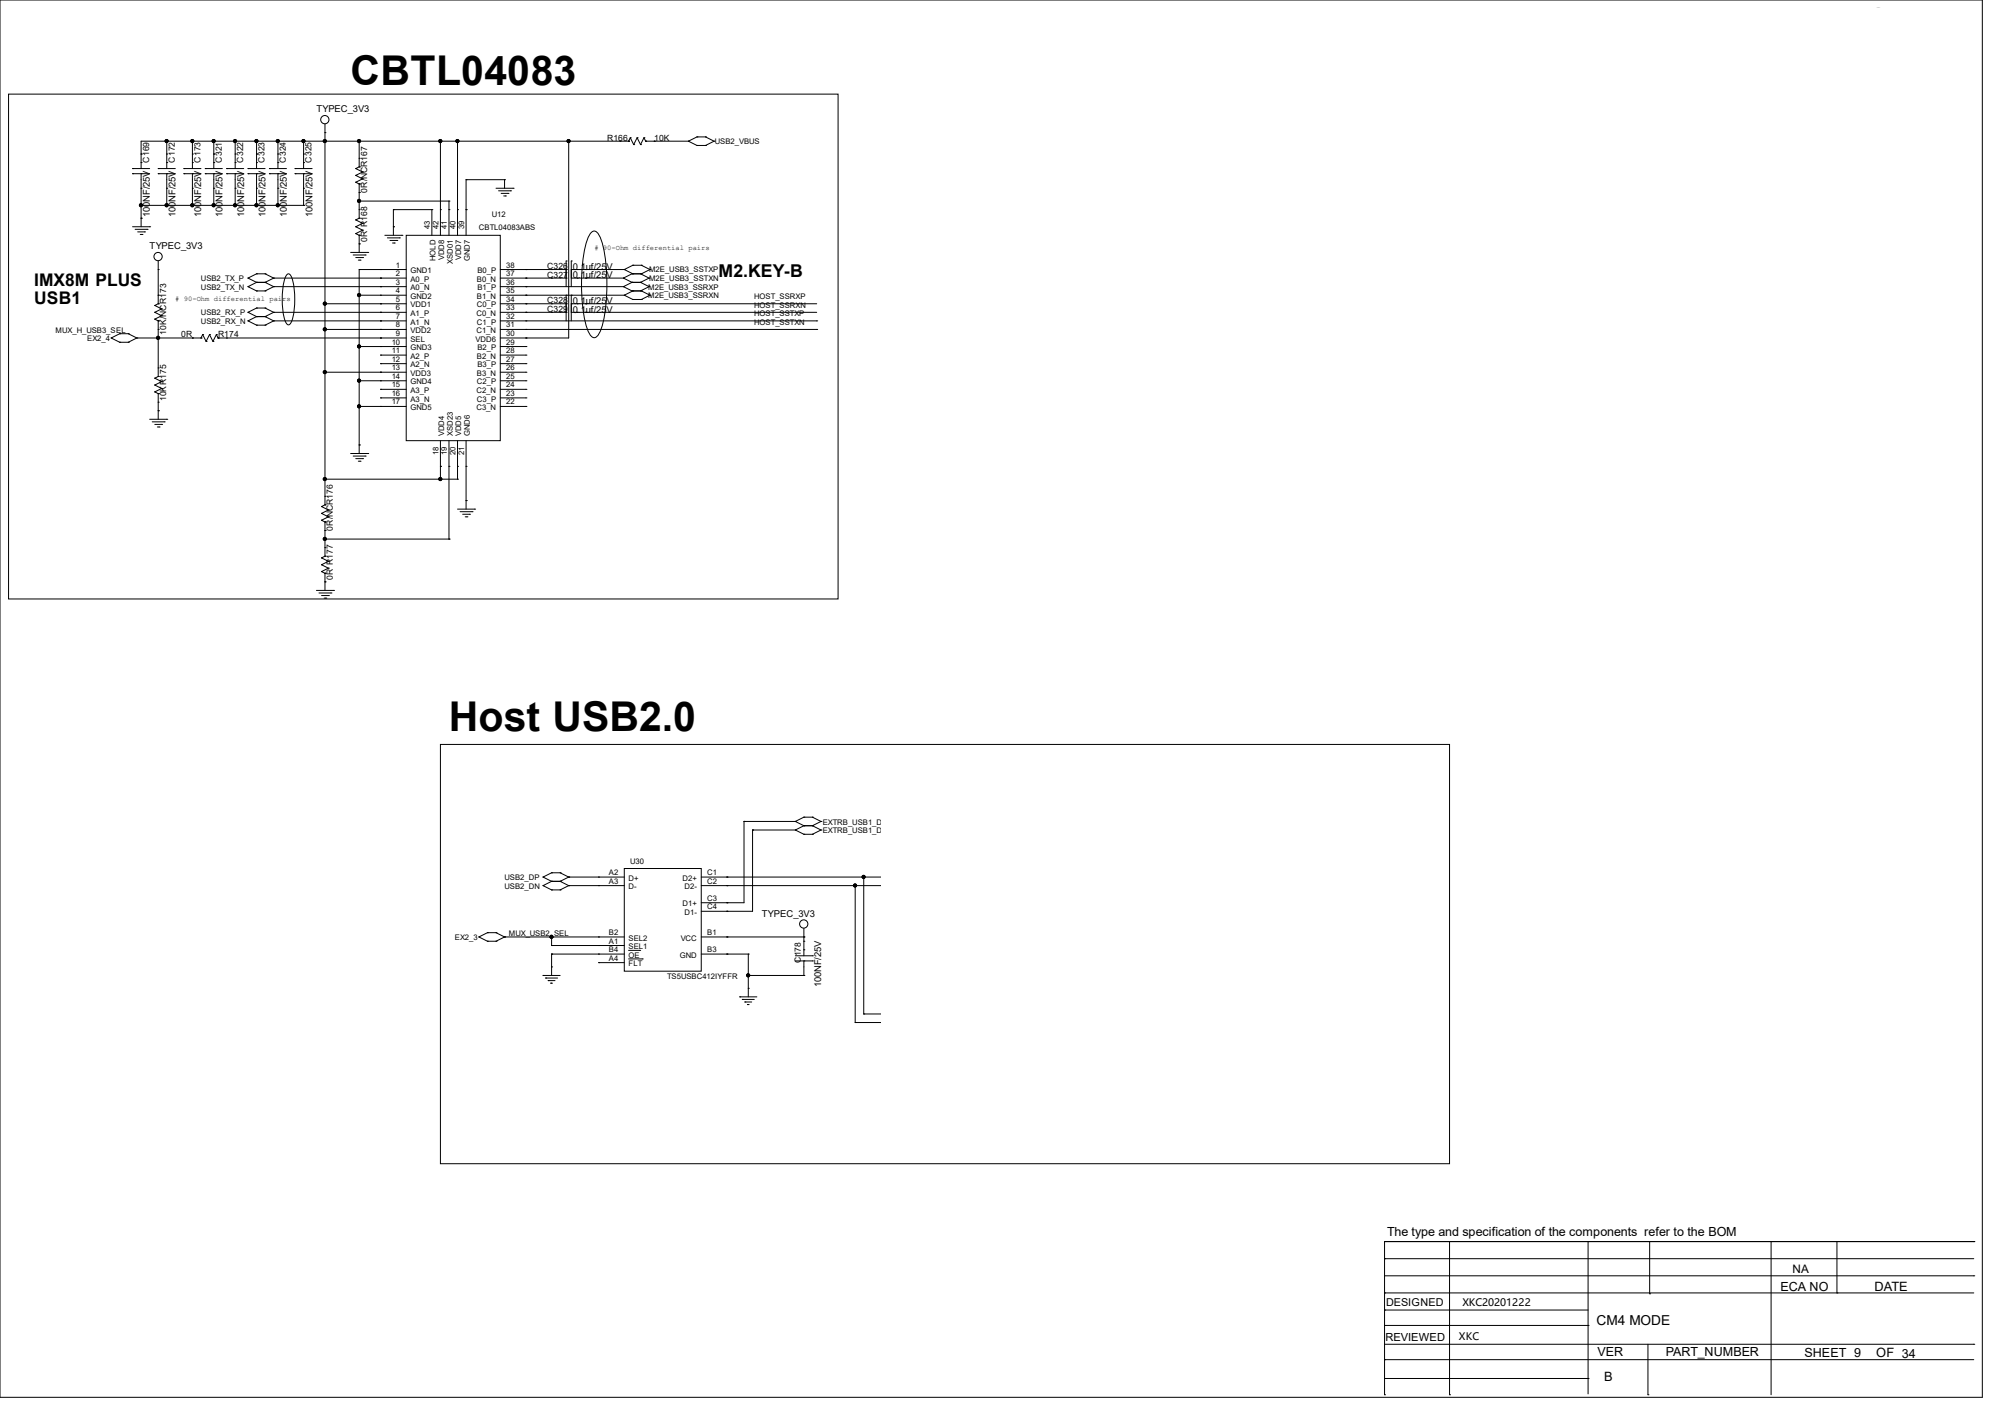
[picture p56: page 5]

22 GND⁷ ³⁹ VDD⁷ ⁴⁰ XSD⁰¹ ⁴¹ VDD⁸ ⁴² HOLD ⁴³ 10KR¹⁷⁵
TYPEC_3V3

10 CSBU¹ 11 CSBU² 12 SBU¹ 13 SBU² 14

The type and specification of the components refer to the BOM

# V-SOM decoupling capacitors

## USB1_OTG

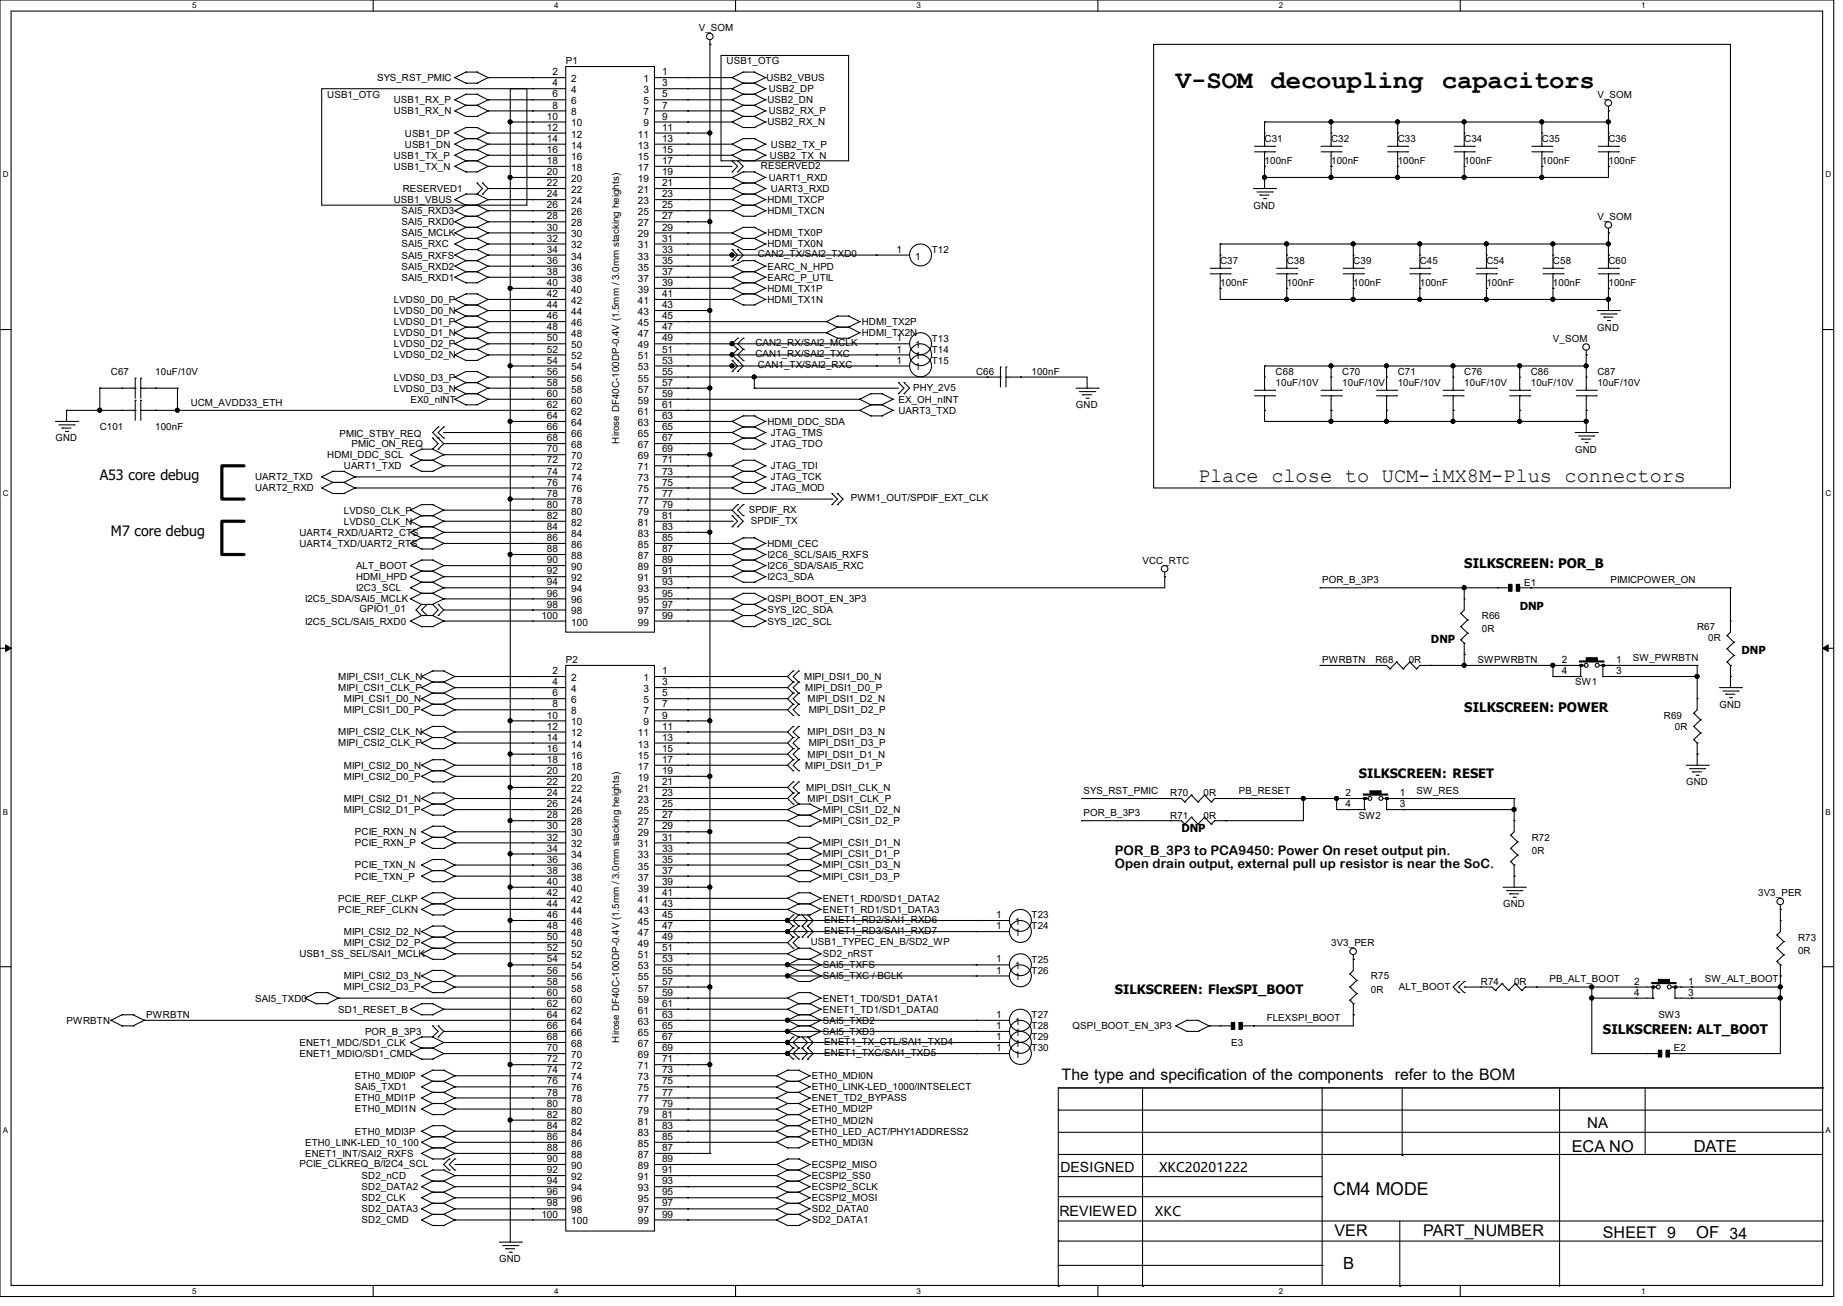
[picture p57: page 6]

Place close to UCM-iMX8M-Plus connectors

POR_B_3P3 to PCA9450: Power On reset output pin.
Open drain output, external pull up resistor is near the SoC.

NA
ECA NO | DATE

DESIGNED | XKC20201222 | CM4 MODE

# SYS_I2C to GPIO expander-EX0 Addres:0X40

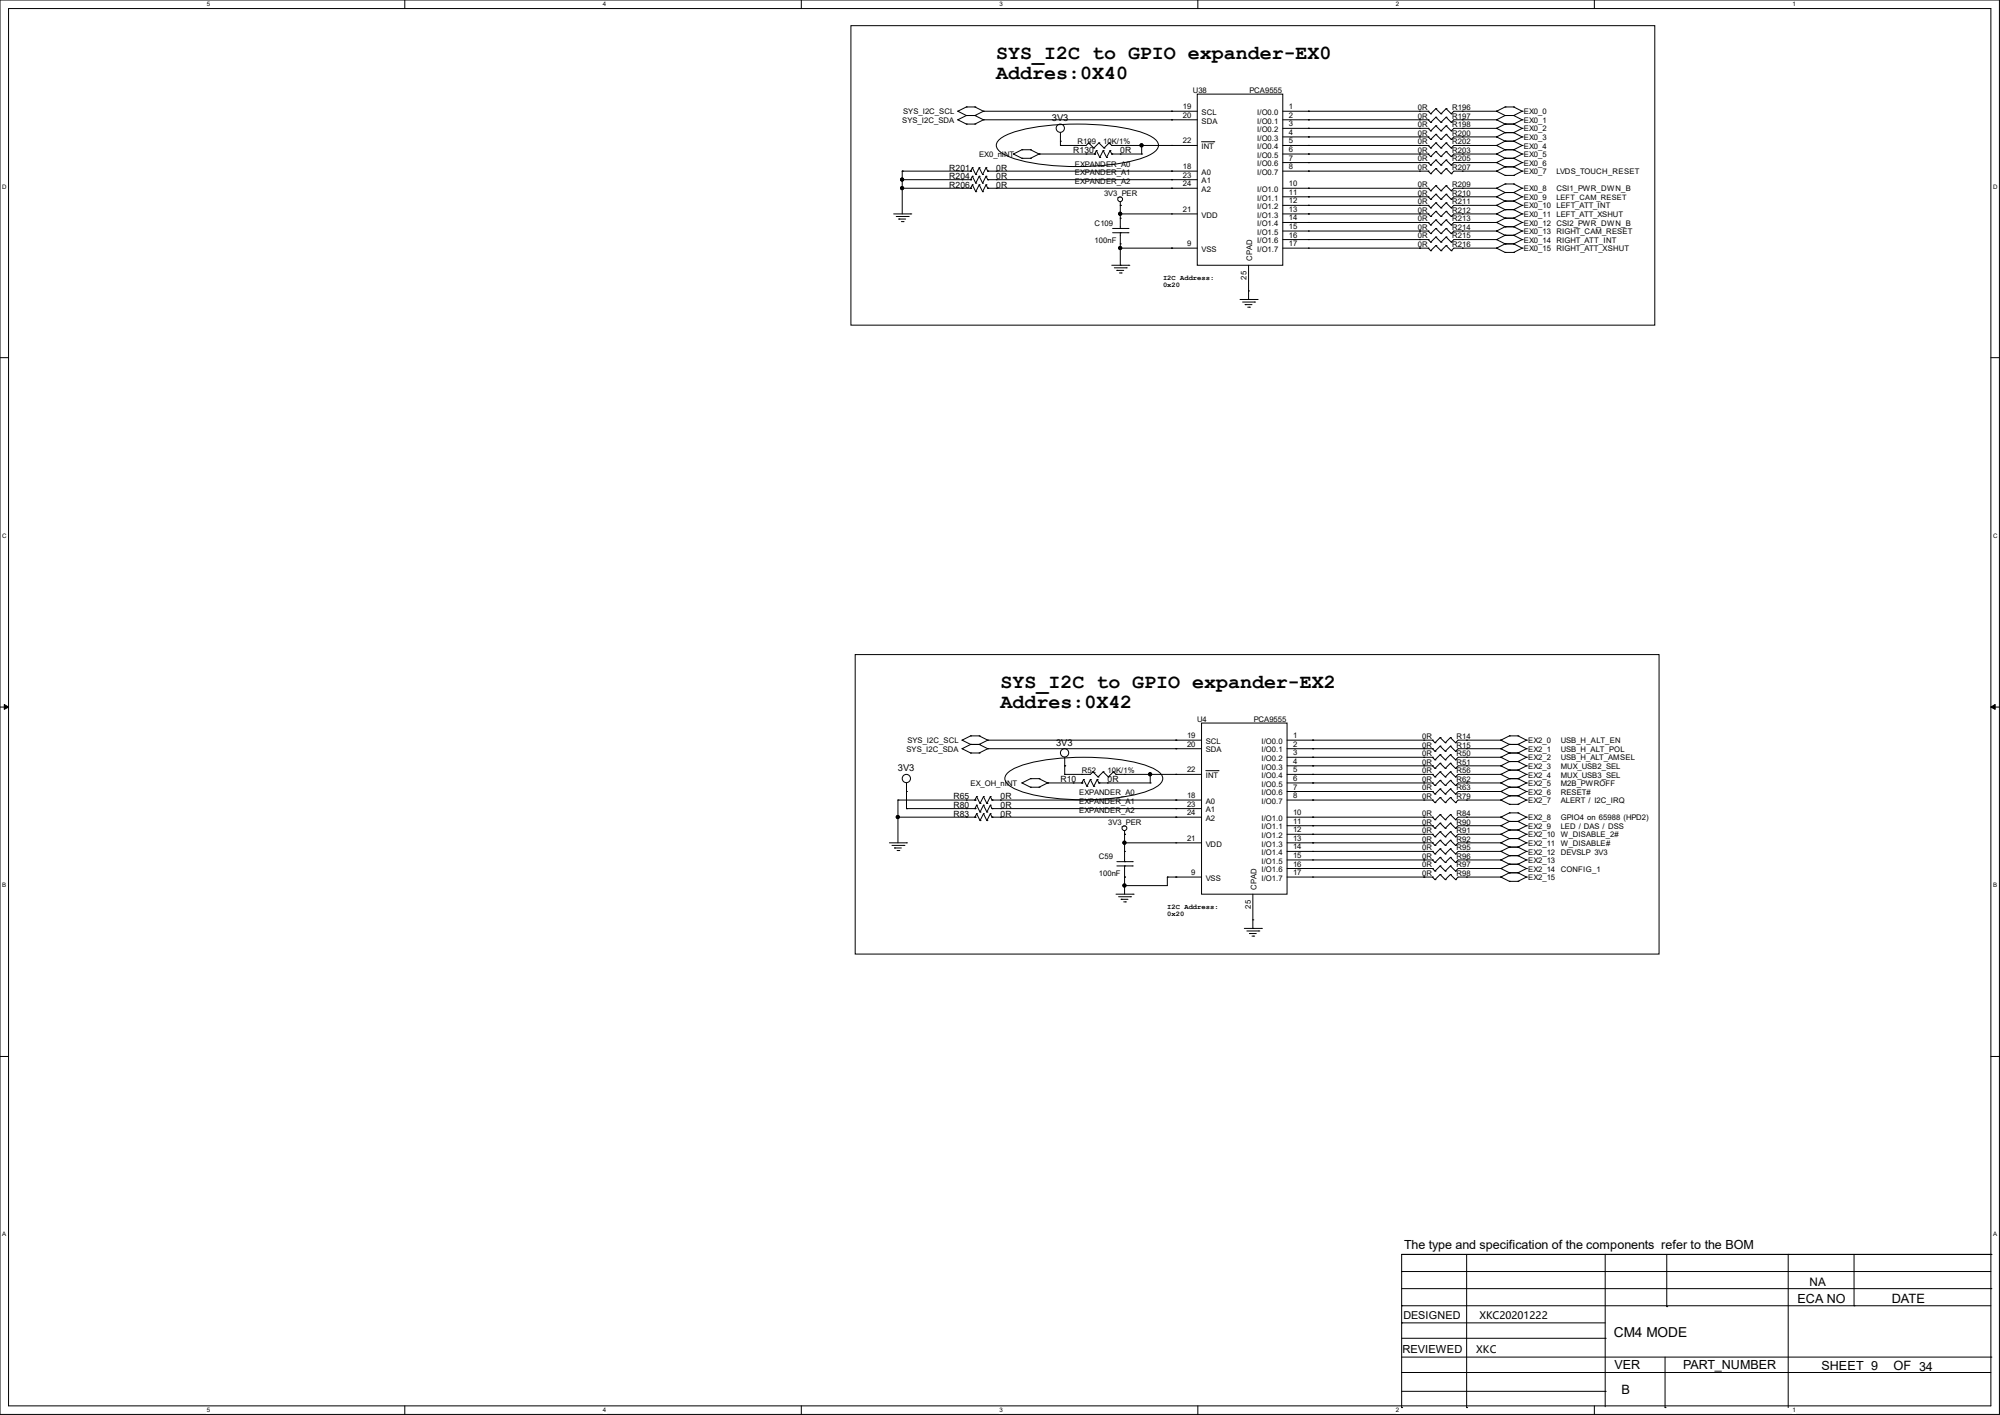
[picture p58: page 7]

The type and specification of the components refer to the BOM

NA
ECA NO | DATE

# (WWAN PCIe/USB3, NO SATA)

# M.2 Socket - Key B

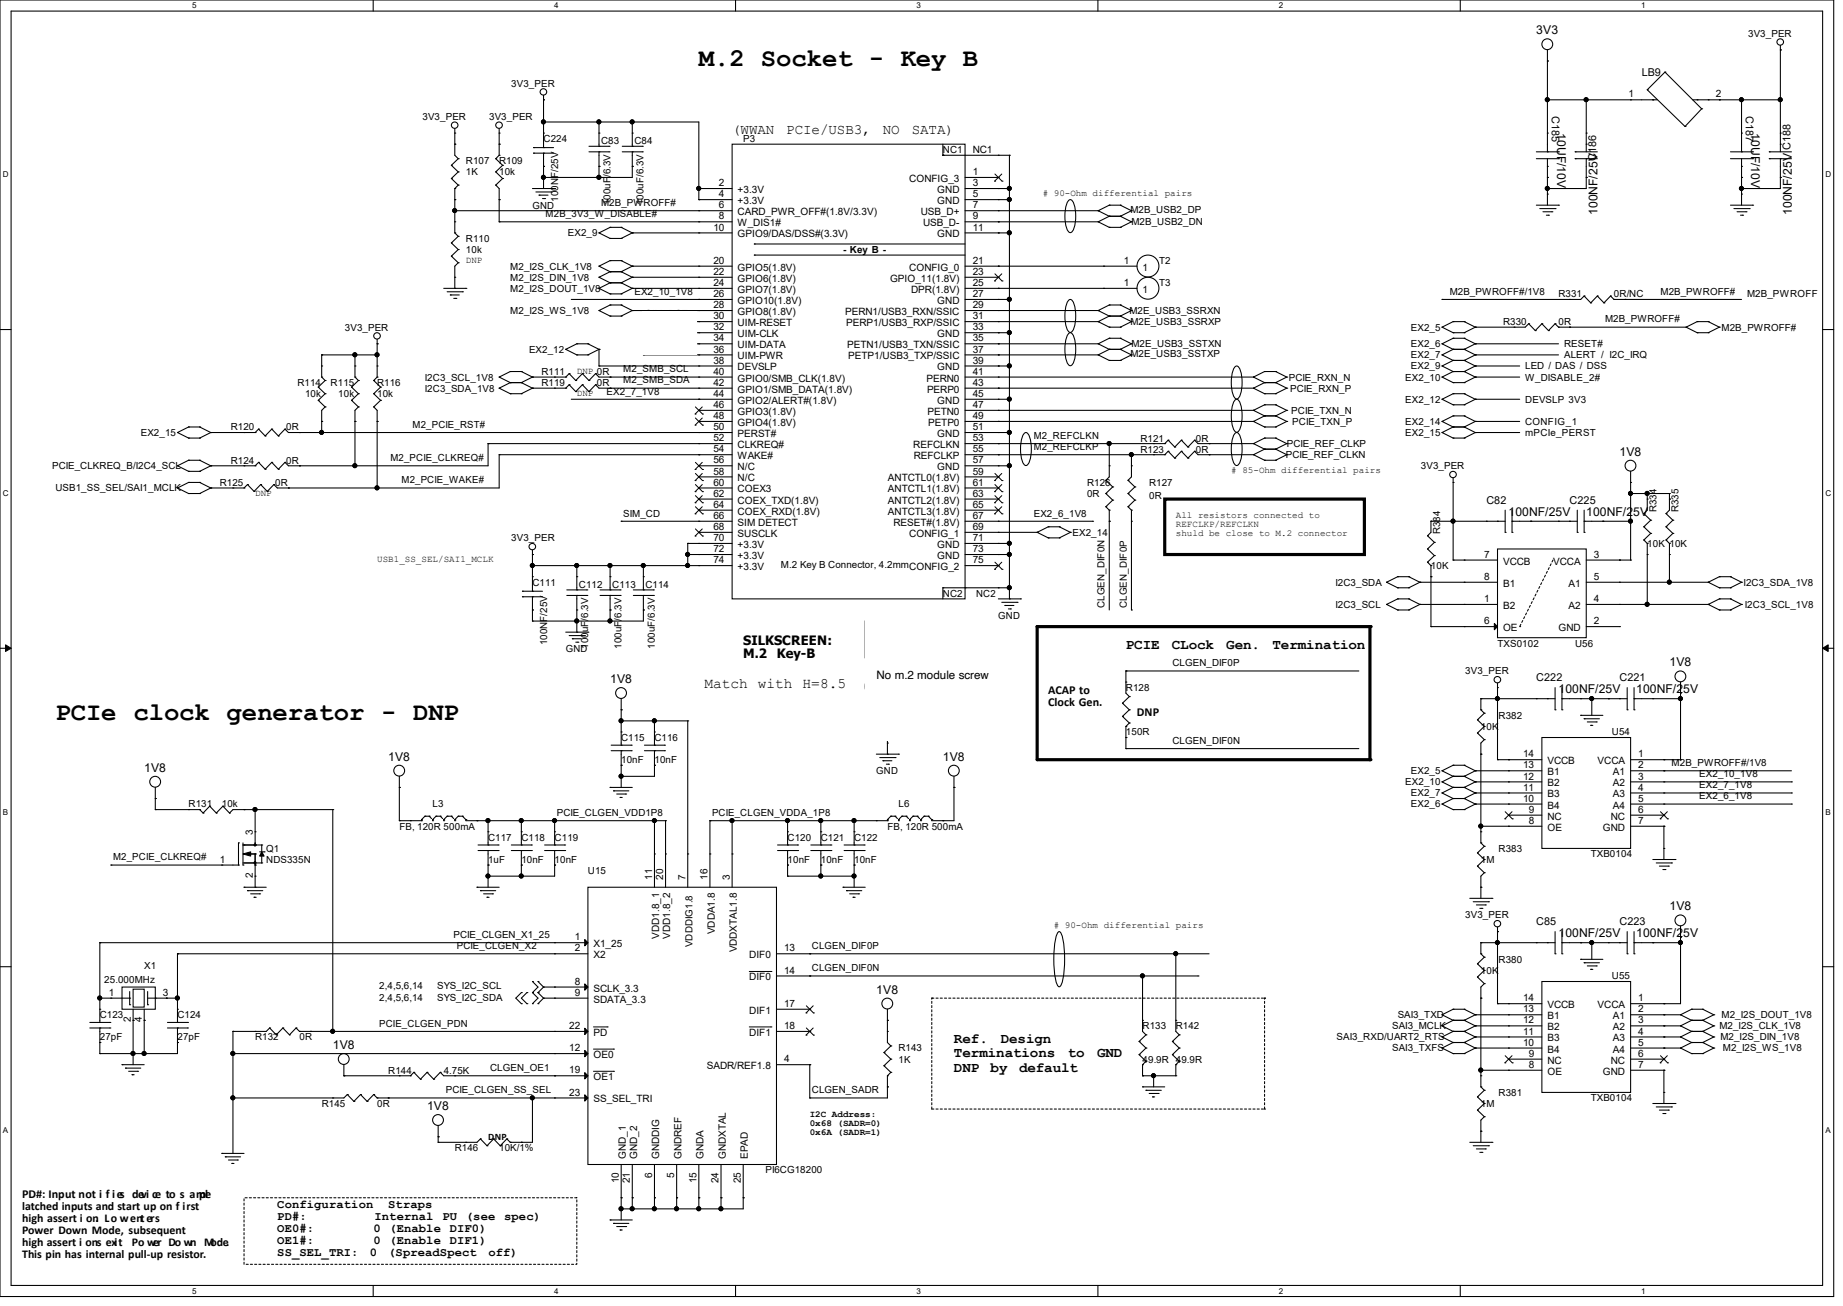
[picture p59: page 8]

All resistors connected to
REFCLKP/REFCLKN
shuld be close to M.2 connector

PCIE CLock Gen. Termination

PCIe clock generator - DNP

PD#: Input not i f i es devi ce to s ample
latched inputs and start up on f irst
high assert i on. Lo w ent ers
Power Down Mode, subsequent
high assert i ons exit Po wer Do wn Mode.
This pin has internal pull-up resistor.

## (WWAN PCIe/USB3, NO SATA)

# M.2 Socket - Key E

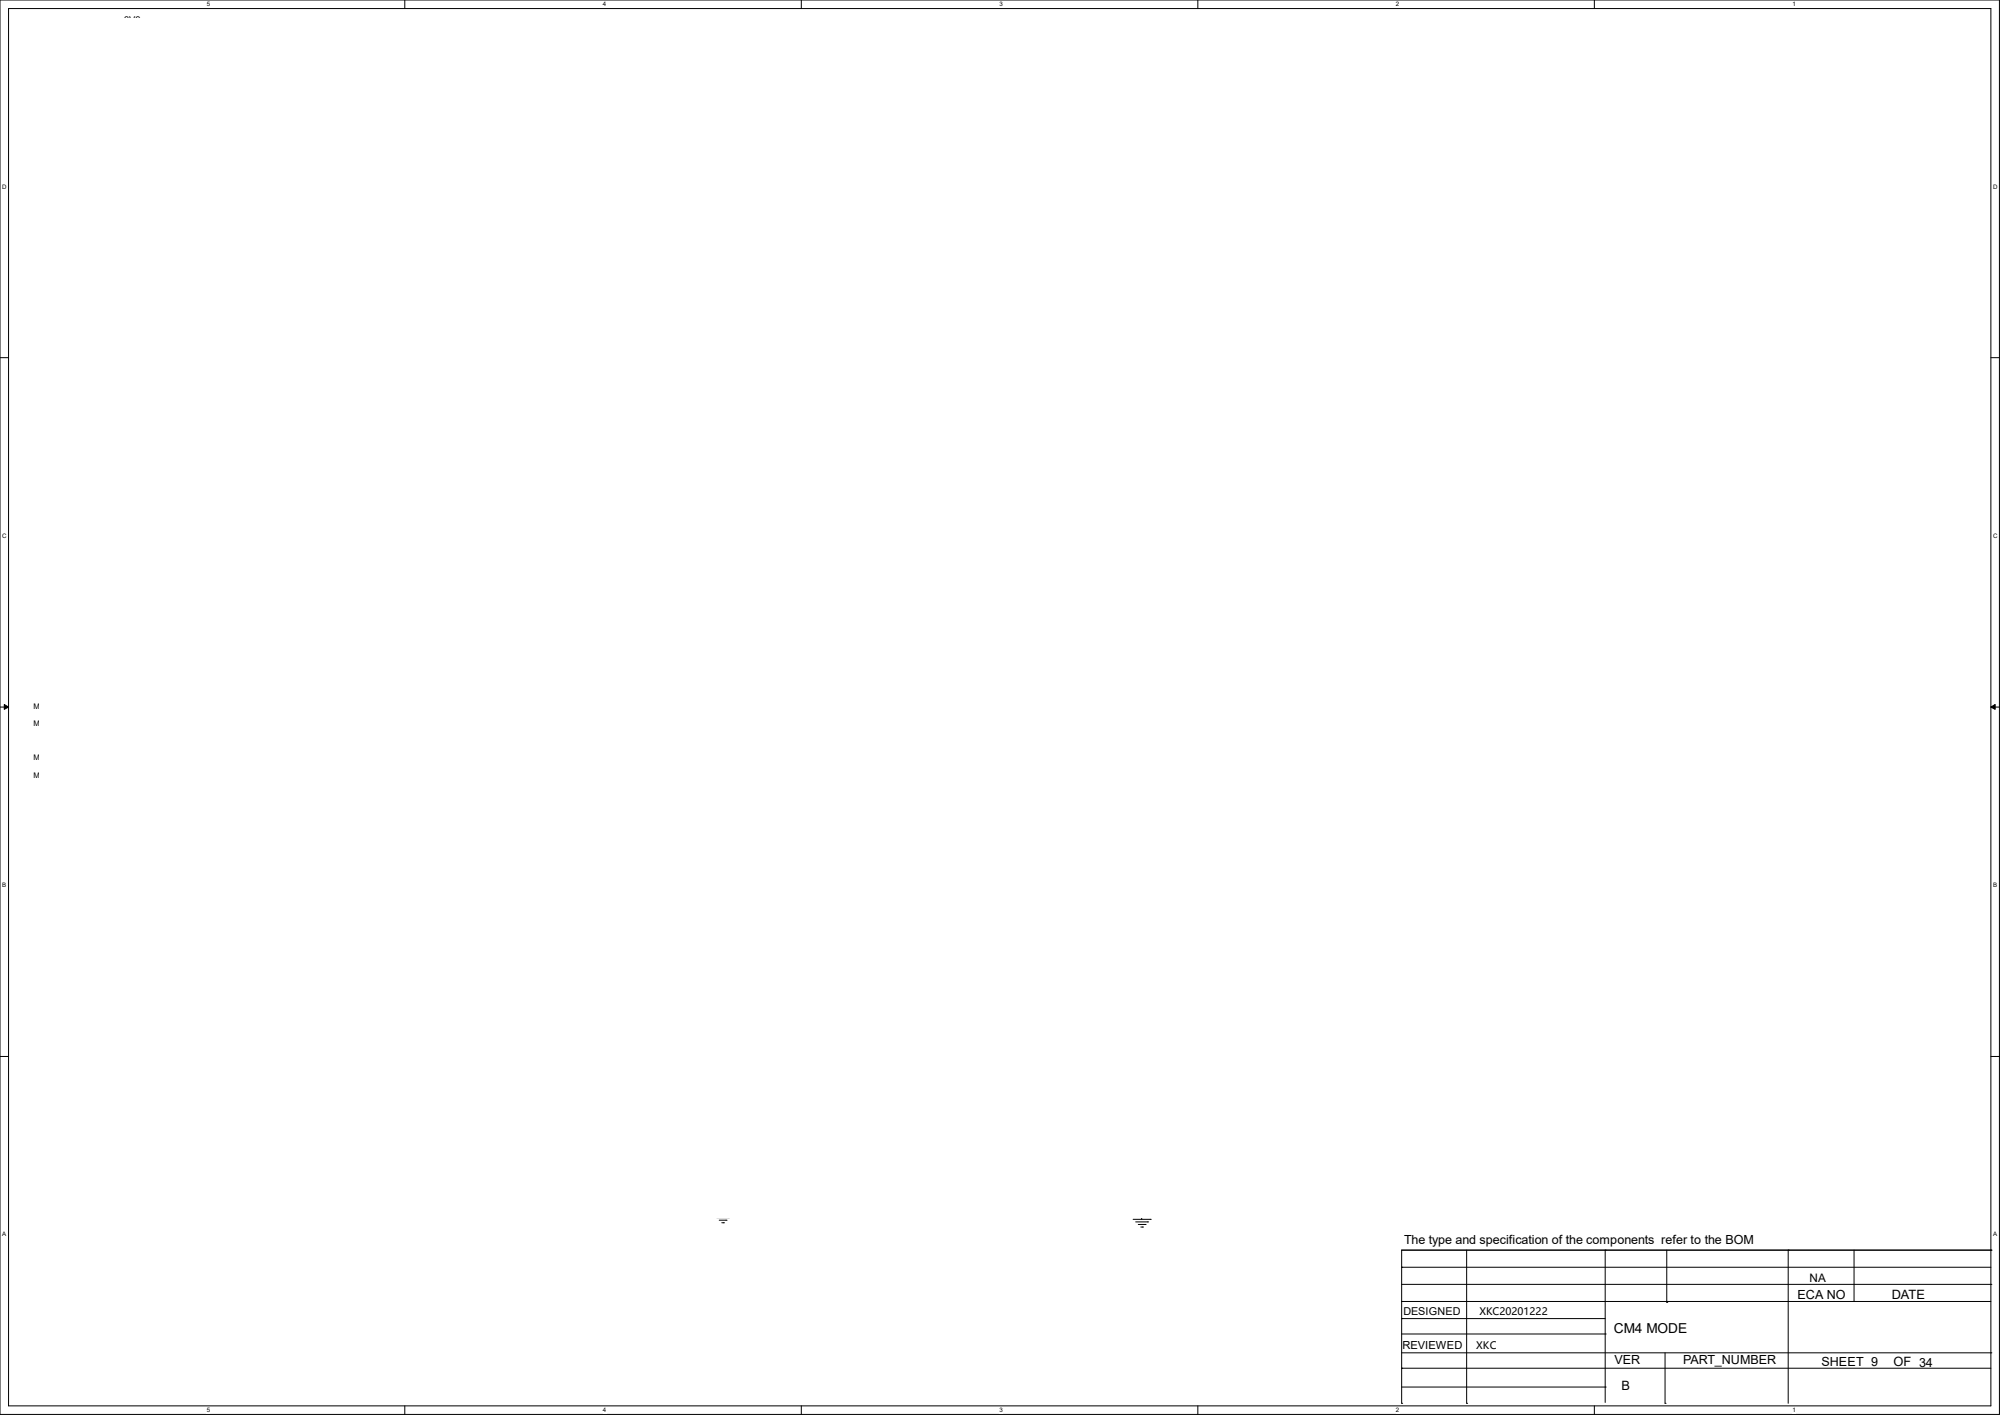
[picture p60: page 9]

The type and specification of the components refer to the BOM

NA
ECA NO | DATE

# HDMI connector with eARC

## # 100-Ohm diff pairs

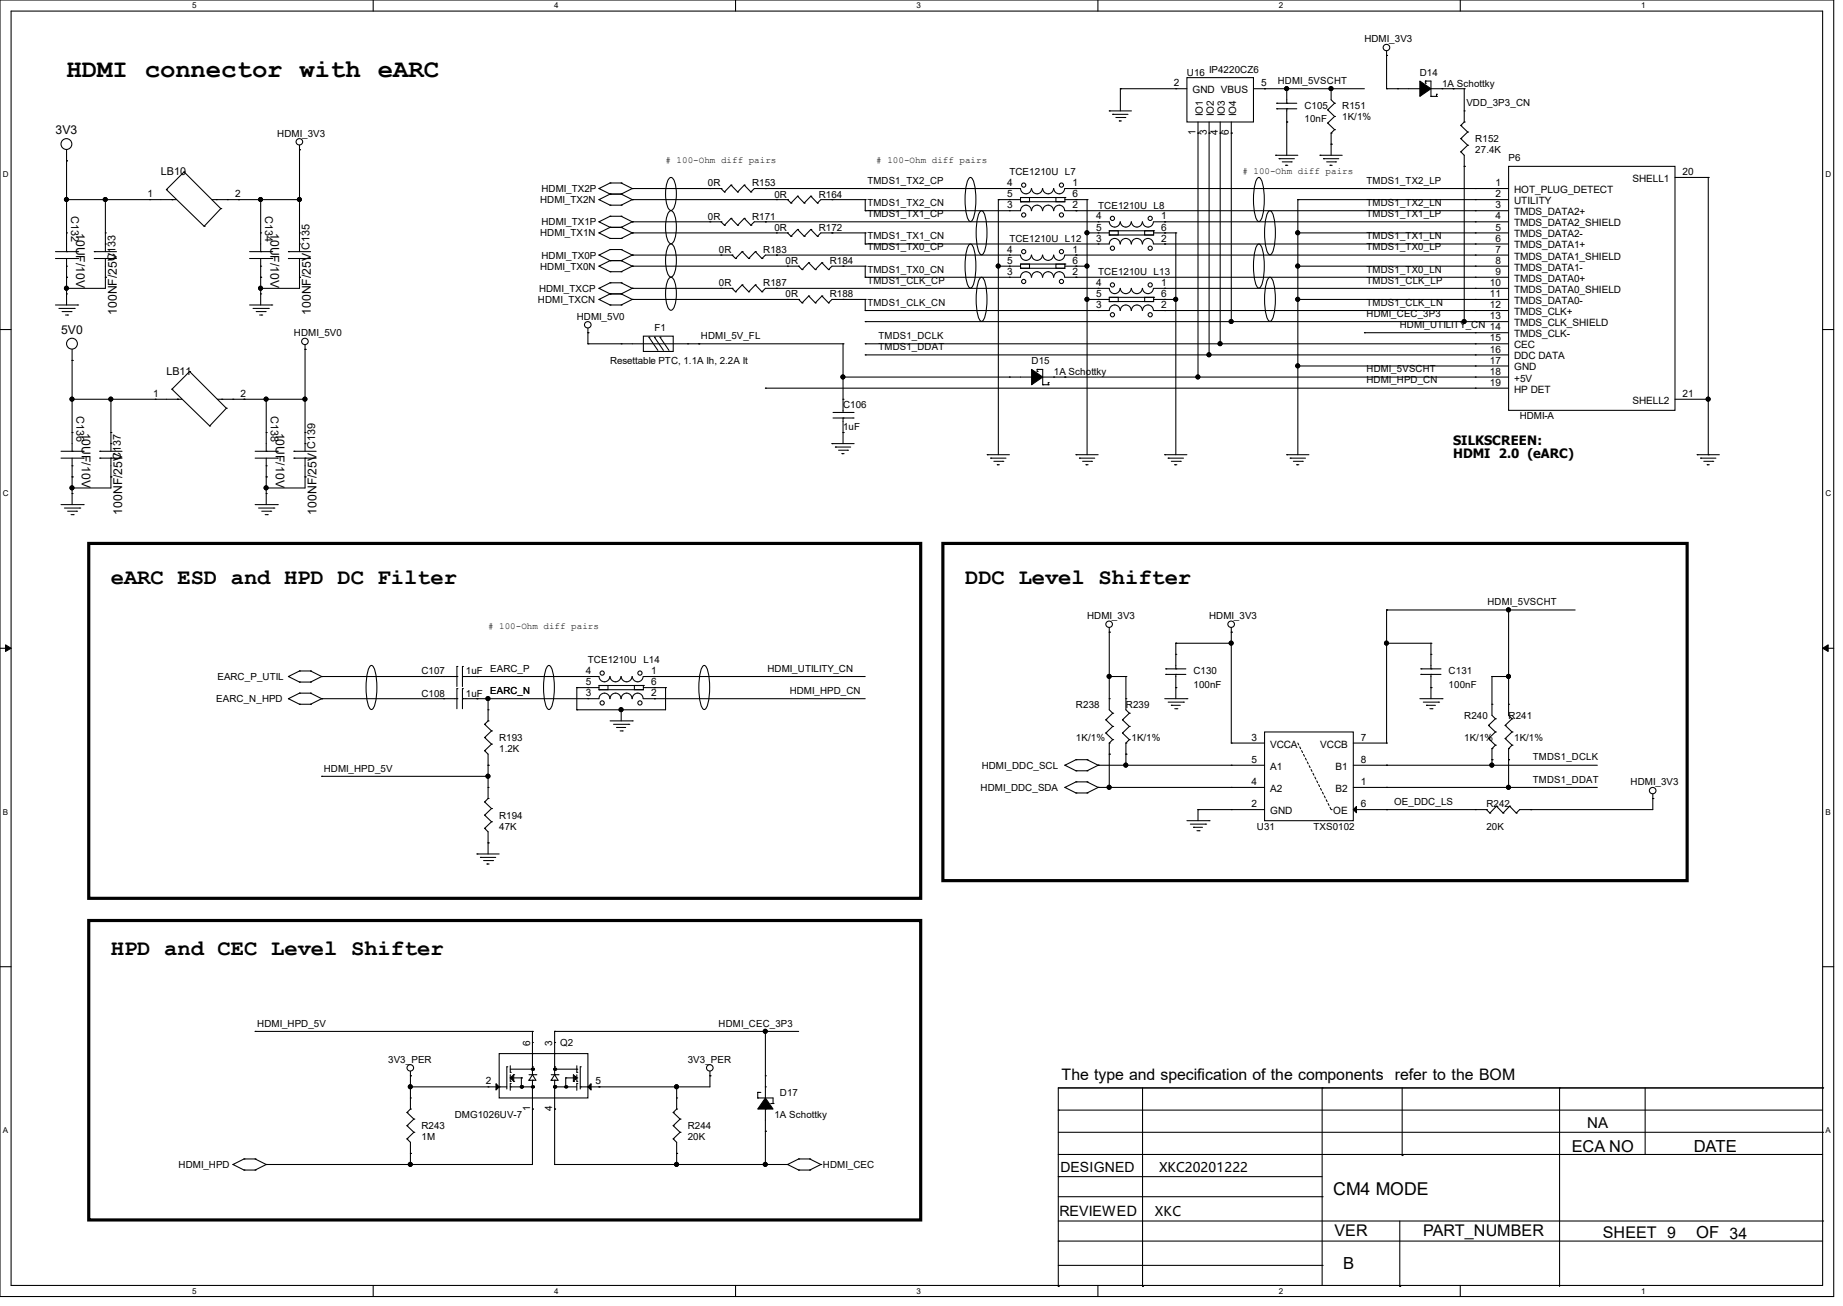
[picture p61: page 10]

TCE1210U L13 | | TMDS_DATA1- 8
4 1 3 2 | TMDS1_CLK_LP | TMDS_DATA0_SHIELD 10 TMDS_DATA0- 11

Resettable PTC, 1.1A Ih, 2.2A It

HPD and CEC Level Shifter

The type and specification of the components refer to the BOM

NA
ECA NO | DATE

DESIGNED | XKC20201222 | CM4 MODE

# Serial debug console Micro-SD socket (bootable)

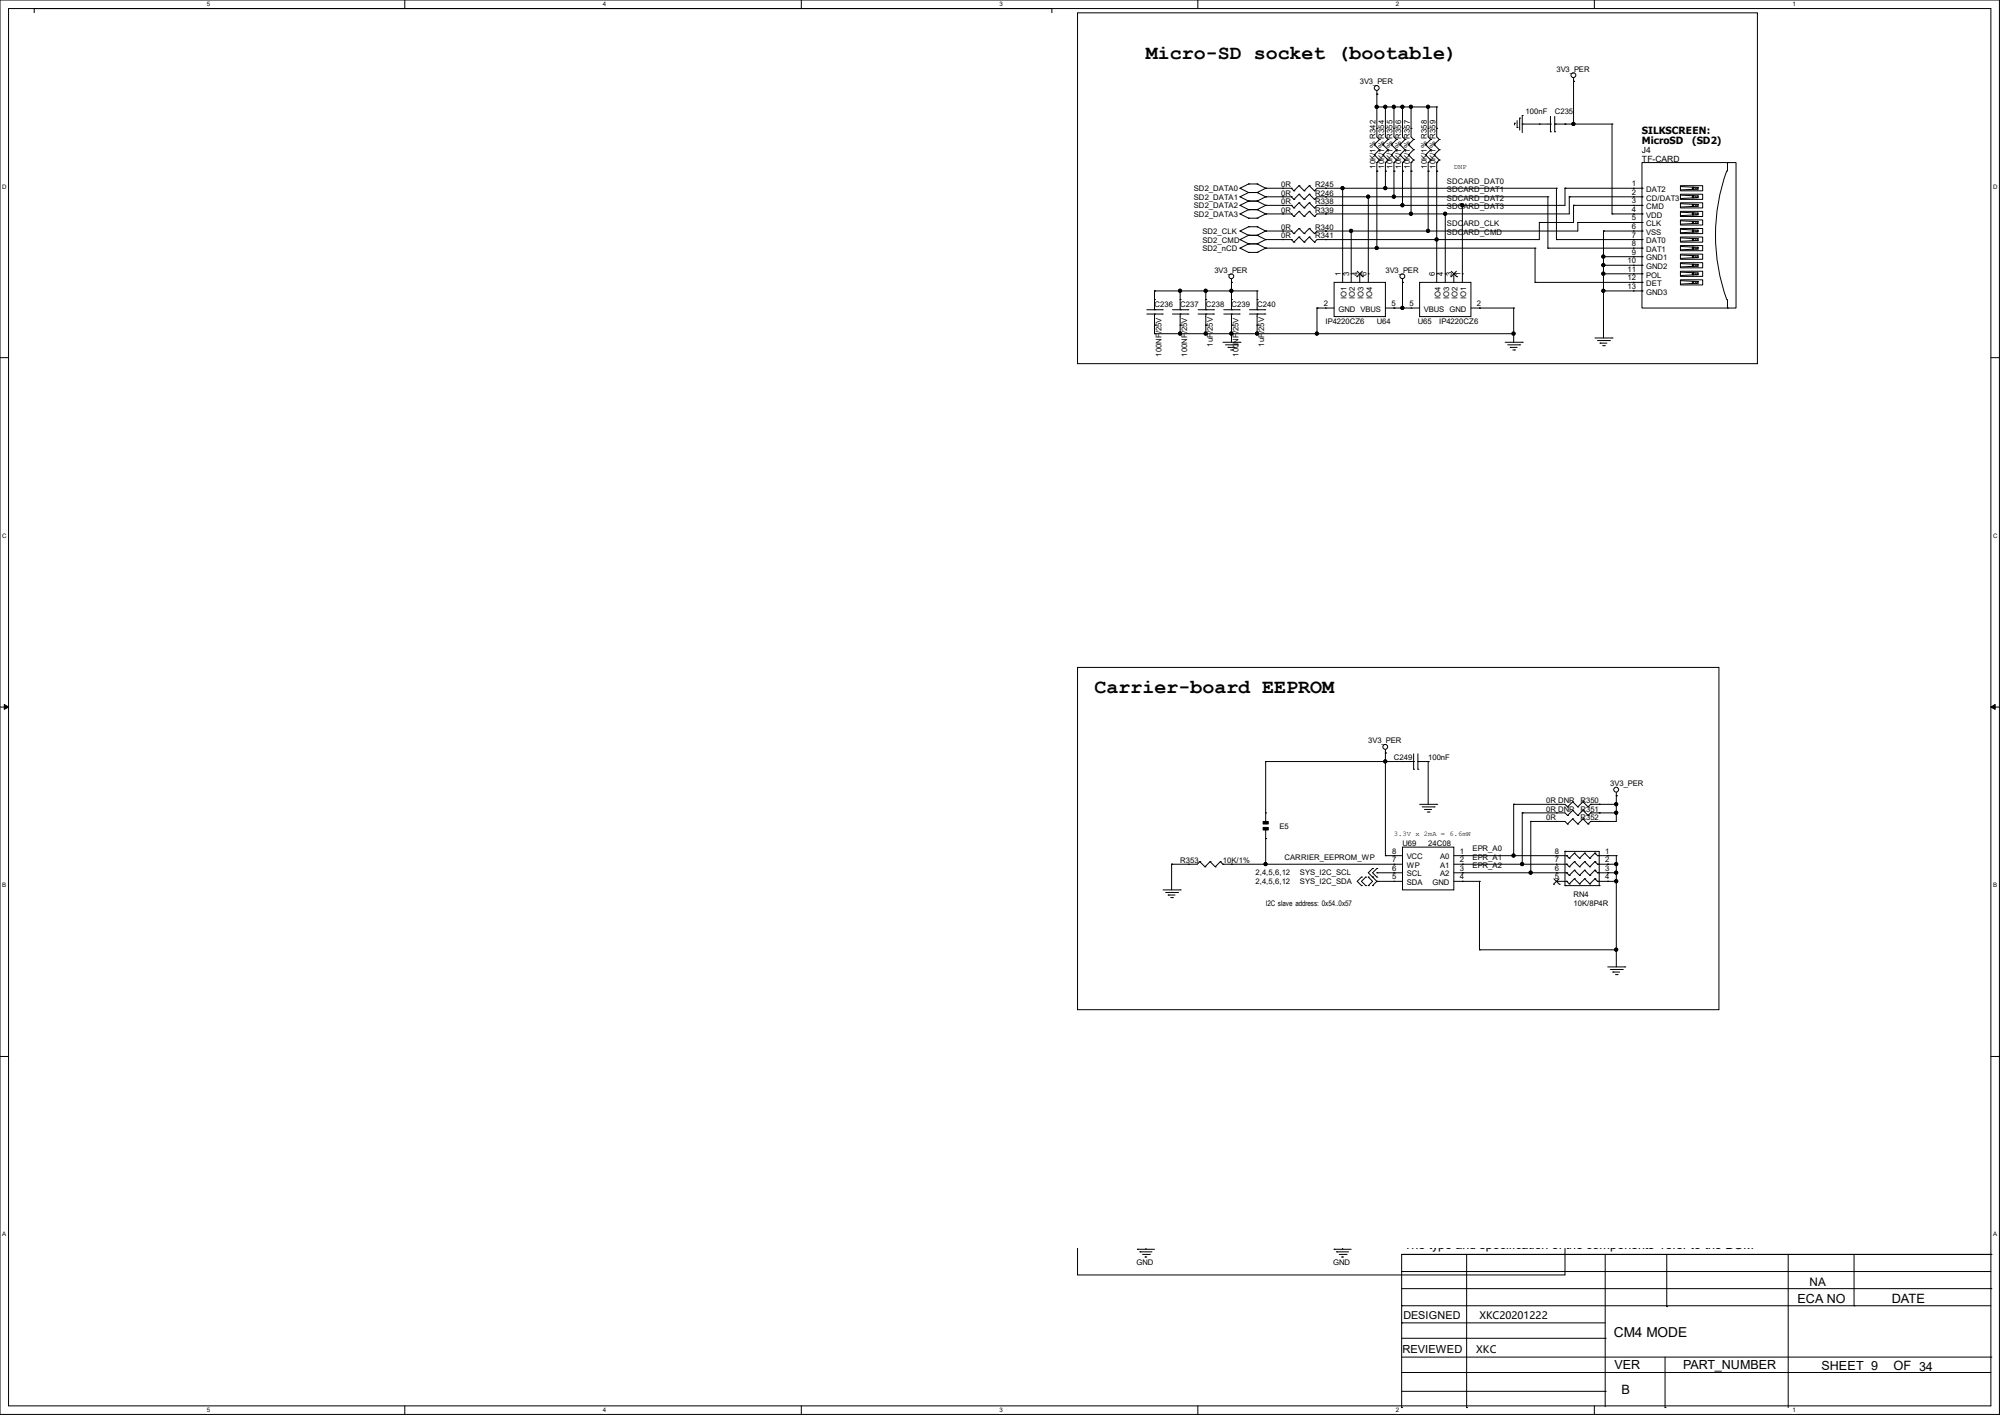
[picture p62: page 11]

USB console connection indicator

Jumper removed: Automatic Mode
Debug over USB when USB host
provides VBUS
Debug over RS-232 when USB VBUS not
available

The type and specification of the components refer to the BOM

NA
ECA NO | DATE

## 22-pin Connector for RPi cameras Four MIPI-CSI lanes connected

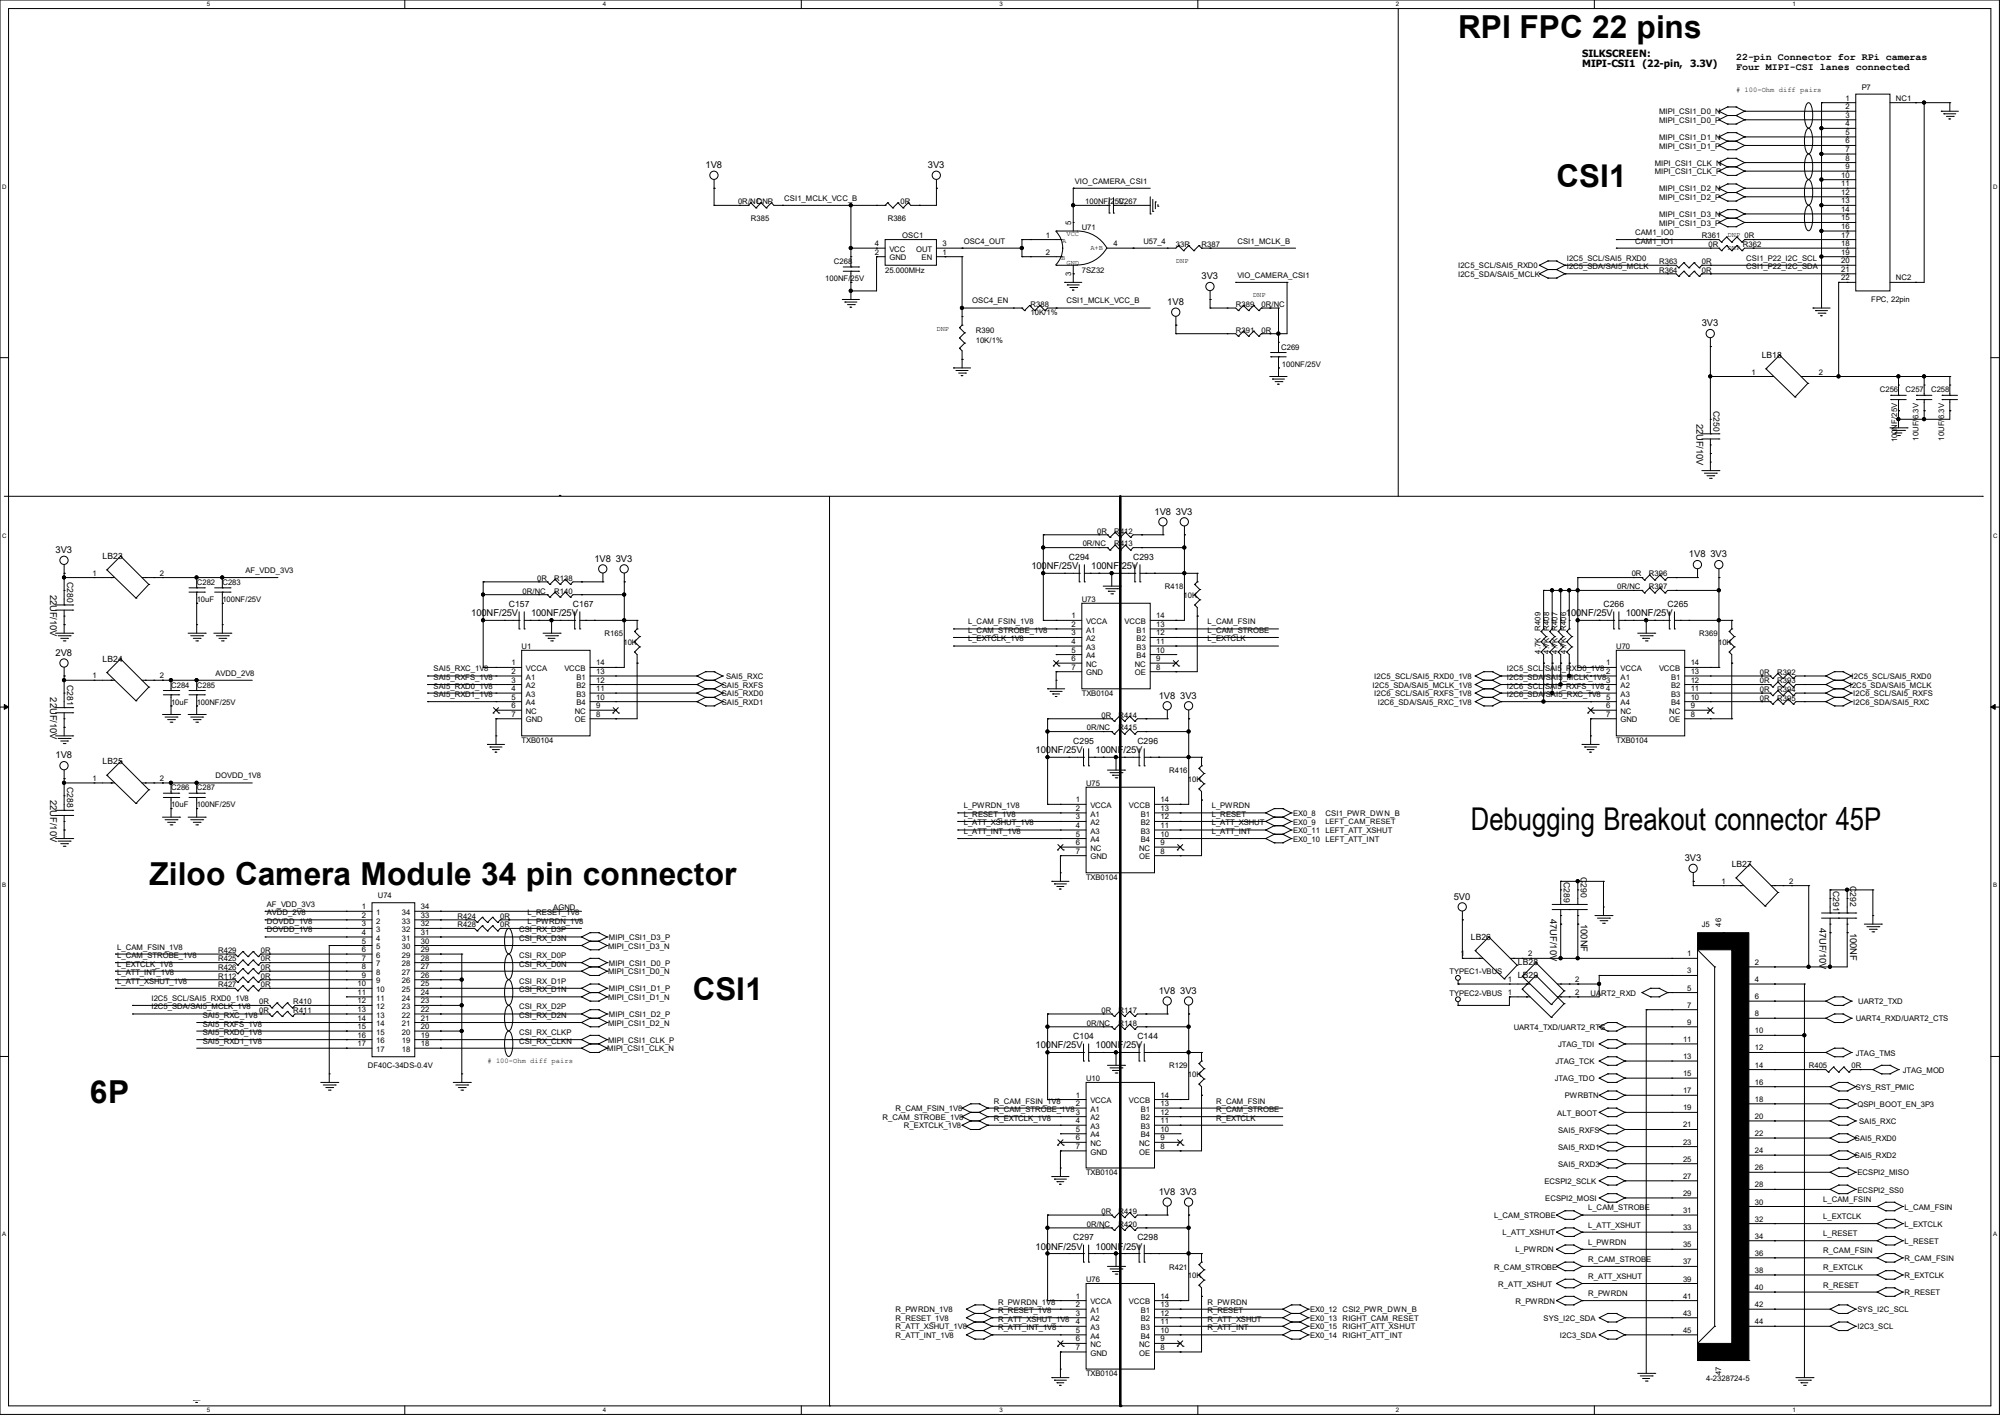
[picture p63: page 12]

RPI FPC 22 pins NVIDIA FPC 30 pins

Ziloo Camera Module 34 pin connector

# NVIDIA FPC 30 pins

CSI2 | CSI2


22-pin Connector for RPi cameras
Four MIPI-CSI lanes connected

Ziloo Camera Module 34 pin connector

The type and specification of the components refer to the BOM

NA
ECA NO | DATE

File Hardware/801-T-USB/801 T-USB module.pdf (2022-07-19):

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

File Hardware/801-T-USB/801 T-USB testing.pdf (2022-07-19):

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

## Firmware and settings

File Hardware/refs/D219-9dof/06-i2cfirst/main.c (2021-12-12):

#include <stdio.h>
#include <unistd.h>
#include <fcntl.h>
#include <stdint.h>
#include <sys/ioctl.h>
#include <sys/types.h>
#include <linux/i2c.h>
#include <linux/i2c-dev.h>

#define IIC_Dev  "/dev/i2c-1"
int fd;

uint8_t I2C_ReadOneByte(uint8_t DevAddr, uint8_t RegAddr)
{
  uint8_t u8Ret;
  if (ioctl(fd, I2C_SLAVE, DevAddr) < 0)
  {
    printf("Failed to acquire bus access and/or talk to slave.\n");
    return 0;
  }
  write(fd, &RegAddr,1);
  read(fd, &u8Ret, 1);
  return u8Ret;
}

int main(int argc, char* argv[])
{
    if ((fd = open(IIC_Dev, O_RDWR)) < 0)
    {
        printf("Failed to open the i2c bus.\n");
        return -1;
    }

    uint8_t u8DevAddr,u8RegAddr, u8RegVel;
    u8DevAddr = 0x68;
    u8RegAddr = 0x00;
    u8RegVel = I2C_ReadOneByte(u8DevAddr, u8RegAddr);
    printf("i2c-dev[0x%02x] : register[0x%02x] value is [0x%02x]\n", u8DevAddr,u8RegAddr,u8RegVel);
    
    close(fd);
    return 0;
}

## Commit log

2021-10-19 Hardware plan
    [DM3BT-DSF-PEJS.stp, c-4-2328724-5-a-3d.stp, ucm-imx8m-plus_mechanical-drawings_bottom.DXF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]
2021-10-20 Camera module connected
2021-10-30 Camera module further
    - M12 lenses as option
    - Connector orientation
    - Current orientation RPi camera connectors
    - Design files for Module v1
    [Ziloo simplified v2 camera module.dwg, Ziloo simplified v2 camera module.step]
2021-11-04 Split camera module in 2 designs
    [Ziloo simplified v2 camera module.dwg, Ziloo simplified v2 camera module.step, Ziloo v2 camera modules.dwg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]
2021-11-20 Lens testing plan
    * 3D models for testing hardware
    * Lens tech specs
    * Holder tech specs
    [CM4-IO-BASE.DWG, IMX219-83 Stereo Camera.dwg, JSD Lens list.xlsx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]
2021-12-05 Datasheets: i.MX and USB
    [ucm-imx8m-plus_mechanical-drawings_bottom.DXF, ucm-imx8m-plus_mechanical-drawings_top.DXF]
2021-12-05 Pin Allocations
2021-12-10 USB connector plans
2021-12-11 909 Brige Board
    [Ziloo Bridge 909.dwg, Ziloo Bridge 909.dxf]
2021-12-12 Revised power connector
    - Camera Module Breakout pins
    - Board Power Connector as plain header througholes
    [Ziloo Bridge 909.dwg]
2021-12-12 Battery Power board
    With revisions from implentation and v1 notes
2021-12-14 909 readme & older power design
    [10_Solder Paste Bottom_PCB_USB_charge_PCB_V1.GBP, 11_Solder Mask Bottom_PCB_USB_charge_PCB_V1.GBS, 12_Silk Bottom_PCB_USB_charge_PCB_V1.GBO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]
2021-12-21 Model 909b
    [Drawing_Ziloo_Bridge_909b.dwg, Ziloo Bridge 909 rev B.dwg, Ziloo Bridge 909b.dwg]
2021-12-28 Two alt breakout connectors
2022-01-10 Final 909b design
    - Debug muxing of USB 2.0
    - T-USB Alt. Modes
    - Pins on drawings
    [Drawing_Ziloo_Bridge_909b.dwg, Ziloo Bridge 909 rev B.dwg]
2022-01-19 I2C/I2S connector tweaks
    [Ziloo Bridge 909 rev B.dwg]
2022-02-13 More Expansions
    - Audio SAI5 in/out update
    - 40 pin GPIO Header
    [Ziloo Bridge 909 rev B.dwg]
2022-02-15 Capture pin allocations
2022-02-16 Using CBTL04083 mux instead of HD3SS3220
    + Interrupts
    + Clarified audio pins and I2C/I2S breakout connectors
2022-02-21 Power datasheets re-org
2022-03-01 T-USB board
2022-03-01 Refined Testing Board breakouts
2022-03-08 Finalising T-USB board
2022-03-26 Smiley front prototype
    [Untitled 2.csv, Ziloo M.2 expansions.xlsx]
2022-05-16 909c update with Power Module
    [Drawing_Ziloo_Bridge_909b.dwg]
2022-05-21 T-USB update
    Testing board goes down below
    Horizontal spaced connectors around USB T
    Drawings
    [801 T-USB module.dwg, 801 T-USB testing.dwg]
2022-06-13 919 two stages of design plan
    [919 smiley back face.dxf, 919 smiley front face.dxf, 919 smiley front plain.dxf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]
2022-06-15 I2C adresses
2022-06-17 Moved camera designs to 201
    [Ziloo simplified v2 camera module.dwg, Ziloo simplified v2 camera module.step, Ziloo v2 camera modules.dwg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]
2022-06-22 Clarifications T-USB and 909c
    - Updated 909c with T-USB daughterboard
    - Updated T-USB Power Module
2022-07-13 Connectivity
    - Connecting to Host PC/UI
    - Using GPIO to build stuff
    - The Activity State of the board
2022-07-19 Decor and Layout on Smiley
    [919 smiley front face.dxf, Decor.kicad_sch, Decor.step]
